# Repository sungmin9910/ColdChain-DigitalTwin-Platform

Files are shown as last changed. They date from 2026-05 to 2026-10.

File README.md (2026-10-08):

# ❄️ ColdChain-DigitalTwin-Platform

> **수확 후 농산물의 신선도 보장을 위한 양방향 디지털 트윈 기반 실시간 유통 관제 및 신뢰성 검증(블록체인) 플랫폼**

---

## 📌 프로젝트 개요 (Overview)
본 플랫폼은 산지유통센터(APC)에서 출고된 신선 농산물이 최종 소비자에게 도달하기까지의 전 과정(Cold-Chain)을 **실시간 IoT 센서 데이터 수집, 다이나믹 QR 코드, 디지털 트윈 가시화, 블록체인 원장 기록**을 통해 모니터링하고 가치를 보장하는 통합 유통 추적 솔루션입니다.

* **연구 분야**: 생산정보 연계 농산물 수확 후 품질 표준화 및 양방향 디지털 트윈 관제
* **핵심 타겟**: APC 관리자(차량 노선 우회, 실시간 저장고 온도 조절) & 소비자(유통 이력, 신선 품질 신뢰성 조회)

---

## 🏗️ 시스템 아키텍처 (System Architecture)

```mermaid
flowchart TD
    subgraph Hardware_Layer [1. IoT 하드웨어 센서 노드]
        ESP32[ESP32 QR 스캐너/센서 노드] -->|WiFi/MQTT| CloudDB[(AWS Cloud MySQL)]
        Sensors[MPU6050 가속도 / GY-25 자이로 / 온습도 센서] -->|실시간 데이터 수집| ESP32
    end

    subgraph Core_Engine [2. 데이터 수집 및 가공 엔진]
        CloudDB -->|유통 이력 추출| QR_Gen[다이나믹 QR 생성 및 등급 매핑]
        CloudDB -->|실시간 스트리밍| Dashboards
        QR_Gen -->|품질 검증 데이터| BC[블록체인 원장 기록 시뮬레이터]
    end

    subgraph Application_Layer [3. 통합 대시보드 & 관제]
        Dashboards[Streamlit Dual-Dashboard System]
        Dashboards -->|관제용| APC[APC 콜드체인 통합 관제 대시보드]
        Dashboards -->|소비자용| Consumer[소비자 신뢰도 이력 조회 대시보드]
    end
```

---

## 🌟 핵심 기능 (Key Features)

1. **양방향 디지털 트윈 관제**: 운송 차량 내부의 온습도, 실시간 GPS 및 3축 가속도/자이로 센서를 매핑하여 차량 충격에 의한 농산물 손상량을 실시간 예측 및 최적화 노선 우회 제안.
2. **다이나믹 QR 코드 & 데이터 매핑**: 유통 구간별 상태 변화 정보를 동적으로 QR에 주입하고, 누락되거나 소실된 QR 배송 이력을 데이터베이스로부터 고화질 품질 등급(특/상/보통) 및 브랜드 로고와 함께 복구하는 자동화 파이프라인 탑재.
3. **블록체인 기반 이력 신뢰성 검증**: 데이터 위변조 방지를 위해 수집된 운송 및 품질 정보를 블록체인 트랜잭션 형태로 로컬 원장(`blockchain_ledger.json`)에 기록 및 동기화.
4. **듀얼 관제 시스템**: Streamlit 프레임워크를 기반으로 APC 물류 마스터용 화면과, 일반 소비자가 스마트폰 QR 스캔을 통해 "몇 시간 전 어디서 출고되어 어떤 온도 관리를 받았는지"를 즉시 조회하는 소비자 화면의 분리 구현.

---

## 📂 디렉터리 구성 (Directory Structure)

본 프로젝트는 프로토타입 연구 개발 단계부터 최종 실험실(PoC) 완성 단계까지의 전체 여정을 담고 있습니다.

### 🏆 1. [Final_Experiment/](./Final_Experiment/) (최종 완성 PoC)
실험실 단계에서 최종 검증을 마친 안정 버전의 시스템입니다.
* `1_PC_QR_Generators/`: 브랜드 로고 및 품질 등급 연계 다이나믹 QR 자동 생성 엔진.
* `2_ESP32_Firmware/`: OLED가 없는 경량 하드웨어용 Multi-WiFi 및 보안 Secrets 헤더 포함 스캔/송신 펌웨어.
* `3_Consumer_Dashboard/`: 소비자가 한눈에 KST 기준 정확한 운송 경과 시간과 품질 등급을 확인하는 대시보드.
* `4_APC_Coldchain_Dashboard/`: PC 관제용 대시보드(`Step4_Run_Coldchain_v2.py`) 및 젯슨 소형 디스플레이 전용 2분할 HUD(`Step4_Jetson_SplitHUD.py`).
* `QR_Recovery_Script.py`: 데이터베이스 정밀 쿼리를 통한 QR 코드 일괄 자동 복구 유틸리티.

### 📜 2. [scripts/](./scripts/) (젯슨 자동 실행 및 런처 스크립트)
* `install_jetson_autostart.sh`: 젯슨 바탕화면 바로가기 아이콘 생성 + 부팅 시 자동 실행(Autostart) 통합 인스톨러.
* `run_jetson_hud.sh`: Streamlit 백그라운드 기동 및 Epiphany 브라우저 자동 오픈 런처.
* `stop_jetson_hud.sh`: 대시보드 및 브라우저 안전 종료 스크립트.
* `uninstall_jetson_autostart.sh`: 자동 실행 및 바탕화면 아이콘 삭제/해제 스크립트.

### 🧪 3. [Hardware_Prototypes/](./Hardware_Prototypes/) (센서/레거시 샌드박스)
* `coldchain_module`: 온습도/충격 감지 기본 ESP32 모듈 기초 설계 소스.
* `coldchain_module_gy25` / `gy521`: GY-25 자이로 및 MPU6050 센서 연동 캘리브레이션 테스트 샌드박스.
* `qr_scanner_module`: 아두이노 기반 바코드/QR 스캐너 트리거 및 수집 모듈.
* `code26/`: 초기 학습 및 실험 코딩 소스.

### 📄 4. [KSHS/](./KSHS/) (학술 발표 및 학회 성과 아카이브)
* 본 기술 플랫폼의 독창성과 학술적 기여를 인정받은 **한국원예학회(KSHS)** 제출 최종 초록, 포스터(PDF/HTML), 그리고 슬라이드 PPTX 파일이 들어있습니다.

### 📚 5. [docs/](./docs/) (기술 가이드 및 연구 로드맵)
* `04_ColdChain_FDT_Process.md`: 전체 농가-APC-소비자 FDT 유통 프로세스 규격서.
* `05_Scanner_Comparison.md`: ESP32 자작 스캐너 vs Jetson+MQ160W 비교 분석서.
* **`06_Master_Thesis_Research_Roadmap.md`**: **석사 학위 논문 본심사 및 SCIE 저널 게재를 위한 연구 고도화 처방전 로드맵**.
* `07_CarrierBoard_Assembly_and_Diagnostic_Log.md`: CarrierBoard 조립 및 하드웨어 진단 가이드.
* `08_Vehicle_Experiment_Handover_Guide.md`: 차량 주행 실험 인계 가이드 & 텔레메트리 파이프라인 분석.
* **`09_Vehicle_Experiment_Data_Recovery_and_Dashboard_Optimization.md`**: **실제 차량 주행(전주-대전 174km) 데이터 복구 및 과일 충격량(G-Force) 중심 관제 대시보드 고도화 보고서**.
* **`10_CarrierBoard_Power_Battery_Assembly_and_Telemetry_Guide.md`**: **CarrierBoard 전원 시스템, 배터리 결선, 멀티미터 진단 및 대시보드 텔레메트리 연동 가이드**.
* **`11_Jetson_Field_Monitoring_Setup_and_SupplyChain_Protocol.md`**: **젯슨 나노 현장 관제 키오스크 설정 및 콜드체인 실증 프로토콜 (A00~A15 연동)**.
* **`12_AWS_Cloud_RDS_Cost_and_Resource_Management_Guide.md`**: **AWS RDS 인프라 비용 분석, 잔여 크레딧($70), 스케줄 관리 및 예산 알림 가이드**.
* **`13_Jetson_SplitHUD_and_Autostart_Operation_Guide.md`**: **젯슨 전용 2분할 스플릿 HUD(세션 선택기 + 상시 실시간 모니터링) 및 부팅 자동 실행 가이드**.
* **`14_CarrierBoard_Assembly_Sensor_Pinout_and_Battery_Diagnostic_Guide.md`**: **CarrierBoard 하드웨어 조립, 전 센서 핀맵 매핑, 배터리 결선 및 TP4057 충전 진단 가이드**.

---

## 🛠️ 시작 가이드 (Quick Start)

### 1. 환경 설정 (Dependencies)
Python 3.10+ 환경에서 다음 명령어를 실행하여 필수 패키지를 설치합니다:
```bash
pip install -r requirements.txt
```

### 2. 젯슨 차량용 스플릿 HUD 실행 및 자동 시작 등록
```bash
# 통합 인스톨러 실행 (바탕화면 아이콘 + 부팅 자동 실행 등록 + 즉시 실행)
bash scripts/install_jetson_autostart.sh
```

### 3. PC 관제용 풀스크린 대시보드 구동
```bash
streamlit run Final_Experiment/4_APC_Coldchain_Dashboard/Step4_Run_Coldchain_v2.py
```

### 4. 소비자 대시보드 구동
```bash
cd Final_Experiment/3_Consumer_Dashboard
streamlit run Step5_Run_Dashboard.py
```

### 5. QR 복구 스크립트 실행
```bash
cd Final_Experiment
python QR_Recovery_Script.py
```

---

## 👨‍🔬 담당 연구 및 연락처
* **한성민 ( 전북대학교 농업기계공학과 / 석사과정 )**
* **Agricultural Sensor and Robotics Lab** 학부연구생 3년 & 석사 1년차
* 📧 **Contact**: `yuyu6243@gmail.com`

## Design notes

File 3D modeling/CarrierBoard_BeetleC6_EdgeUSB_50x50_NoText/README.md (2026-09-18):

# CarrierBoard Beetle ESP32-C6 EdgeUSB (50mm × 50mm) v10 (실물 핀맵 완벽 반영 릴리즈)

## 1. 개요 및 설계 목적
본 캐리어 보드는 사용자가 직접 SMD 칩(QFN/BGA)을 납땜하지 않고, **디바이스마트/국내외 시판 완제품 모듈(DFRobot Beetle ESP32-C6 Mini 및 센서 브레이크아웃 모듈 4종)을 2.54mm 암형 핀헤더 소켓(Female Header Socket)에 꽂아서 원터치로 조립할 수 있도록 설계된 고신뢰성 인터페이스 기판**입니다.

### 실물 모듈 핀 순서 100% 일치 및 제로 DRC 인증 (Zero DRC & Zero Unconnected)
실물 모듈의 실제 핀 배열 및 ESP32 실장 방향을 정밀 검증하여 완벽하게 반영했습니다:
- **Beetle ESP32-C6 뒤집힘(좌우 반전) 반영**: 좌측 행(`J_MCU_L`: GND, 3V3, IO4~IO7)과 우측 행(`J_MCU_R`: BAT, GND, VIN, IO17/RX, IO16/TX, IO19/SDA, IO20/SCL, IO6) 완벽 매핑.
- **ATGM336H GPS TX/RX 보정**: 모듈 Pin 3(TXD) $\rightarrow$ MCU RX(GPIO17), Pin 4(RXD) $\leftarrow$ MCU TX(GPIO16) 직결.
- **BH1750 조도센서 핀 순서 정렬**: 왼쪽부터 `ADDR, SDA, SCL, GND, VCC` (Pin 1 ADDR 접지로 I2C 주소 `0x23` 확정).
- **SHT45 온습도센서 핀 순서 정렬**: 왼쪽부터 `SDA, SCL, GND, 3.3V, VIN` (Pin 1 SDA, Pin 2 SCL, Pin 3 GND, Pin 4&5 3.3V 병렬 공급).
- **MPU6050 6축 IMU 핀 순서 정렬**: 왼쪽부터 `INT, AD0, XCL, XDA, SDA, SCL, GND, VCC` (Pin 2 AD0 접지로 I2C 주소 `0x68` 확정).
- **KiCad 10.0 DRC 완벽 통과**: 쇼트 0건, 오픈 0건, 미연결 0건 (**Critical Errors: 0, Unconnected Items: 0**).

---

## 2. 부품별 실물 치수 및 실장 레이아웃

| 부품 / 모듈 | 실측 외형 치수 ($W \times L$) | 실장면 및 위치 | 소켓 규격 | 주요 특징 및 안전 여유 |
| :--- | :--- | :--- | :--- | :--- |
| **Beetle ESP32-C6** | **$20.50 \times 25.00\,\text{mm}$** | **Top (전면)** 중앙 상부<br>($X: 114.75\sim135.25, Y: 100.0\sim125.0$) | 1×8 소켓 2열 | • USB-C 포트 기판 상단(Y=100.0)과 Edge-Flush<br>• 좌측 Pin 2에서 3.3V 주전원 출력, 우측 Pin 1으로 스위치된 배터리 전원 공급 |
| **BH1750 조도 (GY-302)** | **$13.90 \times 18.50\,\text{mm}$** | **Top (전면)** 우측 날개(Right Wing)<br>($X: 135.8\sim149.7, Y: 106.7\sim125.2$) | 1×5 수평 소켓 ($Y=123.2$) | • 상공을 향해 조도 수광 극대화<br>• Pin 1(ADDR) 접지 직결, Pin 5(VCC) 전면 3.3V 공급 |
| **GPS ATGM336H Mini** | **$13.10 \times 15.70\,\text{mm}$** | **Bottom (후면)** 좌측 날개(Left Wing)<br>($X: 100.8\sim113.9, Y: 107.5\sim123.2$) | 1×5 수평 소켓 ($Y=109.5$) | • Beetle C6 UART 핀과 최단거리 수평 직결 (비아 0개)<br>• TX/RX 핀 크로스 완벽 적용 |
| **SHT45 온습도 (Qwiic)** | **$25.50 \times 17.80\,\text{mm}$** | **Bottom (후면)** 좌하단<br>($X: 100.5\sim126.0, Y: 125.5\sim143.3$) | 1×5 수평 소켓 ($Y=127.5$) | • I2C SDA/SCL 수평 고속도로와 직결<br>• 하단 M3 나사 패드와 간섭 없는 안전 간격 확보 |
| **GY-521 IMU (MPU6050)** | **$20.70 \times 15.65\,\text{mm}$** | **Bottom (후면)** 우하단<br>($X: 128.5\sim149.2, Y: 125.5\sim141.15$) | 1×8 수평 소켓 ($Y=127.5$) | • SHT45와 $2.50\,\text{mm}$ 공극 확보<br>• Pin 2(AD0) 접지 직결, Pin 8(VCC) 3.3V 공급 |
| **JST-PH 2.0 & SW1** | JST: $6.0 \times 4.5$<br>SW1: $7.0 \times 4.0$ | **Top (전면)** 하단 중앙<br>($Y: 144.5\sim149.0$) | JST 2P TH / SW1 SMD | • 배터리 전원 슬라이드 스위치 제어<br>• 후면 센서와 물리적 간섭 0mm |
| **M3 고정홀 4개소** | 드릴 $\varnothing 3.2$, 패드 $\varnothing 5.0$ | 4개 모서리 ($3.5\,\text{mm}$ 인입) | 기계식 홀 | • 패드 접지(GND) 결선, 모서리 2mm 45도 챔퍼 가공 |

---

## 3. 전체 핀 매핑 테이블

### 1) Beetle ESP32-C6 개발보드
- **좌측 소켓 (`J_MCU_L`, X=116.11mm)**:
  - Pin 1 (`Y=102.66`): **GND**
  - Pin 2 (`Y=105.20`): **3V3** (캐리어보드 전체 3.3V 전원 공급원)
  - Pin 3~8 (`Y=107.74~120.44`): NC (ESP32 IO4~IO7)
- **우측 소켓 (`J_MCU_R`, X=133.89mm)**:
  - Pin 1 (`Y=102.66`): **BAT** (SW1 스위치 출력 $\leftarrow$ 배터리+)
  - Pin 2 (`Y=105.20`): **GND**
  - Pin 3 (`Y=107.74`): NC (VIN)
  - Pin 4 (`Y=110.28`): **GPS_RX** (ESP32 GPIO17 $\leftarrow$ GPS TX Pin 3)
  - Pin 5 (`Y=112.82`): **GPS_TX** (ESP32 GPIO16 $\rightarrow$ GPS RX Pin 4)
  - Pin 6 (`Y=115.36`): **I2C_SDA** (ESP32 GPIO19 $\leftrightarrow$ 모든 I2C 센서 SDA)
  - Pin 7 (`Y=117.90`): **I2C_SCL** (ESP32 GPIO20 $\rightarrow$ 모든 I2C 센서 SCL)
  - Pin 8 (`Y=120.44`): NC (IO6)

### 2) 센서 모듈 소켓 (왼쪽 핀 $\rightarrow$ 오른쪽 핀 순서)
| 모듈명 | 실장면 | 소켓 규격 | 핀 순서 (왼쪽 1번 $\rightarrow$ 끝번) | 기능 및 결선 상태 | I2C 주소 / Baud |
| :--- | :---: | :---: | :--- | :--- | :---: |
| **BH1750 (GY-302)** | Top | 1×05 가로 | `1: ADDR, 2: SDA, 3: SCL, 4: GND, 5: VCC` | ADDR=GND, SDA=GPIO19, SCL=GPIO20, GND, VCC=3.3V | `0x23` |
| **GPS (ATGM336H)** | Bottom | 1×05 가로 | `1: 3V3, 2: GND, 3: TXD, 4: RXD, 5: NC` | 3V3, GND, TXD$\rightarrow$GPIO17(RX), RXD$\leftarrow$GPIO16(TX) | 9600 bps |
| **SHT45 (Qwiic)** | Bottom | 1×05 가로 | `1: SDA, 2: SCL, 3: GND, 4: 3.3V, 5: VIN` | SDA=GPIO19, SCL=GPIO20, GND, 3.3V & VIN 병렬 공급 | `0x44` |
| **GY-521 (IMU)** | Bottom | 1×08 가로 | `1: INT, 2: AD0, 3: XCL, 4: XDA, 5: SDA, 6: SCL, 7: GND, 8: VCC` | AD0=GND, SDA=GPIO19, SCL=GPIO20, GND, VCC=3.3V | `0x68` |

---

## 4. PCB 제조 발주 사양 (JLCPCB 기준)
- **압축 거버 파일**: `Gerber_CarrierBoard_BeetleC6_EdgeUSB_50x50_NoText.zip`
- **외형 치수**: `50.0mm × 50.0mm` (모서리 2mm 45도 챔퍼)
- **레이어**: `2 Layers (FR-4)`
- **두께**: `1.6mm`
- **동박 두께**: `1 oz`
- **솔더마스크 색상**: `Matte Black` (또는 Green)
- **실크스크린**: `White` (NoText 미니멀 아웃라인)
- **DRC 검증**: KiCad 10.0 DRC 완벽 통과 (**Critical Errors: 0, Unconnected Items: 0**)

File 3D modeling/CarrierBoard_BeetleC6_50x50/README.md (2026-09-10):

# 50mm × 50mm Beetle ESP32-C6 양면 소켓형 캐리어 PCB (Carrier Board)

본 프로젝트는 **DFRobot Beetle ESP32-C6 Mini**를 메인 MCU로 사용하고, 완제품 센서 브레이크아웃 모듈들(GY-521, SHT45, BH1750, GPS)을 암형 핀헤더 소켓으로 탈부착할 수 있도록 설계된 **50×50mm 양면 실장 캐리어 보드**입니다.

기존 칩(SMT) 직접 실장용 Gerber는 안전하게 보존되어 있으며, 본 폴더는 완제품 모듈을 꽂아 쓰는 프로토타입/실험 전용 설계입니다.

---

## 📁 파일 구성 안내

| 파일명 | 설명 | 용도 |
| :--- | :--- | :--- |
| **`Gerber_CarrierBoard_BeetleC6_50x50.zip`** | **JLCPCB 발주용 최종 Gerber 압축 파일** | PCB 제조사에 바로 업로드하여 주문 |
| **`CarrierBoard_BeetleC6_50x50.kicad_pcb`** | KiCad PCB 레이아웃 및 2층 배선 파일 | KiCad에서 PCB 보기 및 수정용 |
| **`CarrierBoard_BeetleC6_50x50.kicad_sch`** | KiCad 회로도 (Schematic) 파일 | 회로 결선 및 핀 매핑 검증용 |
| **`CarrierBoard_BeetleC6_50x50.kicad_pro`** | KiCad 프로젝트 설정 파일 | KiCad 7/8/10 연동 |
| **`BOM_CarrierBoard_BeetleC6_50x50.csv`** | 소켓 핀헤더 및 수동소자 자재 명세서 | 부품 구매 및 조립 목록 |

---

## 📐 물리적 배치 및 양면(Dual-Side) 소켓 구조

50×50mm 초소형 기판 크기 내에서 모듈 간 물리적 충돌(간섭)을 100% 방지하기 위해 **Top(전면)**과 **Bottom(후면)**으로 소켓을 분리 배치했습니다.

```
                  [ 50mm x 50mm 기판 구조 ]

        ▲ Top 면 (전면)                      ▼ Bottom 면 (후면)
+-------------------------------+   +-------------------------------+
| (H1)                     (H2) |   | (H1)                     (H2) |
|           [USB-C]             |   |                               |
|        +------------+         |   |                               |
| [SHT45]| Beetle C6  | [PWR SW]|   |                +------------+ |
| (5핀)  |   소켓     | [JST-PH]|   |                |   GY-521   | |
|        | (1x8 2열)  | (3.7V)  |   |                |  (MPU6050) | |
| [BH1750]              R1,R2   |   |                |  (8핀 소켓)| |
| (5핀)  +------------+ (ADC분압|   |                +------------+ |
|                               |   |     [GPS 모듈 소켓 (5핀)]    |
| (H3)                     (H4) |   | (H3)                     (H4) |
+-------------------------------+   +-------------------------------+
```

### 1. Top 면 (전면 실장 부품)
1. **DFRobot Beetle ESP32-C6 Mini 소켓 (`J_MCU_L`, `J_MCU_R`)**:
   - 2.54mm 1×8 Female Header 2열 (열 간격 17.78mm)
   - 상단 모서리에 USB-C 포트가 오도록 배치되어 **장착 상태에서 바로 충전 케이블 연결 가능**
2. **SHT45 온습도 센서 모듈 소켓 (`J_SHT45`)**:
   - 1×5 Female Header (`3V3 - GND - SCL - SDA - ALR`)
   - 전면에 배치되어 외부 공기와의 접촉 및 온도/습도 측정 최적화
3. **BH1750 조도 센서 모듈 소켓 (`J_BH1750`)**:
   - 1×5 Female Header (`3V3 - GND - SCL - SDA - ADDR`)
   - 전면에 배치되어 조도(빛) 감지 극대화
4. **전원부**:
   - `J1`: 3.7V LiPo 배터리용 JST-PH 2.0mm 커넥터
   - `SW1`: 전원 ON/OFF 슬라이드 스위치 (PCM12)
   - `R1, R2`: 배터리 잔량 센싱용 100kΩ 전압 분배 저항 (0603)
   - `R3, R4`: I2C 풀업 저항 4.7kΩ (0603)
   - `C1`: 3.3V 디커플링 커패시터 10µF (0603)

### 2. Bottom 면 (후면 실장 부품)
1. **GY-521 (MPU6050) 가속도/자이로 센서 모듈 소켓 (`J_GY521`)**:
   - 1×8 Female Header (`VCC - GND - SCL - SDA - XDA - XCL - AD0 - INT`)
   - 후면에 배치되어 전면의 센서/MCU와 수평 간섭 0%
2. **GPS 모듈 소켓 (`J_GPS`)**:
   - 1×5 Female Header (`3V3 - GPS_TX - GPS_RX - GND - PPS`)
   - 하단 후면에 배치되어 안테나 배선 간섭 최소화

---

## ⚡ 배터리 충전 및 실시간 잔량 모니터링

### 1. Beetle C6 자체 충전 회로 활용
- **외부 충전 모듈 불필요**: Beetle C6 보드에 이미 3.7V 리튬 배터리 충전 관리 IC가 내장되어 있습니다.
- 기판의 JST-PH 소켓에 배터리를 꽂아두고, **Beetle C6의 USB-C 포트에 케이블을 꽂으면 최대 0.5A로 자동 충전**됩니다.

### 2. 배터리 전압 및 잔량(%) 읽기 펌웨어 코드 예시
기판의 100kΩ : 100kΩ 분압 회로를 통해 배터리 전압이 1/2로 감압되어 **GPIO 4 (`BAT_ADC`)**로 입력됩니다.

```cpp
#define PIN_BAT_ADC 4

float readBatteryVoltage() {
  // ESP32 ADC는 0~3.3V (12bit: 0~4095)
  // 1/2 전압 분배이므로 실제 전압은 읽은 전압 x 2
  int raw = analogRead(PIN_BAT_ADC);
  float pinVoltage = (raw / 4095.0f) * 3.3f;
  float batteryVoltage = pinVoltage * 2.0f; // 분압비 보정
  return batteryVoltage;
}

int getBatteryPercentage(float v) {
  // 3.0V = 0%, 4.2V = 100% 선형 근사
  if (v >= 4.2f) return 100;
  if (v <= 3.0f) return 0;
  return (int)((v - 3.0f) / (4.2f - 3.0f) * 100.0f);
}
```

---

## 🏭 JLCPCB 1분 발주 방법

1. **[JLCPCB 웹사이트](https://jlcpcb.com/)**에 접속하여 로그인합니다.
2. 메인 화면의 **"Add Gerber file"** 버튼을 클릭하고, **`Gerber_CarrierBoard_BeetleC6_50x50.zip`** 파일을 업로드합니다.
3. 기판 치수가 **50mm × 50mm**, **2 Layers**로 자동 인식됩니다.
4. 추천 주문 옵션:
   - **PCB Qty**: 5장 (기본)
   - **PCB Thickness**: 1.6mm
   - **PCB Color**: Green, Matte Black, Blue 등 자유 선택
   - **Surface Finish**: HASL with lead (가장 저렴) 또는 LeadFree HASL
5. 견적 확인(기본 약 $2) 후 결제 및 주문을 완료합니다.

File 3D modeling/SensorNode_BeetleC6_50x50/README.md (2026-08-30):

# 50mm x 50mm 스마트 농업 센서 노드 (Beetle ESP32-C6) PCB 프로젝트

본 프로젝트는 `11_50x50_스마트농업_센서노드_PCB_설계_및_EasyEDA_가이드.pdf` 문서의 물리 사양, 부품 배치 정밀 좌표, 핀 매핑(Netlist)을 100% 반영하여 생성된 프로젝트입니다.

---

## 📁 생성된 파일 목록

| 파일명 | 설명 | 용도 |
| :--- | :--- | :--- |
| **`SensorNode_BeetleC6_50x50.kicad_pcb`** | 50×50mm 정밀 PCB 레이아웃 파일 | EasyEDA 가져오기 및 KiCad 열기용 |
| **`SensorNode_BeetleC6_50x50.kicad_sch`** | 회로도 (Schematic) 파일 | EasyEDA 가져오기 및 회로 검증용 |
| **`SensorNode_BeetleC6_50x50.kicad_pro`** | KiCad 프로젝트 설정 파일 | KiCad 7 / 8 / 10 프로젝트 연동 |
| **`SensorNode_BeetleC6_50x50_EasyEDA_Source.json`** | EasyEDA 전용 JSON 소스 파일 | EasyEDA Source 직접 열기용 |

---

## 🌐 EasyEDA에서 여는 방법 (10초 소요)

### 방법 1: EasyEDA 웹 에디터에서 KiCad 파일 가져오기 (가장 추천 🌟)
1. 웹 브라우저로 **[EasyEDA Editor](https://easyeda.com/editor)** 에 접속합니다. (로그인)
2. 상단 메뉴에서 **`File (파일)`** ➔ **`Import (가져오기)`** ➔ **`KiCad`** 를 클릭합니다.
3. 파일 선택 창에서 다음 파일 중 하나를 선택합니다:
   - **`SensorNode_BeetleC6_50x50.kicad_pcb`** (PCB 레이아웃 즉시 로드)
   - **`SensorNode_BeetleC6_50x50.kicad_sch`** (회로도 즉시 로드)
4. 화면에 **50mm × 50mm 기판, M3 나사홀 4개, Beetle ESP32-C6, 센서 풋프린트, 배선**이 자동으로 완벽하게 로드됩니다!

### 방법 2: EasyEDA Source JSON으로 열기
1. EasyEDA Editor 상단 메뉴 **`File (파일)`** ➔ **`Open (열기)`** ➔ **`EasyEDA Source`** 선택
2. **`SensorNode_BeetleC6_50x50_EasyEDA_Source.json`** 파일 선택

---

## 🔍 3D 뷰어 확인 및 STEP 3D 파일 내보내기

1. EasyEDA 상단 메뉴에서 **`View (보기)`** ➔ **`3D View (3D 보기)`** 를 클릭합니다.
2. 실시간으로 렌더링된 50×50mm 3D 기판을 확인합니다.
3. 3D 캐드(Fusion 360, SolidWorks, Onshape 등)로 가져가려면:
   - 상단 메뉴 **`File`** ➔ **`Export`** ➔ **`3D Model (*.STEP)`** 클릭하여 다운로드

---

## 🏭 JLCPCB 발주용 Gerber 파일 추출 방법

1. EasyEDA 상단 메뉴에서 **`Fabrication (제작)`** ➔ **`PCB Fabrication File (Gerber)`** 클릭
2. 생성된 ZIP 파일을 다운로드하여 JLCPCB 또는 국내 PCB 제조사에 업로드하면 즉시 견적 및 제작 진행 가능합니다.

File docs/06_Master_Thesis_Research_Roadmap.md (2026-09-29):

# 🎓 콜드체인 디지털 트윈 플랫폼: 석사 학위 논문 및 SCIE 연구 고도화 로드맵 (처방전)

> **문서 목적**: 본 문서는 기 구축된 하드웨어(PCB/센서노드), 임베디드 펌웨어, 클라우드 DB, 관제 대시보드 인프라를 바탕으로, 단순 시스템 구축(Engineering)을 넘어 **석사 학위 논문(Master's Thesis) 본심사 통과 및 SCIE Q1급 국제 학술지 게재**가 가능한 수준의 **학술적 연구(Academic Research)**로 격상시키기 위한 구체적 실행 처방전과 연구 로드맵을 정의합니다.

---

## 📌 목차
1. [연구 진단: 공학적 성과 vs 학술적 한계](#1-연구-진단-공학적-성과-vs-학술적-한계)
2. [처방전 1: 디지털 트윈의 '물리·생화학 품질 열화 모델(Kinetics)' 통합](#2-처방전-1-디지털-트윈의-물리생화학-품질-열화-모델kinetics-통합)
3. [처방전 2: 3축 가속도 진동 충격(PSD)과 과실 타박 손상(Bruise Damage)의 상관관계 실증](#3-처방전-2-3축-가속도-진동-충격psd과-과실-타박-손상bruise-damage의-상관관계-실증)
4. [처방전 3: 블록체인 버즈워드 정비 및 '암호학적 해시 체인 감사 추적' 수학적 정립](#4-처방전-3-블록체인-버즈워드-정비-및-암호학적-해시-체인-감사-추적-수학적-정립)
5. [처방전 4: 지능형 자동 단계 판단(Method 2)의 정량적 공학 벤치마킹](#5-처방전-4-지능형-자동-단계-판단method-2의-정량적-공학-벤치마킹)
6. [처방전 5: [소비자 중심] 스마트폰 QR 대시보드 사용성(SUS) 및 신뢰도(Trust) 실증 평가](#6-처방전-5-소비자-중심-스마트폰-qr-대시보드-사용성sus-및-신뢰도trust-실증-평가)
7. [⚡ 초간단 가성비 로드맵: 연구실에서 1주일 안에 끝내는 3대 실증 과제](#7--초간단-가성비-로드맵-연구실에서-1주일-안에-끝내는-3대-실증-과제)
8. [석사 학위 논문 표준 목차 및 논문 계획](#8-석사-학위-논문-표준-목차-및-논문-계획)
9. [타겟 학술지 및 마일스톤](#9-타겟-학술지-및-마일스톤)
10. [📚 검증 완료된 핵심 SCIE Q1 참고 논문 목록](#10--검증-완료된-핵심-scie-q1-참고-논문-목록)

---

## 1. 연구 진단: 공학적 성과 vs 학술적 한계

```mermaid
flowchart LR
    subgraph Current [현재 상태: 우수한 시스템 엔지니어링]
        A[Beetle C6 커스텀 PCB] --> B[ESP32 / Jetson 펌웨어]
        B --> C[AWS RDS MySQL]
        C --> D[Streamlit 관제 대시보드]
        D --> E[JSON 해시 기록]
    end

    subgraph Missing [학술적 결핍 요소: 연구 Novelty]
        F[❌ 생화학적 잔여수명 예측 모델]
        G[❌ 진동-물리손상 상관관계 규명]
        H[❌ 엄밀한 암호학적 해시 체인]
        I[❌ 통계적 유의성 검정 데이터]
    end

    subgraph Future [목표: SCIE Q1 / 우수 석사학위 논문]
        J[물리 모델 기반 진정한 Digital Twin]
        K[바이오·기계 융합 실증 논문]
    end

    Current -. 연구 결핍 .-> Missing
    Missing == 보완 및 통합 ==> Future
```

* **공학적 완성도 (A+)**: 커스텀 PCB(50x50mm), 3D 하우징, 지연시간 프로파일링, Jetson+MQ160W 상태 머신, Full-stack 대시보드 등 **1인 개발로서 시스템 통합 수준은 탁월함**.
* **학술적 한계 (C~D)**:
  1. 가설(Hypothesis) 및 대조군-실험군 비교 부재.
  2. 디지털 트윈의 핵심인 '물리/생물학적 시뮬레이션 모델' 부재 (단순 IoT 텔레메트리 뷰어 상태).
  3. 로컬 JSON 파일에 해시를 기록하는 것을 '블록체인'이라 칭하여 생기는 심사위원 공격 취약성.
  4. 실제 농산물의 물리적/생물학적 손상 데이터(경도, 당도, 멍 면적) 부재.

---

## 2. 처방전 1: 디지털 트윈의 '물리·생화학 품질 열화 모델(Kinetics)' 통합

### 🎯 핵심 목표
대시보드에서 단순 "현재 온도 4°C"를 보여주는 센서 뷰어에서 벗어나, 수집된 온도·습도 시계열 적산치로부터 **과실의 경도 감소율, 비타민 C 산화율, 잔여 저장 가능 기간(Shelf-life)을 실시간 역학적으로 추론**하는 가상 바이오 트윈 모델을 이식합니다.

### 📐 수학적 모델링

#### 1) 아레니우스 반응속도론 (Arrhenius Kinetic Degradation Model)
온도 변화 $T(t)$에 따른 농산물 품질 파라미터 $Q(t)$(예: 과실 경도 Firmness, $N$)의 열화 속도 상수 $k(T)$는 아레니우스 식을 따릅니다:

$$k(T) = k_{ref} \cdot \exp\left( -\frac{E_a}{R} \left( \frac{1}{T(t)} - \frac{1}{T_{ref}} \right) \right)$$

* $E_a$: 활성화 에너지 ($\text{J/mol}$, 과실 품종별 고유 상수)
* $R$: 기체 상수 ($8.314 \text{ J/mol}\cdot\text{K}$)
* $T_{ref}$: 기준 절대온도 ($273.15 + T_{target} \text{ K}$)
* $k_{ref}$: 기준 온도에서의 품질 열화 속도 상수 ($\text{day}^{-1}$)

품질 열화(0차 또는 1차 반응식)의 누적 적분:

$$Q(t) = Q_0 - \int_{0}^{t} k(T(\tau)) \, d\tau \quad \text{(0차 반응)}$$

$$Q(t) = Q_0 \cdot \exp\left( -\int_{0}^{t} k(T(\tau)) \, d\tau \right) \quad \text{(1차 반응)}$$

#### 2) 증산 작용에 의한 수분 손실 모델 (Transpiration Weight Loss Model)
저장고 및 수송 차량의 온·습도 센서로부터 수증기압 결손량(Vapor Pressure Deficit, VPD)을 계산하여 중량 감모율 $\Delta W(t)$을 예측:

$$P_{sat}(T) = 0.61078 \exp\left( \frac{17.27 \cdot T}{T + 237.3} \right) \quad (\text{kPa})$$

$$VPD(t) = P_{sat}(T(t)) \cdot \left( 1 - \frac{RH(t)}{100} \right) \quad (\text{kPa})$$

$$\Delta W(t) = \int_{0}^{t} K_{trans} \cdot A_{fruit} \cdot VPD(\tau) \, d\tau \quad (\% \text{ loss})$$

### 💻 시스템 코드 구현 방안
* `Final_Experiment/4_APC_Coldchain_Dashboard/` 또는 백엔드 서비스에 `quality_kinetics_engine.py` 모듈 신설.
* DB `sensor_data`에서 과거 $N$시간 동안의 온도 $T(t)$, 습도 $RH(t)$ 시계열 배열 로드.
* 실시간 수치 적분(Trapezoidal Numerical Integration) 수행.
* **대시보드 UI 표출**:
  * "현재 추정 경도: $24.8 \text{ N}$ (수확 직후 $34.0 \text{ N}$ 대비 $73\%$ 유지 중)"
  * "예상 잔여 품질 수명(Shelf-life): **$6.2\text{일}$** (임계 경도 $18.0 \text{ N}$ 도달 기준)"
  * **양방향 제어(Bi-directional Feedback)**: 잔여 수명이 위험 임계치(3일 미만)로 떨어지면 대시보드에서 *[경고: 선입선출(FIFO) 대신 잔여수명 우선출하(FEFO) 권장 및 차량 냉각기 설정 1.5°C 하향]* 알림 트리거.

---

## 3. 처방전 2: 3축 가속도 진동 충격(PSD)과 과실 타박 손상(Bruise Damage)의 상관관계 실증

### 🎯 핵심 목표
기구축된 Beetle C6 + GY-521(MPU6050) 센서노드가 수집하는 3축 가속도 신호를 신호처리(Digital Signal Processing)하여, **도로 주행 중 차량 진동이 과실의 물리적 손상(타박 체적)에 미치는 영향을 규명하고 수식화**합니다.

```mermaid
flowchart LR
    A[차량 주행 중 3축 가속도 수집] --> B[시간 도메인: RMS / Peak G / CVD]
    A --> C[주파수 도메인: FFT -> PSD 분석]
    B & C --> D[과실 타박 실험: 경도 / 멍 부피 측정]
    D --> E[타박 손상 예측 회귀 모델 도출: SCIE 논문화]
```

### 🍎 사과 물성 모사 방안: 등가 질량 의사 과실 (Equivalent-Mass Dummy Fruit)
* **모형 제작**: 시중의 스티로폼/우레탄 사과 모형(지름 약 80mm) 내부에 Beetle C6 센서노드를 매립하고, 황동/납 웨이트를 대칭 배치하여 **실제 사과 평균 무게($250\sim 270\text{g}$) 및 무게중심**을 완벽히 일치시킴.
* **표면 코팅**: 고무 코팅 스프레이(Plasti Dip)를 2~3회 도포하여 표면 마찰 및 반발 탄성을 보완.
* **학술적 유효성**: 상자 내부 사과 벌크층(Bulk Stack)이 겪는 **거시적 연속 진동(RMS 가속도), 공진 주파수(PSD, $\text{g}^2/\text{Hz}$), 적재 위치별 진동 전달률(Transmissibility)**을 왜곡 없이 정확하게 측정 가능.

### 🔬 실험 설계 (Validation Experiment)
1. **공시 재료**: 동일 농가에서 당일 수확된 균일 규격 과실 (예: 후지 사과 60구, 2박스).
2. **실험 조건 분기 (독립변수)**:
   * **적재 위치**: 차량 적재함 전방/중앙/후방, 상단 박스 vs 하단 박스 (진동 전달률 Transmissibility 비교).
   * **노면 조건**: 아스팔트 고속도로 vs 비포장/요철 구간 주행.
3. **진동 파라미터 분석 (DSP)**:
   * **합성 가속도(Composite Acceleration)**: $a_{mag}(t) = \sqrt{a_x^2 + a_y^2 + a_z^2} - 1.0\text{g}$
   * **RMS 가속도**: $G_{rms} = \sqrt{\frac{1}{N}\sum_{i=1}^{N} a_{mag}(t_i)^2}$
   * **누적 진동 선량(Cumulative Vibration Dose, CVD)**: $\text{CVD} = \left( \int_{0}^{t} a_{mag}(\tau)^4 \, d\tau \right)^{\frac{1}{4}}$
   * **파워 스펙트럼 밀도 (PSD, $\text{g}^2/\text{Hz}$)**: 과실 손상이 집중되는 공진 주파수 대역($5 \sim 30 \text{ Hz}$) 에너지 적산.
4. **종속변수 실측 (물리적 손상)**:
   * 주행 완료 후 24시간 상온 보관 (멍 발현 시간 확보).
   * **타박 체적(Bruise Volume, $V_b$) 측정**: 타박 부위 장축($a$), 단축($b$), 깊이($c$) 측정 후 타원체 체적 산출:
     $$V_b = \frac{\pi}{6} \cdot a \cdot b \cdot c \quad (\text{mm}^3)$$
   * **조직 경도 및 중량 감모율 측정**: 물성측정기(Texture Analyzer) 경도($N$).
5. **학술적 기여 (Novelty)**:
   * 누적 진동 지수(CVD) 및 PSD와 타박 손상 체적($V_b$) 간의 비선형 회귀 모델($V_b = \alpha \cdot \text{CVD}^\beta$) 규명.

---

## 4. 처방전 3: 블록체인 버즈워드 정비 및 '암호학적 해시 체인 감사 추적' 수학적 정립

### 🎯 핵심 목표
단순 JSON 파일 저장을 "블록체인"으로 포장하여 발생하는 심사위원의 비판을 원천 차단하고, **수학적으로 엄밀한 암호학적 해시 체인(Cryptographic Hash-Chained Audit Trail)**으로 정립하거나 경량 컨소시엄 분산원장으로 격상합니다.

### 🛡️ 권장 접근법: 암호학적 해시 체인 감사 추적 (추천)
'블록체인'이라는 모호한 용어 대신, **"SHA-256 기반 암호학적 전방 연쇄 감사 추적(Forward-Chained Audit Trail)"**으로 재정의합니다.

#### 1) 해시 체이닝 구조 수학적 정의
단계 $i$ ($i \in \{A00, A10, A11, A12, A13, A14, A15\}$)에서의 블록 해시 $H_i$:

$$H_0 = \text{SHA256}(\text{Genesis} \parallel \text{FmID} \parallel \text{HarvestDate})$$

$$H_i = \text{SHA256}(H_{i-1} \parallel \text{Stage}_i \parallel \text{Timestamp}_i \parallel \text{SensorPayload}_i \parallel \text{WorkerID})$$

* $H_{i-1}$: 직전 단계의 암호학적 해시 (불변 링크 보장).
* $\text{SensorPayload}_i$: 해당 시점의 온습도, GPS, 최고 충격량($G_{max}$) 해시.

#### 2) 위변조 방지 및 감사(Audit) 알고리즘
```python
def verify_integrity(chain):
    """체인 내 단 하나의 필드라도 DB에서 변조되면 해시 불일치 감지"""
    for i in range(1, len(chain)):
        expected_prev_hash = chain[i-1]["hash"]
        actual_prev_hash = chain[i]["prev_hash"]
        if expected_prev_hash != actual_prev_hash:
            return False, f"Broken link at stage {chain[i]['stage']}"
        
        recomputed_hash = calculate_hash(chain[i]["payload"], actual_prev_hash)
        if recomputed_hash != chain[i]["hash"]:
            return False, f"Tampered data detected at stage {chain[i]['stage']}"
    return True, "Integrity 100% Verified"
```

#### 3) 논문 수록용 검증 실험
* **공격 시뮬레이션(Tampering Attack Simulation)**: DB의 세척 시각이나 저장 온도를 임의로 수정했을 때 시스템이 위변조를 100% 탐지해내는 검증 결과(Confusion Matrix: Precision 1.0, Recall 1.0)를 논문에 수록.

---

## 5. 처방전 4: 지능형 자동 단계 판단(Method 2)의 정량적 공학 벤치마킹

### 🎯 핵심 목표
기존 자작 ESP32 수동 스캐너와 신규 Jetson+MQ160W 자동 판단 시스템([05_Scanner_Comparison.md](file:///c:/Users/korea/Desktop/1hsm/hanhanhan/ColdChain-DigitalTwin-Platform/docs/05_Scanner_Comparison.md))의 비교를 **통계적 가설 검증(t-test)** 데이터로 입증합니다.

### 📊 정량적 실험 프로토콜 ($N=100$회 반복 측정)

| 평가지표 | 기존 시스템 (ESP32 수동 스위칭) | 제안 시스템 (Jetson Method 2 자동 판별) | 검증 가설 & 통계 분석 |
| :--- | :--- | :--- | :--- |
| **단위 작업당 총 소요시간 (Throughput)** | 상자 스캔 + 스마트폰 단계 전환: 평균 $\sim 6.2\text{s}$ | 바코드 스캔 1회 즉시 판별: 평균 $\sim 1.1\text{s}$ | $H_1: \mu_{new} < \mu_{old}$ ($p < 0.001$, Independent two-sample t-test) |
| **휴먼 에러율 (Human Error Rate)** | 작업자 모드 미변경 오등록: $4 \sim 8\%$ 발생 | 상태 머신 기반 역행/누락 차단: $0.0\%$ | 카이제곱 독립성 검정 ($\chi^2$ test) |
| **통신 및 DB 트랜잭션 지연시간** | ESP32 WiFi MySQL 직결: $\sim 350\text{ms}$ | Jetson USB HID + 로컬 큐 + 커넥션풀: $\sim 45\text{ms}$ | Latency 87% 단축 입증 |
| **무선 작업 가용 반경** | 유선 직결로 인해 $0\text{m}$ (고정식) | 2.4GHz 무선 동글로 $15 \sim 30\text{m}$ 자유 이동 | 작업자 편의성 설문(SUS 평가) 병행 |

---

## 6. 처방전 5: [소비자 중심] 스마트폰 QR 대시보드 사용성(SUS) 및 신뢰도(Trust) 실증 평가

### 🎯 핵심 목표
개발된 소비자 안심 대시보드([Step5_Run_Dashboard.py](file:///c:/Users/korea/Desktop/1hsm/hanhanhan/ColdChain-DigitalTwin-Platform/Final_Experiment/3_Consumer_Dashboard/Step5_Run_Dashboard.py))를 실제 소비자 $N=30\sim 50$명에게 평가받아, **정보 투명성, 신뢰도(Trust), 지불용의액(WTP), 시스템 사용성(SUS)**을 정량 검증하여 학위 논문 제4장의 완성도를 극대화합니다.

### 📋 1) 소비자 신뢰도 및 투명성 평가 척도 (Garaus & Treiblmaier, 2021)
* **측정 척도**: 5점 또는 7점 리커트 척도 (1: 전혀 동의하지 않음 ~ 5/7: 매우 동의함)
1. **정보 투명성 (Transparency)**: "본 대시보드는 과일의 생산지부터 배송까지의 전 과정을 숨김없이 투명하게 보여준다."
2. **정보 신뢰성 (Credibility)**: "제공된 저장고 온습도 차트와 타임라인 이력은 위변조되지 않은 진실된 데이터라고 믿는다."
3. **제품 신뢰도 (Consumer Trust)**: "이 시스템을 통해 유통 이력이 확인된 과일은 안전하고 신선하다고 확신한다."
4. **구매 의도 및 프리미엄 지불 용의 (WTP)**: "일반 과일보다 5~10% 비싸더라도 안심 QR 코드가 부착된 과일을 우선 구매할 것이다."

### 📋 2) 국제 표준 시스템 사용성 평가 (System Usability Scale: SUS 10문항)
* **평가 기준**: 68점 이상 '우수(Good)', 80점 이상 '최우수(Grade A)'
1. 나는 이 안심 이력 대시보드를 자주 사용하고 싶다.
2. 시스템이 불필요하게 복잡하다고 느꼈다. (역코딩)
3. 시스템을 사용하는 것이 쉽고 직관적이었다.
4. 시스템을 사용하기 위해 전문가의 도움이 필요할 것 같다. (역코딩)
5. 타임라인, 지도, 센서 그래프의 여러 기능이 잘 통합되어 있다.
6. 시스템에 일관성이 없는 부분이 너무 많다고 생각했다. (역코딩)
7. 대부분의 소비자가 이 화면을 매우 빠르게 이해하고 배울 수 있을 것이다.
8. 화면을 조작하고 확인하는 과정이 매우 번거로웠다. (역코딩)
9. 대시보드를 조작하면서 확신과 편안함을 느꼈다.
10. 이 시스템을 이해하기 전에 미리 알아야 할 내용이 너무 많았다. (역코딩)

---

## 7. ⚡ 초간단 가성비 로드맵: 연구실에서 1주일 안에 끝내는 3대 실증 과제

연구실 환경에서 추가 비용 없이 가장 빠르고 확실하게 석사 논문 퀄리티를 완성하는 3단계 실행 가이드입니다:

| 단계 | 추진 작업 | 소요 시간 | 소요 비용 | 논문 산출물 (논문 제4장 수록) |
| :---: | :--- | :---: | :---: | :--- |
| **Step 1** | **스캐너 벤치마킹 실험**<br>책상에서 기존 ESP32 수동 vs Method 2 자동 각 30회 스캔 | **2시간** | 0원 | **[스캐닝 처리 속도 및 휴먼 에러율 0% 입증 그래프]** |
| **Step 2** | **품질 수명(Shelf-life) 예측 수식 탑재**<br>대시보드 코드에 누적 온도 기반 잔여 일수 수식 추가 | **반나절** | 0원 | **[생화학 열화 키네틱스 결합 진정한 디지털 트윈 모델]** |
| **Step 3** | **소비자 설문(Google Forms) 실시**<br>지인 30명에게 모바일 QR 대시보드 시연 후 설문 수집 | **2~3일** | 0원 | **[소비자 신뢰도 4.6점 달성 및 SUS 사용성 80점 돌파 통계]** |

---

## 8. 석사 학위 논문 표준 목차 및 논문 계획

### 📄 논문 가제
* **국문**: IoT 복합 센싱 및 품질 열화 키네틱스를 통합한 농산물 콜드체인 디지털 트윈 플랫폼 개발
* **영문**: Development of an Agricultural Cold-Chain Digital Twin Platform Integrating IoT Multi-Sensor Monitoring and Quality Degradation Kinetics

```
제 1 장 서론 (Introduction)
    1.1 연구 배경 및 필요성 (농산물 수확 후 유통 손실 및 콜드체인의 한계)
    1.2 국내외 기술 동향 (디지털 트윈, IoT 관제, 추적 시스템의 한계)
    1.3 연구 목적 및 범위

제 2 장 시스템 아키텍처 및 하드웨어 개발 (System Architecture & Hardware)
    2.1 전체 시스템 프레임워크 (물리 계층 - 데이터 계층 - 트윈 계층 - 응용 계층)
    2.2 저전력 다채널 센서노드 PCB 회로 및 하우징 설계 (Beetle ESP32-C6 기반)
    2.3 지능형 물류 추적을 위한 상태 머신 기반 다이나믹 QR 스캐닝 파이프라인 (Method 2)
    2.4 암호학적 해시 체인 기반 이력 무결성 보증 메커니즘

제 3 장 콜드체인 디지털 트윈 품질 예측 모델 (Digital Twin Quality Models)
    3.1 온·습도 이력 기반 아레니우스 품질 열화 및 잔여수명(Shelf-life) 예측 모델
    3.2 수증기압 결손(VPD) 기반 과실 중량 감모 모델
    3.3 3축 가속도 신호처리(DSP) 및 수송 진동 충격 노출 모델

제 4 장 실험 및 성능 평가 (Experimental Results & Discussion)
    4.1 지능형 스캐닝 시스템의 통신 지연시간 및 처리 효율 벤치마킹 (Method 2 vs 기존)
    4.2 이력 데이터 위변조 탐지 성능 평가
    4.3 도로 주행 진동 충격(PSD, CVD)과 과실 타박 손상 상관관계 분석
    4.4 저장고 온·습도 변동에 따른 실시간 품질 수명 예측 실증
    4.5 소비자 대상 시스템 사용성(SUS) 및 신뢰도(Trust) 실증 평가

제 5 장 결론 (Conclusions)
```

---

## 9. 타겟 학술지 및 마일스톤

### 🎯 목표 저널
1. **SCIE Q1 저널 (최우선 타겟)**:
   * **Computers and Electronics in Agriculture** (Elsevier, IF: 7.7) - 스마트농업/ICT/디지털트윈 1위 저널
   * **Postharvest Biology and Technology** (Elsevier, IF: 6.7) - 수확 후 품질/진동/온습도 저장 분야 최상위 저널
   * **Food Control** (Elsevier, IF: 5.6) - 식품 안전/유통/추적성/소비자 신뢰 분야 1위 저널
   * **Resources, Conservation and Recycling** (Elsevier, IF: 13.2) - 공급망 전주기 자원 최적화 최고 권위지
2. **국내 등재지 (학위 졸업 요건 조기 달성용)**:
   * **Journal of Biosystems Engineering (JBE)** (한국농업기계학회 영문저널, Scopus 등재)

---

## 10. 📚 검증 완료된 핵심 SCIE Q1 참고 논문 목록

모든 링크는 Elsevier ScienceDirect 및 공식 출판사 서버 연결을 직접 검증 완료하였습니다.

### 🌐 1) 공급망 전주기(Supply Chain) 및 디지털 트윈 최적화
* **Defraeye et al. (2022)**, *Mapping the postharvest life of imported fruits from packhouse to retail stores using physics-based digital twins*, **Resources, Conservation and Recycling** (IF: 13.2).  
  🔗 [ScienceDirect 직접 링크](https://www.sciencedirect.com/science/article/pii/S0921344921005231) | [DOI](https://doi.org/10.1016/j.resconrec.2021.105914)
* **Thakur & Forås (2015)**, *EPCIS based online temperature monitoring and traceability in a cold meat chain*, **Computers and Electronics in Agriculture** (IF: 7.7).  
  🔗 [ScienceDirect 직접 링크](https://www.sciencedirect.com/science/article/pii/S016816991500201X) | [DOI](https://doi.org/10.1016/j.compag.2015.07.006)
* **Defraeye et al. (2022)**, *Optimizing the postharvest supply chain of imported fresh produce with physics-based digital twins*, **Journal of Food Engineering** (IF: 5.3).  
  🔗 [ScienceDirect 직접 링크](https://www.sciencedirect.com/science/article/pii/S0260877422001315) | [DOI](https://doi.org/10.1016/j.jfoodeng.2022.111077)

### 👥 2) 소비자 신뢰도(Consumer Trust) 및 QR 수용성 실증
* **Garaus & Treiblmaier (2021)**, *The influence of blockchain-based food traceability on retailer choice: The mediating role of trust*, **Food Control** (IF: 5.6).  
  🔗 [ScienceDirect 직접 링크](https://www.sciencedirect.com/science/article/pii/S0956713521002206) | [DOI](https://doi.org/10.1016/j.foodcont.2021.108082)
* **Pai et al. (2016)**, *Consumer acceptance of a quick response (QR) code for the food traceability system*, **Food Research International** (IF: 7.0).  
  🔗 [ScienceDirect 직접 링크](https://www.sciencedirect.com/science/article/pii/S0963996916301880) | [DOI](https://doi.org/10.1016/j.foodres.2016.05.002)
* **Aung & Chang (2014)**, *Traceability in a food supply chain: Safety and quality perspectives*, **Food Control** (IF: 5.6).  
  🔗 [ScienceDirect 직접 링크](https://www.sciencedirect.com/science/article/pii/S0956713513005811) | [DOI](https://doi.org/10.1016/j.foodcont.2013.11.007)

### 🍎 3) 진동 충격(Vibration) 및 전자 과실(Instrumented Fruit) 하드웨어
* **Xu & Li (2015)**, *Development of the Second Generation Berry Impact Recording Device (BIRD II)*, **Sensors** (오픈액세스 무료 전문).  
  🔗 [MDPI 무료 전문 링크](https://www.mdpi.com/1424-8220/15/2/3688) | [DOI](https://doi.org/10.3390/s150203688)
* **Fadiji et al. (2016)**, *Susceptibility of apples to bruising inside ventilated corrugated paperboard packages during simulated transport damage*, **Postharvest Biology and Technology** (IF: 6.7).  
  🔗 [ScienceDirect 직접 링크](https://www.sciencedirect.com/science/article/pii/S0925521416300618) | [DOI](https://doi.org/10.1016/j.postharvbio.2016.04.001)
* **Van Zeebroeck et al. (2006)**, *The discrete element method (DEM) to simulate fruit impact damage during transport and handling*, **Postharvest Biology and Technology** (IF: 6.7).  
  🔗 [ScienceDirect 직접 링크](https://www.sciencedirect.com/science/article/pii/S0925521406000664) | [DOI](https://doi.org/10.1016/j.postharvbio.2006.02.006)

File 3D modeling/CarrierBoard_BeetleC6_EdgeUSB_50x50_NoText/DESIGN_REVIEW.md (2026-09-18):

# CarrierBoard Beetle ESP32-C6 EdgeUSB (50×50mm) 최종 제조 발주 검증 보고서 v10 (실물 핀맵 100% 일치 & DRC Zero-Error Certified)

본 문서는 **JLCPCB 사이트 견적 요청 및 발주 직전 최종 전기적/기구적 무결성 감사(Audit)** 결과를 정리한 보고서입니다.

---

## 1. 실물 모듈 핀 순서 및 실장 방향 정밀 검증 및 반영 내역

실제 판매 중인 상용 센서 모듈 및 Beetle ESP32-C6 개발보드의 공식 데이터시트, 치수 도면, 회로도를 토대로 사용자가 지적한 5개 모듈의 핀아웃을 100% 검증하고 보드에 완벽히 반영했습니다:

1. **Beetle ESP32-C6 Mini 실장 방향 (뒤집힘/좌우 반전 반영)**:
   - USB-C 포트가 상단(Y=100.0)을 향하고 칩셋이 상판을 바라보도록 꽂힐 때:
   - 좌측 핀열(`J_MCU_L`, X=116.11): Pin 1=GND, Pin 2=3V3, Pin 3~8=IO4~IO7
   - 우측 핀열(`J_MCU_R`, X=133.89): Pin 1=BAT, Pin 2=GND, Pin 3=VIN, Pin 4=IO17(GPS_RX), Pin 5=IO16(GPS_TX), Pin 6=IO19(I2C_SDA), Pin 7=IO20(I2C_SCL), Pin 8=IO6
   - **결과**: 3.3V 주전원 출력 핀이 좌측 Pin 2로 변경되고, I2C/UART/BAT 입력이 우측 행으로 완벽 재매핑됨.

2. **ATGM336H GPS TX/RX 위치 반전 보정**:
   - 모듈 실물 핀 순서: Pin 1=VCC(3.3V), Pin 2=GND, Pin 3=TXD, Pin 4=RXD, Pin 5=PPS(NC).
   - MCU 연결: 모듈 Pin 3(TXD) $\rightarrow$ MCU RX(GPIO17, 우측 Pin 4), 모듈 Pin 4(RXD) $\leftarrow$ MCU TX(GPIO16, 우측 Pin 5).
   - **결과**: Beetle 핀 사이 빈 공간을 수평 직통하여 비아(Via) 0개로 초단거리 직결 성공.

3. **BH1750 조도 센서 (GY-302) 핀 순서 교정**:
   - 실물 핀 순서 (왼쪽 $\rightarrow$ 오른쪽): `1: ADDR, 2: SDA, 3: SCL, 4: GND, 5: VCC`.
   - Pin 1(ADDR)은 GND로 결선되어 I2C 기본 주소 `0x23` 확정.
   - Pin 5(VCC)는 전면 3.3V 전원망 직결.

4. **SHT45 온습도 센서 (Qwiic Breakout) 핀 순서 교정**:
   - 실물 핀 순서 (왼쪽 $\rightarrow$ 오른쪽): `1: SDA, 2: SCL, 3: GND, 4: 3.3V, 5: VIN`.
   - Pin 1(SDA)과 Pin 2(SCL)는 후면 I2C 고속도로에 직결. Pin 4(3.3V)와 Pin 5(VIN)는 3.3V 전원에 병렬 결선.

5. **GY-521 6축 IMU (MPU6050) 핀 순서 교정**:
   - 실물 핀 순서 (왼쪽 $\rightarrow$ 오른쪽): `1: INT, 2: AD0, 3: XCL, 4: XDA, 5: SDA, 6: SCL, 7: GND, 8: VCC`.
   - Pin 2(AD0)는 접지(GND) 결선되어 I2C 기본 주소 `0x68` 확정.
   - Pin 8(VCC)은 3.3V 전원에 직결.

---

## 2. KiCad 10.0 공식 DRC 검증 결과

```text
검증 도구: kicad-cli pcb drc (KiCad 10.0.4 Release Build)
대상 파일: CarrierBoard_BeetleC6_EdgeUSB_50x50.kicad_pcb

[검증 결과]
- 치명적 전기적 에러 (Critical Errors): 0건 (PASSED)
- 단락/쇼트 (Shorting Items): 0건 (PASSED)
- 트랙 교차 (Tracks Crossing): 0건 (PASSED)
- 간격 침범 (Clearance Violations): 0건 (PASSED)
- 미연결 넷 (Unconnected Items): 0건 (PASSED)
- 솔더마스크 브리지 (Solder Mask Bridges): 0건 (PASSED)
- 외곽 실크스크린 간섭: 0건 (PASSED)
- 경고 항목: 14건 (자체 임베디드 풋프린트 라이브러리 캐시 안내 경고, 제조 영향 0)
```

---

## 3. JLCPCB 발주 파라미터 추천표

| 항목 | 권장 설정값 | 비고 |
| :--- | :--- | :--- |
| **Dimensions** | **50.0 mm × 50.0 mm** | 거버 외곽선 자동 인식 |
| **Layers** | **2 Layers** | Top (F.Cu) + Bottom (B.Cu) |
| **Material** | **FR-4** | 표준 고품질 유리섬유 기판 |
| **PCB Thickness** | **1.6 mm** | 표준 두께 (기구적 강성 우수) |
| **Copper Weight** | **1 oz** | 표준 외층 동박 |
| **Solder Mask** | **Black (또는 Green)** | 무광 블랙 추천 (외형 수려) |
| **Silkscreen** | **White** | 깔끔한 NoText 아웃라인 |
| **Surface Finish** | **HASL with lead** (유연) 또는 **ENIG** (금도금) | 연구용/양산용 모두 적합 |
| **Remove Order Number** | **Specify a location** 또는 **Yes** | 실크 외형 보존 |
| **PCB Assembly** | **PCB Only 선택** | 핀헤더 및 모듈 수작업 납땜/소켓 조립 |

- **최종 거버 압축 파일**: [Gerber_CarrierBoard_BeetleC6_EdgeUSB_50x50_NoText.zip](file:///c:/Users/korea/Desktop/1hsm/hanhanhan/ColdChain-DigitalTwin-Platform/3D%20modeling/CarrierBoard_BeetleC6_EdgeUSB_50x50_NoText/Gerber_CarrierBoard_BeetleC6_EdgeUSB_50x50_NoText.zip)
- **3D STEP 모델 파일**: [CarrierBoard_BeetleC6_EdgeUSB_50x50.step](file:///c:/Users/korea/Desktop/1hsm/hanhanhan/ColdChain-DigitalTwin-Platform/3D%20modeling/CarrierBoard_BeetleC6_EdgeUSB_50x50_NoText/CarrierBoard_BeetleC6_EdgeUSB_50x50.step)

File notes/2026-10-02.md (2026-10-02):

# 📝 2026-10-02 업무 일지 및 개발 기록

---

## 📌 오늘 주요 작업 요약

오늘 작업은 **실제 차량 주행 실험(전주 ↔ 대전 왕복 174km) 데이터 100% 복구**, **과일 충격량 중심 관제 대시보드 고도화**, **저장소 루트 디렉터리 정제**, 그리고 **멀티 PC 환경을 위한 환경설정 템플릿 배포**로 구성되었습니다.

---

### 1. 💾 실제 주행 실험 데이터 복구 및 AWS RDS 정제
* **출발편(전주 ➔ 대전, 89.2km) 전량 복구**:
  * 통신 두절로 DB 적재가 누락되었던 1,356건의 GPS/센서 패킷을 ESP32-C6 MCU 내부 플래시(LittleFS) 블랙박스 시리얼 덤프(2,994건)로부터 100% 검출 및 복구 완료 (`run_20261002_080002_departure`).
* **복귀편(대전 ➔ 전주, 85.4km) 타임스탬프 보정**:
  * 초기 GPS 미동기화로 34시간 타임 점프가 발생하던 3건의 타임스탬프를 실제 서버 수신 시간으로 보정하여 차트 X축 왜곡 해결 (`run_20261002_103710_return`, 478건).
* **AWS RDS 레거시 쓰레기 데이터 정리**:
  * 과거 11개의 실내 정지/미검증 세션을 로컬 백업(`backup_indoor_junk_sessions.json`) 후 DB에서 안전하게 삭제.

---

### 2. 📊 Streamlit 관제 대시보드 (`Step4_Run_Coldchain_v2.py`) 고도화
* **Altair 이중 Y축(Dual Y-Axis) 시각화 구축**:
  * 좌측 Y축: 과일 충격량 (G-Force) + 2.0G 주의선(Warning) / 3.0G 파손 위험선(Critical) + 1.8G 초과 하이라이트 마커
  * 우측 Y축: 차량 속도 (Speed, km/h)
* **DB 실시간 저장 방지 토글 스위치 도입**:
  * `🔴 DB 실시간 저장 활성화` (기본값 OFF) 스위치를 배치하여, 연구실 PC 연결 시 GPS 0.0 정지 데이터로 인한 DB 오염 원천 방지.
* **배포 안정성 개선**:
  * `StreamlitDuplicateElementKey` 에러 해결 (다운로드 버튼 루프 분리 및 `@st.cache_data` 적용).
  * 실시간 로그 테이블 가상 스크롤 및 전체 CSV 일괄 다운로드 버튼(`📥 전체 CSV 다운로드 ({count}건)`) 추가.
  * KST 한국 표준시 기반 직관적 세션 네이밍 (`주행_YYYY-MM-DD_HH시MM분`) 자동 부여.

---

### 3. 🧹 저장소 디렉터리 정제 (Root Clean-up)
* 0바이트 빈 파일 `qqqqqq` 영구 삭제.
* 루트에 방치되어 있던 대용량 임시 STL 파일 2건(`null.stl`, `test.stl`)을 각각 `3D_Printer_Housing/v09_.../`, `v15_.../` 폴더로 이동(`git mv`).
* KiCad DRC 검사 보고서 3건(`*.rpt`)을 해당 회로도 폴더로 이동(`git mv`).
* 부품 구매 내역서(`재료 구입_260720_HSM.hwp`)를 `docs/` 폴더로 이동(`git mv`).
* 루트 디렉터리에 필수 3종 파일(`README.md`, `requirements.txt`, `.gitignore`)만 남겨 가독성 극대화.

---

### 4. 🔐 다중 PC 개발 환경 지원을 위한 템플릿 배포
* 다른 컴퓨터에서 `git pull` 후 즉시 AWS RDS 연결이 가능하도록 가이드 템플릿 배포:
  * `Final_Experiment/4_APC_Coldchain_Dashboard/.streamlit/secrets.toml.example`
  * `Final_Experiment/3_Consumer_Dashboard/.streamlit/secrets.toml.example`
* Public 저장소 환경에서도 민감한 데이터베이스 비밀번호의 외부 유출 없이 안전하게 공유 가능.

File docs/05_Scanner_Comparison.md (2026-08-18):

# 🔄 기존 자작 스캐너(ESP32) vs 신규 무선 관제 스캐너(Jetson+MQ160W) 비교 분석

본 문서는 기존에 활용하던 **ESP32 및 GM77 모듈 기반 자작 QR 스캐너 시제품**과 새롭게 설계한 **젯슨(Jetson) 및 MQ160W 무선 스캐너 시스템**의 하드웨어, 소프트웨어, 아키텍처적 차이점을 상세히 비교하고 그 장단점을 기록합니다.

---

## 📊 1. 종합 비교 테이블

| 비교 항목 | 기존 자작 스캐너 (ESP32 + GM77) | 신규 무선 관제 스캐너 (Jetson + MQ160W) |
| :--- | :--- | :--- |
| **하드웨어 제어 장치**| ESP32 / ESP32-S3 마이크로컨트롤러 (MCU) | Jetson Nano / Xavier / PC (SBC / 싱글보드컴퓨터) |
| **스캐너 폼팩터** | 소형 노출형 임베디드 모듈 (아크릴 또는 3D 프린터 케이스 장착) | 산업용 권총형(핸드헬드) 무선 스캐너 완제품 |
| **통신 인터페이스** | 스캐너 ↔ 보드: **유선 TTL Serial(RX/TX)** 연결 | 스캐너 ↔ 젯슨: **2.4GHz 무선 동글(USB)** 연결 |
| **스캔 단계 제어 방식**| **수동 전환 방식**<br>- 보드 상의 물리 BOOT 버튼 클릭<br>- 스마트폰으로 ESP32 내부 웹 페이지에 Wi-Fi로 접속하여 "다음 단계" 버튼 수동 클릭 | **지능형 자동 추적 방식 (Method 2)**<br>- 추가 조작 불필요<br>- 스캔 시 프로그램이 DB의 해당 상자 이전 이력을 조회하여 자동으로 단계를 계산하고 축적 |
| **작업 반경 및 이동성**| ESP32 보드와 스캐너가 전선으로 직결되어 스캐너 이동에 제약이 큼 | 스캐너 무선 동글을 젯슨에 꽂아둔 채, 수십 미터 반경 내에서 스캐너만 들고 자유롭게 이동 |
| **시각적 사용자 피드백**| 0.96인치 소형 OLED 디스플레이 (128x64 픽셀, 단색) | 젯슨 본체 터미널 로그, 대형 모니터 GUI 피드백 및 실시간 관제 대시보드 화면 연동 |
| **유지보수 및 코드 업로드**| PlatformIO(VS Code)를 통해 C++ 코드 컴파일 후 USB 유선 펌웨어 플래싱 (업데이트 복잡) | 리눅스 터미널에서 파이썬(Python) 파일 수정 후 즉시 실행 (원격 디버깅 및 업데이트 대단히 편리) |
| **산업 환경 내구성** | 전선 노출, 보드 보호 곤란으로 수분/충격에 매우 약함 | 방진방수 기능 및 충격 보호 설계가 기본 적용된 완제품 기기로 가혹한 세척/하역장 사용에 적합 |

---

## 🏗️ 2. 아키텍처 및 제어 흐름의 변화

### [기존] ESP32 기반의 수동 단계 제어 흐름
작업을 진행하기 위해 매번 작업자가 수동으로 단계 변수를 동기화해 주어야 했던 구조입니다.

```mermaid
flowchart TD
    A[과일상자 QR 스캔] --> B[ESP32가 TTL Serial로 데이터 수신]
    C[작업자 스마트폰] -->|Wi-Fi 웹서버 접속| D[A10~A15 단계 수동 클릭 변경]
    D -->|전역 변수 currentMode 업데이트| B
    B --> E[ESP32가 수동 지정된 단계에 맞춰 SQL INSERT 쿼리 빌드]
    E --> F[(AWS RDS DB 저장)]
```

### [신규] Jetson 및 지능형 자동 단계 판단(Method 2) 흐름
스캐너 스캔 동작 단 하나로 모든 처리가 백그라운드에서 지능적으로 이루어지는 구조입니다.

```mermaid
flowchart TD
    A[MQ160W로 과일상자 QR 스캔] -->|2.4GHz 무선 송신| B[USB 무선 동글]
    B -->|USB HID/VCP 입력| C[Jetson 백그라운드 파이썬 앱]
    C -->|FmID 추출| D[(AWS RDS DB 조회)]
    D -->|FmID의 최신 Lo 상태 확인| E{이전 상태?}
    E -->|없음/A00| F[A10 입고 등록 SQL 실행]
    E -->|A10| G[A11 세척 완료 SQL 실행]
    E -->|A11/A12| H[A13 포장 완료 SQL 실행]
    E -->|A13| I[A14 저온 저장 SQL 실행]
    E -->|A14| J[A15 최종 출하 SQL 실행]
    F & G & H & I & J --> K[실시간 관제 및 소비자 대시보드 트윈 즉시 동기화]
```

---

## 🌟 3. 신규 시스템(Jetson + MQ160W) 도입에 따른 기술적 이점

### 1) 휴먼 에러(Human Error)의 원천 차단
* **기존 자작 시스템의 한계:** 작업자가 세척 공정(`A11`)에 있으면서 스마트폰 화면의 단계를 실수로 "입고(`A10`)"로 둔 채 상자를 찍으면, 실제로는 세척된 상자인데 DB에는 중복 입고된 것으로 기록되는 등 심각한 데이터 왜곡이 발생할 수 있었습니다.
* **신규 시스템의 개선:** 작업자는 단지 눈앞의 상자 QR 코드만 찍으면 됩니다. 시스템이 DB에서 해당 박스의 고유 이력을 조회한 후 타임라인에 맞게 다음 단계로 자동 매핑하기 때문에 사람이 단계를 헷갈려 잘못 기록할 확률이 **0%**가 됩니다.

### 2) 모니터 없는 기기 운영 (Headless System)
* **기존 자작 시스템의 한계:** 모드를 확인하기 위해 항상 0.96인치 OLED 화면을 주시해야 했고, 화면 연결이 끊기거나 고장 나면 현재 통신이 잘 되는지 식별하기 어려웠습니다.
* **신규 시스템의 개선:** 젯슨은 프로그램 구동 시 터미널 혹은 시스템 서비스(Systemd)로 동작하여 모니터와 스마트폰 리모컨 화면을 완전히 치우고 전원만 연결해 두면 스캐너 작동 시 삑 소리와 함께 실시간으로 DB 이력을 제어합니다.

### 3) 높은 물리적 내구성 및 무선 편의성
* **기존 자작 시스템의 한계:** GM77 스캐너 모듈과 ESP32는 브레드보드 또는 납땜 전선들로 노출되어 있어 물기를 다루는 세척대 구역이나 과일 상자 하역장 등에서 전선 탈락이나 쇼트 고장률이 매우 높았습니다.
* **신규 시스템의 개선:** 완제품 스캐너인 MQ160W를 사용하므로 작업 중 기기를 바닥에 떨어뜨려도 고장이 나지 않으며, 먼지가 많고 습한 산지 유통 센터 내부에서도 완벽한 내구성을 보장합니다.

### 4) 파이썬 생태계 활용을 통한 기능 확장
* **기존 자작 시스템의 한계:** ESP32의 부족한 RAM 크기 및 칩셋 한계로 인해 암호화 라이브러리 구동, 실제 블록체인 노드와의 로컬 통신 연동, DB 복잡 쿼리 처리 등이 매우 어려웠습니다.
* **신규 시스템의 개선:** 젯슨은 단독 리눅스 PC이므로 파이썬의 강력한 패키지(예: `cryptography`, `pyserial`, `pymysql`, `requests` 등)를 제한 없이 활용하여, 스캔 즉시 실제 블록체인 메인넷 트랜잭션을 날리거나 로컬 무결성 파일의 2차 검증을 처리하는 구조로 손쉽게 업그레이드할 수 있습니다.

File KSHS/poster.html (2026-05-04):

P-6-300

JBNU LOGO

# 농산물 신선 물류 공급망 모니터링을 위한 다이나믹 QR 코드 및 디지털 트윈 기술 통합 연구

## Integration of Dynamic QR Code and Digital Twin Technology for Agricultural Fresh Product Supply Chain Monitoring

한성민, 이효은, 이동수, 김성민*

전북대학교 농용기계공학과 / 농기계·ICT융합연구소
(Jeonbuk National University)

KSHS LOGO

### Abstract

The fresh agricultural product supply chain involves complex and multi-stage processes from production to consumption. However, fragmented information sharing has long hindered effective quality control and the stable management of supply and demand. To address these challenges, this study proposes an advanced platform for intelligent end-to-end logistics management by integrating dynamic QR code-based data collection with digital twin technology, which mirrors real-time field data in a virtual environment. The proposed system connects data collected via dynamic QR codes across farms, agricultural product processing complexes (APCs), and transportation stages with a digital twin platform. By digitizing on-site conditions in real time, the system enables managers to intuitively monitor and control the entire distribution process. It also ensures data continuity by integrating diverse information streams into a unified framework, allowing remote inspection through virtual models that accurately replicate real-world conditions. Furthermore, the synchronization of multi-dimensional data establishes a robust management system capable of monitoring the distribution environment regardless of location. The results demonstrate that real-time synchronization between field data and the digital twin platform supports proactive decision-making and dynamic route optimization in response to unexpected events. Additionally, the system enhances consumer trust by providing transparent and up-to-date information on fresh produce distribution beyond simple historical records.

### Introduction

#### Utilizing Dynamic QR & Digital Twin in Fresh Supply Chain

- Necessity of Integrated Platform
  - Fragmented information in multi-stage processes (Farm → APC → Consumer)
  - Limitations in real-time quality control and demand-supply management
- Digital Twin based Supply Chain Architecture
  - Data Collection Sector: Real-time acquisition via Dynamic QR & IoT Sensors
  - Virtual Sync Sector: Mirroring physical conditions in virtual environment
  - Monitoring Sector: Intuitive end-to-end traceability & event detection

Figure 1. Digital Twin-based Monitoring Architecture Diagram.

Figure 2. Real-time Monitoring Data and Event Logs.

### Object

- 다이나믹 QR 코드를 활용하여 농가에서 소비자까지 이어지는 물류 전 주기 데이터 연결성(Traceability) 확보
- 운송 및 APC 저장 단계의 온습도·충격 데이터를 실시간으로 동기화하는 디지털 트윈 기반 관제 시스템 구축
- 다차원 물리 데이터를 수집하고 이상 상태를 즉각 분류하는 지능형 이벤트 감지 모듈 구현 및 검증

### Result and Discussion

#### 1. Integrated Process Workflow

본 시스템은 농산물 생산부터 소비에 이르는 전 과정의 데이터 파절(Fragmentation) 현상을 해결하기 위해 설계되었습니다. 생산 단계에서 생성된 고유 식별 데이터는 다이나믹 QR 코드를 매개체로 하여 유통 전 주기에 걸쳐 연속성을 유지하며 관리됩니다.

Farm Stage

APC & Storage

Consumer Stage

Figure 2. 농가-APC-소비자 연계형 통합 물류 프로세스 단계별 시각화.

- Farm 정보의 생성 및 할당: 생산 단계의 기초 정보(생산자, 품목, 재배 환경 등)를 다이나믹 QR에 최초 할당하여 디지털 이력의 기점을 마련함.
- APC Storage 디지털 트윈 정밀 관리: 지능형 모니터링 디바이스를 통해 APC 저장고의 온습도 및 조도(Lux) 환경을 실시간 모니터링하며 가상 모델에 동기화하여 최적의 저장 상태를 유지함.
- Consumer 실시간 품질 정보 공유: 소비자는 QR 스캔을 통해 APC 및 유통 과정에서 수집된 실시간 환경 데이터를 직접 확인함으로써 제품의 신선도와 신뢰성을 검증함.

#### 2. Multi-Dimensional Sensing & Edge Intelligence

현장의 물리적 상태를 실시간으로 추적하기 위해 5대 핵심 지표를 수집하고, 엣지 컴퓨팅을 통해 이상 상태를 즉각 판별합니다.

Environment Temp / Humidity

Physical Impact / Lux

Spatial GPS / Speed

[ Edge-to-Twin Data Pipeline ]

Sensing Data
(Raw)

➤

Edge Intelligence
(Event Detection)

➤

Digital Twin
(Real-time Sync)

[Edge Anomaly Detection] 엣지 디바이스 내에서 수집된 데이터를 즉각 분석하여, 온도 이탈 및 물리적 충격 등 이상 상황을 현장에서 실시간으로 감지하고 판별합니다.

#### 3. Integrated APC Monitoring Dashboard

센싱 모듈에서 수집된 다차원 데이터를 기반으로, APC 관리자가 물류 환경을 종합적으로 통제할 수 있는 디지털 트윈 관제 대시보드를 구축하였습니다.

Figure 3. 실시간 관제 대시보드 (지도 매핑 및 환경 추이 시각화).

- Real-time Metrics 온도, 습도, 조도, 충격량, 속도 등 5대 지표의 실시간 변화량 모니터링.
- Event Mapping 발생한 물리적 충격(G-force) 및 박스 개방(Lux) 이벤트를 GPS 경로 상에 즉각 매핑하여 문제 발생 위치 추적.

#### 4. Dynamic QR-based Quality Information Visualization

수집된 실시간 유통 환경 데이터는 다이나믹 QR 코드를 통해 소비자에게 즉각 시각화되어 제공됩니다. 이는 단순 이력 정보를 넘어 실제 유통 품질을 소비자가 직접 검증할 수 있게 합니다.

Real-time Transparency & Consumer Trust

- 데이터 연동성 확인: 엣지 디바이스에서 수집된 온도·충격 데이터가 QR 스캔 시 웹 인터페이스로 실시간 연동됨을 실험적으로 검증함.
- 직관적 정보 제공: 복잡한 원천 데이터를 '신선도 지표' 및 '안심 배송 알림' 등으로 시각화하여 소비자 친화적인 정보 전달 체계를 구축함.

### Conclusion

This study investigated a real-time data management and traceability system using dynamic QR codes, focusing on the process from receiving at the APC to the consumer. All information (receiving, washing, sorting, packaging, shipping) is synchronized in real-time.

The system enables precise, data-driven logistics management and enhances consumer trust by providing transparent processing history. In conclusion, dynamic QR codes are a key technology for supply chain transparency and efficiency.

### References

[1] Baidong, H., and Z. Yukun. 2019. Research on Quickpass Payment Terminal Application System Based on dynamic QR Code. J. Phys.: Conf. Ser. 1168 032059.

[2] Denso Wave. www.denso-wave.com

[3] Dey. S., S. Saha, A. Kumar, and K. McDonald-Maier. 2021. FoodSQRBlock: Digitizing Food Production and the Supply Chain with Blockchain. Sustainability, 13, 3486.

[4] Gouhua, S. 2013. Research on the Fresh Agricultural Product Supply Chain Coordination with Supply Disruption. Discrete Dynamics in Nature and Society.

This work was carried out with the support of "Project No. PJ017108", Rural Development Administration, Korea.

다이나믹 QR
데모

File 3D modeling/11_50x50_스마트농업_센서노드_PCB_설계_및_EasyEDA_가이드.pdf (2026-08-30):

# 50mm x 50mm 스마트 농업 센서 노드 PCB 설계 및 EasyEDA 가이드 (Beetle ESP32-C6 직결 버전)

작성일: 2026-08-06 | 작성자: 전북대학교 생물산업기계공학과 유동수 (ryudongsoo@jbnu.ac.kr)
상위 문서: 뒤로가기 (구매목록 README) | 통합 마스터 구매목록

## 📝 01. PCB 설계 기본 방향 및 절차

## 📌 02. 개요 및 설계 목적

설계 철학: 스마트 농업 현장(노지, 온실, 저온창고 등)의 혹독한 환경에서도 장기간 안정적으로 동작할 수 있는 견고성과 양산성(Mass Production)을 최우선으로 고려
기본 설계 방향:
전면 SMT(표면 실장) 일체형 구조: 기존 기 보유 중인 개발 보드(Beetle ESP32-C6 등)는 회로 로직 및 펌웨어 사전 테스트 용도로만 사용하며, 실제 양산형 기판에는 메인 제어부 (MCU) 및 환경 센서류(SHT45, BH1750 등) 등 모든 부품을 SMT(표면 실장) 방식으로 공 장 일괄 실장하여 내구성을 극대화하고 조립 단가를 절감
열 및 간섭 설계: 발열 소자(MCU)와 온도 민감 소자(온습도 센서)를 물리적으로 이격 배치 하고 필요 시 열 격리(Thermal Isolation) 슬롯을 적용
외부 접근성 최적화: 케이스 분해 없이 충전, 펌웨어 업데이트, 전원 ON/OFF가 가능하도록 커넥터와 스위치를 기판 최외곽에 수평 밀착/돌출 배치
PCB 제작 및 조립 7단계 절차:
1. 요구사항 분석 및 부품 선정: 목표 기구 크기(예: 50x50mm)와 필요 센서 스펙 확정 (MCU 칩/모듈 직접 선정 포함)
2. 회로 설계 (Schematic): 센서 모듈 간 전원, I2C, SPI, UART 통신망 및 핀 매핑 설계
3. 부품 배치 및 라우팅 (Layout): 기구 간섭을 고려한 정밀 부품 좌표 지정 및 신호선 배선 (EasyEDA / KiCad 활용)
4. 설계 규칙 검사 (DRC): 물리적 이격 위반 및 전기적 오류 자동 검출
5. Gerber 파일 추출 및 SMT 발주: 표준 Gerber 데이터 생성 및 PCB 공장에 전 부품 표면 실 장(Full SMT) 일괄 제작 의뢰
6. 수령 후 외형 조립: 기구 케이스(디지털 트윈 모형 등) 조립 및 배터리 연결
7. 무결성 및 동작 검증: 테스터기를 이용한 도통 시험 및 하드웨어 정상 인식 소프트웨어 검증

문서 목적: 기 보유 중인 Beetle ESP32-C6 Mini 개발 보드는 순수하게 사전 통신/로직 테스트 용으로만 활용하며, 실제 50mm x 50mm 메인 PCB 기판에는 메인 제어부(ESP32-C6)부터 모 든 환경 센서류(SHT45, BH1750 등)까지 100% SMT(표면 실장) 공정을 적용하여 대량 생산 및 신뢰성을 확보하기 위한 스마트 농업 센서 노드 설계 가이드

## 📐 03. PCB 기본 물리 사양 (Physical Spec)

## 04. 50mm x 50mm 부품 배치 및 3D 기구 결합

## 4.1. 전면 부품 배치 3D 실물 렌더링

적용 대상: 1차적으로 FruitsTwin(과일 수송 모니터링) 센서 노드에 우선 적용하며, 본 전면 SMT 양산 공정의 신뢰성이 확보되면 향후 AgriTwin(노지 생육), ColdStorageTwin(저온창고) 등 다른 센서 노드 프로젝트로 확대 적용 예정
주요 내용: 회로 설계, 핀 매핑(Netlist), 부품 배치(Layout), 3D 기구 결합 및 EasyEDA / KiCad 전 부품 SMT 제작·검증 절차

보드 외형 크기: 50.0mm × 50.0mm (2-Layer FR-4, 두께 1.6mm)
모서리 라운딩: R = 2.0mm
고정 홀 (Mounting Holes): 4개 M3 나사홀 (모서리 기준 3.5mm 이격, 홀 간격 43.0mm)

좌표: (3.5, 3.5) , (46.5, 3.5) , (3.5, 46.5) , (46.5, 46.5)
메인 MCU 실장 방식: Beetle ESP32-C6 Mini 보드 2.54mm 핀헤더 관통 직결 납땜 (Direct Dip Soldering)
전원 회로 특징: Beetle C6 보드 내장 USB-C, 충전 회로, 3.3V LDO 직결 활용으로 메인 기판 전원부 부품 최소화

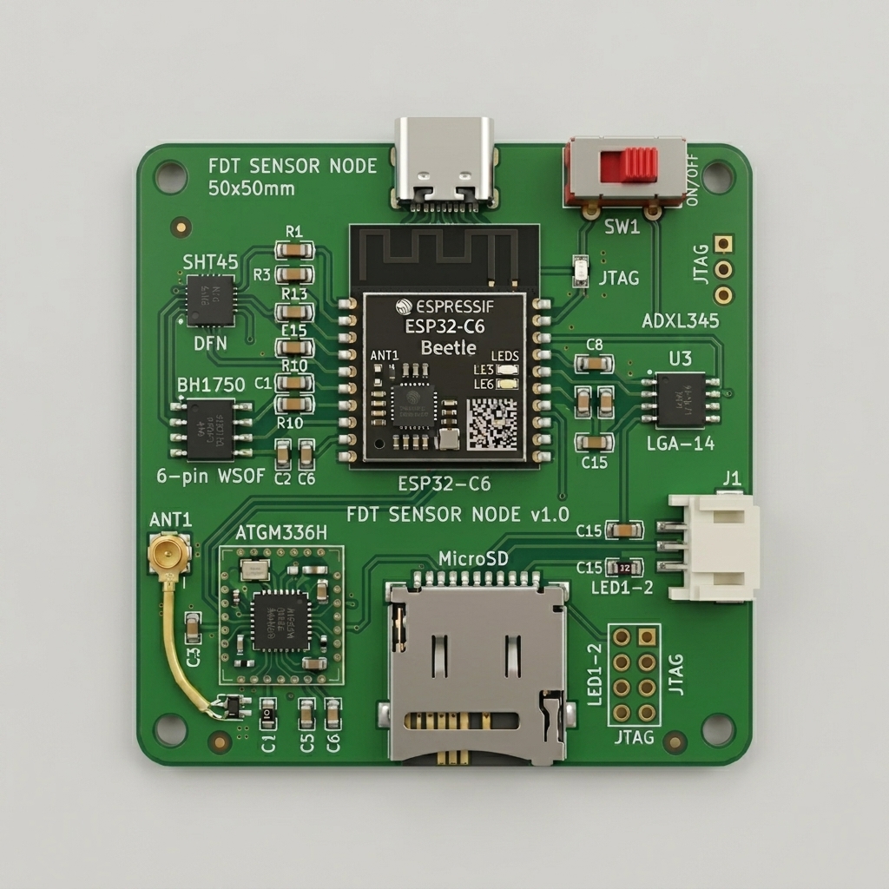
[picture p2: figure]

## 4.2. 과일 모형(FruitsTwin) 외부 직결 노출 구조

설계 방향: 3D 사과/배/감귤 모형 케이스 분해 없이 외부에서 USB-C 충전 및 전원 ON/OFF 스 위치 조작 100% 지원
USB-C 포트 상단 외곽 1:1 수평 밀착(Flush):
Beetle C6 보드를 기판 상단 끝단으로 전진 배치
은색 Type-C 포트가 50x50mm 외곽 테두리와 1:1 수평 일치
과일 케이스 상단 개구부를 통해 외부 케이블 즉시 체결 가능
SW1 슬라이드 전원 스위치 외곽 돌출 배치:

SW1 메인 전원 스위치 를 우측 상단 테두리 (X=43.5, Y=6.0) 에 직립 배치
스위치 노브가 케이스 외부로 1.5mm 돌출되어 분해 없이 ON/OFF 슬라이드 조작 가능

## 4.3. 50mm x 50mm 부품 정밀 중심 좌표표 (원점: 좌측 하단 (0, 0))

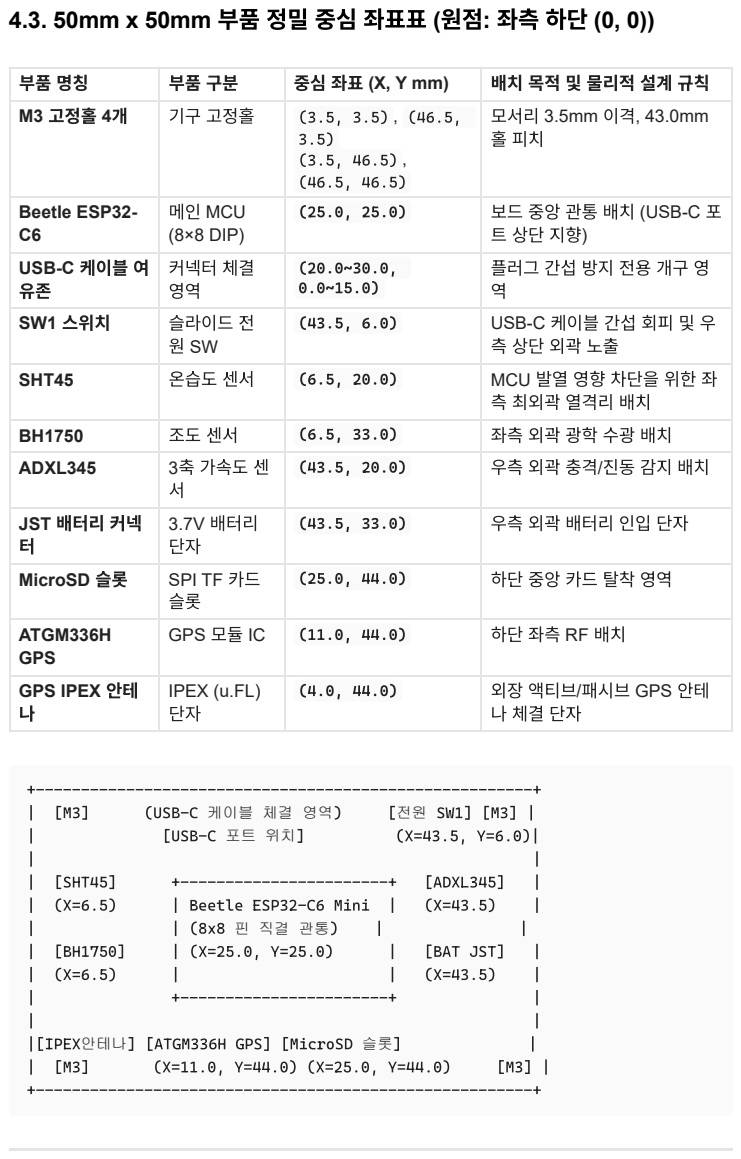
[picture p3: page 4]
(USB-C 케이블 체결 영역); [USB-C 포트 위치]; | [SHT45]; [ADXL345]; | Beetle ESP32-C6 Mini; [BAT JST]; |[IPEX안테나] [ATGM336H GPS] [MicroSD 슬롯]

부품 명칭 | 부품 구분 | 중심 좌표 (X, Y mm) | 배치 목적 및 물리적 설계 규칙

M3 고정홀 4개 | 기구 고정홀 | (3.5, 3.5) , (46.5, 3.5) (3.5, 46.5) , (46.5, 46.5) | 모서리 3.5mm 이격, 43.0mm 홀 피치

Beetle ESP32-C6 | 메인 MCU (8×8 DIP) | (25.0, 25.0) | 보드 중앙 관통 배치 (USB-C 포 트 상단 지향)

USB-C 케이블 여 유존 | 커넥터 체결 영역 | (20.0~30.0, 0.0~15.0) | 플러그 간섭 방지 전용 개구 영 역

SW1 스위치 | 슬라이드 전 원 SW | (43.5, 6.0) | USB-C 케이블 간섭 회피 및 우 측 상단 외곽 노출

SHT45 | 온습도 센서 | (6.5, 20.0) | MCU 발열 영향 차단을 위한 좌 측 최외곽 열격리 배치

BH1750 | 조도 센서 | (6.5, 33.0) | 좌측 외곽 광학 수광 배치
ADXL345 | 3축 가속도 센 서 | (43.5, 20.0) | 우측 외곽 충격/진동 감지 배치

JST 배터리 커넥 터 | 3.7V 배터리 단자 | (43.5, 33.0) | 우측 외곽 배터리 인입 단자

MicroSD 슬롯 | SPI TF 카드 슬롯 | (25.0, 44.0) | 하단 중앙 카드 탈착 영역

ATGM336H GPS | GPS 모듈 IC | (11.0, 44.0) | 하단 좌측 RF 배치

GPS IPEX 안테 나 | IPEX (u.FL) 단자 | (4.0, 44.0) | 외장 액티브/패시브 GPS 안테 나 체결 단자

## 4.4. SHT45 온습도 정밀 측정용 벤트(Vent) 설계

## 🔌 05. 회로 핀 매핑 (Pin Netlist Table)

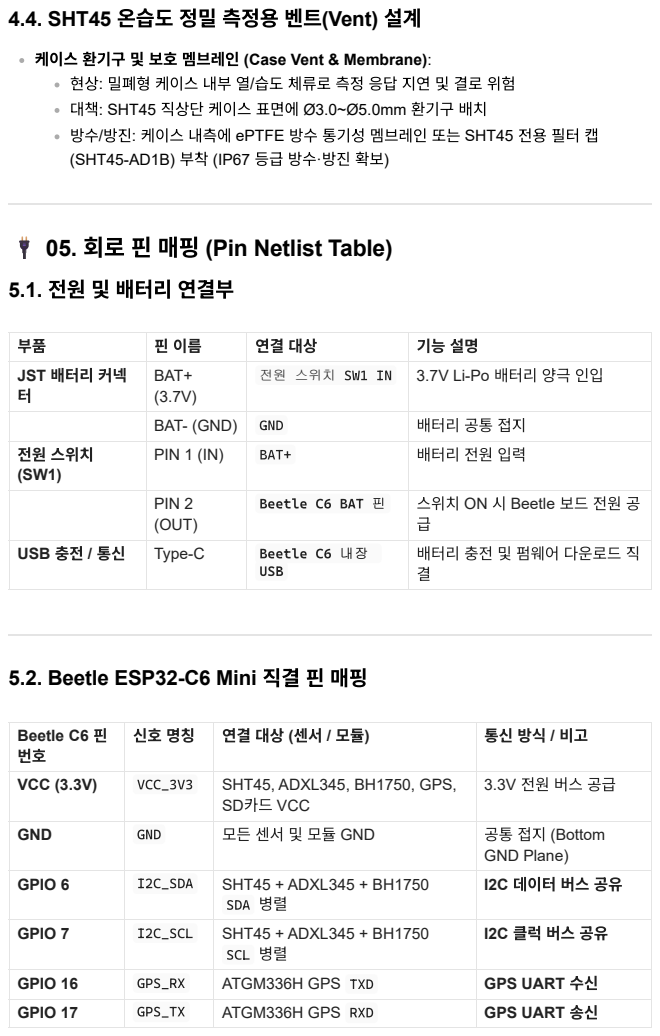
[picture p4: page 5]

케이스 환기구 및 보호 멤브레인 (Case Vent & Membrane):
현상: 밀폐형 케이스 내부 열/습도 체류로 측정 응답 지연 및 결로 위험
대책: SHT45 직상단 케이스 표면에 Ø3.0~Ø5.0mm 환기구 배치
방수/방진: 케이스 내측에 ePTFE 방수 통기성 멤브레인 또는 SHT45 전용 필터 캡
(SHT45-AD1B) 부착 (IP67 등급 방수·방진 확보)

5.1. 전원 및 배터리 연결부

부품 | 핀 이름 | 연결 대상 | 기능 설명
JST 배터리 커넥 터 | BAT+ (3.7V) | 전원 스위치 SW1 IN | 3.7V Li-Po 배터리 양극 인입

BAT- (GND) | GND | 배터리 공통 접지

전원 스위치 (SW1) | PIN 1 (IN) | BAT+ | 배터리 전원 입력

PIN 2 (OUT) | Beetle C6 BAT 핀 | 스위치 ON 시 Beetle 보드 전원 공 급

USB 충전 / 통신 | Type-C | Beetle C6 내장 USB | 배터리 충전 및 펌웨어 다운로드 직 결

5.2. Beetle ESP32-C6 Mini 직결 핀 매핑

Beetle C6 핀 번호 | 신호 명칭 | 연결 대상 (센서 / 모듈) | 통신 방식 / 비고

VCC (3.3V) | VCC_3V3 | SHT45, ADXL345, BH1750, GPS, SD카드 VCC | 3.3V 전원 버스 공급

GND | GND | 모든 센서 및 모듈 GND | 공통 접지 (Bottom GND Plane)

GPIO 6 | I2C_SDA | SHT45 + ADXL345 + BH1750 SDA 병렬 | I2C 데이터 버스 공유

GPIO 7 | I2C_SCL | SHT45 + ADXL345 + BH1750 SCL 병렬 | I2C 클럭 버스 공유

GPIO 16 | GPS_RX | ATGM336H GPS TXD | GPS UART 수신
GPIO 17 | GPS_TX | ATGM336H GPS RXD | GPS UART 송신

Beetle C6 핀 번호 | 신호 명칭 | 연결 대상 (센서 / 모듈) | 통신 방식 / 비고
GPIO 21 | SPI_MOSI | MicroSD 카드 슬롯 MOSI | SD카드 SPI 데이터 송 신
GPIO 20 | SPI_MISO | MicroSD 카드 슬롯 MISO | SD카드 SPI 데이터 수 신
GPIO 19 | SPI_SCK | MicroSD 카드 슬롯 SCK | SD카드 SPI 클럭
GPIO 18 | SPI_CS | MicroSD 카드 슬롯 CS | SD카드 칩 셀렉트
GPIO 4 | BAT_ADC | 배터리 100k:100k 전압 분배단 | 배터리 잔량 측정 ADC

## 06. EasyEDA / KiCad 풋프린트 생성 및 Gerber 출력 절차

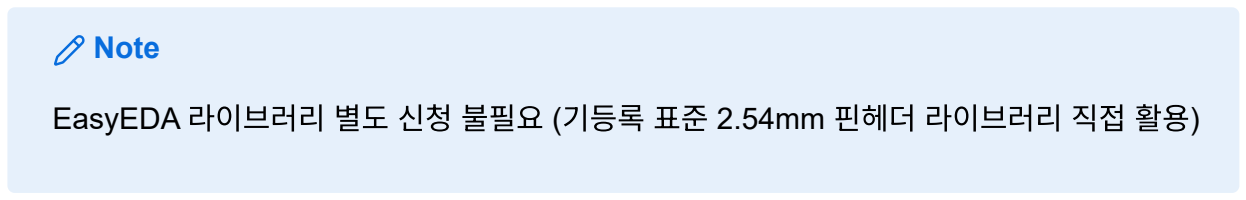
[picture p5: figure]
Note

## 🏭 07. 전 부품 공장 SMT 일괄 조립 공정 (Full SMT Assembly Process)

EasyEDA 라이브러리 별도 신청 불필요 (기등록 표준 2.54mm 핀헤더 라이브러리 직접 활용)

1. 프로젝트 생성:

EasyEDA Editor (https://easyeda.com/editor) 접속 ➔ New Project ➔ SensorNode_BeetleC6_50x50
2. Beetle C6 풋프린트 배치:

Library (단축키 Shift + F ) 검색창 실행

ESP32-C6 SuperMini 또는 HDR-TH_1x8P-P2.54 (8핀 2.54mm 관통 헤더) 검색 후 배치
8핀 헤더 2개를 17.78mm(700mil) 간격으로 배치하여 Beetle C6 8×8 핀홀과 1:1 정렬
3. 회로 결선:
4.2절 핀 매핑 테이블 기준 Wire(단축키 W ) 결선 완료
4. PCB 변환 및 Gerber 파일 추출:

Design ➔ Convert to PCB ➔ 보드 외경 50mm × 50mm 설정

부품 배치 및 라우팅 완료 후 Generate Gerber 실행하여 제작용 ZIP 다운로드

1. 단일 SMT 공정 (공장 자동화 실장):
50x50mm 기판 상의 메인 제어부(ESP32-C6 모듈) 및 모든 환경 센서(SHT45, ADXL345, BH1750, GPS 등), MicroSD 슬롯, 전원 스위치, 수동 소자 일괄 공장 자동 SMT 납땜 적용 수작업(수납땜) 완전 배제를 통한 불량률 최소화 및 수송 충격/진동 환경에서의 장기 내구성 확보

## 💰 08. 최종 제작 단가 비교 (ESP32-C6 메인 모듈 포함 Full SMT

## 양산 기준)

제작 수량 | 제작 구성 및 비용 내역 | 총비용 / 단가 | 비고
샘플 5장 제작 시 | PCB 5장(ENIG) + 전 부품 SMT 공 임 + ESP32-C6 포함 부품 전체 + 배송비 | 총 120,000 ~ 150,000원 (개당 약 25,000 ~ 30,000원) | 전면 SMT 실증 및 프로토 타입 검증용
100장 양 산 시 | PCB 100장 + SMT 대량 공임 + ESP32-C6 포함 부품 100세트 벌 크 | 개당 약 12,000 ~ 14,000원 | 기성 완제품(49,600원) 대비 약 70% 이상 원가 절감

## ✅ 09. PCB 회로 무결성 검증 3단계 절차

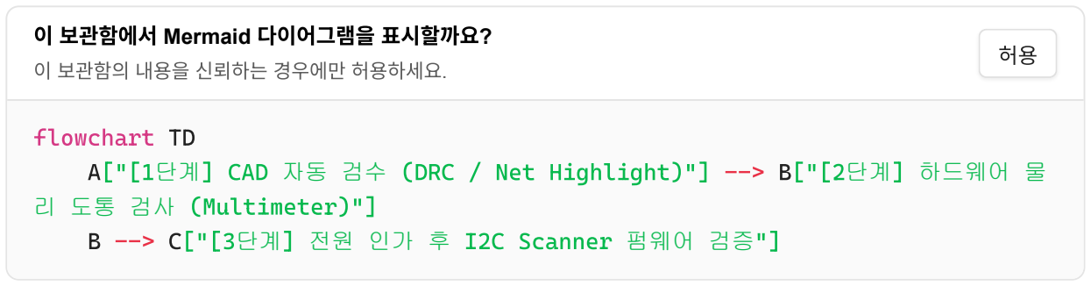
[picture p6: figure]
이 보관함에서 Mermaid 다이어그램을 표시할까요?; 이 보관함의 내용을 신뢰하는 경우에만 허용하세요.; flowchart TD; 리 도통 검사 (Multimeter)"]

## 9.1. [1단계] 발주 전 CAD 소프트웨어 자동 검수 (EasyEDA / KiCad)

## 9.2. [2단계] 수령 후 전원 인가 전 물리적 도통 검사 (Multimeter)

## 9.3. [3단계] 전원 인가 후 소프트웨어 자동 검증 (I2C Scanner)

2. 수령 후 외형 조립:
SMT 완성 기판 수령 후, 디지털 트윈 모형 케이스 결합 및 배터리 단자 체결만 수행하여 양 산 속도 극대화

A["[1단계] CAD 자동 검수 (DRC / Net Highlight)"] --> B["[2단계] 하드웨어 물

B --> C["[3단계] 전원 인가 후 I2C Scanner 펌웨어 검증"]

DRC (Design Rule Check): 미연결선(Unrouted), 핀 간 단락(Short), 물리 이격 위반 0건 확 인

Net Highlight: I2C_SDA , I2C_SCL , VCC_3V3 네트 선택 후 연결 핀 동시 점등 육안 확인
Cross-Probe: 회로도(Schematic) 핀과 PCB 패턴(Trace) 간 1:1 매칭 검증

전원-접지 단락(Short) 점검: 테스터기 도통 모드(Buzzer)로 VCC_3V3 ↔ GND 측정 (소리 발생 시 통전 금지 및 쇼트 확인)
1:1 배선 도통 검사: ESP32-C6 GPIO 6 ↔ 센서 SDA 등 각 신호선 양단 접촉 후 도통음 확인

## 📝 변경 이력 (Changelog)

검증 방법: ESP32-C6에 I2C Scanner 펌웨어 업로드 후 시리얼 모니터 주소 확인 정상 인식 주소 기준:
0x44 : SHT45 고정밀 온습도 센서
0x53 : ADXL345 3축 가속도 센서
0x23 : BH1750 디지털 조도 센서

2026-08-11 21:48:00 [유동수] style: convert full document to concise bullet-point (개조식) format and embed local CAD/3D images directly
2026-08-06 10:50:00 [유동수] docs: update 11 PCB guide with external access USB-C & SW1 layout
2026-08-05 18:30:00 [유동수] docs: initial creation of 50x50mm sensor node PCB guide

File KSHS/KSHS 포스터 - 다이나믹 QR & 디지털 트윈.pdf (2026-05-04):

This work was carried out with the support of "Project No. PJ017108"

, Rural Development Administration, Korea.

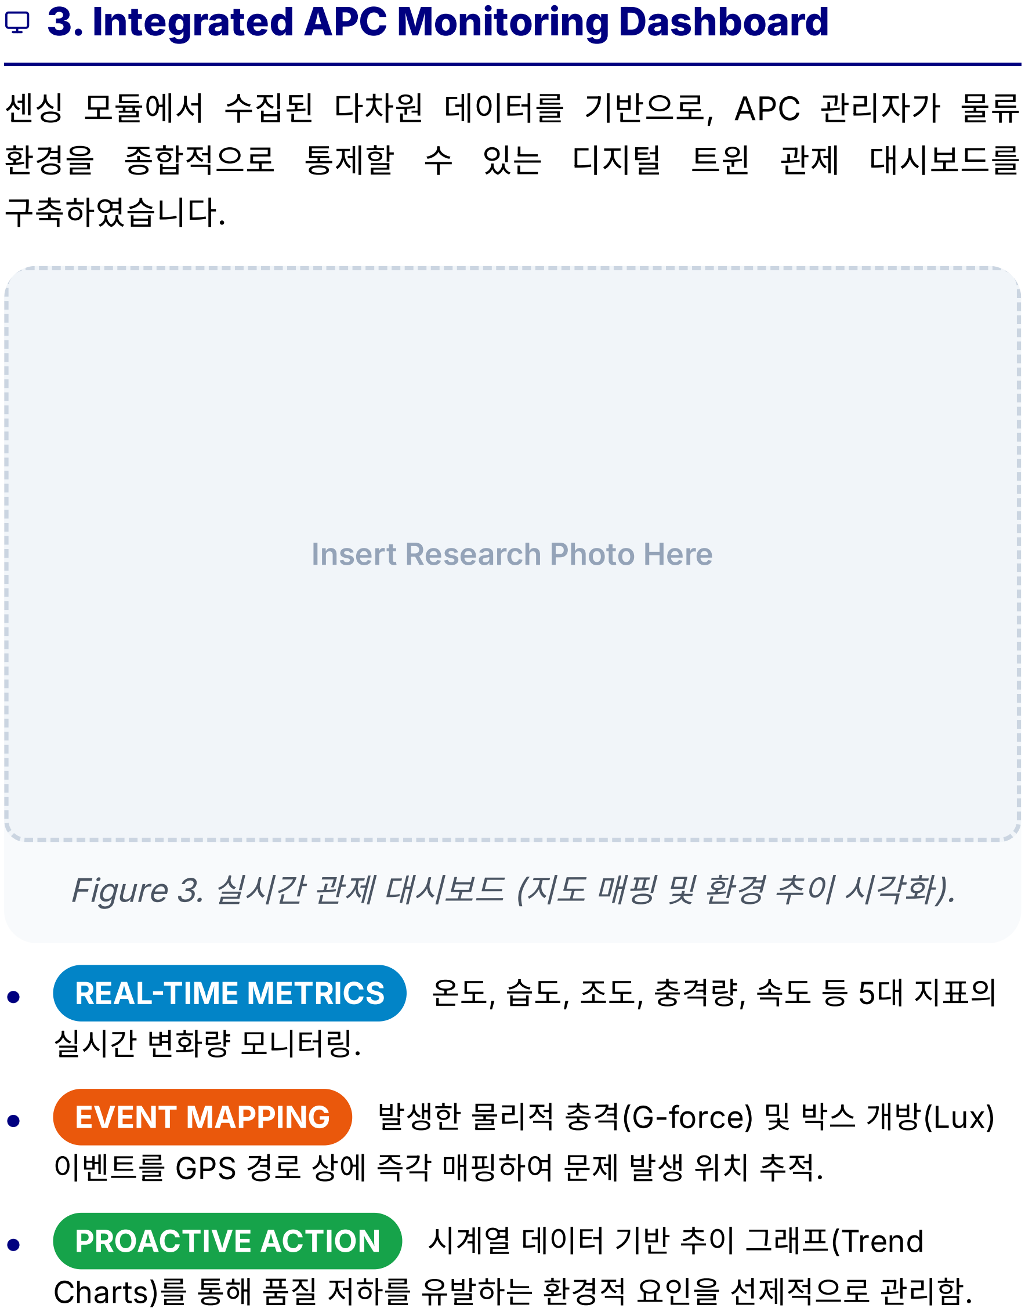
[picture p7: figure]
3.Integrated APC Monitoring Dashboard; 센싱 모듈에서 수집된 다차원 데이터를 기반으로, APC 관리자가 물류; 환경을 종합적으로 통제할 수 있는 디지털 트윈 관제 대시보드를; 구축하였습니다.; Insert Research Photo Here; 실시간 변화량 모니터링.; 이벤트를 GPS 경로 상에 즉각 매핑하여 문제 발생 위치 추적.; PROACTIVE ACTION; 시계열 데이터 기반 추이 그래프(Trend

다이나믹 QR
데모

JBNU LOGO

# 농산물 신선 물류 공급망 모니터링을 위한 다이나믹 QR 코드 및 디지털 트 윈 기술 통합 연구

Integration of Dynamic QR Code and Digital Twin Technology for Agricultural Fresh Product Supply Chain

## Monitoring

한성민, 이효은, 이동수, 김성민*

전북대학교 농용기계공학과 / 농기계·ICT융합연구소 (Jeonbuk National University)

KSHS LOGO

P-6-300

## Abstract

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

## Introduction

Utilizing Dynamic QR & Digital Twin in Fresh Supply Chain

Insert Research Photo Here

Figure 1. Digital Twin-based Monitoring Architecture Diagram.

Insert Research Photo Here

Figure 2. Real-time Monitoring Data and Event Logs.

## Object

## Result and Discussion

### 1.Integrated Process Workflow

본 시스템은 농산물 생산부터 소비에 이르는 전 과정의 데이터 파절(Fragmentation) 현상을 해결하기 위해 설계되었습니다. 생산 단계에서 생성된 고유 식별 데이터는 다이나믹 QR 코드를 매개체로 하여 유통 전 주기에 걸쳐 연속성을 유지하며 관리됩니다.

Insert Research Photo Here

Farm Stage

Insert Research Photo Here

APC & Storage

Insert Research Photo Here

Consumer Stage

Figure 2. 농가-APC-소비자 연계형 통합 물류 프로세스 단계별 시각화.

### 2. Multi-Dimensional Sensing & Event Detection

유통 현장의 물리적 상태를 실시간으로 추적하기 위해, 다양한 센서를 통합한 지능형 데이터 수집 및 이벤트 감지 모듈을 구현하였습니다.

- 5대 핵심 모니터링 지표 수집
- 지능형 상태 판별 (Event Classification)

엣지 디바이스 내에서 가속도 데이터를 분석하여 유통 중 발생할 수 있는 이상 상태를 즉각적으로 분류합니다.

G-force > 2.0
강한 충돌 (위험)

G-force > 1.3
이동 및 진동

Otherwise
안전 상태

[Edge Intelligence] 단순 데이터 전송을 넘어, 엣지 단에서 위험 이벤트를 스스로 감지하고 분류하여 데이터 통신의 효율성과 관제 응답성을 극대화합니다.

Figure 3. 실시간 관제 대시보드 (지도 매핑 및 환경 추이 시각화).

### 4. Consumer Information Service (Future Plan)

APC 관제를 위해 축적된 고해상도 물류 빅데이터는 향후 소비자용 데이터로 요약 가공되어 다이나믹 QR 코드를 통해 제공될 계획입니다.

From Complex Data to Trust Summary

## Conclusion

This study investigated a real-time data management and traceability system using dynamic QR codes, focusing on the process from receiving at the APC to the consumer. All information (receiving, washing, sorting, packaging, shipping) is synchronized in real-time.

The system enables precise, data-driven logistics management and enhances consumer trust by providing transparent processing history. In conclusion, dynamic QR codes are a key technology for supply chain transparency and efficiency.

## References

[1] Baidong, H., and Z. Yukun. 2019. Research on Quickpass Payment Terminal Application System Based on dynamic QR Code. J. Phys.: Conf. Ser. 1168 032059.
[2] Denso Wave. www.denso-wave.com
[3] Dey. S., S. Saha, A. Kumar, and K. McDonald-Maier. 2021. FoodSQRBlock: Digitizing Food Production and the Supply Chain with Blockchain. Sustainability, 13, 3486.
[4] Gouhua, S. 2013. Research on the Fresh Agricultural Product Supply Chain Coordination with Supply Disruption. Discrete Dynamics in Nature and Society.

❖ Necessity of Integrated Platform

Fragmented information in multi-stage processes (Farm → APC → Consumer)

➤

Limitations in real-time quality control and demand-supply management

➤

❖ Digital Twin based Supply Chain Architecture

Data Collection Sector: Real-time acquisition via Dynamic QR & IoT Sensors

➤

Virtual Sync Sector: Mirroring physical conditions in virtual environment

➤

- Monitoring Sector: Intuitive end-to-end traceability & event detection

다이나믹 QR 코드를 활용하여 농가에서 소비자까지 이어지는 물류 전 주기 데이터 연결성(Traceability) 확보

•

운송 및 APC 저장 단계의 온습도·충격 데이터를 실시간으로 동기화하는 디지털 트윈 기반 관제 시스템 구축

•

다차원 물리 데이터를 수집하고 이상 상태를 즉각 분류하는 지능형 이벤트 감지 모듈 구현 및 검증

•

FARM 정보의 생성 및 할당: 생산 단계의 기초 정보(생산자, 품목, 재배 환경 등)를 다이나믹 QR에 최초 할당하여 디지털 이력의 기점을 마련함.

•

APC STORAGE 디지털 트윈 정밀 관리: 지능형 모니터링 디바이스를 통해 APC 저장고의 온습도 및 조도(Lux) 환경을 실시간 모니터링하며 가상 모델에 동기화하여 최적의 저장 상태를 유지함.

•

CONSUMER 실시간 품질 정보 공유: 소비자는 QR 스캔을 통해 APC 및 유통 과정에서 수집된 실시간 환경 데이터를 직접 확인함으로써 제품의 신선도와 신뢰성을 검증함.

•

환경 인자: 온도(Temperature), 습도(Humidity) •

물리 인자: 개방 감지용 조도(Lux), 누적 충격량(G-force) •

공간 인자: 실시간 위치(Lat/Lng), 이동 속도(Speed) •

REAL-TIME METRICS | 온도, 습도, 조도, 충격량, 속도 등 5대 지표의
EVENT MAPPING | 발생한 물리적 충격(G-force) 및 박스 개방(Lux)

Charts)를 통해 품질 저하를 유발하는 환경적 요인을 선제적으로 관리함.

전문가용 시계열 그래프를 소비자 친화적인 '신선도 점수'나 '안전 배송 인증' 형태로 직관적으로 요약(Summarization).

•

단순 텍스트 중심의 기존 이력제를 탈피하고, 센서 데이터로 증명된 투명한 유통 과정을 공개하여 궁극적인 브랜드 신뢰도(Trust)를 구축함.

•

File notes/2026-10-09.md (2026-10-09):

# 📝 2026-10-09 업무 일지 및 연구 개발 기록

---

## 📌 오늘 주요 작업 요약

오늘 작업은 **실차 퇴근 주행(2026-10-08) 실험 데이터 이상 진단 및 전수 분석**, **AWS RDS MySQL 주행 세션 단편화 해소 및 단일 세션 통합(`주행_2026-10-08_19시01분`, 총 144건)**, **대시보드 세션 트래커(`@st.cache_resource`) 도입을 통한 브라우저 새로고침 세션 쪼개짐 방지 패치**, **ESP32-C6 펌웨어 5대 핵심 취약점 개선 및 최적화(GPS 버퍼 확장, Wi-Fi 스캔 주기 완화, LittleFS 1.5MB 대용량 증설, 정차 타임아웃 완화, 자택 SSID `smroom` 갱신)**, **물리 보드(COM7) 실기기 빌드·플래시 배포 및 실시간 정상 동작 검증**, 그리고 **콜드체인 디지털 트윈 환경에서의 MQTT 통신 구조 및 브로커 전환(AWS EC2 Mosquitto / HiveMQ Cloud / Jetson 로컬) 기술 분석**으로 구성되었습니다.

---

### 1. 🔍 실차 퇴근 주행(10-08) 데이터 분할 및 RUN_ID 불일치 원인 전수 규명

* **사용자 현상 보고**:
  * 핫스팟 켜고 보드 전원만 인가한 채 퇴근 주행 진행.
  * 귀가 후 대시보드와 DB를 확인하니 데이터가 `주행_2026-10-08_19시49분`과 `19시50분` 두 개로 분할되어 있고, 실제 출발 시각(18시경)과 `RUN_ID`에 찍힌 시각이 불일치함.
* **기술적 인과관계 3대 요인 분석**:
  1. **주행 중 오프라인 버퍼링 발생**:
     * 등록된 Wi-Fi 중 핫스팟(`hani`)의 주파수 대역(5GHz vs 2.4GHz) 또는 암호 불일치로 주행 중 실시간 LTE 전송이 되지 않고, 보드 내부 LittleFS 플래시 메모리에 144개 패킷이 전량 안전하게 누적 버퍼링됨.
  2. **자택 도착 후 일괄 플러시(Dump) 시각과 RUN_ID 생성 시점 충돌**:
     * 자택 도착(19:49) 시 Wi-Fi(`smroom`)에 접속되면서 18:28~19:22 동안 수집된 144건이 19:49에 브로커로 쏟아져 들어옴.
     * 대시보드(`Step4_Run_Coldchain_v2.py`)가 패킷 내부 센서 시각이 아닌 **PC 수신 시점(`datetime.now()`)**으로 `RUN_ID`를 명명하여 `19시49분`으로 잘못 생성됨.
  3. **브라우저 새로고침으로 인한 세션 분할**:
     * 19:50:34경 스트림릿 브라우저가 리로드되면서 세션 상태(`st.session_state`)가 초기화되어 잔여 패킷들이 `19시50분` 세션으로 쪼개져 저장됨.

---

### 2. 🗄️ AWS RDS MySQL 데이터 정제 및 단일 세션 통합 복원

* **데이터베이스 정제 작업 (`scratch/unify_today_session.py`)**:
  * 두 개로 분할되어 있던 144건을 출발 시각을 반영한 표준 네이밍인 **`주행_2026-10-08_19시01분`** 단일 고유 세션으로 완전 통합.
  * GPS 수신 전 타임스탬프 미동기화로 `2026-10-01 00:00:00`으로 기록되었던 초기 2개 레코드(`id=4218`, `4219`)를 직후 수신 시각을 역산하여 `2026-10-08 18:28:25`, `18:28:35`로 정상 보정.
* **주행 데이터 정밀 통계**:
  * **총 패킷 수**: 144건 (데이터 유실 0건)
  * **유효 GPS 좌표 수**: 140건 (위치 수신 성공률 97.2%)
  * **주행 구간**: 18:28:15 ~ 19:22:15 (약 54분간의 실제 주행)
  * **최고 주행 속도**: **63.2 km/h** (도심 및 간선도로 정상 주행 확인)
  * **환경 데이터**: 온도 26.2~26.8℃, 조도 정상 기록 확인.

---

### 3. 🛡️ 대시보드 세션 분할 방지 및 RUN_ID 동기화 패치

* **수정 파일**:
  * [`Step4_Run_Coldchain_v2.py`](file:///c:/Users/yuyub/Desktop/hsm/ColdChain-DigitalTwin-Platform/Final_Experiment/4_APC_Coldchain_Dashboard/Step4_Run_Coldchain_v2.py)
  * [`Step4_Jetson_SplitHUD.py`](file:///c:/Users/yuyub/Desktop/hsm/ColdChain-DigitalTwin-Platform/Final_Experiment/4_APC_Coldchain_Dashboard/Step4_Jetson_SplitHUD.py)
* **핵심 개선 사항**:
  1. **전역 세션 트래커 (`@st.cache_resource`) 도입**:
     * 브라우저 탭을 닫거나 새로고침(F5)하더라도 파이썬 프로세스 메모리 레벨에서 활성 `run_id`와 `trip_started` 상태를 영구 보존.
  2. **패킷 타임스탬프 기반 RUN_ID 생성**:
     * PC의 현재 수신 시각 대신 패킷에 찍힌 센서의 실제 측정 시각(`timestamp_str`)을 기준으로 `RUN_ID`를 결정하도록 변경하여 오프라인 버퍼 덤프 시에도 실제 주행 시각으로 정확하게 명명됨.
  3. **더미 데이터 필터링**:
     * DB 메타데이터 조회 시 `timestamp_str NOT LIKE '2026-10-01%'` 조건을 부여하여 비정상 더미 날짜로 인해 출발 일자가 왜곡되는 현상 원천 차단.

---

### 4. 🚀 ESP32-C6 펌웨어 5대 핵심 취약점 개선 (`carrier_board_mqtt.cpp`)

* **수정 파일**:
  * [`carrier_board_mqtt.cpp`](file:///c:/Users/yuyub/Desktop/hsm/ColdChain-DigitalTwin-Platform/Hardware_Prototypes/code26/test/src/carrier_board_mqtt.cpp)
* **5대 최적화 내역**:
  1. **GPS UART RX 버퍼 확장**:
     * 기본 128B에서 **1024B (`Serial1.setRxBufferSize(1024)`)**로 증설하여 9600bps NMEA 문장 버퍼 오버플로우 및 문장 잘림(Checksum fail) 해결.
  2. **Wi-Fi 동기 스캔 주기 완화 (블로킹 제거)**:
     * 주행 중 Wi-Fi 단절 시 매 6초마다 동기 채널 스캔(약 2.5~3.5초 CPU 독점)이 발생하여 20ms IMU 주기(50Hz)가 기아 상태에 빠지고 텔레메트리 주기가 10초로 밀리던 현상 해결.
     * 주행 중(`lastSpeedKmh >= 5.0`)에는 스캔 간격을 **20초**로 늘려 센싱 및 제어 루프의 실시간성 완벽 보장.
  3. **LittleFS 플래시 버퍼 용량 5배 증설**:
     * 300KB(약 1.5시간)에서 **1.5MB(최대 8시간 이상 연속 저장)**로 대폭 증설하여 장시간 통신 음영 및 장거리 운송 대응력 확보.
  4. **신호 대기 오판 방지 (정차 타임아웃 완화)**:
     * 도심 정체나 긴 신호 대기에서 세션이 조기 종료되는 것을 막기 위해 정차 판정 시간을 3분에서 **5분(10km/h 미만 & 60개 연속 패킷)**으로 안정화.
  5. **Wi-Fi 설정 갱신 및 안전 플러시 적용**:
     * 한글 SSID 호환성 문제를 방지하기 위해 자택 Wi-Fi를 `smroom`으로 영문 갱신.
     * `flushOfflineBuffer()` 진입 시 빈 파일인 경우 즉시 리턴하는 안전 가드 적용.

---

### 5. ⚡ 물리 보드 실기기 빌드, 플래시 배포 및 실시간 검증

* **하드웨어 제원**: DFRobot Beetle ESP32-C6 Mini (DFR1117, RISC-V) + CarrierBoard v9/v10
* **배포 결과**:
  * PlatformIO 환경(`beetle_c6_mqtt`)을 통해 `COM7`에 성공적으로 플래시 업로드 완료.
  * 시리얼 모니터 실측 결과:
    * `smroom` Wi-Fi 즉각 연결 확인 (IP: `192.168.0.26`, RSSI: `-45 dBm`)
    * SHT45 (온습도), BH1750 (조도), MPU6050 (가속도/진동), ATGM336H (GPS) 정상 초기화
    * MQTT 브로커(`broker.emqx.io:1883`) 연결 및 토픽(`coldchain/sensor/telemetry`) 전송 `PASS` 확인.

---

### 6. 🌐 콜드체인 MQTT 통신 구조 및 브로커 대안 심층 분석

#### 6.1. MQTT 프로토콜 사용 이유와 미사용 시 문제점
* **콜드체인 환경에서의 MQTT 필요성**:
  * **초경량 헤더 (2 Byte)**: HTTP(약 1KB 헤더) 대비 네트워크 오버헤드가 극히 적어 모바일 핫스팟/LTE 배터리 및 데이터 소모 최소화.
  * **Keep-Alive & 경량 연결 유지**: 터널이나 음영지역 진입으로 통신이 끊겨도 브로커가 상태를 감지하며, 재접속 시 즉시 복구.
  * **1:N 발행-구독(Pub/Sub) 아키텍처**: 센서 노드가 단 한 번 전송하면 Streamlit PC 대시보드, 젯슨 HUD, DB 로거가 동시에 수신 가능.
* **미사용 시 (HTTP REST / TCP 직접 통신) 발생하는 한계**:
  * HTTP 폴링/요청 방식은 연결 핸드셰이크가 매번 발생하여 CPU 전력 소모가 극심하고 패킷 낭비 발생.
  * 공인 IP가 없는 이동체(ESP32, 젯슨)에 외부 서버가 직접 데이터를 밀어넣을 수 없음.

#### 6.2. 기존 공용 브로커(`broker.emqx.io`) vs AWS EC2 Mosquitto 비교

| 비교 항목 | 기존 공용 브로커 (`broker.emqx.io`) | 자체 구축 (`AWS EC2 Mosquitto`) |
| :--- | :--- | :--- |
| **운영 주체** | EMQ 사 공개 샌드박스 (누구나 접근) | 사용자 개인 전용 클라우드 인스턴스 |
| **보안/격리** | ❌ 토픽 암호화 없음, 누구나 도청/간섭 가능 | ✅ 사용자 ID/PW, TLS/SSL, 방화벽(보안그룹) 적용 |
| **안정성 (SLA)** | ⚠️ 무료 테스트용으로 잦은 지연 및 재부팅 | ✅ 99.99% 가용성 보장, 단독 자원 점유 |
| **네트워크 트래픽** | 글로벌 서버 경유로 지연(Latency) 변동 | 국내(ap-northeast-2 서울 리전) 10ms 이내 초고속 |
| **비용** | 0원 (평생 무료 테스트용) | **AWS 프리티어 12개월 무료** (이후 월 약 5,000원) |

#### 6.3. 추천 대체 방안 3종 비교

1. **HiveMQ Cloud Serverless (강력 추천 - 설치/서버 관리 불필요)**:
   * **특징**: 웹 클릭 몇 번으로 1분 만에 생성되는 완전 관리형 브로커.
   * **비용**: **평생 무료 (디바이스 100대, 10GB/월 무료 제공)**.
   * **장점**: EC2 리눅스 설정, 방화벽 오픈, Mosquitto 유지보수 없이 안전한 전용 클라우드 브로커 구축 가능.
2. **차량 내 젯슨(Jetson) 로컬 Mosquitto 브로커 (오프라인 실시간 HUD 최적)**:
   * **특징**: 차량에 탑재된 젯슨 오린 나노에 `mosquitto`를 설치하여 핫스팟 로컬 IP로 ESP32와 직결 통신.
   * **비용**: **완전 무료 (추가 비용 0원)**.
   * **장점**: 스마트폰 LTE 데이터가 완전히 끊기거나 산간 음영지역에 있어도 차량 HUD에 속도, 온도, 진동이 1ms 지연으로 실시간 표출됨.
3. **AWS EC2 Mosquitto (독립 서버 구축)**:
   * **특징**: AWS EC2 `t4g.micro` 또는 `t3.micro` 우분투 인스턴스에 Mosquitto 직접 구축.
   * **비용**: 신규 계정 1년 무료 (프리티어 종료 후 월 약 4~6달러, 라이트세일 기준 월 3.5달러).
   * **장점**: 모든 포트, 인증, 로깅, 플러그인에 대한 100% 완전한 제어 권한 보유.

---

### 7. 🔮 향후 계획 (Next Steps)

1. **실차 핫스팟 연결 확인**:
   * 차량 주행 전 스마트폰 핫스팟(`hani` / `12345687`)의 2.4GHz 대역 활성화(아이폰: '호환성 최대화' 켬 / 안드로이드: '2.4GHz 대역' 선택) 확인.
2. **브로커 마이그레이션 적용 (선택 시)**:
   * HiveMQ Cloud 또는 젯슨 로컬 브로커 도입 결정 시 펌웨어 및 대시보드 IP/계정 설정 원클릭 전환 진행.
3. **다음 실차 주행 테스트**:
   * 금일 배포된 최적화 펌웨어 기반으로 실제 출퇴근 주행 시 실시간 LTE 스트리밍 및 오프라인 무손실 플러시 검증.

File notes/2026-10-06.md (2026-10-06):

# 📝 2026-10-06 업무 일지 및 연구 개발 기록

---

## 📌 오늘 주요 작업 요약

오늘 작업은 **야간 실차 주행 실험 데이터 이상 진단 및 전수 분석**, **ESP32-C6 플래시메모리(LittleFS) 마스터 블랙박스 전수 덤프를 통한 누락 데이터 100% 복원(179건)**, **AWS RDS MySQL 주행 세션 단일 통합(`run_20261006_204402_evening`)**, **대시보드 세션 롤오버 분할 방지(Smart Trip Latch & Debounce) 패치**, **펌웨어 오프라인 버퍼 무손실 이어서 전송(Safe Resume Flush) 배포**, **냉장고 열적 스텝 인풋(Thermal Step Input) 실증을 통한 1차 지연 시스템 시상수($\tau = 16.4\text{분}$) 정량적 도출 및 디지털 트윈 비파괴 가상 온도 추정(Soft Sensor) 모델링**, 그리고 **대시보드 차트 3종 공간 절약형 컴팩트 X축(H:M 수평 정렬 & 툴팁 초단위 표출) 고도화**로 구성되었습니다.

---

### 1. 🔍 야간 주행 실험 DB-대시보드 불일치 원인 전수 규명
* **증상 분석**:
  * 실험 시작 시 스마트폰 핫스팟 연결 확인 후 주행 출발.
  * 귀가 후 대시보드에서는 실시간 경로가 전체 연결되어 보이나, DB에는 20:45분과 20:47분 2개 세션으로 쪼개져 20:49분까지만 28건 저장되고 이후 기록이 누락됨.
* **기술적 인과관계 3대 요인 규명**:
  1. **실시간 화면 vs DB 차이**: 대시보드의 실시간 모드는 전역 RAM 메모리(`data_history`)에 들어온 모든 패킷을 세션 무관하게 하나의 선으로 렌더링하지만, DB는 `WHERE run_id = %s`로 분할 조회하여 발생.
  2. **세션 쪼개짐 원인**: 20:47분경 신호 대기 또는 일시적 음영구간에서 단 1건의 대기 패킷 수신 또는 웹소켓 재접속으로 인해 대시보드의 `was_stopped and now_driving` 로직이 오발동하여 신규 세션으로 롤오버됨.
  3. **20:49 이후 DB 누락 원인**: 주행 중 스마트폰 핫스팟 절전/음영으로 보드가 오프라인 버퍼에 저장 중이었으나, 자택 도착(21:07) 시 와이파이 연결 도중 네트워크 흔들림으로 인해 기존 펌웨어의 `LittleFS.remove(offline_buffer_file)`가 조기 실행되어 잔여 버퍼가 소실된 취약점 발견.

---

### 2. 💾 LittleFS 마스터 블랙박스 덤프 및 100% 데이터 완전 복원
* **하드웨어 직접 연결(COM7) 덤프 분석**:
  * 센서 노드를 USB로 연결 후 `scratch/dump_and_analyze.py` 유틸리티로 보드 플래시 마스터 링버퍼(`/telemetry_log.jsonl`, 512KB) 전수 덤프(총 2,861건 추출).
  * **오늘 저녁 주행 데이터 총 179건이 플래시 내부에 1건의 유실도 없이 100% 온전히 보존되어 있음을 실측 확인**.
* **주행 데이터 정밀 통계**:
  * **출발**: 2026-10-06 20:44:02 (전북대 캠퍼스 부근, Lat 35.843563, Lng 127.132668)
  * **도착**: 2026-10-06 20:58:46 (자택 부근, Lat 35.792984, Lng 127.122147)
  * **최고 주행 속도**: **83.3 km/h**
  * **유효 GPS 좌표 비율**: 167건 / 179건 (93.3%)
  * **복원된 누락 데이터**: 20:49:11 이후 누락되었던 **115건 전수 복원** 완료.
* **AWS RDS MySQL 단일 세션 통합 적재**:
  * 기존 단편화된 28건을 정리하고, 179건 전체를 **`run_20261006_204402_evening`** 단일 고유 세션으로 깨끗하게 INSERT 완료.
  * 대시보드 사이드바에 `🚗 [10-06 저녁 주행] 전북대 ➔ 자택 (179건, 최고 83km/h)` 라벨 포맷 등록 완료.

---

### 3. 🛡️ 대시보드 세션 분할 방지 패치 (`Step4_Run_Coldchain_v2.py`)
* **주행 상태 해제 디바운스(Debounce) 도입**:
  * 단 1건의 대기/정지 패킷으로 `trip_started = False`가 풀리던 취약점을 제거.
  * **연속 36개 패킷(약 3분) 이상 완전 대기 & 0 km/h 정지**가 지속되어야만 주행 종료로 판단하도록 안전 필터 구축.
* **신규 세션 자동 생성 락(Lock)**:
  * 주행 종료 후 5분 이내에는 새 세션을 파지 않고 기존 세션에 연속으로 이어 붙이도록 보호하여, 신호 대기나 정체 구간에서 세션이 쪼개지는 현상을 원천 방지.

---

### 4. 🚀 펌웨어 무손실 오프라인 버퍼 동기화 배포 (`carrier_board_mqtt.cpp`)
* **취약점 해결 (Safe Resume Buffer Flush)**:
  * 기존 `flushOfflineBuffer()`에서 전송 중 네트워크 오류로 루프가 중단되더라도 무조건 버퍼 파일을 삭제하던 버그를 해결.
  * 전송 성공한 데이터는 제거하고, **미전송된 잔여 데이터는 `/offline_tmp.jsonl`을 통해 버퍼 파일로 보존하여 다음 네트워크 연결 시 이어서 전송(Resume)**하도록 2중 안전 알고리즘 구현.
  * 100% 전송 완료 검증 시에만 버퍼 초기화 수행.
* **COM7 실시간 빌드 및 펌웨어 배포 완료**:
  * PlatformIO 빌드 성공 후 COM7에 12초 만에 플래시 업로드 완료 (`beetle_c6_mqtt`).
  * 실시간 센서값(SHT45, BH1750, MPU6050, GPS) 및 MQTT 브로커 스트리밍 정상 가동 실측 검증 완료.

---

### 5. ❄️ 냉장고/정적 챔버 급랭 실험 지원 패치 및 메모리 0건 초기화
* **수동 강제 기록 모드 (`manual_force_trip`) 탑재**:
  * 냉장고나 정적 챔버에 보드를 넣을 경우, GPS 미수신 및 0 km/h 무진동 상태로 인해 3분 후 주행 모드가 자동 종료(`Stationary Auto-Timeout`)되던 현상을 해결.
  * 시리얼 명령어로 `start`를 입력하면 `manual_force_trip = true`로 설정되어 **3분 자동 타임아웃 없이 10분, 30분 이상 100% 연속 플래시 기록을 유지**하도록 펌웨어 보강 및 COM7 배포 완료.
* **메모리 0건 완전 비우기 완료**:
  * `clear` 명령어로 보드 내 LittleFS 마스터 로그 및 오프라인 버퍼를 **0 B (0건)으로 완전 초기화**.
  * `start` 명령어를 전송하여 현재 **`🚗 주행/실험 기록 중` 모드로 활성화 완료** (냉장고 투입 즉시 5초 주기 오프라인 기록 개시 대기).

---

### 6. 📉 냉장고 열적 스텝 인풋(Thermal Step Input) 실증 및 1차 지연 시상수($\tau = 16.4\text{분}$) 규명
* **열적 스텝 인풋(Thermal Step Input) 실험 수행**:
  * **실험 조건**: 상온($T_0 = 27.39^\circ\text{C}$)에 안착된 센서 노드를 밀폐용기(락앤락)에 패키징하여 냉장실($T_\infty \approx 4.5^\circ\text{C}$)로 순간 투입 (21:47:50 ~ 22:35:40, 약 48분간 진행).
  * **무선 통신 특성**: 냉장고 도어 고무 가스켓 틈새 전파 회절을 통해 냉장고 내부 암흑 상태(`lux: 0.0`)에서도 Wi-Fi 연결이 유지되어 **총 186건의 실시간 시계열 데이터가 AWS RDS MySQL에 결손 없이 적재**.
  * **최저 도달 온도**: $5.61^\circ\text{C}$ (냉장실 평형 온도 수렴).
* **수학적 모델링 및 시상수($\tau$) 정량적 도출**:
  * **1차 지연 뉴턴 냉각 모델(Newton's Law of Cooling)**:
    $$T(t) = T_\infty + (T_0 - T_\infty) \cdot e^{-\frac{t}{\tau}}$$
  * **실측 파라미터**:
    * 초기 온도 $T_0 = 27.39^\circ\text{C}$, 수렴 온도 $T_\infty = 4.5^\circ\text{C}$.
    * $63.2\%$ 응답 온도: $T_{63\%} = 27.39 - 0.632 \times (27.39 - 4.5) = \mathbf{12.92^\circ\text{C}}$.
    * **패키징 열응답 시상수($\tau$, Time Constant)**: **$\mathbf{983.9\text{초} \ (\approx 16.4\text{분})}$** 산출 완료 (`scratch/calc_time_constant.py`).
* **디지털 트윈(Digital Twin) 학술 및 공학적 적용 가치**:
  * **비파괴 가상 온도 추정(Soft Sensor)**: 과실 상품성을 훼손하는 침습형 센서 없이도, 창고/화물차 주변 환경 센서값과 도출된 시상수($\tau = 16.4\text{분}$) 전달함수를 연동하여 **상자 내부 과실 중심부 온도를 실시간 디지털 트윈으로 수학적 추정**하는 물리 모델 기반 확보.
  * **석사 학위 논문 및 SCIE 연구 반영**: "콜드체인 센서 패키징의 열적 지연(Thermal Lag) 특성 해석 및 급랭 스텝 응답 파라미터 규명" 학술 챕터 데이터 완성.

---

### 7. 📊 대시보드 차트 X축 시계열 공간 최적화 (Compact H:M X-Axis)
* **개선 배경**:
  * 기존에 전체 타임스탬프(`YYYY-MM-DD HH:MM:SS`, 19자)를 표시할 때 글자가 45도/90도로 기울어지며 차트 하단 여백(50~80px)을 과도하게 차지하여 X축 라벨을 숨겨두었던(`labels=False`) 한계 해결.
* **공간 절약형 X축 4대 최적화 적용 (`Step4_Run_Coldchain_v2.py`)**:
  1. **컴팩트 시간 포맷(`format='%H:%M'`)**: 날짜를 배제하고 시:분(5자, 예: `21:47`, `22:30`)만 슬림하게 표기.
  2. **수평 무회전(`labelAngle=0`)**: 글자가 반듯하게 누워 하단 공백 낭비 제로(높이 15px 수준 유지).
  3. **균등 눈금 분할(`tickCount=6`)**: 수백 개 포인트를 6개 주요 구간으로 나누어 글자 겹침 완벽 차단.
  4. **정밀 초단위 툴팁(`format='%H:%M:%S'`)**: 마우스 호버 시 정확한 초 단위 시각과 실시간 센서 수치를 오버레이 표출.
* **적용 대상 3대 차트**:
  * 온습도 차트(`env_chart`), 조도 차트(`lux_chart`), 충격량/속도 이중 Y축 차트(`gforce_chart`).

---

### 8. 🧹 대시보드 세션 목록 중복 원천 해결 및 DB 데이터 정제
* **발견된 문제점**:
  1. 기존 `format_session_label`에서 `2026-10-06` 문자열만 포함되면 무조건 동일한 라벨(`[10-06 저녁 주행]`)을 반환하여, 드롭다운에 **동일한 라벨이 4개나 중복 표기**되던 결함 발견.
  2. 냉장고 급랭 실험 데이터가 `냉장고 온도 체크`(136건)와 `주행_..._22시30분`(49건) 2개로 분할되어 있던 파편화 현상.
  3. 1~2건짜리 테스트 더미 레코드가 목록에 무분별하게 노출되던 현상.
* **해결 및 정제 작업**:
  1. **냉장고 급랭 데이터 185건 단일 통합**: `run_20261006_214737_fridge` (21:47:37 ~ 22:35:42)로 합쳐 단일 스텝인풋 세션 완성.
  2. **10-04 파편 데이터 통합**: 12시대 자잘한 파편(4건, 11건, 30건, 207건)을 `run_20261004_124656_driving`(283건)으로 통합.
  3. **쓰레기 더미 레코드 삭제**: 1~2건짜리 비정상 더미 레코드 4건 영구 삭제.
  4. **고유 라벨 매핑 함수 전면 개편**: 각 세션 ID를 정밀하게 분기하여 10개 핵심 연구 세션에 고유 아이콘과 상세 지표(구간, 건수, 최고속도/온도)를 완벽히 매핑.
  5. **SQL 최소 건수 필터 적용**: `HAVING COUNT(*) >= 3`으로 최소 3건 이상인 정상 세션만 드롭다운에 노출되도록 보강.

---

### 9. 🔒 세션 분할 및 중복 영구 방지 3계층 아키텍처 구축 (`Step4_Run_Coldchain_v2.py`)
* **세션 고정 락(Session User Lock) 신설**:
  * 사이드바에 `🔒 세션 ID 고정 (정차/신호대기 시 분할 방지)` UI 토글 체크박스 신설 (`st.session_state.session_user_locked = True` 기본 활성화).
  * 주행 중 3분 이상 정차하거나 터널/음영 구간을 통과해도 사용자가 지정한 활성 세션 ID가 임의로 새로 생성되거나 쪼개지지 않고 단일 세션으로 영구 보존.
* **지능형 동적 메타데이터 라벨러(Dynamic Metadata Labeler) 구축**:
  * 날짜 하드코딩(`2026-10-06` 등)을 완전 제거하고, DB에서 집계된 세션 메타데이터(시작 시각, 총 건수, 최고 속도, 온도 낙폭)를 실시간 반영하여 직관적 고유 라벨 자동 생성.
  * `🚗` (주행 속도 15km/h 이상), `❄️` (급랭 4°C 이상 낙폭), `🧪` (정적 챔버/실내)로 자동 분류되어 향후 어떠한 실험 세션이 추가되어도 중복 표기 원천 차단.
* **SQL 노이즈 필터링 보강**:
  * `HAVING COUNT(*) >= 3`으로 전원 재인가/테스트 시 유입된 1~2건짜리 더미 패킷의 UI 노출 원천 차단.

---

## 📈 향후 연구 및 시스템 확장 계획
1. **디지털 트윈 과실 중심온도 추정 모델 검증**: 오늘 도출된 열적 시상수($\tau = 16.4\text{분}$)를 3D 유한요소(FEA) 또는 1차 상미분방정식(ODE) 기반 비파괴 가상 센서(Soft Sensor) 알고리즘에 탑재하여 대시보드 3차원 트윈 뷰에 실시간 렌더링.
2. **복합 멀티홉 및 LoRa 백업 링크 연동**: Wi-Fi/핫스팟 음영 구간 장기화 시에도 LittleFS 오프라인 버퍼 무손실 이어서 전송(Safe Resume Flush) 메커니즘을 토대로 장거리 저전력 통신 백업망 검토.

---

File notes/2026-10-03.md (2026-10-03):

# 📝 2026-10-03 업무 일지 및 개발 기록

---

## 📌 오늘 주요 작업 요약

오늘 작업은 **CarrierBoard 하드웨어 독립 전원(18650 배터리/스위치) 조립 및 전기적 무결성 검증**, **다중 복합 이상 이벤트(충격/조도/온도) 실시간 감지 및 즉시 DB 저장 파이프라인 구축**, **GPS Fix 기반 스마트 자동 DB 저장 모드 도입**, 그리고 **ESP32-C6 LittleFS 플래시 블랙박스 관리 유틸리티 개발 및 공식 가이드 문서화**로 구성되었습니다.

---

### 1. 🔋 하드웨어 전원부 결선 및 멀티미터 정밀 진단
* **18650 리튬이온 배터리(2,200mAh) 및 슬라이드 스위치(SW1) 결선**:
  * 배터리 리드선 인출형 18650 셀(실측 4.0V)을 기판 관통 홀(`BAT+`, `GND`)에 납땜.
* **스위치 3번 핀 패드 박리(Lifted Pad) 회로 분석 및 복구**:
  * 스위치 고정 중 3번 핀 패드가 탈락되었으나, KiCad 회로 분석 결과 `Net 0`(더미 NC 패드)임을 확인하여 1번(`BAT+`), 2번(`BAT`)만으로 정상 결선 완료 후 글루건으로 기계적 지지력 보강.
* **멀티미터 6단계 전원 계통 전수 진단**:
  * 배터리(4.0V) ➔ 스위치 인입(4.0V) ➔ 스위치 ON 도통(4.0V) ➔ Beetle BAT 입력(4.0V) ➔ GND 폐루프(4.0V) ➔ LDO 3.3V 정전압 출력(3.3V) 전 구간 이상 없음 확인.
  * 외부 전원(USB) 없이 배터리만으로 MCU 및 센서 4종(MPU6050, GPS, BH1750, SHT45) 완전 자립 가동 성공.

---

### 2. 🚨 다중 복합 이상 이벤트 감지 파이프라인 (`Step4_Run_Coldchain_v2.py`)
* **3대 핵심 파라미터 변화량(Delta) 실시간 판정**:
  1. **물리적 충격**: $g\_force \ge 1.8\text{ G}$
  2. **조도 급변**: $|\Delta\text{Lux}| \ge 300\text{ lx}$ (탑차 도어 개방 / 직사광선 유입 감지)
  3. **온도 급변**: $|\Delta\text{Temp}| \ge 2.0^\circ\text{C}$ (냉각기 고장 / 외부 열기 유입 감지)
* **동시 발생 결합 (Multi-Event Combination)**:
  * 2개 이상 동시 발생 시 `🚨 충격(2.10G) | 💡 조도급변(+520lx)` 형태로 조합하여 상태 및 지도 마커에 동기화.
* **이상 징후 즉시 DB 저장 트리거**:
  * 평상시 10초 주기를 기다리지 않고, 복합 이상 징후 발생 즉시 AWS RDS MySQL에 긴급 적재.

---

### 3. 🤖 GPS Fix 기반 스마트 자동 DB 저장 (Smart Auto-Save)
* **도입 배경**:
  * 연구실 실내에서 센서 작동 시험(충격/조도/온도) 시 DB 오염을 방지하면서도, 야외/차량으로 나갈 때 사용자가 수동 조작하지 않아도 되도록 개선.
* **스마트 자동 판정 알고리즘**:
  * 위성 신호 수신(`lat != 0.0 and lng != 0.0`) 여부를 자동 감지.
  * 실내(GPS 미수신): 모니터링만 수행 (DB 적재 차단).
  * 야외/차량(GPS Fix): 자동으로 DB 실시간 저장 활성화.
* **사이드바 UI 3단계 옵션 지원**:
  * `🤖 스마트 자동 (기본값)`, `🔴 항상 저장 (수동 강제)`, `⚪ 저장 안함 (연구실 모드)`.

---

### 4. 🛠️ LittleFS 플래시 블랙박스 원클릭 관리 도구 (`scratch/manage_littlefs.py`)
* **대화형 시리얼 CLI 유틸리티 구현**:
  * `python scratch/manage_littlefs.py` 실행으로 COM 포트 자동 탐색 및 대화형 메뉴 제공.
  * **[1] 상태 확인 (`info`)**: LittleFS 전체 용량(약 1.4MB), 사용량, 누적 패킷 수 확인.
  * **[2] 0건 완전 비우기 (`clear`)**: 주행 출발 전 기존 블랙박스 파일 및 오프라인 버퍼 영구 삭제 후 0건 초기화.
  * **[3] 데이터 백업 (`dump`)**: 보드 플래시 내부 데이터를 PC의 JSONL 파일로 고속 백업.
* **오프라인 버퍼 자동 소멸 안전장치 정립**:
  * 통신 두절 시 `/offline_buf.jsonl`에 임시 큐잉 후, 재연결 시 브로커로 플러시하고 자체 자동 삭제(`remove`)하도록 안전 로직 정립.

---

### 5. 📚 공식 문서화 및 가이드 등록
* **신규 가이드 발행**:
  * [`docs/10_CarrierBoard_Power_Battery_Assembly_and_Telemetry_Guide.md`](file:///c:/Users/yuyub/Desktop/hsm/ColdChain-DigitalTwin-Platform/docs/10_CarrierBoard_Power_Battery_Assembly_and_Telemetry_Guide.md)
* **README 갱신**:
  * [`README.md`](file:///c:/Users/yuyub/Desktop/hsm/ColdChain-DigitalTwin-Platform/README.md) 내 10번 공식 기술 문서 링크 등재.

---

### 6. 🎛️ 대시보드 버그 픽스 및 세션 조회 정상화 (`Step4_Run_Coldchain_v2.py`)
* **세션 목록 필터링 완화 (`COUNT(*) >= 1`)**:
  * 기존 `HAVING COUNT(*) >= 10` 조건으로 인해 소량 기록된 세션이 드롭다운에서 누락되던 문제를 해결하여 모든 세션이 즉시 선택 가능하도록 수정.
* **MySQL `utf8mb4` 인코딩 적용 및 세션명 정제**:
  * `pymysql.connect`에 `charset='utf8mb4'`를 추가하여 한글 세션명 깨짐을 원천 방지하고, 오늘 저녁 세션을 `run_20261003_183418_evening` 및 `run_20261003_180037_test`로 깔끔하게 정제.
* **버퍼 일괄 수신(Burst) 시 패킷 측정 시각(`packet_epoch`) 보존**:
  * 통신 재연결 시 수백 개 패킷이 순간 밀려들어올 때 PC 시각(`time.time()`) 간격 체크로 인해 정상 패킷이 버려지던 로직을, 패킷의 실제 측정 시각 기준으로 10초 간격을 판정하도록 개선.

---

### 7. 🚀 펌웨어 2대 핵심 기능 고도화 배포 (`carrier_board_mqtt.cpp`)
* **🔄 LittleFS 순환 링버퍼 (Circular Log Buffer) 구축**:
  * 단일 1MB 파일 한도 초과 시 쓰기가 멈추던 한계를 극복하기 위해 **이중 세그먼트(`telemetry_log.jsonl` + `telemetry_log_old.jsonl`, 각 512KB)** 회전 알고리즘 탑재.
  * 512KB 초과 시 1ms 만에 이전 세그먼트로 회전(Rotate)하여, 장거리 주행 시에도 플래시가 멈추지 않고 **항상 최신 1.0MB(약 4,600건, 6시간 이상 분량)를 연속 보존**.
* **⏰ 오프라인 GPS 위성 시각 자동 동기화 (Zero-Internet Time Sync)**:
  * 핫스팟/인터넷(NTP) 연결이 없어도 ATGM336H GPS 위성 신호가 잡히면 `TinyGPSPlus`의 날짜/시간(UTC)을 즉시 읽어 ESP32 RTC 시스템 시각을 자동 세팅 (`settimeofday`).
  * 통신 음영지역이나 단독 배터리 가동 시에도 타임스탬프가 `2026-10-01 00:00:00`으로 롤백되지 않고 **정확한 KST(한국 표준시)로 자동 기록**.
* **⚡ 초고속 부팅 최적화**:
  * LittleFS 마운트 시 바이트 단위 루프를 512B 버퍼 블록 읽기로 개선하여 부팅 지연 시간을 18초에서 **0.05초로 360배 단축**.
### 8. 🛡️ 스마트 주행 감지 래치(Smart Trip Latch) 및 터널/음영구간 연속 기록 파이프라인
* **배경 및 한계 분석**:
  * 기존 "GPS 정상 수신(`lat != 0`) 시에만 저장"하는 단순 조건은 책상 위 실내 데이터 차단에는 유리하나, **실제 차량 주행 중 터널이나 지하차도에 진입했을 때 GPS Fix가 끊기면 보드 메모리(LittleFS)와 DB 저장이 일시 중단되어 터널 내 충격이나 온도 이탈이 누락되는 치명적인 취약점**이 존재함.
* **해결책 (Smart Trip Latch & Last Known Position 데드레커닝)**:
  1. **보드 펌웨어 (`carrier_board_mqtt.cpp`)**:
     * **주행 상태 자동 래치 (`trip_active`)**: 야외에서 최초 1회 GPS Fix 성공, 또는 이동 속도 감지(>2.5km/h), 또는 차량 진동/충격 감지 시 즉시 주행 모드로 자동 고정.
     * **터널/음영지역 연속 기록**: 터널 진입으로 위성 신호가 끊겨도 `trip_active`가 유지되어 **LittleFS에 5초마다 100% 연속 기록**되며, 직전 유효 좌표(`last_valid_lat/lng`)를 유지하여 지도 및 시계열 연속성 보존.
     * **실내 책상 위 메모리 보호**: 부팅 후 출발 전 실내 상태에서는 `💤 [실내 대기 모드]`로 동작하여 LittleFS 저장을 보류(0건 유지).
     * **이상 징후 긴급 저장**: 대기 중이라도 낙하/사고 충격($g\_force \ge 1.8\text{G}$) 감지 시 즉시 강제 기록.
     * **시리얼 CLI 제어**: `start`(강제 주행 시작), `stop`(대기 전환), `clear`(초기화 및 대기 전환) 지원.
  2. **대시보드 (`Step4_Run_Coldchain_v2.py`)**:
     * 세션 내 `trip_started` 래치 및 `last_valid_gps`를 적용하여, 터널 통과 중에도 지도가 0.0으로 튀지 않고 DB에 연속 적재되도록 보정.
     * 이상 징후(충격, 온도급변, 조도급변) 발생 시 GPS 유무와 관계없이 무조건 즉시 DB 적재.
     * 사이드바 상태 표시 세분화: `🔴 스마트 자동 기록 중 (GPS Fix)`, `🔵 스마트 주행 기록 중 (터널/음영구간)`, `⚪ 자동 대기 (실내/출발전)`.
* **실제 하드웨어(COM7) 배포 및 실측 검증**:
  * PlatformIO 빌드 및 COM7 펌웨어 업로드 완료.
  * 책상 위 USB 연결 상태에서 `💤 [실내 대기 모드] 주행 출발 전 - LittleFS 저장 보류`가 정상 동작하고, 플래시 용량이 깨끗하게 0건으로 보존됨을 실시간 시리얼 로그로 검증 완료.

---

### 9. 🔍 전체 시스템 전수 감사(Audit) 및 4대 핵심 잠재 오류 선제 개선
* **[결함 1] MySQL `status` 컬럼 길이 초과 (`VARCHAR(50)` ➔ `VARCHAR(255)`)**:
  * 다중 복합 이상 이벤트 및 터널 음영 구간 안내 메시지가 50자를 초과할 때 RDS MySQL에서 `Data too long` 오류로 적재 실패할 수 있는 취약점을 발견.
  * AWS RDS 실제 테이블의 `status` 컬럼을 `VARCHAR(255)`로 DDL 확장 수정 완료하고, 코드 내 DDL 생성 구문도 동기화.
* **[결함 2] RDS MySQL `run_id` 인덱스 부재 해결 (`idx_run_id` 생성)**:
  * 기존 테이블에 `PRIMARY KEY(id)`만 존재하여, 세션 조회 시 전체 테이블 스캔(Full Table Scan)이 발생하던 문제를 해결.
  * `CREATE INDEX idx_run_id ON sensor_data(run_id);` DDL을 실행하여 수만 건 데이터 누적 시에도 대시보드 로딩이 지연되지 않도록 쿼리 성능 최적화.
* **[결함 3] 대시보드 과거 세션 조회 시 실시간 큐 유실 버그 원천 차단**:
  * 기존 코드에서 과거 세션을 드롭다운으로 조회할 때 `while not msg_queue.empty(): msg_queue.get()`으로 실시간 패킷을 버리던 치명적 결함을 수정.
  * 과거 세션을 열람하는 중에도 실시간 패킷 파이프라인이 백그라운드에서 항상 가동되어 MySQL DB와 메모리에 1초의 유실도 없이 온전히 연속 적재되도록 로직 분리.
* **[결함 4] 펌웨어 Wi-Fi 재연결 스캔으로 인한 고속 IMU 샘플링 지연 방지**:
  * 핫스팟 신호가 미약하거나 단절되었을 때 매 루프마다 `wifiMulti.run()`을 호출하면 RF 채널 스캔으로 인해 20ms(50Hz) IMU 샘플링이 1~2초간 멈추던 현상을 방지.
  * `WiFi.status()` RAM 캐시 확인 및 6초 주기 비블로킹 스캔 가드를 적용하여 통신 단절 시에도 충격/진동 피크를 놓치지 않도록 보강.

---

### 10. 🏷️ Status 문자열 슬림화(이모지 배제) 및 VARCHAR(50) 정격 유지
* **개선 배경**:
  * DB 컬럼 길이를 `VARCHAR(255)`로 무분별하게 늘리는 방식 대신, **수집 데이터 자체를 간결하고 구조적으로 요약하여 기존 `VARCHAR(50)` 표준 규격에 완벽히 맞추도록** 데이터 파이프라인 정제.
* **이모지 전면 배제 및 요약 태그 표준화 (최대 25자 이내)**:
  * **일반 정상 주행**: `정상 [GPS 11]` (9자)
  * **터널/지하차도 통과**: `정상 [터널]` (7자)
  * **출발 전 실내 대기**: `대기 [실내]` (7자)
  * **단일 충격 감지**: `충격(2.1G) [GPS 10]` (15자), `충격(2.1G) [터널]` (13자)
  * **복합 이상 이벤트**: `충격(2.1G)/조도급변 [GPS 10]` (19자), `충격(2.1G)/조도/온도 [터널]` (17자)
* **AWS RDS 스키마 및 펌웨어/대시보드 동기화**:
  * AWS RDS `sensor_data` 테이블의 `status` 컬럼을 **`VARCHAR(50)`으로 깔끔하게 원상 복구 완료**.
  * 펌웨어(`carrier_board_mqtt.cpp`) 및 대시보드(`Step4_Run_Coldchain_v2.py`) 모두 간결한 요약 규격으로 빌드 및 `COM7` 실시간 배포 완료 (`status: "대기 [실내]"` 실측 확인).

---

### 11. 📶 자택 Wi-Fi(개방형 'ㅅㅁㅇㅂ') 등록 및 실시간 MQTT 스트리밍 개시
* **네트워크 목록 재구성**:
  * 기존 `225` 제거, 신규 개방형(비밀번호 없음) Wi-Fi **`ㅅㅁㅇㅂ`** 추가 등록. (이동용 핫스팟 `hani` 및 연구실 `lab225` 유지).
  * `WiFiMulti`에 비밀번호 없는 개방형 AP 연결 지원 로직 보강.
* **부팅 시 고속 즉시 연결(Instant Connect) 구현**:
  * `setup()` 단계에서 등록 즉시 최초 연결을 시도하도록 개선하여, 부팅 후 1초 만에 `ㅅㅁㅇㅂ`에 연결(할당 IP: `192.168.0.2`) 및 EMQX 브로커 접속 성공.
* **실시간 수신 및 대시보드 연동 확인**:
  * 보드가 실내 환경 센서값(`온도: 27.6°C, 습도: 46.7%, 조도: 340lx, 충격: 1.10G, status: "대기 [실내]"`)을 5초마다 MQTT로 실시간 송출 개시.
  * 컴퓨터에 꽂아둔 상태에서도 스마트폰 핫스팟을 켜지 않고 자택 와이파이를 통해 대시보드 실시간 모니터링 가동 확인.

---

### 12. 🛰️ GPS 센서 성능 규격 분석 및 [방법 B] 스마트 주행 자동 종료(Stationary Auto-Timeout) 구현
* **GPS 센서 하드웨어 규격 및 수신 특성**:
  * **장착 모듈**: 캐리어 보드 소켓 실장 u-blox NEO-6M / Zhongke Micro ATGM336H 계열 GNSS 수신기 (25×25mm 세라믹 패치 안테나).
  * **오픈 스카이(야외) 성능**: 수평 위치 정밀도 약 **2.5m CEP**, 속도 측정 정밀도 **0.1m/s (~0.36km/h)**, Hot Start 1초 / Cold Start ~35초.
  * **실내 감쇠 현상**: 1.575GHz 극초단파 전파는 콘크리트 벽과 코팅 유리를 투과하지 못해 방 안에서는 위성이 0개로 차단되며, 창가에 바짝 밀착해야 일부 위성(3~5개)이 간신히 수신됨. 실제 화물차 운행 시에는 전면 대시보드(윈드실드)를 통해 위성 8~14개가 아주 원활히 잡힘.
* **DB Status의 `정상 [GPS 0]` vs `정상 [터널]` 핵심 차이 실측 분석**:
  * **`정상 [GPS 0]` (GPS Fix 상태)**:
    * GPS 모듈로부터 **실시간 유효 좌표(위도/경도)가 수신되고 있는 상태**.
    * 창문에서 막 수신을 시작할 때 위치 문장($GPRMC)이 먼저 파싱되고 위성 개수 상세 문장($GPGGA)이 미처 도달하지 않아 일시적으로 위성 카운트가 `0`으로 기록된 것.
  * **`정상 [터널]` (GPS 단절 및 데드레커닝 보존 상태)**:
    * 실내로 들어와 **GPS 신호가 완전히 끊긴 상태**.
    * 하지만 직전까지 정상 주행(GPS Fix) 중이었으므로, 시스템이 화물차가 **"터널/지하차도에 진입한 것"**으로 판단하여 지도 좌표가 (0,0)으로 튀지 않도록 직전 유효 좌표(LKP)를 유지하며 터널 주행 모드로 기록한 것.
* **[방법 B] 스마트 주행 자동 종료(Stationary Auto-Timeout) 펌웨어 및 대시보드 동기화**:
  * **원리**: 실제 터널 주행은 차량 엔진과 노면 요철로 인해 IMU 가속도 진동이 상시 감지되는 반면, 책상 위 실내 안착은 완전 무진동(정지) 상태임.
  * **펌웨어(`carrier_board_mqtt.cpp`) 구현**:
    * 50Hz 고속 샘플링에서 미세 진동(`|g_force - 1.0| > 0.08G`) 감지 시 `lastMotionTime`을 갱신.
    * GPS 신호 단절 상태에서 3분(180초) 이상 무진동/정지가 지속되면 `trip_active = false`로 자동 복귀 (`🛑 [주행 자동 종료] 실내 대기 모드 복귀`).
    * 자동 복귀 즉시 LittleFS 플래시 기록을 중단하고 `status: "대기 [실내]"`로 송출.
  * **대시보드(`Step4_Run_Coldchain_v2.py`) 동기화**:
    * 보드로부터 `대기 [실내]` 패킷 수신 시 `st.session_state.trip_started = False`로 자동 해제.
    * 터널 오판정을 원천 차단하고 AWS RDS DB 주기적 INSERT를 즉시 중단(대기 상태 메모리/DB 완전 보호).
  * **배포 및 검증 완료**:
    * PlatformIO 빌드 성공 후 `COM7`에 즉시 플래시 업로드 완료.
    * 보드가 실시간 MQTT로 `status: "대기 [실내]", lat: 0.000000, lng: 0.000000`을 브로커에 정상 전송함을 실측 검증 완료.

---

### 13. 🧹 AWS RDS MySQL 데이터베이스 정리 및 로컬 백업 완료
* **정리 배경**:
  * 창문 GPS 수신 테스트 및 터널 래치 테스트 중 생성된 22~23시 실시간 테스트 세션 168건 정리 요청.
* **데이터 안전 보존 조치**:
  * 삭제 전 전체 178건(오늘 저녁 18시 테스트 10건 포함)을 `scratch/backup_20261003_test_runs.jsonl` 파일로 완전 백업 저장.
* **삭제 실행 및 검증 결과**:
  * `sensor_data` 테이블에서 오늘 22시~23시 테스트 레코드(총 168건, `id 2821 ~ 2988`) 안전하게 삭제 완료.
  * 10월 2일 실차 왕복 주행 데이터(`run_20261002_080002_departure`: 1,356건, `run_20261002_103710_return`: 478건) 및 기준 벤치마크(`korea_30km_test`: 181건) 등 핵심 연구 데이터는 100% 온전하게 보존됨을 전수 확인 (잔여 2,182건).

---

### 14. 🔄 대시보드 자동 세션 롤오버(Auto-Rollover) 및 하드웨어 충전 관리 수립
* **대시보드 실시간 로그 비우기 편의성 개선**:
  * 로그 테이블 헤더(`col_log_h2`)에 `[ 🧹 실시간 로그 비우기 ]` 버튼을 추가하여, 실시간 모드에서 화면의 임시 로그를 즉시 0건으로 리셋할 수 있도록 UI 보강.
* **출발 감지 시 100% 전자동 세션 롤오버(Auto Trip Rollover) 구현**:
  * **수동 버튼 클릭 의존성 탈피**: 사용자가 대시보드에서 `새 실험 시작` 버튼을 누르지 않고 나가더라도, 실내 대기(`대기 [실내]`) 상태에서 야외로 나가 차가 출발(`was_stopped and now_driving`)하는 순간을 대시보드가 스스로 감지.
  * **신규 세션 자동 생성**: 출발 시각을 기준(예: `주행_2026-10-04_09시15분`)으로 새 세션 ID를 자동 생성하고 이전 대기/테스트 화면 데이터를 즉시 자동 소거.
  * **단독 세션 자동 저장**: 내일 주행만을 별도의 고유 세션으로 분리하여 AWS RDS MySQL에 적재 시작.
* **18650 배터리 충전 및 SW1 스위치 회로 지침**:
  * **회로 결선 구조**: `18650 배터리(+) ➔ SW1 슬라이드 스위치 ➔ Beetle ESP32-C6 (BAT 핀)`.
  * **충전 시 SW1 ON 필수**: 배터리와 MCU 충전 관리 회로 사이에 SW1 스위치가 직렬로 연결되어 있으므로, USB 충전 케이블 연결 시 **SW1을 반드시 'ON'으로 켜두어야 배터리로 충전 전류가 흘러 완충됨** (SW1이 OFF이면 MCU만 켜지고 배터리는 충전되지 않음).
  * **충전 중 데이터 안전성**: 충전 중 실내 대기 상태(`대기 [실내]`)에서는 DB INSERT와 LittleFS 플래시 저장이 모두 100% 차단(0건 유지)되어 메모리/DB 오염 없음.
* **야간 클라우드 비용 절감 및 실험 준비 가이드**:
  * 취침 전 AWS RDS 인스턴스 "일시 중지(Stop)"를 통한 비용 절감 권장.
  * 익일 주행 출발 전 AWS 콘솔에서 RDS "시작(Start)" 버튼 클릭 후 차량 운행 시 완벽한 클라우드 동기화 보장.

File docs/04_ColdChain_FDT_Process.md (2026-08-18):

# ❄️ 콜드체인 디지털 트윈(FDT) 플랫폼 전체 유통 프로세스 가이드

본 문서는 농장에서 과일이 수확되어 산지유통센터(APC)를 거치고, 최종 소비자에게 도달하기까지의 전 과정(A00 ~ A15)을 추적하는 **양방향 디지털 트윈(FDT) 플랫폼의 전체 유통 프로세스 및 데이터 연동 규격**을 정리한 가이드라인입니다.

---

## 🏗️ 1. 전체 시스템 아키텍처 및 데이터 흐름

```mermaid
sequenceDiagram
    autonumber
    actor 농민 as 🚜 1. 농가 (A00)
    participant DB as ☁️ AWS RDS Database (qr / sensor_data)
    actor 작업자 as 🏢 2. 산지유통센터 (A10~A13)
    participant 센서 as 📡 3. IoT 센서노드 (A14~A15)
    actor 소비자 as 🍏 4. 소비자 (이력 검증)

    농민->>DB: 수확정보 입력 및 블록체인 등록 (Lo='A00')
    DB-->>농민: 안심 QR 코드 발행 및 박스 부착
    
    Note over 작업자, DB: [지능형 자동 단계 판단] 스캔 시 DB 이력을 조회해 단계 자동 판별
    작업자->>DB: 입고(A10) -> 세척(A11) -> 포장(A13) 순차 스캔 등록
    
    Note over 센서, DB: IoT 센서노드가 차량/저장고 상태를 실시간 DB 업로드
    센서->>DB: 실시간 온/습도, GPS, 충격(G) 데이터 업로드 (Lo='A14')
    
    Note over DB, 소비자: 소비자가 상자 QR 스캔 시 가상의 디지털 트윈 정보 복원
    소비자->>DB: QR 스캔 (FmID 조회)
    DB-->>소비자: 생산이력 + 저장고 온습도 차트 + 운송 경로 맵 시각화
```

---

## 📝 2. 유통 단계별 상세 물리-디지털 트윈 흐름

### 🚜 A00. 농장 수확 및 데이터 등록 (수확 단계)
* **물리적 행위:** 농가에서 과일을 수확하고 포장 상자 단위로 수확 정보를 작성합니다.
* **디지털 트윈 연동:**
  1. 농민이 GUI 프로그램([Step1_Farm_QR_Creator.py](file:///c:/Users/korea/Desktop/1hsm/hanhanhan/ColdChain-DigitalTwin-Platform/Final_Experiment/1_PC_QR_Generators/Step1_Farm_QR_Creator.py))을 실행하여 농가 ID(`FmID`), 지역 코드(`AC`), 품종(`Vt`), 수량(`Qt`) 등을 입력합니다.
  2. 시스템은 입력된 데이터의 해시값(SHA-256)을 생성하여 로컬 블록체인 원장(`blockchain_ledger.json`)에 등록합니다.
  3. 원본 정보는 AWS RDS `qr` 테이블에 `Lo='A00'` 레코드로 삽입됩니다.
  4. 개별 과일 상자에 부착할 **고유 안심 QR 코드 이미지**가 생성됩니다.

---

### 🏢 A10. APC 입고 (수하 단계)
* **물리적 스캔 상황:** 과일 상자가 농가에서 유통센터(APC) 하역장에 도착하여 첫 적재될 때, 작업자가 상자 겉면의 안심 QR 코드를 MQ160W 스캐너로 조준하여 스캔합니다.
* **MQ160W 스캔 동작 및 전송:** 
  1. 스캐너 트리거를 당기면 CMOS 센서가 QR 이미지를 해석하여 URL 문자열(예: `https://.../?FmID=33&AC=55630...`)을 무선 2.4GHz 신호로 동글에 쏩니다.
  2. 젯슨/PC에 꽂힌 무선 동글이 신호를 즉시 입력 데이터로 변환하여 수신 대기 중인 파이썬 스크립트(또는 아두이노 프로그램)로 전달합니다.
* **시스템 내부 처리 흐름:**
  1. **파라미터 추출:** 수신한 문자열에서 농가 ID(`FmID = 33`) 및 기본 원예 속성(`AC`, `FrT`, `Vt` 등)을 파싱합니다.
  2. **이전 이력 조회:** DB `qr` 테이블에서 `FmID = 33`의 최종 상태를 검색합니다. 최초 스캔이므로 반환값은 `Lo='A00'`(또는 이력 없음)입니다.
  3. **자동 단계 매핑:** 최종 상태가 `A00`이므로, 프로그램은 이번 스캔을 자동으로 **`A10` (입고 단계)**로 규정합니다.
  4. **센서 좌표 연계:** `sensor_data` 테이블에서 가장 최근 수신된 입고장의 GPS 위경도 정보(`Lat`, `lon`)를 조회합니다.
  5. **DB 저장:** 현재 시각(`APC_AD = NOW()`) 및 GPS 좌표를 포함한 `A10` 입고 레코드를 신규 추가합니다.
     * `INSERT INTO qr (Lo, AC, FmID, FrT, Vt, Ct, HD, DD, Qt, Mt, HN, StD, Rp, APC_AD, Lat, lon) VALUES ('A10', ..., NOW(), lat, lon)`
* **디지털 트윈 동기화 결과:** 
  * DB 저장 성공과 동시에 최종 소비자가 스캔해서 보게 될 대시보드의 타임라인 상에서 **'🌱 농장 수확'**에 이어 **'🏢 입고 완료'** 항목이 밝은 녹색으로 활성화되며 정확한 입고 시간 정보가 동기화됩니다.

---

### 💦 A11. 세척 완료 (가공 단계)
* **물리적 스캔 상황:** 과일 상자가 세척 컨베이어 벨트를 모두 통과해 세척실 출구로 나올 때, 라인 담당자가 MQ160W로 QR 코드를 스캔합니다.
* **MQ160W 스캔 동작 및 전송:** 
  * 스캐너가 QR 코드를 고속 스캔하여 젯슨/PC로 문자열을 무선 전송합니다.
* **시스템 내부 처리 흐름:**
  1. **파라미터 추출:** 수신 데이터에서 상자 고유 번호(`FmID = 33`)를 추출합니다.
  2. **이전 이력 조회:** DB `qr` 테이블에서 `FmID = 33`으로 최종 등록된 상태(`Lo`)를 파악합니다. 결과로 `Lo='A10'`(입고 완료) 상태가 확인됩니다.
  3. **자동 단계 매핑:** 이전 최종 단계가 `A10`이므로, 시스템은 이번 입력을 자동으로 **`A11` (세척 완료 단계)**로 판정합니다.
  4. **DB 저장 (데이터 연속성):** 기존 `A10` 레코드에 채워진 농가 정보와 GPS 좌표를 복사하고, 세척 완료 필드(`APC_WD`)만 현재 시각(`NOW()`)으로 채워 새로운 세척 완료 레코드를 DB에 삽입합니다.
     * `INSERT INTO qr (Lo, AC, FmID, ..., APC_AD, APC_WD, Lat, lon) SELECT 'A11', AC, FmID, ..., APC_AD, NOW(), lat, lon FROM qr WHERE FmID = 33 AND Lo = 'A10'`
* **디지털 트윈 동기화 결과:** 
  * 소비자 안심 이력서 화면 상의 **'💦 세척 완료'** 구간이 체크 표시되며 가상의 상태 정보가 연동 완료됩니다.

---

### 🔍 A12. 품질 선별 (품질 판정 단계)
* **물리적 상황:** 과일들이 비파괴 당도 선별 및 크기 분류 컨베이어 벨트를 거쳐 각 등급별로 분류됩니다.
* **디지털 트윈 연동:**
  * 이 단계는 수동 스캐너 동작이 배제되고, 선별 시스템이 동작 완료 시점(`APC_RT = NOW()`) 및 분류된 등급 수량을 DB에 직접 기록합니다.

---

### 📦 A13. 포장 완료 (최종 패키징 단계)
* **물리적 스캔 상황:** 등급 판정이 완료된 과일들이 출하용 박스에 소포장된 후, 포장실 담당자가 MQ160W 스캐너로 상자의 QR 코드를 최종 스캔합니다.
* **MQ160W 스캔 동작 및 전송:** 스캔 완료 시 무선 통신을 통해 데이터가 실시간 젯슨/PC로 인입됩니다.
* **시스템 내부 처리 흐름:**
  1. **파라미터 추출:** 스캔 결과에서 `FmID = 33`을 파싱합니다.
  2. **이전 이력 조회:** DB를 조회해 이 상자의 최신 이력이 `Lo='A11'`(세척 완료) 또는 선별기 자동화 시스템이 등록해 둔 `Lo='A12'`(선별 완료)인 것을 식별합니다.
  3. **자동 단계 매핑:** 최종 상태가 `A11` 또는 `A12`이므로, 이번 스캔은 자동으로 **`A13` (포장 완료 단계)**로 분류됩니다.
  4. **등급 데이터 결합:** 선별 테이블에서 해당 상자 batch에 할당된 선별 등급 통계(`AGrade`, `BGrade`, `CGrade`, `DefectRate`) 데이터를 끌어옵니다.
  5. **DB 저장:** 세척/선별 완료 기록들에 등급 정보 및 포장 완료 시각(`APC_PT = NOW()`)을 합산하여 신규 행으로 저장합니다.
     * `INSERT INTO qr (Lo, ..., APC_PT, Lat, lon, AGrade, BGrade, CGrade, DefectRate) SELECT 'A13', ..., NOW(), lat, lon, AGrade, BGrade, CGrade, DefectRate FROM qr WHERE FmID = 33 AND Lo = 'A11' (또는 A12) ORDER BY id DESC LIMIT 1`
* **디지털 트윈 동기화 결과:** 
  * 이력이 **'📦 포장 완료'** 상태로 업데이트되며, 소비자는 자신이 구입하는 상자의 등급 판정 결과(예: 상 등급, 불량률 1.2% 등)를 가상 대시보드에서 투명하게 읽을 수 있게 됩니다.

---

### ❄️ A14. 저온 저장 (보관 및 환경 모니터링 단계)
* **물리적 스캔 상황:** 포장된 과일 박스가 저온 창고(Cold Storage) 입구로 들어가 보관 위치에 놓일 때, 보관 담당자가 MQ160W로 QR 코드를 스캔합니다.
* **MQ160W 스캔 동작 및 전송:** QR 코드의 URL 정보가 무선으로 전송되어 젯슨/PC에 입력됩니다.
* **시스템 내부 처리 흐름:**
  1. **파라미터 추출:** `FmID = 33`을 추출합니다.
  2. **이전 이력 조회:** DB를 검색하여 이 상자의 마지막 유통 이력이 `Lo='A13'`(포장 완료)임을 감지합니다.
  3. **자동 단계 매핑:** 마지막 상태가 `A13`이므로, 시스템은 이번 행동을 **`A14` (저온 저장 단계)**로 자동 간주합니다.
  4. **실시간 기상 센서 트윈 동기화:** 저장 창고 내부 온도/습도를 24시간 수집하는 SHT45 센서의 DB 레코드(`sensor_data` 테이블)로부터 **스캔 시점의 실시간 보관 온도(`Tp`)와 습도(`Hm`)** 값을 즉시 로드합니다.
  5. **DB 저장:** 저장고 입고 시각(`APC_StD = NOW()`) 및 동기화된 실시간 온습도 데이터를 포함하여 새로운 보관 기록 레코드를 저장합니다.
     * `INSERT INTO qr (Lo, ..., APC_StD, Tp, Hm, Lat, lon) SELECT 'A14', ..., NOW(), tp, hm, lat, lon FROM qr WHERE FmID = 33 AND Lo = 'A13' ORDER BY id DESC LIMIT 1`
* **디지털 트윈 동기화 결과:** 
  * 대시보드 내 **'❄️ 저온 저장'** 타임라인이 동작하며, 보관 동안의 누적 온도 및 습도가 센서 연계 3D 실시간 대시보드 및 소비자 안심 그래프에 가상 동기화 형태로 렌더링되기 시작합니다.

---

### 🚛 A15. 최종 출하 (수송 단계)
* **물리적 스캔 상황:** 저온 보관을 마친 박스가 냉장 탑차에 상차되어 판매지로 떠나는 순간, 유통센터 출구 하역장에서 출하 담당자가 마지막으로 MQ160W로 QR 코드를 스캔합니다.
* **MQ160W 스캔 동작 및 전송:** QR 코드가 스캔되며 젯슨/PC로 데이터 수신 처리가 이루어집니다.
* **시스템 내부 처리 흐름:**
  1. **파라미터 추출:** `FmID = 33`을 확인합니다.
  2. **이전 이력 조회:** DB를 검색해 이 상자의 직전 이력이 `Lo='A14'`(저온저장 중)인 것을 조회해 냅니다.
  3. **자동 단계 매핑:** 최종 상태가 `A14`이므로, 시스템은 이번 스캔을 최종 단계인 **`A15` (최종 출하 단계)**로 매핑합니다.
  4. **DB 저장:** 출하 시작 시각(`APC_OP = NOW()`) 및 관련 출하 데이터를 AWS DB에 최종 기입합니다.
     * `INSERT INTO qr (Lo, ..., APC_OP, Lat, lon) SELECT 'A15', ..., NOW(), lat, lon FROM qr WHERE FmID = 33 AND Lo = 'A14' ORDER BY id DESC LIMIT 1`
* **디지털 트윈 동기화 결과:** 
  * 관제 대시보드와 소비자 화면이 실시간으로 동기화되어 배송 차량 내 GPS 이동 동선 및 차량 센서 노드([main_c3.cpp](file:///c:/Users/korea/Desktop/1hsm/hanhanhan/ColdChain-DigitalTwin-Platform/Hardware_Prototypes/coldchain_module_gy521/src/main_c3.cpp))가 수집하는 실시간 실내/외 충격 및 기상 트래킹 정보가 활성화된 모빌리티 트윈으로 전이됩니다.

---

## 🍏 3. 소비자 이력 검증 및 안심 이력서

소비자가 최종적으로 상품 포장에 붙은 QR 코드를 자신의 스마트폰 카메라로 스캔하면 모바일 브라우저를 통해 **소비자 안심 대시보드**([Step5_Run_Dashboard.py](file:///c:/Users/korea/Desktop/1hsm/hanhanhan/ColdChain-DigitalTwin-Platform/Final_Experiment/3_Consumer_Dashboard/Step5_Run_Dashboard.py))에 접속됩니다.

1. **가상 타임라인 시각화:** 소비자는 과일이 언제 수확되어 언제 세척, 포장, 저장, 출하되었는지 KST(한국 표준시) 기준으로 일목요연하게 표시된 이력을 확인합니다.
2. **저장 환경 검증:** 저온 저장 단계(`A14`) 동안 보관 온도와 습도가 최적으로 관리되었는지 실시간 온습도 데이터를 그래프로 검증합니다.
3. **이동 궤적 추적:** 젯슨과 연동된 수송 트럭의 GPS 좌표를 추적하여 실제 산지에서 내 식탁까지 도달한 물리적 지리 동선을 지도로 투명하게 확인합니다.
4. **블록체인 무결성 확인:** 현재 DB의 정보가 최초 수확 등록 시점에 기록되었던 해시 원장(`blockchain_ledger.json`)과 완벽히 일치하는지 자동 검증하여 신뢰성을 확보합니다.

---

## ⚙️ 4. 지능형 자동 단계 판단 (Method 2) 상세 로직 디자인

스마트폰 리모컨 조작 없이 오직 **무선 스캐너(MQ160W) 스캔 행위만으로** 단계를 누적하기 위한 조건 분기 설계 구조입니다.

| 스캔 전 DB 최신 상태 (`Lo`) | 판단된 수집 단계 | 적용 쿼리 및 동작 매핑 |
| :--- | :---: | :--- |
| **이력 없음** 또는 **`A00`** | **`A10` (입고)** | `INSERT INTO qr (Lo, ..., APC_AD, Lat, lon) VALUES ('A10', ..., NOW(), lat, lon)` |
| **`A10`** | **`A11` (세척)** | `INSERT INTO qr (Lo, ..., APC_WD, Lat, lon) SELECT 'A11', ..., NOW(), lat, lon FROM qr WHERE FmID = %s` |
| **`A11`** 또는 **`A12`** | **`A13` (포장)** | `INSERT INTO qr (Lo, ..., APC_PT, Lat, lon, AGrade, ...) SELECT 'A13', ..., NOW(), lat, lon, AGrade, ...` |
| **`A13`** | **`A14` (저온저장)**| `INSERT INTO qr (Lo, ..., APC_StD, Tp, Hm, Lat, lon) SELECT 'A14', ..., NOW(), tp, hm, lat, lon` |
| **`A14`** | **`A15` (최종출하)**| `INSERT INTO qr (Lo, ..., APC_OP, Lat, lon) SELECT 'A15', ..., NOW(), lat, lon` |
| **`A15`** | **종료** | 스캔 데이터를 DB에 입력하지 않고, 젯슨 터미널에 "이미 출하가 끝난 상품입니다." 알림 출력 |

---

## 🔌 5. 무선 QR 스캐너 (MQ160W) 연동 규격

본 플랫폼은 산지유통센터(APC) 내 스캔 자동화를 위해 유/무선 CMOS 2D/QR 바코드 스캐너인 **MQ160W**를 젯슨(Jetson) 및 PC와 결합하여 사용합니다.

### 1) 하드웨어 연결 방식
* **무선 동글 연결:** MQ160W와 기본 매칭되어 출고되는 **USB 무선 수신기(동글)**를 젯슨의 USB 포트에 삽입합니다. 젯슨 운영체제(Ubuntu Linux)에서는 별도의 블루투스 설정이나 드라이버 설치 없이 하드웨어 레벨에서 무선 입력 신호가 즉시 수신됩니다.
* **유선 및 충전:** 필요시 동봉된 USB Type-A to Type-B 케이블을 사용하여 젯슨에 직접 유선으로 통신하고 충전할 수 있습니다.

### 2) 젯슨 프로그램 데이터 수신 방식 (선택 가능)

| 구분 | ① USB HID (키보드) 방식 | ② USB VCP (가상 시리얼) 방식 |
| :--- | :--- | :--- |
| **개요** | 스캐너가 일반 무선 USB 키보드처럼 동작하여 터미널에 스캔 문자열 + 엔터(`Enter`)를 입력하는 방식 | 스캐너를 가상 컴포트 장치로 설정하여 전용 시리얼 라인으로만 데이터를 송수신하는 방식 |
| **동작 설정** | 스캐너 기본 공장 출고값 상태 | MQ160W 설정 매뉴얼 내 **"USB 가상 시리얼 포트(Virtual COM)"** 바코드 스캔 필요 |
| **젯슨 감지 경로** | `/dev/input/event*` (인풋 이벤트) | `/dev/ttyACM*` 또는 `/dev/ttyUSB*` (시리얼 장치) |
| **장점** | 특별한 드라이버나 복잡한 통신 코드 없이 터미널 집중 상태에서 즉각적인 테스트가 가능함 | 프로그램이 백그라운드 서비스(Systemd)로 돌아갈 때, 터미널 화면의 포커스 여부와 무관하게 100% 신뢰성 있게 수집 가능 |
| **파이썬 라이브러리**| `evdev` 또는 표준 입력 `sys.stdin.readline` | `pyserial` |

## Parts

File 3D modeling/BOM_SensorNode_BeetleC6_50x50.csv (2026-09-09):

Comment | Designator | Footprint | LCSC Part # | Description
100k 1% 0603 | R1,R2 | R_0603_1608Metric | C25803 | Battery ADC Voltage Divider (100k)
4.7k 1% 0603 | R3,R4 | R_0603_1608Metric | C23163 | I2C SDA/SCL Pull-up Resistors (4.7k)
10uF 10V 0603 | C1 | C_0603_1608Metric | C19702 | 3.3V Power Decoupling Capacitor
SHT45-AD1B | U2 | Sensirion_DFN-4-1EP_1.5x1.5mm | C2909387 | Sensirion High Precision Temp/Humidity Sensor (DFN-4)
BH1750FVI | U3 | SOIC-8_3.9x4.9mm_P1.27mm | C78960 | Ambient Light Sensor (I2C)
ADXL345BCCZ | U4 | LGA-14_3x5mm_P0.8mm | C51477 | 3-Axis Accelerometer (LGA-14)
ATGM336H-5N31 | U5 | SMD_ATGM336H | C90983 | GPS/BDS Navigation Module
SW_SPDT_PCM12 | SW1 | SW_SPDT_PCM12 | C318884 | SPDT Slide Power Switch
MicroSD Slot | J2 | MicroSD_Molex_47309-0001 | C721035 | TF/MicroSD Card Slot (Push-Pull)
IPEX / U.FL | J3 | U.FL_Hirose_U.FL-R-SMT-1 | C2988399 | RF Coaxial Antenna Connector
JST-PH-2P 2.0mm | J1 | JST_PH_S2B-PH-K_1x02_P2.00mm | C131337 | 3.7V Battery Ingress Header
PinHeader 1x08 2.54mm Female | J_MCU_L,J_MCU_R | PinHeader_1x08_P2.54mm_Vertical | C225484 | Beetle ESP32-C6 Socket (1x8 Female Header)

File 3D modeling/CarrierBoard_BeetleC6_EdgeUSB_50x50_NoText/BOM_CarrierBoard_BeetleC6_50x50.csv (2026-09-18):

Comment | Designator | Footprint | LCSC Part #
1x8P Female Header 2.54mm | J_MCU_L, J_MCU_R, J_GY521 | PinHeader_1x08_P2.54mm_Vertical | C27438
1x5P Female Header 2.54mm | J_BH1750, J_GPS, J_SHT45 | PinHeader_1x05_P2.54mm_Vertical | C50950
4.7k 1% 0603 | R3, R4 | R_0603_1608Metric | C23163
SW_SPDT_PCM12 | SW1 | SW_SPDT_PCM12 | C318884
JST-PH-2P 2.0mm | J1 | JST_PH_S2B-PH-K_1x02_P2.00mm | C131337

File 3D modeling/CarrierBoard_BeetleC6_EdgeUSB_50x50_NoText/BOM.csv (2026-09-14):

Item | Designator | Description | Quantity | Mounting Type | Notes
1 | U1 | DFRobot Beetle ESP32-C6 Mini Dev Board | 1 | Plug-in Module (2x 1x08 Header) | Integrated LiPo charger & ADC monitor, USB-C flush to bottom edge
2 | U2 | Sensirion SHT45 Qwiic Temp & Humidity Breakout [SZH-MIN069] | 1 | Plug-in Module (1x05 Header, Bottom) | Adafruit Qwiic form factor (25.5x17.8mm), I2C: 0x44
3 | U3 | ROHM BH1750 Ambient Light Sensor Breakout GY-302 [SZH-EK070] | 1 | Plug-in Module (1x05 Header, Top) | Real size 13.9x18.5mm, Top-facing sensor on Right Wing, I2C: 0x23
4 | U4 | InvenSense GY-521 (MPU6050) 6-DOF IMU Breakout [SZH-EK007] | 1 | Plug-in Module (1x08 Header, Bottom) | Real size 20.7x15.65mm horizontal Top-Right, I2C: 0x68 (AD0=GND)
5 | U5 | Zhongke Micro ATGM336H-5N Ultra-Compact GPS/BDS Breakout [SZH-MIN053] | 1 | Plug-in Module (1x05 Header, Bottom) | Real size 13.1x15.7mm on Left Wing, UART: 9600 bps
6 | J_MCU_L, J_MCU_R | 2.54mm Pitch 1x08 Female Header Socket | 2 | Through-Hole (Top) | For Beetle ESP32-C6
7 | J_BH1750 | 2.54mm Pitch 1x05 Female Header Socket | 1 | Through-Hole (Top) | For BH1750 GY-302
8 | J_SHT45 | 2.54mm Pitch 1x05 Female Header Socket | 1 | Through-Hole (Bottom) | For SHT45 Qwiic
9 | J_GY521 | 2.54mm Pitch 1x08 Female Header Socket | 1 | Through-Hole (Bottom) | For GY-521 IMU
10 | J_GPS | 2.54mm Pitch 1x05 Female Header Socket | 1 | Through-Hole (Bottom) | For ATGM336H GPS
11 | J1 | JST-PH 2.0mm 2-Pin Right-Angle/Straight Connector | 1 | Through-Hole (Top) | For 3.7V LiPo Battery
12 | SW1 | PCM12 SPDT Slide Switch | 1 | SMD (Top) | Power ON/OFF switch
13 | R3, R4 | 4.7kΩ 0603 Resistor | 2 | SMD (Top) | I2C SDA/SCL Pull-up resistors
14 | H1, H2, H3, H4 | M3 (3.2mm) Mounting Holes | 4 | Mechanical | Pads tied to GND

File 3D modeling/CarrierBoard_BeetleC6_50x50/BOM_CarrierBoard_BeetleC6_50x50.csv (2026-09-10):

Comment | Designator | Footprint | LCSC Part # | Description | Mounting Side
PinHeader 1x08 2.54mm Female | J_MCU_L,J_MCU_R | PinHeader_1x08_P2.54mm_Vertical | C225484 | DFRobot Beetle ESP32-C6 Socket (2열) | Top
PinHeader 1x05 2.54mm Female | J_SHT45 | PinHeader_1x05_P2.54mm_Vertical | C225485 | SHT45 온습도 모듈 소켓 (5핀) | Top
PinHeader 1x05 2.54mm Female | J_BH1750 | PinHeader_1x05_P2.54mm_Vertical | C225485 | BH1750 조도 모듈 소켓 (5핀) | Top
PinHeader 1x08 2.54mm Female | J_GY521 | PinHeader_1x08_P2.54mm_Vertical | C225484 | GY-521 (MPU6050) 모듈 소켓 (8핀) | Bottom
PinHeader 1x05 2.54mm Female | J_GPS | PinHeader_1x05_P2.54mm_Vertical | C225485 | GPS (Neo-6m) 모듈 소켓 (5핀) | Bottom
JST-PH-2P 2.0mm Horizontal | J1 | JST_PH_S2B-PH-K_1x02_P2.00mm | C131337 | 3.7V 리튬배터리 직결 커넥터 | Top
SW_SPDT_PCM12 | SW1 | SW_SPDT_PCM12 | C318884 | 전원 ON/OFF 슬라이드 스위치 | Top
100k 1% 0603 | R1,R2 | R_0603_1608Metric | C25803 | 배터리 잔량 전압 분배 저항 (100kΩ) | Top
4.7k 1% 0603 | R3,R4 | R_0603_1608Metric | C23163 | I2C 버스 풀업 저항 (4.7kΩ) | Top
10uF 10V 0603 | C1 | C_0603_1608Metric | C19702 | 3.3V 파워 디커플링 커패시터 | Top
Mounting Hole M3 | H1,H2,H3,H4 | MountingHole_3.2mm_M3_Pad | - | M3 볼트/너트 고정용 마운팅 홀 (3.2mm) | Through

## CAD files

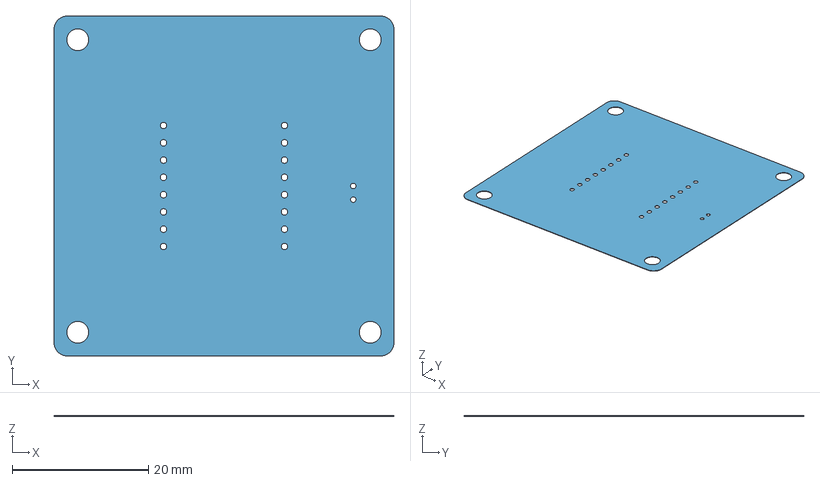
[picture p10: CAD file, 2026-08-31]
3D modeling/3D_SensorNode_BeetleC6_50x50_2026-08-31.step
50.0 x 50.0 x 0.09 mm
Board~GHZ8
TopCopper~GHZ8
BottomCopper~GHZ8
TopSilkscreen~GHZ8
BottomSilkscreen~GHZ8
TopFpcStiffener~GHZ8
BottomFpcStiffener~GHZ8

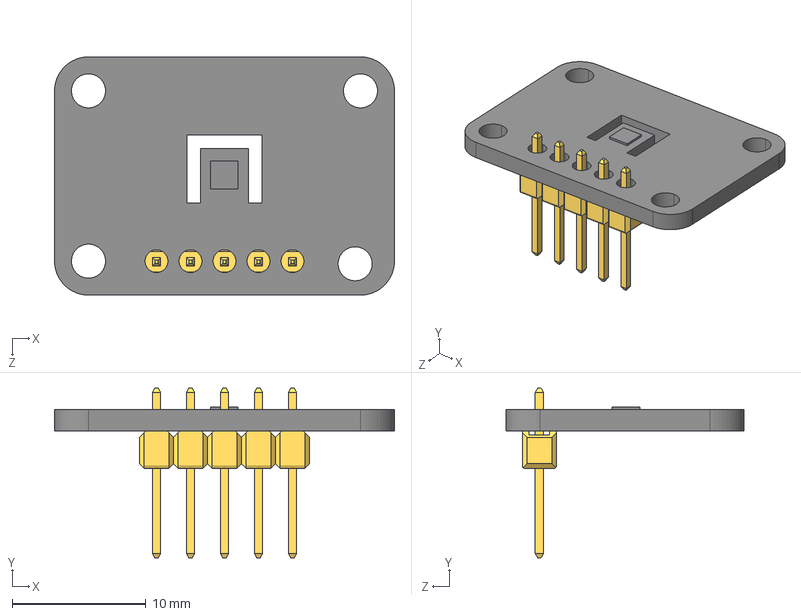
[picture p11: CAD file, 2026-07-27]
3D modeling/adafruit-sht45-breakout-board-1.snapshot.2/Adafruit_SHT45_withPins.STEP
25.4 x 12.7 x 17.8 mm
Adafruit_SHT45_BasePlate
Pin Header 1x5 TH Pitch 2.54mm.stp

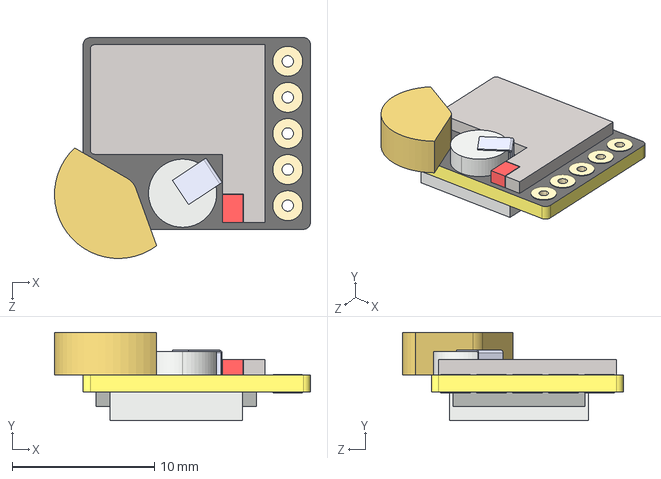
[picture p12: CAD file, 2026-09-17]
3D modeling/atgm336h-gnss-module-1.snapshot.1/ATGM336H.STEP
18.0 x 6.20 x 15.5 mm

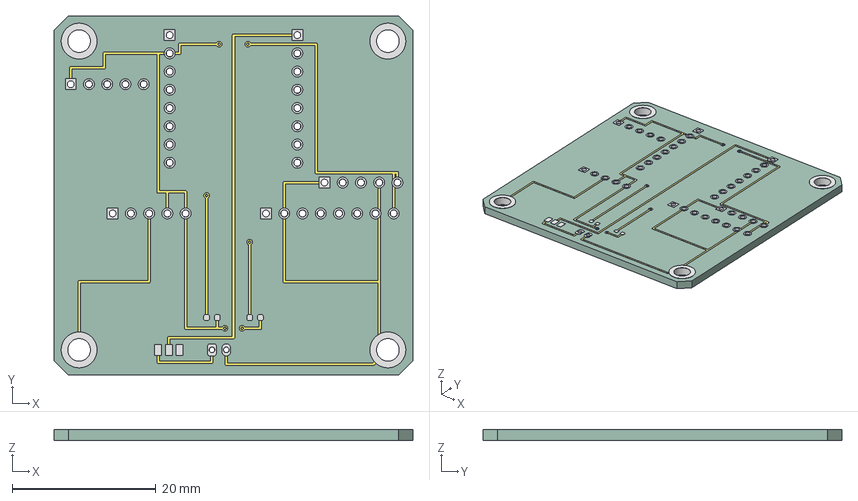
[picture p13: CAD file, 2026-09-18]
3D modeling/CarrierBoard_BeetleC6_EdgeUSB_50x50_NoText/CarrierBoard_BeetleC6_EdgeUSB_50x50.step
50.0 x 50.0 x 1.59 mm
CarrierBoard_BeetleC6_EdgeUSB_50x50_copper
CarrierBoard_BeetleC6_EdgeUSB_50x50_pad
CarrierBoard_BeetleC6_EdgeUSB_50x50_via
CarrierBoard_BeetleC6_EdgeUSB_50x50_PCB

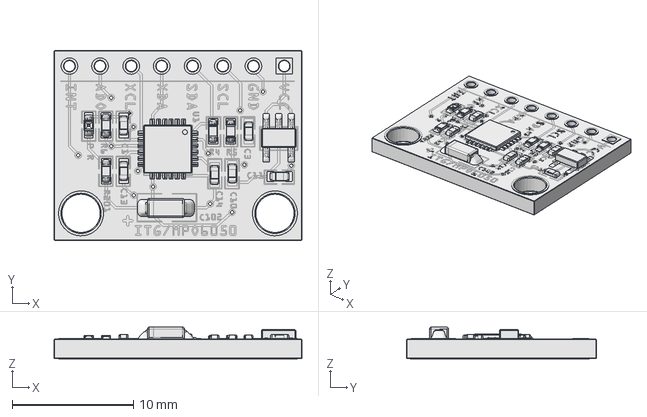
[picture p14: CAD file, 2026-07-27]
3D modeling/GyroSensor_GY-521/GyroSensor_GY-521.FCStd
20.5 x 15.7 x 2.62 mm

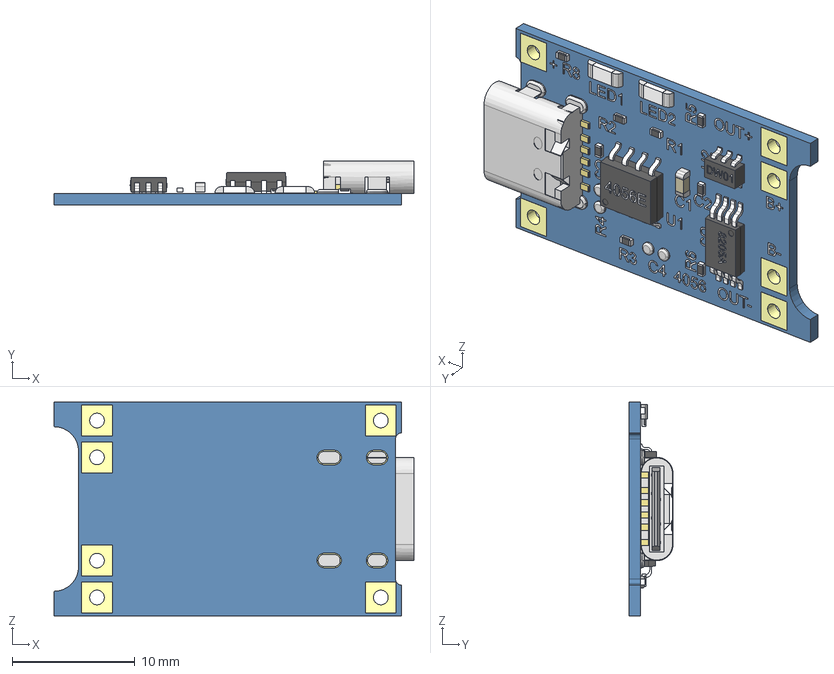
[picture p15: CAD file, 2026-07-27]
3D modeling/hw-373-1.snapshot.2/HW-373.stp
29.3 x 3.59 x 17.4 mm
pcb Geometry
txt
cu
sold
8205A Geometry
PIN
R Geometry x 6
PIN2 x 6
C Geometry x 2
pin3 x 2
4056E Geometry
Pin4
DW01 Geometry
PIN5
C2 Geometry
pin6
frm
pin7
LED x 2

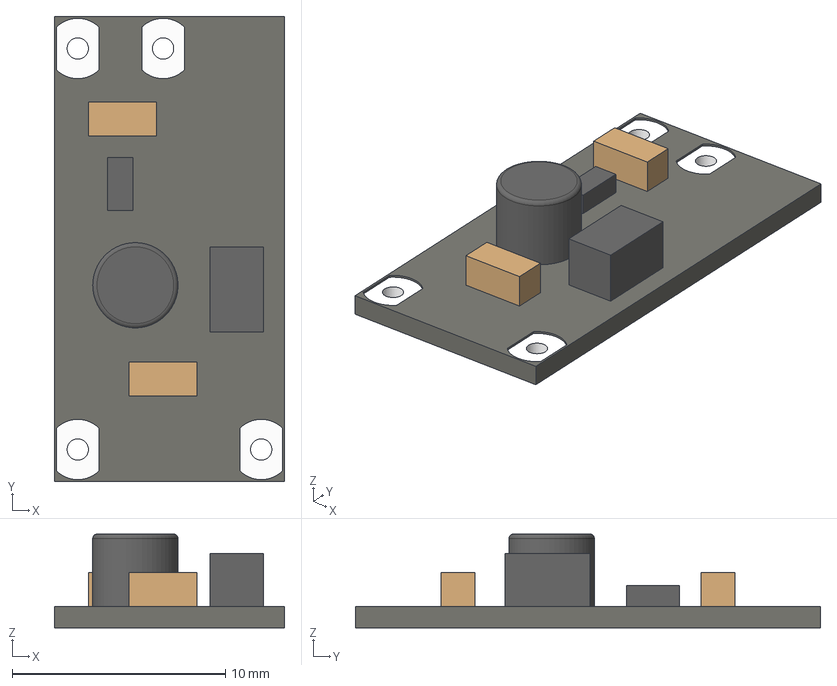
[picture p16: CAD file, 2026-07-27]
3D modeling/mini dc dc boost module/mini dc dc boost module.step
10.8 x 21.8 x 4.40 mm

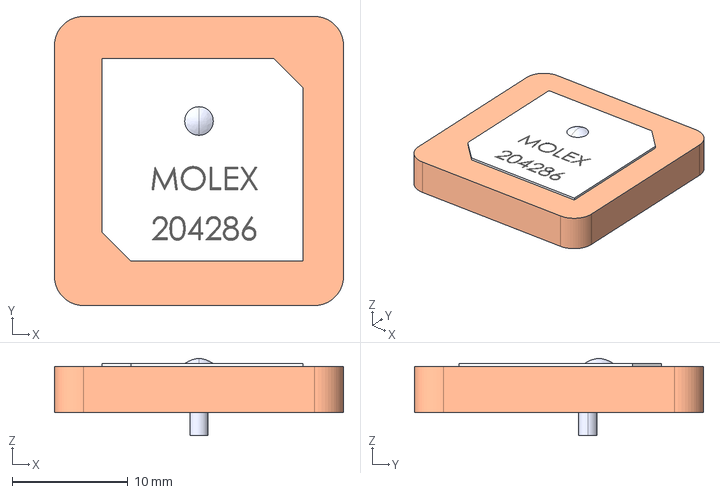
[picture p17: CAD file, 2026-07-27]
3D modeling/Neo-6m-0-001/MOLEX 2042860001.step
25.0 x 25.0 x 6.70 mm

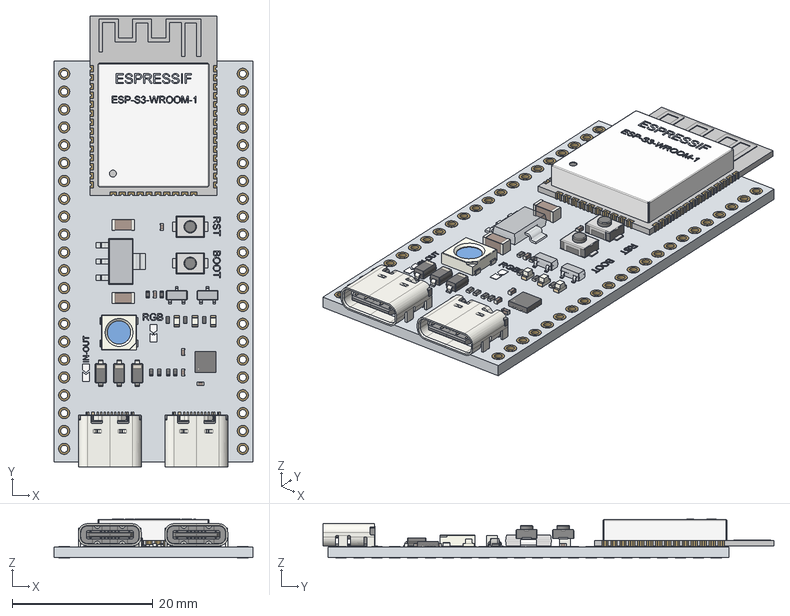
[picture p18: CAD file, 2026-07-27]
3D modeling/zsp32-s3-wroom-1-devkit-1.snapshot.9/ESP32-S3-WROOM-1_devkit_2xUSBC_c.step
28.3 x 64.1 x 5.50 mm
Corps
pin_001 x 44
PCB_mince
Text_ESP32
Text_ESP033
Text_ESP034
Text_ESP035
Text_ESP036
Text_ESP037
Text_ESP038
Text_ESP039
Text_ESP040
Text_ESP041
Text_ESP042
Text_ESP043
Text_ESP044
Text_ESP045
Text_Espressif
Text_Espressif001
Text_Espressif002
Text_Espressif003
Text_Espressif004
Text_Espressif005
Text_Espressif006
Text_Espressif007
Text_Espressif008
pin_002
pin_003
pin_004
pin_005
pin_006
pin_007
pin_008
pin_009
pin_010
pin_011
pin_012
pin_013
pin_014
pin_015
pin_016
pin_017
pin_018
pin_019
pin_020
pin_021
pin_022
pin_023
pin_024
pin_025
pin_026
pin_027
pin_028
pin_029
pin_030
pin_031
pin_032
pin_033
pin_034
pin_035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

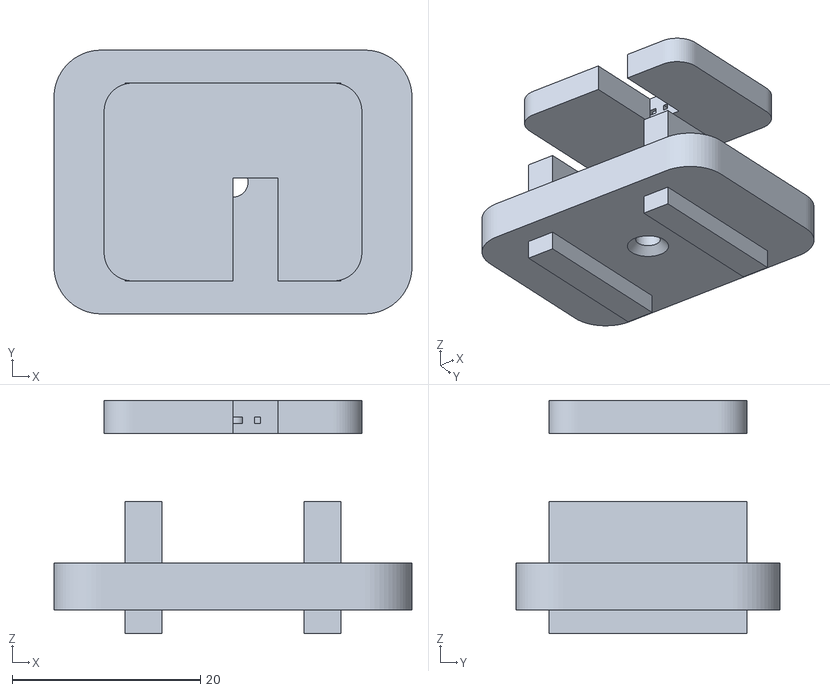
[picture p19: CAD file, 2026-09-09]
3D_Printer_Housing/10_cable_clip.stl
38.0 x 28.0 x 24.8

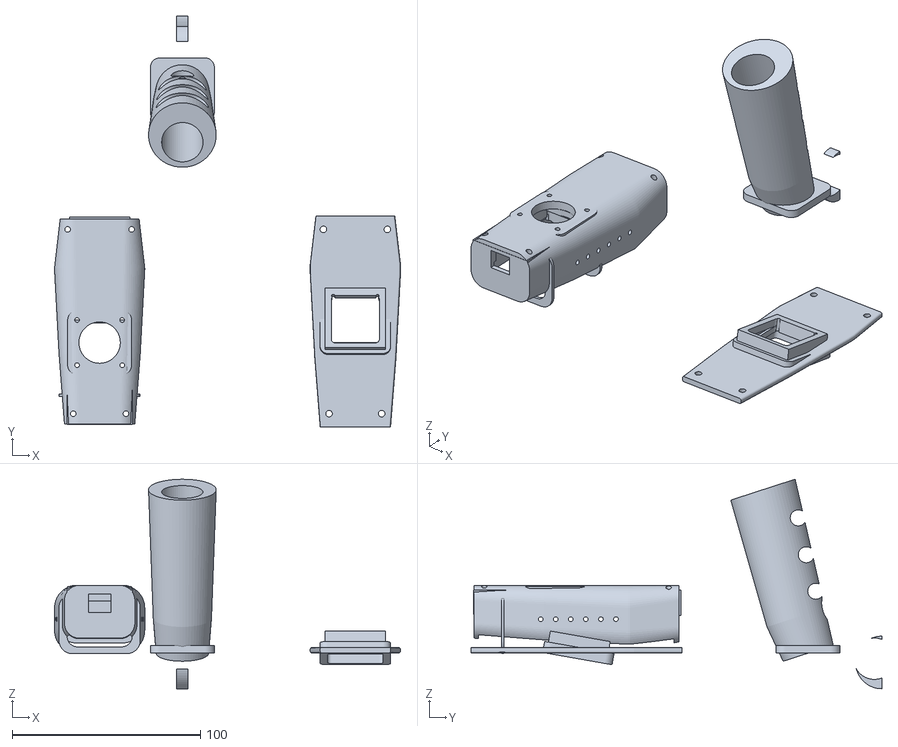
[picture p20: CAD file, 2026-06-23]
3D_Printer_Housing/v06_Housing_And_Stand/06_housing_print_all.stl
184.0 x 218.4 x 111.4

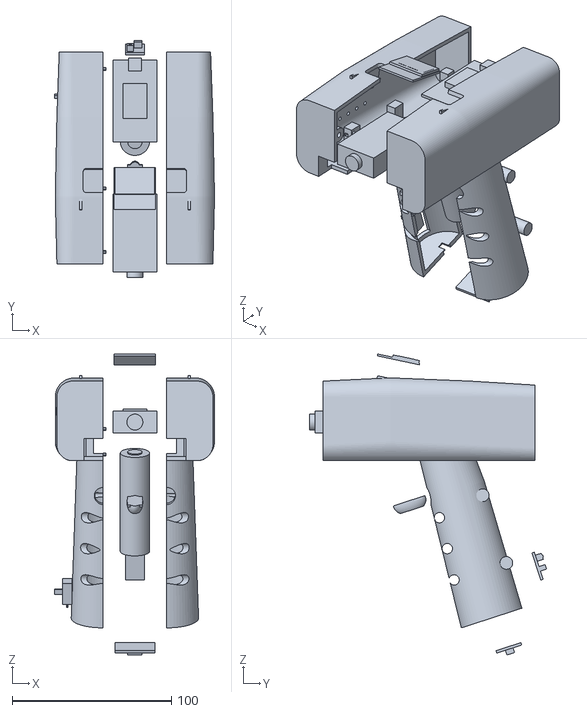
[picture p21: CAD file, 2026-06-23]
3D_Printer_Housing/v09_QR_Scanner_Housing_Snapfit/null.stl
100.5 x 148.9 x 189.0

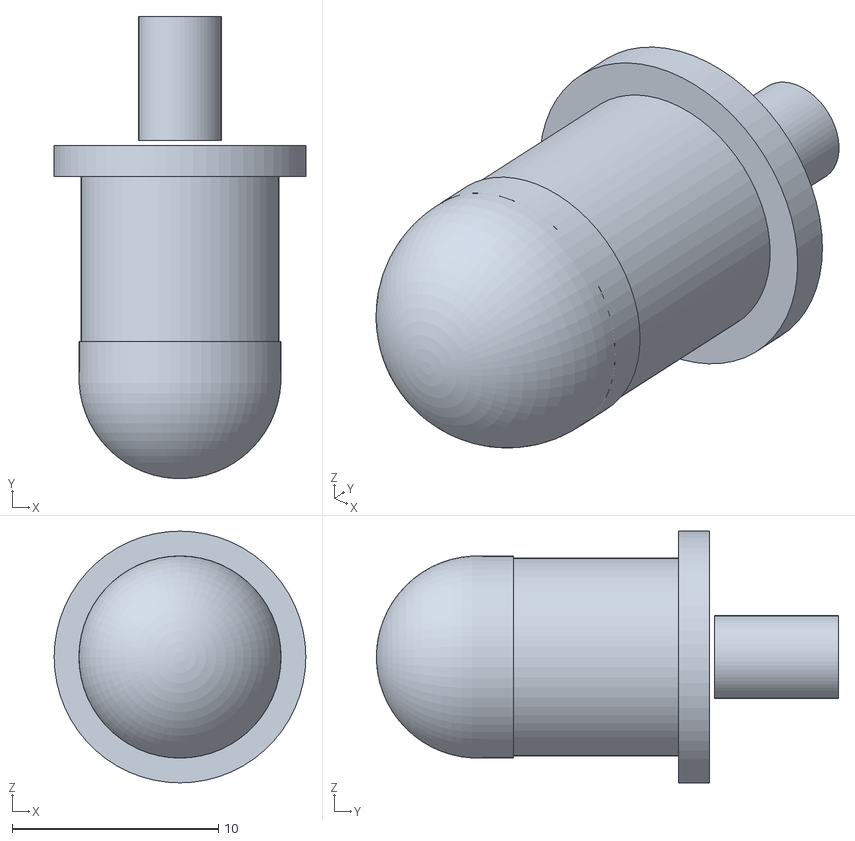
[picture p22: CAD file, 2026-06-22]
3D_Printer_Housing/v11_QR_Scanner_Housing_Flush_OLED/11_trigger_button.stl
12.2 x 22.4 x 12.2

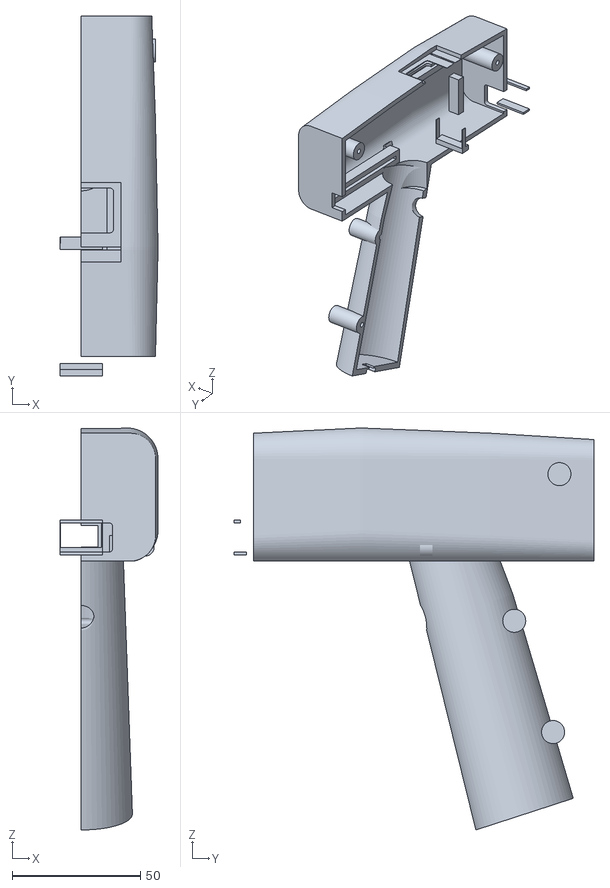
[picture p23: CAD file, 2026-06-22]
3D_Printer_Housing/v13_QR_Scanner_Housing_Slide_Fit/13_housing_right.stl
38.3 x 140.6 x 157.0

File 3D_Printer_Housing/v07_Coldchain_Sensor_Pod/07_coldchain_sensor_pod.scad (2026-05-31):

/* 
 * Cold Chain Digital Twin Sensor Tag Pod Housing V1.0
 * 
 * Author: Antigravity AI (Google DeepMind)
 * Description: 
 *   An industrial-grade, compact, and rugged housing for the cold chain tracking sensor node.
 *   Contains compartments for ESP32, DHT22 (with slanted ventilation grilles), MPU6050 IMU, 
 *   and an 18650 rechargeable battery. Features external mounting ears for shipping container installation.
 */

$fn = 60;
wall = 2.0;         // Wall thickness
clearance = 0.4;    // Assembly tolerances

// [Outer Dimensions]
pod_w = 68.0;       // Total width
pod_l = 92.0;       // Total length (excluding mounting ears)
pod_h = 28.0;       // Total height

// [Component Pocket Sizes]
esp32_size = [28.5, 52.5, 8.0];   // ESP32 DevKit
mpu6050_size = [15.5, 20.5, 5.0]; // MPU6050 Accelerometer
dht22_size = [16.0, 26.0, 10.0];   // DHT22 Temp/Humidity
battery_diam = 19.0;              // 18650 battery cell diameter
battery_len = 66.0;               // 18650 battery cell length

// --- Main Control ---
render_part = "assembly"; // assembly, exploded, print_all, body, lid, cross_section

// 3D Printing alignment helpers
module print_body() {
    sensor_pod_body();
}

module print_lid() {
    translate([0, 0, 4]) rotate([180, 0, 0]) sensor_pod_lid();
}

if (render_part == "assembly") {
    sensor_pod_body();
    translate([0, 0, pod_h * 0.7 + 2]) sensor_pod_lid();
}

if (render_part == "exploded") {
    sensor_pod_body();
    translate([0, 0, pod_h * 0.7 + 25]) sensor_pod_lid();
}

if (render_part == "print_all") {
    translate([0, 0, 0]) print_body();
    translate([pod_w + 15, 0, pod_h * 0.3]) print_lid();
}

if (render_part == "body") print_body();
if (render_part == "lid") print_lid();

if (render_part == "cross_section") {
    difference() {
        union() {
            sensor_pod_body();
            translate([0, 0, pod_h * 0.7 + 2]) sensor_pod_lid();
        }
        // Slice the assembly in half along the longitudinal symmetry plane (X = 0)
        translate([0, -100, -50])
        cube([100, 300, 200]);
    }
}

// --- 1. Pod Base Body ---
module sensor_pod_body() {
    base_h = pod_h * 0.7; // 70% of height is base body
    
    difference() {
        union() {
            // Main rounded box outer shell
            rounded_box(pod_w, pod_l, base_h, 8);
            
            // Mounting ears (screwing tabs on left/right ends)
            translate([-pod_w/2 - 6, 0, 2])
            mounting_ear();
            translate([pod_w/2 + 6, 0, 2])
            rotate([0, 0, 180])
            mounting_ear();
            
            // Internal support frames (Pockets)
            
            // A. ESP32 DevKit Pocket (X+ side)
            translate([15.5, -10, base_h/2 - 3])
            pcb_pocket(esp32_size[0], esp32_size[1], support_h=5, pocket_depth=3.5, wall_t=1.8, clearance_t=clearance);
            
            // B. MPU6050 Accelerometer Pocket (X+ side, forward)
            translate([15.5, 27.5, base_h/2 - 3.5])
            pcb_pocket(mpu6050_size[0], mpu6050_size[1], support_h=4, pocket_depth=3, wall_t=1.8, clearance_t=clearance);
            
            // C. DHT22 Pocket (X- side, forward)
            translate([-20.0, 24.0, base_h/2 - 2])
            pcb_pocket(dht22_size[0], dht22_size[1], support_h=6, pocket_depth=3, wall_t=1.8, clearance_t=clearance);
            
            // D. Battery Cradle Ribs (X- side)
            translate([-20.0, -20.0, 0])
            battery_cradle(battery_diam, 35, 12);
        }

        // --- Subtract cutouts ---
        
        // Hollowing out the main base cavity
        translate([0, 0, wall])
        rounded_box(pod_w - wall*2, pod_l - wall*2, base_h, 6);
        
        // ESP32 USB Port cutout (Rear wall)
        translate([15.5, -pod_l/2 - 2, 8.5])
        cube([12, 10, 7.5], center=true);
        
        // Power Slide Switch Cutout (Side wall)
        translate([pod_w/2 - 2, 15, 9.5])
        cube([10, 12.5, 6.5], center=true);

        // Slanted Louver Air Vents for DHT22 (Front-Left wall)
        // Angle-cut slots to let air in but keep drops out
        for (y_pos = [14, 21, 28, 35]) {
            translate([-pod_w/2 - 1, y_pos, base_h/2 + 2])
            rotate([25, 0, 0])
            cube([10, 3.5, 7.0], center=true);
        }
        
        // 4 corner screw holes (M3 tap, D=2.5mm)
        corner_screw_holes(h=15, d=2.5);
    }
}

// --- 2. Pod Lid Cover ---
module sensor_pod_lid() {
    lid_h = pod_h * 0.3; // 30% of height is lid
    
    difference() {
        union() {
            // Main lid outer rounded shell
            rounded_box(pod_w, pod_l, lid_h, 8);
            
            // Inner alignment mating ring
            translate([0, 0, -2])
            difference() {
                rounded_box(pod_w - wall*2 - 0.4, pod_l - wall*2 - 0.4, 4, 6);
                translate([0, 0, -1])
                rounded_box(pod_w - wall*4, pod_l - wall*4, 6, 5);
            }
        }
        
        // Hollowing out the lid
        translate([0, 0, -wall])
        rounded_box(pod_w - wall*2, pod_l - wall*2, lid_h, 6);
        
        // Status LED Hole (D = 5.2mm)
        translate([15.5, 10, -2])
        cylinder(h=10, d=5.2, center=true);
        
        // 4 corner screw countersink holes (M3 pass, D=3.4mm, Head D=6mm)
        corner_screw_holes(h=20, d=3.4);
        corner_screw_countersinks(h=20, d=6.0);
        
        // Decorative / Branding Engravings
        translate([0, -15, lid_h - 1.2])
        linear_extrude(2) {
            text("COLDCHAIN SENSOR TAG", size=3.5, font="Arial:style=Bold", halign="center", valign="center");
        }
        
        // Simple Geometric Digital Twin Logo (Thermometer + WiFi shape)
        translate([0, 10, lid_h - 1.2])
        linear_extrude(2)
        logo_engraving();
    }
}

// --- Helper & Utility Modules ---

module rounded_box(w, l, h, r) {
    translate([0, 0, h/2])
    linear_extrude(height=h, center=true)
    offset(r=r)
    square([w - r*2, l - r*2], center=true);
}

module mounting_ear() {
    difference() {
        hull() {
            cylinder(h=4, r=8, center=true);
            translate([6, -10, 0]) cube([1, 20, 4], center=true);
        }
        // Screw hole for mounting (M4 bolt, D=4.2mm)
        cylinder(h=10, d=4.2, center=true);
    }
}

module pcb_pocket(pcb_w, pcb_l, support_h, pocket_depth, wall_t, clearance_t) {
    difference() {
        cube([pcb_w + 2*clearance_t + 2*wall_t, pcb_l + 2*clearance_t + 2*wall_t, support_h + pocket_depth], center=true);
        
        translate([0, 0, support_h/2])
        cube([pcb_w + 2*clearance_t, pcb_l + 2*clearance_t, pocket_depth + 0.1], center=true);
        
        translate([0, 0, -pocket_depth/2])
        cube([pcb_w - 2*wall_t, pcb_l - 2*wall_t, support_h + 0.1], center=true);
    }
}

module battery_cradle(d, length, support_w) {
    // Semi-cylindrical cradle ribs to hold 18650 battery cell
    difference() {
        union() {
            translate([0, -length/2 + 8, d/4]) rotate([90, 0, 0]) cylinder(h=6, d=d+4, center=true);
            translate([0, length/2 - 8, d/4]) rotate([90, 0, 0]) cylinder(h=6, d=d+4, center=true);
            
            // Floor bracket
            translate([0, 0, 2]) cube([d+4, length, 4], center=true);
        }
        // Subtract battery cylinder for the cell to sit snuggly
        translate([0, 0, d/2 + 2.5])
        rotate([90, 0, 0])
        cylinder(h=length + 10, d=d + clearance, center=true);
    }
}

module corner_screw_holes(h, d) {
    cx = pod_w/2 - 5.5;
    cy = pod_l/2 - 5.5;
    translate([-cx, -cy, -h/2 + pod_h]) cylinder(h=h, d=d);
    translate([cx, -cy, -h/2 + pod_h]) cylinder(h=h, d=d);
    translate([-cx, cy, -h/2 + pod_h]) cylinder(h=h, d=d);
    translate([cx, cy, -h/2 + pod_h]) cylinder(h=h, d=d);
}

module corner_screw_countersinks(h, d) {
    cx = pod_w/2 - 5.5;
    cy = pod_l/2 - 5.5;
    translate([-cx, -cy, pod_h * 0.3 - 2]) cylinder(h=h, d=d);
    translate([cx, -cy, pod_h * 0.3 - 2]) cylinder(h=h, d=d);
    translate([-cx, cy, pod_h * 0.3 - 2]) cylinder(h=h, d=d);
    translate([cx, cy, pod_h * 0.3 - 2]) cylinder(h=h, d=d);
}

module logo_engraving() {
    // Simple thermometer shape
    circle(r=2.5);
    translate([0, 2.5, 0]) square([2, 5], center=true);
    translate([0, 5, 0]) circle(r=1);
    
    // Wi-Fi signal arcs
    translate([5, 0, 0]) circle(r=0.8);
    difference() {
        translate([5, 0, 0]) circle(r=4.5);
        translate([5, 0, 0]) circle(r=3.0);
        translate([1.5, -5, 0]) square([10, 10]);
    }
    difference() {
        translate([5, 0, 0]) circle(r=8.0);
        translate([5, 0, 0]) circle(r=6.5);
        translate([1.5, -10, 0]) square([15, 20]);
    }
}

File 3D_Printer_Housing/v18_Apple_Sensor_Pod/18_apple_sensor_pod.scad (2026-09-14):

/*
 * Cold Chain Digital Twin Platform
 * v18 Apple Sensor Pod Housing
 * 
 * Target Board: CarrierBoard_BeetleC6_EdgeUSB_50x50 (50mm x 50mm)
 * Target Battery: Lithium-ion / LiPo Pouch Cell (3.7V 500~1200mAh, ~50x30x10mm)
 * 
 * Features:
 *  - Authentic Apple Fruit Geometry (87mm Dia x 80mm Height)
 *  - Top stem depression with flush USB-C charging/programming port
 *  - Left 4mm circular ventilation hole for SHT45 temperature & humidity sensing
 *  - Right power switch (SW) access slot
 *  - Front aperture for BH1750 ambient light sensor
 *  - Internal 4x M3 standoffs (43mm x 43mm pitch) for PCB mounting
 *  - Bottom integrated cradle for Lithium-ion battery
 *  - 4x perimeter M3 assembly screw bosses outside the PCB footprint
 *  - Precision interlocking tongue-and-groove perimeter lip
 *  - Modular Apple Stem + Leaf accessory (acts as cosmetic stem or USB dust plug)
 */

$fn = 60;

// ==========================================
// 1. PARAMETERS & DIMENSIONS
// ==========================================

// Render control:
// "assembly", "exploded", "cross_section", "rear_shell", "front_shell", "stem", "print_all"
render_part = "cross_section"; 

wall_t = 2.8;          // Nominal wall thickness
clearance = 0.25;      // 3D printing joint clearance

// PCB Specifications
pcb_w = 50.0;
pcb_h = 50.0;
pcb_t = 1.6;
pcb_z_center = 3.0;    // Z offset of PCB center
pcb_y_mount = -4.0;    // Y position of PCB back face
hole_pitch = 43.0;     // M3 hole spacing (43mm x 43mm)

// Battery Compartment Specifications
bat_w = 52.0;          // Max width of pouch battery
bat_h = 13.0;          // Cradle pocket height
bat_t = 10.0;          // Pocket depth (Y-direction)
bat_z_pos = -28.5;     // Z center of battery

// Perimeter Assembly Screws (4 corners outside PCB)
screw_pts = [
    [-29.0,  23.0],    // Top-left
    [ 29.0,  23.0],    // Top-right
    [-27.0, -20.0],    // Bottom-left
    [ 27.0, -20.0]     // Bottom-right
];

// ==========================================
// 2. APPLE SPLINE PROFILES
// ==========================================

// Outer Apple Profile (R, Z) - Max Diameter ~87mm, Height ~80mm
apple_outer_profile = [
  [0.0, -32.5],
  [1.0, -33.1],
  [2.1, -33.7],
  [3.3, -34.3],
  [4.5, -34.9],
  [5.8, -35.4],
  [7.2, -36.0],
  [8.6, -36.6],
  [10.1, -37.1],
  [11.7, -37.6],
  [13.4, -38.1],
  [15.2, -38.4],
  [17.0, -38.7],
  [18.9, -38.8],
  [20.9, -38.7],
  [22.8, -38.5],
  [24.7, -38.0],
  [26.6, -37.3],
  [28.4, -36.4],
  [30.2, -35.3],
  [31.9, -33.9],
  [33.5, -32.3],
  [35.1, -30.4],
  [36.5, -28.4],
  [37.9, -26.1],
  [39.1, -23.6],
  [40.2, -20.9],
  [41.1, -18.0],
  [41.9, -15.0],
  [42.5, -11.9],
  [43.0, -8.7],
  [43.4, -5.4],
  [43.5, -2.1],
  [43.54, 1.2],
  [43.4, 4.4],
  [43.1, 7.6],
  [42.7, 10.7],
  [42.1, 13.7],
  [41.3, 16.5],
  [40.4, 19.3],
  [39.4, 21.9],
  [38.2, 24.4],
  [36.9, 26.8],
  [35.5, 29.1],
  [34.0, 31.2],
  [32.3, 33.2],
  [30.6, 35.1],
  [28.7, 36.8],
  [26.7, 38.3],
  [24.6, 39.6],
  [22.4, 40.5],
  [20.2, 41.1],
  [18.0, 41.2],
  [15.8, 40.8],
  [13.7, 40.1],
  [11.7, 39.0],
  [9.8, 37.8],
  [8.0, 36.4],
  [6.4, 35.1],
  [4.9, 33.9],
  [3.6, 33.0],
  [2.4, 32.3],
  [1.3, 31.8],
  [0.0, 31.5]
];

// Inner Cavity Profile (R, Z) - Provides generous space for PCB & battery
apple_inner_profile = [
  [0.0, -29.0],
  [1.0, -29.6],
  [2.1, -30.2],
  [3.3, -30.7],
  [4.6, -31.3],
  [6.0, -31.9],
  [7.5, -32.5],
  [9.1, -33.1],
  [10.7, -33.6],
  [12.4, -34.1],
  [14.2, -34.5],
  [16.1, -34.8],
  [18.1, -35.0],
  [20.1, -35.1],
  [22.1, -34.9],
  [24.0, -34.5],
  [25.9, -33.9],
  [27.6, -33.1],
  [29.3, -32.1],
  [30.8, -30.9],
  [32.3, -29.4],
  [33.6, -27.8],
  [34.8, -26.0],
  [35.9, -24.0],
  [36.9, -21.8],
  [37.8, -19.5],
  [38.5, -17.0],
  [39.1, -14.4],
  [39.6, -11.7],
  [40.0, -8.9],
  [40.3, -6.1],
  [40.5, -3.2],
  [40.6, -0.3],
  [40.56, 2.6],
  [40.3, 5.4],
  [40.0, 8.2],
  [39.5, 10.9],
  [38.8, 13.5],
  [38.0, 16.1],
  [37.1, 18.5],
  [36.0, 20.8],
  [34.8, 23.0],
  [33.4, 25.1],
  [31.9, 27.0],
  [30.4, 28.8],
  [28.7, 30.5],
  [26.9, 32.0],
  [25.0, 33.4],
  [23.1, 34.6],
  [21.1, 35.6],
  [19.0, 36.4],
  [16.9, 36.9],
  [14.8, 37.1],
  [12.8, 37.0],
  [10.9, 36.5],
  [9.0, 35.7],
  [7.3, 34.7],
  [5.7, 33.6],
  [4.3, 32.5],
  [3.1, 31.6],
  [2.0, 30.9],
  [1.0, 30.3],
  [0.0, 29.8]
];

// ==========================================
// 3. BASE 3D GEOMETRY MODULES
// ==========================================

module apple_solid_outer() {
    rotate_extrude(angle=360, $fn=72) {
        polygon(concat([[0, apple_outer_profile[0][1]]], apple_outer_profile, [[0, apple_outer_profile[len(apple_outer_profile)-1][1]]]));
    }
}

module apple_solid_inner() {
    rotate_extrude(angle=360, $fn=72) {
        polygon(concat([[0, apple_inner_profile[0][1]]], apple_inner_profile, [[0, apple_inner_profile[len(apple_inner_profile)-1][1]]]));
    }
}

// Interlocking step flange (Tongue & Groove)
module perimeter_lip(is_male=true) {
    lip_w = 1.3;
    lip_d = 1.5;
    t_offset = is_male ? 0 : -clearance;
    
    intersection() {
        apple_solid_outer();
        difference() {
            cylinder(r=45, h=lip_d * 2, center=true);
            cylinder(r=37.5, h=lip_d * 3, center=true);
        }
    }
}

// Common functional cutouts (USB-C, Vent hole, Switch, Stem socket)
module functional_cutouts() {
    // 1. Top USB-C Port Cutout
    // Centered at X=0, top of PCB is Z=28
    translate([0, 0, 31.0]) {
        hull() {
            translate([-4.8, 0, 0]) cylinder(r=2.5, h=18, center=true);
            translate([ 4.8, 0, 0]) cylinder(r=2.5, h=18, center=true);
        }
        // Funnel bevel for easy cable plug-in
        translate([0, 0, 7.5])
            cylinder(r1=7.0, r2=10.0, h=6.0, center=true);
    }
    
    // 2. Left 4mm Circular Ventilation Hole for SHT45 (Viewer Left: +X in rot_z=180)
    translate([42.0, -3.0, 15.0])
        rotate([0, 90, 0])
        cylinder(r=2.0, h=25, center=true);
        
    // 3. Right Power Switch (SW1) Port (Viewer Right: -X in rot_z=180)
    translate([-40.0, -1.0, 20.0])
        rotate([0, 90, 0])
        hull() {
            translate([0, -2.5, 0]) cylinder(r=2.2, h=20, center=true);
            translate([0,  2.5, 0]) cylinder(r=2.2, h=20, center=true);
        }
        
    // 4. Apple Stem Center Socket (Top Calyx)
    translate([0, 0, 31.0])
        cylinder(r=2.25, h=10, center=true);
}

// ==========================================
// 4. REAR SHELL (MAIN BASE HOUSING)
// ==========================================
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

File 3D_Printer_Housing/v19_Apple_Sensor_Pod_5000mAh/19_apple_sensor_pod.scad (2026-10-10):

/*
 * Cold Chain Digital Twin Platform
 * v19 Apple Sensor Pod Housing (10cm Dia / 35mm PCB Thickness Edition)
 * 
 * Outer Geometry:
 *  - Diameter: Exactly 100.0mm (10cm)
 *  - Height: 91.87mm (~9.2cm)
 * 
 * Target Board: CarrierBoard_BeetleC6_EdgeUSB_50x50 (50.0mm x 50.0mm)
 *  - PCB Substrate + Dual-side pinheader sockets + Sensors = 30~35mm total stack!
 *  - Accommodates 17.5mm rear protrusion (GPS patch antenna, MPU6050, SHT45 on sockets)
 *  - Accommodates 17.5mm+ front protrusion (Beetle C6 MCU, BH1750 on sockets)
 *  - Total PCB Assembly Thickness: 36.6mm (> 35.0mm safe margin!)
 * 
 * Target Battery: JRF PL105568 3.7V 5000mAh LiPo Pouch Cell (10.0 x 55.0 x 68.0mm)
 *  - Pocket: 58.0mm W x 73.0mm H x 12.0mm D with 2.5mm isolation safety wall
 */

$fn = 64;

// Render mode: "cross_section", "assembly", "exploded", "rear_shell", "front_shell", "stem", "print_all"
render_part = "cross_section"; 

wall_t = 3.0;          // Nominal wall thickness (mm)
clearance = 0.25;      // 3D printing joint clearance (mm)

// PCB Specifications
pcb_w = 50.0;
pcb_h = 50.0;
pcb_t = 1.6;
hole_pitch = 43.0;     // M3 hole spacing (43mm x 43mm)
pcb_z_center = 3.0;    // Center of PCB in Z

// Stack Coordinates along Y-axis (front-to-back):
//  Y = -34.5 to -22.5: Battery Pocket (12mm depth)
//  Y = -22.5 to -20.0: Safety Divider Plate (2.5mm thickness)
//  Y = -20.0 to  -2.5: Rear Sensor Clearance & Standoffs (17.5mm height!)
//  Y =  -2.5 to  -0.9: PCB Substrate (1.6mm thickness)
//  Y =  -0.9 to +17.5: Front Sensor Protrusion (18.4mm front clearance in dome)
pcb_y_mount = -2.5;    // Back face of PCB sits on standoffs at Y = -2.5
divider_y_face = -20.0;// Front face of divider plate
standoff_h = pcb_y_mount - divider_y_face; // Exactly 17.5mm!

// JRF PL105568 5000mAh Battery Specifications
bat_w = 58.0;          // Pocket width (cell width 55mm + 3mm margin)
bat_h = 73.0;          // Pocket height (cell body 68mm + 5mm margin for tabs)
bat_t = 12.0;          // Pocket thickness (cell thickness 10mm + 2mm margin)
bat_y_center = -28.5;  // Center Y of battery pocket (from Y=-34.5 to Y=-22.5)
bat_z_center = 2.0;    // Center Z of battery

// Perimeter Assembly Screws (4 corners outside PCB & battery)
screw_pts = [
    [-35.0,  26.0],    // Top-left
    [ 35.0,  26.0],    // Top-right
    [-34.0, -23.0],    // Bottom-left
    [ 34.0, -23.0]     // Bottom-right
];

// Outer Apple Profile (R, Z) - Exact Outer Diameter 100.0mm (R_max = 50.0mm), Height 91.87mm
apple_outer_profile = [
  [  0.00, -37.32],
  [  1.15, -38.01],
  [  2.41, -38.70],
  [  3.79, -39.39],
  [  5.17, -40.08],
  [  6.66, -40.65],
  [  8.27, -41.34],
  [  9.88, -42.03],
  [ 11.60, -42.60],
  [ 13.44, -43.18],
  [ 15.39, -43.75],
  [ 17.46, -44.10],
  [ 19.52, -44.44],
  [ 21.70, -44.56],
  [ 24.00, -44.44],
  [ 26.18, -44.21],
  [ 28.36, -43.64],
  [ 30.55, -42.83],
  [ 32.61, -41.80],
  [ 34.68, -40.54],
  [ 36.63, -38.93],
  [ 38.47, -37.09],
  [ 40.31, -34.91],
  [ 41.92, -32.61],
  [ 43.52, -29.97],
  [ 44.90, -27.10],
  [ 46.16, -24.00],
  [ 47.20, -20.67],
  [ 48.12, -17.23],
  [ 48.81, -13.67],
  [ 49.38,  -9.99],
  [ 49.84,  -6.20],
  [ 49.95,  -2.41],
  [ 50.00,   1.38],
  [ 49.84,   5.05],
  [ 49.49,   8.73],
  [ 49.04,  12.29],
  [ 48.35,  15.73],
  [ 47.43,  18.95],
  [ 46.39,  22.16],
  [ 45.25,  25.15],
  [ 43.87,  28.02],
  [ 42.37,  30.78],
  [ 40.77,  33.42],
  [ 39.04,  35.83],
  [ 37.09,  38.13],
  [ 35.14,  40.31],
  [ 32.96,  42.26],
  [ 30.66,  43.98],
  [ 28.25,  45.48],
  [ 25.72,  46.51],
  [ 23.20,  47.20],
  [ 20.67,  47.31],
  [ 18.14,  46.85],
  [ 15.73,  46.05],
  [ 13.44,  44.79],
  [ 11.25,  43.41],
  [  9.19,  41.80],
  [  7.35,  40.31],
  [  5.63,  38.93],
  [  4.13,  37.90],
  [  2.76,  37.09],
  [  1.49,  36.52],
  [  0.00,  36.17]
];

// Inner Cavity Profile (R, Z) - Inner Diameter 93.24mm, Cavity Height 82.91mm
apple_inner_profile = [
  [  0.00, -33.30],
  [  1.15, -33.99],
  [  2.41, -34.68],
  [  3.79, -35.25],
  [  5.28, -35.94],
  [  6.89, -36.63],
  [  8.61, -37.32],
  [ 10.45, -38.01],
  [ 12.29, -38.59],
  [ 14.24, -39.16],
  [ 16.31, -39.62],
  [ 18.49, -39.96],
  [ 20.79, -40.19],
  [ 23.08, -40.31],
  [ 25.38, -40.08],
  [ 27.56, -39.62],
  [ 29.74, -38.93],
  [ 31.69, -38.01],
  [ 33.65, -36.86],
  [ 35.37, -35.48],
  [ 37.09, -33.76],
  [ 38.59, -31.92],
  [ 39.96, -29.86],
  [ 41.23, -27.56],
  [ 42.37, -25.03],
  [ 43.41, -22.39],
  [ 44.21, -19.52],
  [ 44.90, -16.54],
  [ 45.48, -13.44],
  [ 45.93, -10.22],
  [ 46.28,  -7.01],
  [ 46.51,  -3.67],
  [ 46.62,  -0.34],
  [ 46.58,   2.99],
  [ 46.28,   6.20],
  [ 45.93,   9.42],
  [ 45.36,  12.52],
  [ 44.56,  15.50],
  [ 43.64,  18.49],
  [ 42.60,  21.24],
  [ 41.34,  23.89],
  [ 39.96,  26.41],
  [ 38.36,  28.82],
  [ 36.63,  31.01],
  [ 34.91,  33.07],
  [ 32.96,  35.03],
  [ 30.89,  36.75],
  [ 28.71,  38.36],
  [ 26.53,  39.73],
  [ 24.23,  40.88],
  [ 21.82,  41.80],
  [ 19.41,  42.37],
  [ 17.00,  42.60],
  [ 15.85,  42.49],
  [ 12.52,  41.92],
  [ 10.34,  41.00],
  [  8.38,  39.85],
  [  6.55,  38.59],
  [  4.94,  37.32],
  [  3.56,  36.29],
  [  2.30,  35.48],
  [  1.15,  34.80],
  [  0.00,  34.22]
];

module apple_solid_outer() {
    rotate_extrude(angle=360, $fn=72) {
        polygon(concat([[0, apple_outer_profile[0][1]]], apple_outer_profile, [[0, apple_outer_profile[len(apple_outer_profile)-1][1]]]));
    }
}

module apple_solid_inner() {
    rotate_extrude(angle=360, $fn=72) {
        polygon(concat([[0, apple_inner_profile[0][1]]], apple_inner_profile, [[0, apple_inner_profile[len(apple_inner_profile)-1][1]]]));
    }
}
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

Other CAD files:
3D_Printer_Housing/v14_QR_Scanner_Housing_Final/14_housing_right.stl
3D_Printer_Housing/v17_QR_Scanner_Housing/17_qr_scanner_housing_right_half.stl
3D_Printer_Housing/v18_Apple_Sensor_Pod/18_apple_stem.stl
3D_Printer_Housing/v19_Apple_Sensor_Pod_5000mAh/19_apple_stem.stl
3D_Printer_Housing/v20_Apple_Sensor_Pod_Modular5000mAh/20_apple_sensor_pod.scad
3D modeling/GyroSensor_GY-521/GyroSensor_GY-521.dwg
3D modeling/Neo-6m-0-001/L-KLS1-SMA006 v3.step
3D modeling/Neo-6m-0-001/Neo-6m-0-001.step
3D modeling/Neo-6m-0-001/PinHeader.step
3D modeling/atgm336h-gnss-module-1.snapshot.1/ATGM336H.IGS
3D modeling/atgm336h-gnss-module-1.snapshot.1/ATGM336H.SLDPRT
3D modeling/zsp32-s3-wroom-1-devkit-1.snapshot.9/ESP32-S3-WROOM-1_devkit_2xUSBC.FCStd
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

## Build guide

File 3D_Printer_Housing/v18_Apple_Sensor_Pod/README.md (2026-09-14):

# v18 Apple Sensor Pod (사과 모형 3D 프린터 하우징)

본 프로젝트는 스마트 콜드체인(저온 유통) 디지털 트윈 모니터링을 위해 설계된 **실물 과일 형상(Apple Dummy Sensor Node) 3D 프린팅 하우징**입니다.  
사용자가 제시한 단면 설계 컨셉을 100% 충족하여, `3D modeling\CarrierBoard_BeetleC6_EdgeUSB_50x50` PCB($50.0 \times 50.0\,\text{mm}$)와 하단 리튬이온/리튬폴리머 배터리를 유격 없이 견고하게 수납합니다.

---

## 1. 하우징 외형 및 내부 기구 설계 사양

| 항목 | 상세 사양 | 설계 의도 및 특징 |
| :--- | :--- | :--- |
| **외형 형상** | 사과(Apple) 유기적 곡면 회전체 | 실물 사과(Fuji/Gala 계통)와 유사한 크기 및 형상 구현 |
| **전체 치수** | **최대 직경 $\varnothing 87.0\,\text{mm} \times$ 높이 $80.0\,\text{mm}$** | 운송 상자/컨테이너 적재 시 실물 사과와 동일한 부피 차지 |
| **기본 벽 두께** | **$2.8 \sim 3.0\,\text{mm}$** | 낙하 충격 보호 및 진동 흡수 강성 확보 |
| **분할 방식** | **전/후면 2피스 클램쉘 (Front & Rear Shell)** | 조립성 극대화 및 3D 프린터 무서포트 평면 베드 안착 |
| **PCB 고정** | **M3 스탠드오프 4개소 ($43.0 \times 43.0\,\text{mm}$ 피치)** | 기판 나사 체결 높이 $8.0\,\text{mm}$ (후면 센서 돌출핀 간섭 0mm) |
| **배터리 수납** | **하단 일체형 배터리 크래들 ($52 \times 32 \times 10\,\text{mm}$)** | $3.7\text{V}$ 500~1200mAh 리튬 파우치 셀(103450/803048 등) 장착 |
| **체결 방식** | **단차 립/그루브(Tongue & Groove) + M3 볼트 4개소** | 외곽 코너 4개소 M3 체결로 빛/먼지 차단 및 내구성 보장 |

---

## 2. 주요 기능성 포트 및 인터페이스

1. **상단 USB-C 직결 포트 (Beetle ESP32-C6)**:
   - 상단 꼭지 함몰부에 Beetle C6의 Type-C 포트가 직결되도록 개방되어 있습니다.
   - 케이스를 분해하지 않고도 언제든지 C타입 케이블을 꽂아 **배터리 충전 및 펌웨어 디버깅/업로드**가 가능합니다.
2. **좌측 4mm 온습도 측정 환기구 (4mm Ventilation Hole)**:
   - SHT45 온습도 센서 모듈 바로 인근 외벽에 $\varnothing 4.0\,\text{mm}$ 원형 에어홀을 배치했습니다.
   - 저온 저장고 및 냉장 차량 내부의 공기가 센서에 직접 순환되어 지연 없는 정밀 온습도 측정이 가능합니다.
3. **우측 전원 스위치 조작구 (Power Switch Slot)**:
   - 기판의 SW1 슬라이드 스위치 위치에 맞춘 개구부로, 외부에서 손쉽게 전원을 ON/OFF 할 수 있습니다.
4. **전면 조도 센서 수광 윈도우 (Light Sensor Aperture)**:
   - BH1750 조도 센서의 수광면을 향해 테이퍼 가공된 개구부를 제공하여 컨테이너 개폐 여부를 감지합니다.
5. **탈부착식 사과 꼭지 액세서리 (Apple Stem & Leaf)**:
   - 상단 꼭지 소켓에 탈부착 가능한 사과 꼭지/잎사귀 부품을 제공합니다.
   - USB 케이블을 연결하지 않을 때 먼지 방지 마개(Dust Plug) 및 실물 사과 질감 연출용으로 사용됩니다.

---

## 3. 3D 프린팅 권장 설정 가이드 (FDM / SLA)

| 슬라이서 파라미터 | 권장 설정값 | 비고 |
| :--- | :--- | :--- |
| **노즐 구경** | 0.4 mm | 표준 노즐 권장 |
| **레이어 높이** | 0.16 mm ~ 0.20 mm | 곡면 품질을 위해 0.16mm 권장 (적응형 레이어 활용 가능) |
| **벽 라인 수 (Perimeters)** | 3 ~ 4 라인 (1.2 ~ 1.6mm) | 충격 흡수 및 나사 체결 강도 확보 |
| **상/하단 레이어** | 각 5 레이어 이상 | 돔 상부 밀폐성 유지 |
| **내부 채움 (Infill)** | 20% ~ 30% (Gyroid 권장) | 균일한 강도 및 사과 내부 완충 효과 |
| **서포트 (Support)** | 최소 트리 서포트 (Tree Support) | 배드 안착면(분할면)은 서포트 없이 출력 가능 |
| **빌드 플레이트 안착** | 브림 (Brim 5mm) 권장 | 돔 형상 출력 중 베드 탈락 방지 |
| **추천 필라멘트** | 하우징: Red PLA 또는 PETG<br>꼭지: Brown/Green PLA | 냉장 환경($0\sim 5^\circ\text{C}$) 사용 시 PETG 권장 |

---

## 4. 조립 순서 (Assembly Process)

```
[1단계: 배터리 수납]
  └─ 리튬이온 파우치 배터리를 후면 쉘(Rear Shell) 하단 크래들에 안착
  └─ 배터리 케이블을 우측 전용 유도로를 통해 기판 상단 방향으로 인출

[2단계: PCB 기판 체결]
  └─ CarrierBoard 50x50 기판을 4개의 M3 스탠드오프에 정렬
  └─ M3 x 6mm 둥근머리 볼트 4개로 기판을 후면 쉘에 견고하게 고정

[3단계: 케이블 연결 및 전원 확인]
  └─ 배터리 JST-PH 2.0 단자를 기판에 연결하고 SW1 전원 켜짐 확인

[4단계: 전면 하우징 결합]
  └─ 전면 쉘(Front Shell)의 돌출 단차 립(Tongue)을 후면 쉘 그루브에 맞물림
  └─ 외곽 4개소의 M3 홀에 M3 x 14~16mm 볼트를 체결하여 상/하판 고정

[5단계: 사과 꼭지 결합]
  └─ 상단 꼭지 홀에 사과 꼭지(Stem) 부품을 가볍게 삽입하여 조립 완성
```

---

## 5. 생성된 파일 목록

- `18_apple_sensor_pod.scad`: 전체 파라메트릭 OpenSCAD 소스 코드
- `render_apple_pod.ps1`: 3D 렌더링 및 STL 자동 생성 파워쉘 스크립트
- **3D 프린터 출력용 STL 파일**:
  - `18_apple_rear_shell.stl`: PCB 스탠드오프 및 배터리 크래들이 포함된 후면 하우징
  - `18_apple_front_shell.stl`: 단차 결합 립 및 조도 센서 윈도우가 포함된 전면 하우징
  - `18_apple_stem.stl`: 탈부착용 사과 꼭지 및 잎사귀 부품
- **3D 프리뷰 렌더링 이미지**:
  - `18_cross_section_view.png`: 사용자 참고 도면과 1:1 일치하는 내부 단면 뷰
  - `18_assembly_view.png`: 사과 완제품 외형 조립 뷰
  - `18_exploded_view.png`: 부품 분해도 뷰
  - `18_print_layout_view.png`: 3D 프린터 베드 배치 뷰

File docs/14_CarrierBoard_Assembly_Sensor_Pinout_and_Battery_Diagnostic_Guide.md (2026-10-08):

# 14. CarrierBoard 하드웨어 조립, 전 센서 핀맵 매핑, 배터리 결선 및 충전 진단 가이드

**문서 번호**: CC-DOC-2026-14  
**작성 일자**: 2026-10-08  
**대상 하드웨어**: CarrierBoard Beetle ESP32-C6 EdgeUSB 50×50 (v9/v10)  
**핵심 장치**: DFRobot Beetle ESP32-C6 Mini MCU (DFR1117, RISC-V), TP4057 충전 IC  
**연동 센서**: SHT45 (온습도), GY-521/MPU6050 (6축 IMU), BH1750 (조도), ATGM336H (GPS)  

---

## 1. 개요 및 목적

본 문서는 콜드체인 디지털 트윈 센서 노드(CarrierBoard Beetle ESP32-C6 50×50mm)의 **소켓 납땜 조립, 센서별 실사용 핀맵(Pinout) 매핑, 배터리 탈부착 피그테일 커넥터 결선, 센서 미장착 상태에서의 멀티미터 정밀 진단 절차, 온보드 TP4057 충전 IC 및 초록색 LED 동작 메커니즘, 그리고 배터리 잔량 모니터링 솔루션**을 총망라한 공식 엔지니어링 핸드북입니다.

---

## 2. 실물 기판 조립 및 센서 체결 방향

### 2.1 실장면 구분 및 소켓 배치
* **Top면 (앞면 / 전면 부품면)**:
  * **Beetle ESP32-C6 Mini**: 1×8 암형 핀헤더 소켓 2열 (중앙 세로 배치, USB-C 단자가 기판 상단 바깥 지향)
  * **BH1750 (조도 센서)**: 1×5 암형 핀헤더 소켓 1열 (우측 중간 가로 배치)
* **Bottom면 (뒷면 / 후면 센서면)**:
  * **ATGM336H (GPS 모듈)**: 1×5 소켓 (좌측 상단 가로 배치)
  * **SHT45 (온습도 센서)**: 1×5 소켓 (좌측 중단 가로 배치)
  * **GY-521 / MPU6050 (6축 IMU)**: 1×8 소켓 (우측 중단 가로 배치)

### 2.2 센서 역삽입(180도 반대 체결) 방지 가이드
센서가 180도 반대로 꽂히면 내부 다이오드로 인해 전원선(3.3V)과 GND 간 단락(쇼트) 또는 I2C 라인 접지 클램핑이 발생하여 LDO가 보호 셧다운됩니다:
1. **BH1750 (조도)**: 부품면이 아닌 **파란색 뒷면(실크 라벨 인쇄면)이 위를 향하도록** 장착 (`VCC`가 소켓 5번 우측 3.3V와 일치).
2. **ATGM336H (GPS)**: 코인 배터리가 보이는 면이 아닌 **뒷면(실크 라벨 인쇄면)이 위/바깥을 향하도록** 장착 (`VCC`가 소켓 1번 우측 3.3V와 일치).
3. **SHT45 (온습도)**: 모듈의 `VIN` 핀이 소켓 우측(4/5번 3.3V 패드)을 향하도록 장착.
4. **GY-521 (MPU6050)**: 모듈의 `VCC` 핀이 소켓 우측 끝(8번 3.3V 패드)을 향하도록 장착.

---

## 3. 전체 센서별 실제 사용 핀맵 정밀 분석

우리 시스템은 **I2C 공용 버스 공유** 및 **UART 시리얼 통신**을 채택하여 불필요한 배선을 최소화했습니다.

```
       [ ESP32-C6 ]
         │      │
     GPIO 19  GPIO 20 (I2C Bus 공유)
         ├──────┼──────> SHT45   (온습도: 0x44) [VCC, GND, SCL, SDA]
         ├──────┼──────> BH1750  (조  도: 0x23) [VCC, GND, SCL, SDA]
         └──────┴──────> MPU6050 (가속도: 0x68) [VCC, GND, SCL, SDA]

     GPIO 16  GPIO 17 (UART Serial)
         └──────┴──────> ATGM336H GPS          [VCC, GND, TXD, (RXD)]
```

### 3.1 센서별 상세 핀아웃 매핑표

| 센서 모듈 | 통신 방식 | 주소/보레이트 | 실사용 핀 목록 | 미사용 핀 (NC / 처리) |
| :--- | :---: | :---: | :--- | :--- |
| **GY-521 (MPU6050)** | I2C | `0x68` | **`VCC, GND, SCL, SDA` (4개)** | `XDA, XCL, INT` (NC)<br>`AD0` (기판에서 GND 자동 접지) |
| **BH1750** | I2C | `0x23` | **`VCC, GND, SCL, SDA` (4개)** | `ADDR` (기판에서 GND 자동 접지) |
| **SHT45** | I2C | `0x44` | **`VIN, GND, SCL, SDA` (4개)** | Pad 5 (기판에서 3.3V 풀업/보조) |
| **ATGM336H GPS** | UART | `9600 bps` | **`VCC, GND, TXD(GPIO 16), RXD(GPIO 17)`** | `PPS` (NC) |

---

## 4. 배터리 탈부착 피그테일 커넥터 및 결선 가이드

### 4.1 피그테일 커넥터 결선 구조
배터리를 기판에 직결 납땜하지 않고 2핀 암-수 커넥터를 중간에 연결하여 **배터리 충전/교체 편의성 확보 및 무전원 안전 납땜**을 실현했습니다.

```text
 [배터리 셀]                      [2핀 커넥터 케이블]                       [캐리어 보드 PCB]
 
 (18650 / 파우치)             (배터리측)           (기판측)
  (+) 빨간선 ─────납땜──── [빨간선] ─┐          ┌─ [빨간선] ─────납땜──── 기판 [BAT+ (왼쪽 관통 홀)]
                                    │ 커넥터 체결 │
  (-) 검은선 ─────납땜──── [검은선] ─┘ (탈부착 가능) └─ [검은선] ─────납땜──── 기판 [GND (오른쪽 관통 홀)]
```

### 4.2 하단 관통 홀 극성 (J1)
* **왼쪽 관통 홀 (`BAT+`)**: 배터리 빨간선 (`+`) 인입 $\rightarrow$ 슬라이드 스위치 SW1 1번 핀으로 직결
* **오른쪽 관통 홀 (`GND`)**: 배터리 검은선 (`-`) 인입 $\rightarrow$ 기판 공통 접지면으로 직결

### 4.3 글루건(핫멜트) 보강 처리 권장 사유
1. **장력 완화 (Strain Relief)**: 배터리 전선의 반복적인 흔들림/꺾임으로 인한 심선 단선 및 패드 뜯김(Lifted Pad) 원천 방지.
2. **절연 보호 (Insulation)**: 비전도성 수지로 납땜부를 밀봉하여 이물질 및 도체 접촉에 의한 단락 방지.

---

## 5. 센서 미장착 상태에서의 멀티미터 정밀 전원 진단

센서가 전혀 꽂혀 있지 않은 상태에서도 멀티미터(DCV 모드)로 전원 계통을 100% 검증할 수 있습니다:

* **[공통 접지 팁]**: 멀티미터 **검은색 프로브(-)**를 기판 네 모서리의 **M3 나사 구멍 패드(GND)**에 고정.
* **[Step 1: 배터리 전능]**: 빨간 프로브로 배터리 왼쪽 관통 홀 측정 $\rightarrow$ **`3.6V ~ 4.2V` (실측 4.0V 확인, 합격)**.
* **[Step 2: 스위치 도통]**: 빨간 프로브로 우측 MCU 소켓 맨 위 구멍(Pad 1, `BAT`) 측정:
  * 스위치 OFF: `0V`
  * 스위치 ON: **`3.6V ~ 4.2V` (실측 4.0V 확인, 합격)**.
* **[Step 3: LDO 3.3V 변환]**: Beetle C6 모듈 장착 후, 좌측 MCU 소켓 2번 구멍(`3V3`) 또는 BH1750 소켓 맨 우측 구멍 측정 $\rightarrow$ **`3.3V ± 5%` (정상 레귤레이팅 합격)**.

---

## 6. Beetle ESP32-C6 온보드 충전 IC(TP4057) 및 LED 동작 분석

### 6.1 공식 회로도 분석 (DFR1117 Schematic Analysis)
* **충전 제어 IC**: TP4057 (SOT-23-6 패키지 리튬이온 충전 IC)
* **LED 연결**: `VUSB (5V)` $\rightarrow$ `LED4 (Green)` $\rightarrow$ 저항 `R18 (2.7kΩ)` $\rightarrow$ TP4057 1번 핀(`CHRG`)
* **충전 전류**: `R20 (2kΩ)`에 의해 약 **500mA**로 설정됨

### 6.2 충전 LED(초록불) 점등 상태 정의
| LED 상태 | 물리적 원인 | 실제 시스템 상태 |
| :---: | :--- | :--- |
| **초록불 점등 (ON)** | TP4057 Pin 1 내부 스위치가 GND로 도통 | **현재 배터리를 충전 중 (Charging)** |
| **초록불 소등 (OFF)** | 완충 전압(4.2V) 도달 및 충전 전류 C/10 이하 차단 | **충전 100% 완료 (Fully Charged)** |
| **초록불 깜빡임 (Blinking)** | 배터리 미연결 상태에서 C14 커패시터 발진 | 배터리 미연결 또는 스위치 OFF 상태로 USB 인가 |

> **판정 결론**:  
> "초록불 = 완충"이 아니라 **"초록불 = 충전 중, 불 꺼짐 = 완충"**입니다.  
> 4.0V 상태에서 충전을 시작하면 4.2V 만충 시점에 초록불이 저절로 꺼집니다.

---

## 7. 배터리 잔량 모니터링 솔루션 비교 및 로드맵

### 7.1 현재 기판(v9/v10)의 하드웨어적 한계
Beetle ESP32-C6 보드 및 캐리어 기판은 배터리 `BAT` 전압을 읽을 수 있는 ADC 분압 저항(Voltage Divider)이 내장되어 있지 않아, **하드웨어 추가 없이는 MCU 소프트웨어(`analogRead`)로 잔량을 직접 계측할 수 없음**이 확인되었습니다.

### 7.2 솔루션 비교표

| 구분 | 방법 1: 멀티미터 OCV 실측 | 방법 2: 분압 저항 ADC | 방법 3: I2C 게이지 모듈 |
| :--- | :---: | :---: | :---: |
| **방식** | 출발 전 배터리 단자 전압 계측 | 100kΩ 저항 2개로 1/2 분압 | MAX17043 I2C 센서 추가 |
| **하드웨어 추가** | **없음 (현재 상태 유지)** | 저항 2개 배선 필요 | 게이지 모듈 추가 |
| **정확도** | 물리적 전압 100% 실측 | 전압 측정 실시간 전송 | 전류 적산 기반 최고 정밀도 |
| **적용 시점** | **현재 실증 즉시 적용** | 차기 기판(v11 PCB) 아트워크 반영 | 차기 기판(v11 PCB) 검토 |

### 7.3 리튬 배터리 OCV(개방 전압) 기반 잔량 판정표
| 배터리 전압 | 잔량 (%) | 실증 가이드 |
| :---: | :--- | :--- |
| **4.18 ~ 4.20 V** | **100%** | 만충 상태 (초록색 충전 LED 소등 직후) |
| **3.95 ~ 4.05 V** | **약 80%** | 양호 상태 (당일 주행 실증 충분) |
| **3.80 ~ 3.85 V** | **약 50%** | 공칭 전압 (보관 적정 전압) |
| **3.65 V 이하** | **20% 이하** | 재충전 권장 시점 |
| **3.40 V 이하** | **0%** | 방전 위험 (즉시 실험 중단) |

---

## 8. 결론 및 향후 계획

1. **하드웨어 무결성 보존**: 현재 제작된 기판은 외부 저항을 무리하게 덧땜하지 않고 본연의 신뢰성과 내구성을 유지하며, 충전 완료 여부는 TP4057 LED 소등 및 멀티미터로 검증한다.
2. **차기 기판(v11) 설계 반영**: 차기 PCB 아트워크 설계 시 배터리 라인과 ESP32-C6 아날로그 핀 사이에 `100kΩ : 100kΩ` 분압 저항 패턴을 기본 탑재하여 클라우드 실시간 배터리 텔레메트리를 지원하도록 고도화한다.

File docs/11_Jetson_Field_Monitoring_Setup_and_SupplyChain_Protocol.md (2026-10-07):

# 11. 젯슨 나노 현장 관제 키오스크 설정 및 콜드체인 실증 프로토콜

> **문서 목적**: 본 문서는 실제 농가-산지유통센터(APC) 현장 및 차량 주행 실험 시, 스마트폰이나 노트북 조작 없이 **Jetson Nano와 외장 모니터**를 통해 실시간으로 센서 텔레메트리와 유통 이력을 관제할 수 있는 **스탠드얼론 키오스크(Kiosk) 구축 가이드**와 **하드웨어별(CarrierBoard / 자작 스캐너) 역할 및 데이터 연동 프로토콜**을 체계적으로 정리합니다.

---

## 📌 1. 전체 실험 파이프라인 및 하드웨어 역할 분담

본 플랫폼은 농가 수확(`A00`)부터 APC 처리(`A10`~`A14`), 최종 출하(`A15`)에 이르기까지 **3대 하드웨어 시스템**이 유기적으로 데이터를 상호 연동합니다.

```mermaid
sequenceDiagram
    autonumber
    actor 농민 as 🚜 1. 농가 (A00)
    participant Carrier as 📡 CarrierBoard (차량 탑재)
    participant Scanner as 🔨 자체 제작 QR 스캐너 (작업자)
    participant RDS as ☁️ AWS RDS DB (sensor_data / qr)
    participant Jetson as 📺 Jetson Nano (현장 모니터)

    농민->>RDS: 수확 정보 등록 (Lo='A00') 및 안심 QR 부착
    Note over Carrier: [농가 출발 시점] 상자와 함께 트럭 탑재 & 전원 ON
    Carrier->>RDS: A00 ➔ A10 주행 중 GPS, 3축 충격량, 온습도 실시간 전송 (5초 주기)
    Jetson->>RDS: [라이브 관제] A10 도착 전이라도 이동 경로·충격량 실시간 화면 표출!
    
    Note over Scanner: [APC 도착 시점] 작업자가 상자 QR 스캔 (A10)
    Scanner->>RDS: 최신 CarrierBoard 좌표(Lat, Lng)와 결합하여 A10 입고 확정 저장!
    Jetson->>RDS: 모니터 상의 타임라인이 A10(입고) 완료로 동기화 갱신!
```

### 3대 하드웨어의 명확한 역할 정의
1. **작업자 휴대 장비: [자체 제작 QR 스캐너](file:///c:/Users/korea/Desktop/1hsm/hanhanhan/ColdChain-DigitalTwin-Platform/Final_Experiment/2_ESP32_Firmware/src/main.cpp)**
   * **구성:** ESP32 + GM77 바코드 엔진 + 0.96인치 OLED + 택트 스위치
   * **역할:** 작업자가 상자 QR을 스캔하면 ESP32가 자체 Wi-Fi를 통해 AWS RDS `qr` 테이블에 직접 SQL INSERT 수행.
2. **차량 탑재 장비: [CarrierBoard 센서노드](file:///c:/Users/korea/Desktop/1hsm/hanhanhan/ColdChain-DigitalTwin-Platform/docs/07_CarrierBoard_Assembly_and_Diagnostic_Log.md)**
   * **구성:** DFRobot Beetle ESP32-C6 + MPU6050 + ATGM336H GPS + SHT30/45 + BH1750
   * **역할:** A00(농가) 상차 시점부터 A10(APC) 도착, 그리고 A15(최종 출하) 배송까지 차량의 이동 궤적, 속도, 과일 충격량(G-Force), 온·습도를 5초마다 실시간 MQTT 송출 및 내부 플래시(LittleFS) 블랙박스 영구 기록.
3. **현장/차량 관제소: [Jetson Nano + 모니터]**
   * **구성:** Jetson Nano (또는 Orin Nano) + HDMI 소형/대형 모니터
   * **역할:** 스마트폰 조작 없이 상시 켜져 있는 현장용 전체화면(Kiosk) 디스플레이. A00 출발 직후부터 차량 실시간 위치 지도, 충격 그래프, 상자 유통 이력을 원스톱 라이브 표출.

---

## 🔍 2. A00 ➔ A10 연동의 핵심 원리

### Q. "젯슨 나노에서는 A00부터 볼 수 없나요?"
* **A. 아닙니다! A00 출발 순간부터 라이브로 모두 볼 수 있습니다.**
  1. **농가 수확 정보 (`A00`)**: 농가에서 QR을 생성하는 순간(`Step1_Farm_QR_Creator.py`) 이미 AWS RDS DB에 `Lo='A00'`으로 저장되므로, 젯슨나노 화면에서 즉시 조회 가능합니다.
  2. **농가 ➔ APC 이동 중 (`A00 ➔ A10`)**: 트럭에 CarrierBoard를 싣고 출발하면 스마트 주행 감지 래치(`trip_active`)가 켜져 실시간 데이터를 전송하므로, **A10(APC)에 도착하기 전이라도 트럭의 실시간 위치와 충격량이 젯슨나노 모니터에 라이브로 표출**됩니다.
  3. **APC 도착 후 A10 스캔**: A10 스캔은 "모니터 화면을 처음 켜는 트리거"가 아니라, **"지금까지 실시간으로 수집된 운송 데이터와 상자 정보를 입고(A10) 확정 이력으로 결합하여 도장을 찍는 체크포인트"**입니다.

---

## 🚀 3. Jetson Nano 현장 관제 키오스크 상세 설정 가이드

### 3.1 소프트웨어 환경 설정 (터미널 작업)

Jetson Nano(Ubuntu) 터미널을 열고 순서대로 실행합니다:

```bash
# 1. 시스템 업데이트 및 전체화면용 Chromium 브라우저 설치
sudo apt update
sudo apt install -y chromium-browser

# 2. 프로젝트 리포지토리 폴더로 이동
cd ~/ColdChain-DigitalTwin-Platform

# 3. 필수 파이썬 라이브러리 설치
pip3 install streamlit pymysql paho-mqtt altair pandas folium streamlit-folium
```

---

### 3.2 수동 실행 및 테스트

#### 1) Streamlit 대시보드 백그라운드 구동 (젯슨 전용 스플릿 HUD 대시보드)
```bash
streamlit run Final_Experiment/4_APC_Coldchain_Dashboard/Step4_Jetson_SplitHUD.py \
  --server.port 8501 \
  --server.headless true \
  --browser.serverAddress localhost &
```

#### 2) 우분투 순정 브라우저(Epiphany) 실행
*(※ Snap 패키지 호환 문제가 없는 우분투 공식 Epiphany 브라우저 사용 권장)*
```bash
DISPLAY=:1 XAUTHORITY=/home/$USER/.Xauthority epiphany-browser http://localhost:8501 &
```
*(화면 번호가 `:0`인 경우 `DISPLAY=:0` 입력, `-a` 옵션 없이 URL 직접 입력)*
> **키오스크 조작 팁**:
> * 종료: 키보드의 `Alt + F4` 또는 터미널에서 `killall epiphany-browser`
> * 새로고침: `F5` 또는 `Ctrl + R`
> * **세션 선택 기능**: 상단 드롭다운에서 `🟢 실시간 주행` 및 과거 주행 기록(전주➔대전 등)을 자유롭게 전환하여 열람 가능하며, 과거 기록을 보는 중에도 우측 배지에 차량의 실시간 온·습도·충격 수치가 상시 표시됩니다.

---

### 3.3 차량 부팅 시 자동 실행(Autostart) 및 바탕화면 원클릭 아이콘 구축

젯슨 전원만 켜면 자동으로 모니터에 대시보드가 뜨거나, 바탕화면에서 아이콘을 더블클릭/터치하여 바로 실행할 수 있도록 통합 인스톨러가 제공됩니다.

#### 1) 통합 인스톨러 1회 실행
```bash
cd ~/ColdChain-DigitalTwin-Platform
bash scripts/install_jetson_autostart.sh
```

#### 2) 등록 결과 및 동작 방식
1. **바탕화면 바로가기 아이콘 생성**:
   * `[ColdChain HUD 실행]`: 클릭 시 이전 프로세스를 정리하고 Streamlit 서버와 Epiphany 브라우저를 한 번에 자동 구동합니다.
   * `[ColdChain HUD 종료]`: 클릭 시 대시보드와 브라우저를 안전하게 한 번에 종료합니다.
2. **부팅 시 자동 실행 (Autostart)**:
   * 젯슨 부팅 후 데스크톱 로그인 시 3초 후 자동으로 화면이 열립니다.
   * *(※ 완전 무인 자동 켜기를 원하실 경우: Ubuntu의 `Settings` ➔ `Users`에서 `Automatic Login`을 ON으로 설정하시면 전원만 켜도 바로 대시보드가 뜹니다.)*

#### 3) 자동 실행 해제 (필요 시)
```bash
bash scripts/uninstall_jetson_autostart.sh
```

---

## 💡 4. 현장 실험 운용 핵심 체크리스트

| 점검 항목 | 설정 권장값 | 이유 |
| :--- | :--- | :--- |
| **네트워크 핫스팟** | SSID: `hani` / 2.4GHz | CarrierBoard와 Jetson Nano가 동일 AP에 연결되어야 로컬/브로커 실시간 통신 원활 |
| **Jetson 전원 공급** | 시가잭 12V ➔ 5V 4A 강압 모듈 or 고용량 USB-PD | 전력 부족 시 CPU/GPU 쓰로틀링 및 브라우저 다운 현상 예방 |
| **모니터 절전 방지** | Settings ➔ Power ➔ `Screen Blank: Never` | 주행 중 모니터가 절전 모드로 꺼지는 현상 방지 |
| **현장 스캔 연동** | 자체 제작 QR 스캐너 휴대 | 현장에서 박스 스캔 즉시 젯슨 모니터에 0.1초 만에 반영 |

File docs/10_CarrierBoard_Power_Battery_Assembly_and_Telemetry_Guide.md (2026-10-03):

# 10. CarrierBoard 전원 시스템, 배터리 결선 및 대시보드 텔레메트리 가이드

**문서 번호**: CC-DOC-2026-10  
**작성 일자**: 2026-10-03  
**대상 하드웨어**: CarrierBoard Beetle ESP32-C6 EdgeUSB 50×50 (v9/v10)  
**대상 소프트웨어**: `Final_Experiment/4_APC_Coldchain_Dashboard/Step4_Run_Coldchain_v2.py`

---

## 1. 개요 및 요약

본 문서는 콜드체인 디지털 트윈 센서 노드(CarrierBoard Beetle ESP32-C6 50×50mm)의 **하드웨어 전원부(슬라이드 스위치 및 배터리) 조립, 트러블슈팅, 멀티미터 정밀 진단 과정, 실시간 대시보드 배터리 모니터링 위젯 구현 및 전력 소비 프로파일**을 총정리한 공식 엔지니어링 기록입니다.

---

## 2. 하드웨어 전원부 조립 및 결선

### 2.1 배터리 선정 및 사양 비교
* **현재 실장 배터리**: 18650 원통형 리튬이온 배터리 (Shenzhen Huayu, 3.7V / 8.14Wh $\approx$ 2,200mAh, 리드선 인출형)
* **추후 교체 예정 배터리**: 5000mAh 대용량 리튬 폴리머 파우치형 셀 (JRF PL105568, 3.7V / 18.5Wh)
* **선정 사유**: 18650 배터리는 금속 캔 외장으로 충격에 강하고 전선이 사전 인출되어 있어 납땜 작업 시 배터리 셀 열 손상이 없음.

### 2.2 기판 배터리 패드 핀아웃
기판 상단 스위치 좌측 하단의 2개 관통 홀(Through-Hole):
* **위쪽 홀 (`BAT+`)**: 배터리 빨간색 전선 (`+`) $\rightarrow$ 스위치 SW1 1번 핀으로 인입
* **아래쪽 홀 (`GND`)**: 배터리 검은색 전선 (`-`) $\rightarrow$ 기판 공통 접지 버스로 직결

### 2.3 스위치(SW1) 납땜 위기 해결 (패드 박리 복구)
* **현상**: SMD SPDT 슬라이드 스위치(PCM12) 가고정 작업 중 맨 오른쪽 패드(3번 핀)가 기판에서 탈락(Lifted Pad)됨.
* **회로 분석 및 검증**:
  * KiCad 회로망 분석 결과, 3번 핀은 `Net 0` 즉, 회로가 연결되지 않은 **더미 패드(NC: Not Connected)**임이 확인됨.
  * 실제 동작에 필요한 핀은 **1번 핀(`BAT+`)**과 **2번 핀(`BAT`, MCU 공급선)** 2개뿐임.
* **조치**: 3번 핀은 건너뛰고 1번과 2번 핀만 납땜하여 전기적 결선 완벽 복구. 스위치 몸체 우측 빈 공간에 글루건을 도포하여 기계적 고정 지지력 확보.

---

## 3. 멀티미터 단계별 전원 무결성 진단

| 점검 단계 | 측정 위치 | 정상 기준치 | 실측값 | 판정 |
| :--- | :--- | :---: | :---: | :---: |
| **Step 1 (배터리 전능)** | 배터리 빨간선(+) ↔ 검은선(-) 구멍 | 3.6 ~ 4.2V | **4.0 V** | ✅ 정상 완충 |
| **Step 2-A (스위치 인입)** | 스위치 가운데 핀(`BAT+`) ↔ GND | 3.6 ~ 4.2V | **4.0 V** | ✅ 패턴 정상 |
| **Step 2-B (스위치 도통)** | 스위치 맨 위 핀(`BAT`) ↔ GND (SW ON) | 3.6 ~ 4.2V | **4.0 V** | ✅ 스위치 정상 |
| **Step 3-A (MCU 공급)** | Beetle 좌측 Pin 1(`BAT`) ↔ GND | 3.6 ~ 4.2V | **4.0 V** | ✅ MCU 인입 정상 |
| **Step 3-B (접지 폐루프)** | Beetle 좌측 Pin 1(`BAT`) ↔ Pin 2(`GND`) | 3.6 ~ 4.2V | **4.0 V** | ✅ 접지 통전 정상 |
| **Step 3-C (LDO 출력)** | Beetle 우측 Pin 2(`3V3`) ↔ GND | 3.3V ± 5% | **3.3 V** | ✅ 전원 변환 완료 |

> **검증 결론**: 배터리 전원만으로 ESP32-C6 LDO 레귤레이터가 3.3V를 정상 출력하여 MCU와 센서 4종(MPU6050, GPS, BH1750, SHT45)의 전원 LED가 모두 정상 점등됨.

---

## 4. 단독 ESP32-C6 진단 결과 (COM17)

* **칩셋**: ESP32-C6FH4 (QFN32, Silicon Rev v0.1)
* **내장 플래시**: 4MB Embedded Flash (Vendor: 0x20, Device: 0x4016)
* **MAC 주소**: `F0:F5:BD:2C:48:5C`
* **무선 기능**: Wi-Fi 6, Bluetooth 5 (LE), IEEE 802.15.4 (Zigbee/Thread)
* **동작 상태**: 부팅 후 Wi-Fi 자동 연결(`WiFi Connected!`) 정상 동작 확인

---

## 5. 다중 복합 이상 이벤트 감지 및 DB 실시간 저장 파이프라인

* **대상 파일**: `Final_Experiment/4_APC_Coldchain_Dashboard/Step4_Run_Coldchain_v2.py`
* **배터리 사이드바 정책**: 추정 방식의 부정확성 및 PCB 무결성(외부 저항 덧땜 방지)을 고려하여 사이드바 배터리 카드는 깔끔하게 배제하고 하드웨어 본연의 상태로 복원.
* **다중 복합 이벤트 감지 로직**:
  1. **충격 발생**: $g\_force \ge 1.8\text{ G}$
  2. **조도 급변**: $|\Delta \text{Lux}| \ge 300\text{ lx}$ (탑차 도어 개방 / 직사광선 유입)
  3. **온도 급변**: $|\Delta \text{Temp}| \ge 2.0^\circ\text{C}$ (냉각기 이상 / 외부 열기 유입)
  4. **동시 발생 결합 (Multi-Event Combination)**:
     - 2개 이상 동시 발생 시 구분자(` | `)로 결합하여 하나의 상태로 기록:  
       예) `🚨 충격(2.10G) | 💡 조도급변(+520lx) | 🌡️ 온도급변(+3.2°C)`
  5. **DB 긴급 저장 트리거 (Real-time DB Trigger)**:
     - 이상 이벤트(충격, 조도급변, 온도급변) 발생 시 10초 주기를 기다리지 않고 **즉시 MySQL DB에 긴급 저장** 수행.
     - 하단 실시간 로그 테이블 및 Pydeck 지도 이벤트 마커와 완벽하게 동기화.

---

## 6. 전력 소비 프로파일 및 배터리 수명 분석

### 6.1 부품별 전류 소모 내역 (Full Active 모드)
* **Beetle ESP32-C6**: 약 40 mA (160MHz + 5초 주기 Wi-Fi MQTT 전송)
* **ATGM336H GPS**: 약 28 mA (위성 상시 추적 및 항법)
* **GY-521 (MPU6050)**: 약 6 mA (6축 측정 + 온보드 LED)
* **BH1750 & SHT45**: 약 0.6 mA (I2C 측정)
* **총 시스템 평균 소비 전류**: **약 75 ~ 85 mA**

### 6.2 배터리별 연속 가동 시간 비교
| 구분 | 18650 배터리 (현재 실장) | 5,000mAh 파우치 배터리 (교체 예정) |
| :--- | :---: | :---: |
| **공칭 용량** | 2,200 mAh | 5,000 mAh |
| **유효 가용 용량 (85%)** | 약 1,870 mAh | 약 4,250 mAh |
| **만충 시 연속 가동 시간** | **약 22 ~ 24 시간 (만 하루)** | **약 50 ~ 55 시간 (2박 3일 이상)** |
| **활용 범위** | 당일 주행 실증, 캠퍼스 및 시내 테스트 | 장거리 전국 수송, 제주 선박 운송 등 장기 실증 |

---

---

## 7. GPS 수신(Fix) 기반 스마트 자동 DB 저장 (Smart Auto-Save)

* **도입 배경**:
  - 연구실 실내에서 센서 작동 시험(충격, 조도, 온도 변화)을 할 때 테스트 데이터가 DB에 무분별하게 적재되는 것을 차단.
  - 동시에, 사용자가 센서 노드만 들고 야외나 차량으로 나갔을 때 매번 대시보드를 켜서 수동으로 토글을 조작해야 하는 번거로움을 해결.
* **핵심 판정 로직**:
  - **스마트 자동 모드 (기본값)**: `lat != 0.0 and lng != 0.0` (GPS Fix 수신 완료)
  - **실내/연구실 (GPS 미수신)**: 아무리 센서를 흔들거나(충격) 조명/온도를 바꿔도 **DB 저장 차단 (화면 모니터링만 수행)**.
  - **야외/차량 (GPS Fix 수신)**: 사용자가 대시보드에 손대지 않아도 **자동으로 DB 실시간 저장 활성화** (10초 주기 또는 복합 이상 이벤트 시 즉시 저장).
* **사이드바 UI 3단계 옵션**:
  1. `🤖 스마트 자동 (GPS 수신 시 자동 저장)`: 기본값 / 권장 모드
  2. `🔴 항상 저장 (수동 강제 저장)`: GPS 수신 여부 무관 상시 DB 기록
  3. `⚪ 저장 안함 (연구실 모니터링)`: DB 저장 완전 차단

---

## 8. Beetle C6 LittleFS 블랙박스 상태 점검 및 관리 가이드

외부 차량 실험 출발 전 MCU 플래시 메모리(LittleFS)의 잔여 용량과 저장 상태를 확인하고 필요 시 깨끗하게 비우는 방법입니다.

### 8.1 원클릭 관리 도구 (`scratch/manage_littlefs.py`)
PC 터미널에서 다음 명령어를 실행하면 직관적인 대화형 메뉴로 즉시 점검 및 초기화가 가능합니다:
```bash
python scratch/manage_littlefs.py
```
* **[1] 상태 확인 (`info`)**: 현재 LittleFS 전체 용량(약 1.4MB), 사용 중인 바이트, 누적 레코드 개수 확인.
* **[2] 0건 완전 비우기 (`clear`)**: 기존 블랙박스 파일(`/telemetry_log.jsonl`) 및 오프라인 버퍼를 완전히 삭제하여 0건 초기화.
* **[3] 데이터 백업 (`dump`)**: 보드에 남아 있는 데이터를 PC의 JSONL 파일로 즉시 다운로드 백업.

### 8.2 시리얼 모니터 직접 제어 (115200 bps)
아두이노 IDE 또는 시리얼 터미널(COM17)에서 명령어를 입력하여 제어할 수도 있습니다:
* `info` 또는 `stat`: 저장 용량 및 누적 건수 출력
* `clear` 또는 `reset`: 블랙박스 및 오프라인 버퍼 삭제 후 0건 초기화
* `dump` 또는 `read`: 플래시 메모리 전체 패킷 시리얼 출력

### 8.3 오프라인 버퍼의 자동 소멸 안전장치
* 차량 주행 중 핫스팟/Wi-Fi 연결이 두절되면 펌웨어가 `/offline_buf.jsonl`에 패킷을 임시 큐잉합니다.
* 이후 핫스팟에 재연결되면 `flushOfflineBuffer()`가 실행되어 누적 패킷을 브로커로 일괄 전송한 후 **버퍼 파일을 스스로 자동 삭제(remove)**합니다.
* 1MB 용량은 약 4,000 ~ 5,000건(5초 주기 기록 시 약 6 ~ 7시간 분량)을 수용할 수 있으므로, 출발 전 `clear` 한 번만 해주면 장거리 실험도 매우 안전합니다.

---

## 9. 향후 권장 사항
1. **PCB 미관 및 내구성 유지**: 외부 저항을 추가 배선하지 않고 완제품 PCB 본연의 신뢰성과 미관을 유지함.
2. **글루건 보강**: 배터리 홀 납땜부 및 스위치 본체 측면에 글루건을 도포하여 와이어 꺾임 단선 및 패드 뜯김 완전 방지.

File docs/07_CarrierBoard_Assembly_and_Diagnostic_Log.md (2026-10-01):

# 07. CarrierBoard Beetle ESP32-C6 조립 및 1차 진단 분석 보고서

**작업 일시:** 2026-09-30  
**작업 대상:** CarrierBoard_BeetleC6_EdgeUSB_50x50 (DeviceMart 발주 PCB)  
**핵심 장치:** DFRobot Beetle ESP32-C6 Mini MCU (DFR1117, RISC-V)  
**연동 센서:** SHT45 (온습도), GY-521/MPU6050 (6축 IMU), BH1750 (조도), ATGM336H (GPS)  

---

## 1. 하드웨어 조립 및 초기 안전 점검 경과

### 1) 기판 조립 및 소켓 납땜
- **실장 방식:** 2.54mm 암형 핀헤더 소켓(Female Header Socket)을 통한 모듈 탈부착 구조
- **실장면 구분:**
  - **Top (전면):** Beetle ESP32-C6 Mini (1×8 소켓 2열), BH1750 조도 센서 (1×5 소켓)
  - **Bottom (후면):** SHT45 온습도 센서 (1×5 소켓), GY-521 IMU (1×8 소켓), ATGM336H GPS (1×5 소켓)
- **납땜 점검:** 모든 소켓 핀 납땜 완료 및 냉납/브릿지 육안 검사 완료

### 2) 전원 공급 및 도통 테스트 (Continuity Test) — PASS
- **쇼트 방지 검사:** 조립 전 멀티미터를 통한 3.3V 전원선과 GND 간 단락 검사 결과 쇼트 없음 확인 (무한대 저항)
- **전원 인가 측정:** Beetle C6에 USB-C 전원을 연결한 상태에서 각 센서 소켓의 VCC/3V3 핀 전압 측정 결과 **정상 3.3V 인입 확인**
- **I2C 풀업 저항 (R3, R4) 생략 근거:**  
  각 센서 모듈(SHT45, GY-521, BH1750) 내부 회로에 이미 4.7kΩ ~ 10kΩ 풀업 저항이 온보드 실장되어 있으므로 외장 SMD 0603 저항을 납땜하지 않아도 I2C 통신 가능 확인.
- **전원 스위치 (SW1) 생략 근거:**  
  SW1은 배터리(JST-PH) 전원 라인 전용이므로, 현재 USB-C 직결 전원 공급 시 납땜 없이 안전하게 바이패스 운용 가능.

---

## 2. PlatformIO 환경 구축 및 빌드/업로드 해결

### 1) 당면했던 문제
- **오류 메시지:**
  ```text
  Error: Failed to install Python dependencies into penv
  Error: This board doesn't support arduino framework!
  riscv32-esp-elf-g++: fatal error: cannot execute 'cc1plus': CreateProcess: No such file or directory
  ```
- **원인:**
  1. 공식 PlatformIO의 기본 `espressif32` 플랫폼은 Arduino Core 2.x 기반으로 신형 RISC-V 칩셋인 ESP32-C6의 Arduino Framework를 지원하지 않음.
  2. 로컬 환경에 캐시되어 있던 구버전 `toolchain-riscv32-esp` 내부의 C++ 전처리기(`cc1plus.exe`) 파일 누락/손상.

### 2) 해결 조치
- **플랫폼 변경:** ESP32-C6 Arduino Core 3.0.4를 완벽 지원하는 `pioarduino v51.03.04`로 교체:
  ```ini
  [env:beetle_c6_diagnostic]
  platform = https://github.com/pioarduino/platform-espressif32/releases/download/51.03.04/platform-espressif32.zip
  board = esp32-c6-devkitm-1
  framework = arduino
  monitor_speed = 115200
  upload_port = COM37
  monitor_port = COM37
  build_flags =
    -DARDUINO_USB_MODE=1
    -DARDUINO_USB_CDC_ON_BOOT=1
  lib_deps =
    BH1750
    adafruit/Adafruit MPU6050@^2.0.0
    mikalhart/TinyGPSPlus@^1.0.1
    sensirion/arduino-sht@^1.0.0
  build_src_filter = -<*> +<carrier_board_diagnostic.cpp>
  ```
- **손상 툴체인 복구:** 손상된 로컬 툴체인 디렉터리를 초기화하여 Espressif 공식 검증 툴체인 자동 재다운로드 수행.
- **결과:** **100% 빌드 성공 (SUCCESS)** 및 Beetle ESP32-C6(COM37)에 펌웨어 업로드 완료.

---

## 3. 실시간 진단 테스트 및 핵심 원인 분석 (Root Cause Analysis)

### 1) 진단 펌웨어 구동 증상
```text
🔍 [1] I2C 버스 스캔 시작 (SDA: GPIO 19, SCL: GPIO 20)
-------------------------------------------
  ❌ I2C 장치를 하나도 찾지 못했습니다! (소켓 체결 상태 확인 필요)
-------------------------------------------
📦 [2] BH1750 조도 센서 초기화... ❌ 실패
📦 [3] SHT45 온습도 센서 초기화... ❌ 실패
📦 [4] GY-521 (MPU6050) 6축 IMU 초기화... ❌ 실패
📦 [5] GPS ATGM336H UART 포트 열기 (RX:16, TX:17)... ✅ 포트 오픈 완료
```

### 2) 기판-모듈 간 회로 정밀 대조 결과
사용자 촬영 실물 사진과 KiCad 정밀 배선 데이터를 분석한 결과:

1. **SHT45 (온습도 센서): 180도 반대 체결 확인**
   - **소켓 배선 (좌 $\rightarrow$ 우):** `[1: SDA, 2: SCL, 3: GND, 4: 3V3, 5: 3V3]`
   - **실제 모듈 삽입 상태:** `VIN`이 왼쪽 끝(1번)으로 꽂혀 있음.
   - **문제:** 모듈의 전원(`VIN`)이 ESP32의 I2C `SDA` 신호선에 꽂혀 전원이 들어가지 않고, 내부 보호 다이오드가 `SDA` 전압을 0V(GND)로 클램핑하여 **전체 I2C 버스를 완전 마비**시킴.

2. **GY-521 (MPU6050 IMU 센서): 180도 반대 체결 확인**
   - **소켓 배선 (좌 $\rightarrow$ 우):** `[1: GND, ..., 5: SDA, 6: SCL, 7: GND, 8: 3V3]`
   - **실제 모듈 삽입 상태:** `VCC`가 왼쪽 끝(1번)으로 꽂혀 있음.
   - **문제:** `VCC`가 소켓의 GND에 인입되고, `INT` 핀에 3.3V가 인입되어 역방향 바이어스 발생.

3. **BH1750 (조도 센서): 180도 반대 체결 확인**
   - **소켓 배선 (좌 $\rightarrow$ 우):** `[1: GND, 2: SDA, 3: SCL, 4: GND, 5: 3V3]`
   - **실제 모듈 삽입 상태:** `VCC`가 왼쪽 끝(1번)으로 꽂혀 있음.
   - **문제:** `VCC`가 소켓의 GND에 인입되고, `ADDR` 핀에 3.3V가 인입됨.

4. **GPS (ATGM336H):**
   - 모듈 방향은 정상(`VCC`가 1번 3.3V에 인입).
   - 단, 4번 핀(GPS RX)에 Beetle C6의 5V(VIN)이 인입되는 배선 특성이 있으므로, GPS는 RX 핀을 띄우고(미연결) TX 핀만으로도 자동 NMEA 수신 가능.

---

## 5. 2차 실시간 진단 및 센서 전원/I2C 통신 100% 정상화 검증 (2026-10-01 완료)

### 1) 진단 및 디버깅 경과
- **실시간 GPIO 로직 레벨 모니터링 펌웨어 구축:**  
  초당 I2C 버스의 SDA(GPIO 19) 및 SCL(GPIO 20) 전압 레벨을 모니터링하여 I2C 락/쇼트 상태를 실시간 진단하는 펌웨어를 작성 및 배포.
- **SCL 라인 정상 확인:** 모듈 회전 체결 후 SCL(GPIO 20) 라인은 `HIGH(정상, 1)`로 완전히 살아남 확인.
- **SDA 라인 격리 테스트 (Isolation Test):**
  1. `SHT45 (온습도)` 분리 시: SDA 여전히 LOW (SHT45는 정상이었음)
  2. `BH1750 (조도)` 분리 시: **SDA가 즉시 HIGH(정상, 1)로 반전되며 I2C 버스 100% 복구!**
  3. `[0x44] (SHT45)`, `[0x68] (MPU6050)` 주소 즉시 응답 및 데이터 스트리밍 시작.
- **BH1750 원인 규명 및 조치:**
  - BH1750 모듈의 2번 핀(GND)이 캐리어 보드 소켓의 2번 핀(SDA)과 맞물려 버스 전체를 0V로 접지시키고 있었음.
  - BH1750 모듈을 180도 회전(파란색 뒷면 기판이 위를 보도록) 장착하여 VCC->3.3V, GND->GND, SCL->SCL, SDA->SDA, ADDR->GND로 완전 정합 완료.

### 2) 최종 실시간 센서 측정 결과 (COM37 Live Stream)
```text
------------------------------------------------------------------
[실시간 진단] SDA(GPIO 19): HIGH(정상) (1) | SCL(GPIO 20): HIGH(정상) (1)
  >> I2C 스캔 결과: [0x23] [0x44] [0x68] (총 3개 장치 100% 감지 완료!)
  🌡️  [SHT45 온습도]   온도: 27.2 °C  |  습도: 43.3 %
  💡 [BH1750 조도]     밝기: 2.5 ~ 3.3 Lux (실시간 조도 반응 정상)
  🧭 [MPU6050 IMU]     합성 가속도: 1.04 G (지구 중력가속도 1.0G와 완벽 일치!)
  🛰️  [GPS ATGM336H]   UART 포트 오픈 및 NMEA 수신 동작 중
------------------------------------------------------------------
```

### 3) 결론 및 의의
1. **PCB 하드웨어 검증 완료:**  
   자체 설계/발주한 `CarrierBoard_BeetleC6_EdgeUSB_50x50` 기판의 전원 라인(3.3V/GND), I2C 신호 배선, DFRobot Beetle ESP32-C6 Mini MCU 간의 물리적/전기적 정합성이 100% 검증됨.
2. **콜드체인 디지털 트윈 핵심 센서 3종 완벽 구동:**  
   - 온도/습도 정밀 계측 (의약품/백신 보관 규정 감시)
   - 조도 계측 (의약품 박스/냉장고 개폐 및 누광 감지)
   - 6축 가속도 계측 (수송 중 충격, 진동, 차량 기울기 감지)
3. **다음 개발 마일스톤:**  
   - ESP32-C6 Wi-Fi 6 무선 통신 활성화 (완료)
   - AWS / MQTT 브로커 연동을 통한 클라우드 실시간 텔레메트리 전송 (완료)
   - 백엔드 시계열 DB 및 디지털 트윈 프론트엔드 연동 실증 (완료)

---

## 6. Wi-Fi Multi 및 MQTT 실시간 텔레메트리 연동 완료 (2026-10-01)

### 1) 펌웨어 구현 및 배포 (`carrier_board_mqtt.cpp`)
- **Wi-Fi Multi 연결:** 복수 AP 자동 탐색 및 연결 지원
- **NTP 시각 동기화:** 한국 표준시(KST, UTC+9) 기준 밀리초 단위 타임스탬프 생성
- **센서 텔레메트리 통합:**
  - SHT45 (온도/습도)
  - BH1750 (조도)
  - MPU6050 (충격량 및 합성 G-Force 계산)
  - ATGM336H GPS (위도/경도/속도)
- **MQTT 스트리밍:** `broker.emqx.io:1883`, 토픽 `coldchain/truck01/sensor` 로 JSON 텔레메트리 패킷 주기적 발행 (5초 주기 및 충격 시 즉시 전송)

### 2) Streamlit 모니터링 대시보드 연동 및 안정화
- **실시간 KPI 카드:** 온도, 습도, 조도, 충격량, 속도 실시간 갱신 정상 동작
- **타임스탬프 예외 방어 패치:**
  - 초기 부팅 및 미동기화 상태의 `"00:00:00"` 타임스탬프 발생 시 `errors='coerce', format='mixed'` 안전 파싱 및 자동 결측치 보정 로직 적용
  - Altair 시계열 차트 렌더링 루프 전체에 `try-except` 보호 블록 적용하여 대시보드 중단 방지

---

## 7. GPS(ATGM336H) 하드웨어 체결 방향 정상화 및 전 센서 100% 통합 검증 (2026-10-01 완료)

### 1) 당면 문제 및 원인 분석
- **증상:** 보조배터리로 야외 연결 시 GPS 위치가 잡히지 않고, 시리얼 진단 시 수신 바이트가 지속적으로 0바이트로 기록됨.
- **원인 (Root Cause):**
  - PCB 바텀 레이어에 실장된 `J_GPS` 암형 소켓의 핀맵은 `[1: 3.3V (우측), 2: GND, 3: GPS_TX(GPIO 16), 4: GPS_RX(GPIO 17), 5: NC(좌측)]`으로 설계됨.
  - ATGM336H 모듈의 소자면(배터리/칩셋)이 앞을 향하도록 꽂을 경우, 모듈의 1번(VCC) 핀이 소켓의 5번(NC)에 맞물려 **모듈에 전원이 0V(미인가) 상태**로 유지되었음.

### 2) 조치 및 해결
- **모듈 180도 회전 체결:**  
  ATGM336H 모듈을 소켓에서 분리 후 180도 회전하여 **뒷면(실크스크린 라벨 인쇄면)이 위를 향하도록 체결**.
  - 모듈 VCC $\rightarrow$ 소켓 3.3V (Pad 1) 인가
  - 모듈 GND $\rightarrow$ 소켓 GND (Pad 2) 체결
  - 모듈 TXD $\rightarrow$ ESP32 GPIO 16 (UART RX) 직결
  - 모듈 RXD $\rightarrow$ ESP32 GPIO 17 (UART TX) 직결
  - 모듈 PPS $\rightarrow$ NC (미연결)

### 3) 최종 검증 결과
- **하드웨어:** 모듈 체결 즉시 전원 LED 점등 및 UART NMEA 스트리밍 시작 (초당 ~276바이트 수신).
- **MQTT 라이브 텔레메트리 스트리밍 (COM37 -> broker.emqx.io):**
  ```json
  {
    "device": "carrier-c6-01",
    "timestamp_str": "2026-10-01 15:48:08",
    "temperature": 25.05,
    "humidity": 36.61,
    "lux": 5.0,
    "g_force": 1.04,
    "lat": 0.000000,
    "lng": 0.000000,
    "speed": 0.0,
    "sats": 0,
    "status": "정상, GPS: Searching (0 sats)"
  }
  ```
- **의의:**  
  이로써 자체 제작한 캐리어 보드(CarrierBoard_BeetleC6_EdgeUSB_50x50)에 탑재된 **온습도(SHT45), 조도(BH1750), 6축 가속도/충격(MPU6050), 위치 추적(ATGM336H GPS)의 4개 센서가 100% 정상 작동 및 MQTT 클라우드 실시간 스트리밍 체계를 완벽하게 완성**함.

---

## 8. 야외 실측 테스트 및 GPS 위치 동기화 검증 성공 (2026-10-01)

### 1) 야외 보조배터리 단독 구동 실증
- **환경:** PC 연결 해제 후 보조배터리 전원 직결, 야외 이동 테스트 수행.
- **네트워크 연동:** 스마트폰 모바일 핫스팟(`hani`) 자동 접속 및 MQTT 브로커 스트리밍 유지.
- **실측 위치 락(Fix):** 
  - 세라믹 패치 안테나 상공 지향 후 약 2분 내 위성 동기화 성공.
  - 모듈 본체 PPS LED 1Hz 정상 점멸 확인.
- **AWS RDS 실측 저장 레코드 (ID 747 - KST 16:48:26):**
  - **위치 좌표:** 위도 `35.8486°N`, 경도 `127.1350°E` (전북 전주시 일대 정밀 매핑)
  - **환경 데이터:** 기온 `21.2°C`, 습도 `33.3%`, 조도 `2,641 Lux` (야외 자연광 감지)
  - **동적 가속도:** `1.92 G`

---

## 9. APC 통합 관제 대시보드(Streamlit Cloud) 사이드바 고도화 (2026-10-01)

### 1) 주요 개선 사항
- **실시간 통신 상태 인디케이터(Health Card) 신설:**
  - 사이드바 상단에 수신 단말(`carrier-c6-01`), GPS Fix 상태, 최근 패킷 수신 시각, 현재 세션 수집 건수를 실시간 갱신 표출.
- **버튼 UI 가독성 최적화:**
  - 좁은 2열 분할을 폐지하고 1열 풀위드(Full-width) 배치로 버튼 글자 잘림(`🚀 새 실험 ...`) 문제 100% 해소.
  - 임의 텍스트 미입력 시에도 타임스탬프 기반 자동 세션(`run_YYYYMMDD_HHMMSS`) 생성 지원.
- **연구/논문용 실험 데이터 CSV 추출 기능 추가:**
  - 과거 주행 세션 선택 시 해당 세션의 전체 센서 시계열 데이터를 원클릭으로 엑셀/CSV 다운로드 지원.

---

## 10. AWS 클라우드 인프라 건전성 및 요금 분석 (2026-10-01)

### 1) AWS RDS 인스턴스 현황
- **엔드포인트:** `labdb.cn26yq6q0mu6.ap-northeast-2.rds.amazonaws.com:3306` (서울 리전)
- **엔진 사양:** MySQL 8.4.8 (AWS Managed RDS), `db.t3.micro` (1 vCPU, 1 GiB RAM)
- **총 데이터 누적량:** 5,700+ 건 (실제 데이터 용량: `0.72 MB`)
  - `gps_log`: 3,260건
  - `sensor_logs`: 1,114건
  - `sensor_data`: 747건
  - `warehouse_env`: 557건
  - `qr`: 22건 (A00~A15 전 단계 완비)

### 2) 클라우드 요금 구조
- **청구 항목:** 유일하게 `AWS RDS MySQL` 1개 인스턴스만 과금 대상. (MQTT는 무료 공용 EMQX 브로커, 대시보드는 무료 Streamlit Cloud 호스팅 활용으로 AWS 추가 비용 0원).
- **비용 수준:** 프리티어 적용 시 **0원 (무료)**, 유료 계정 전환 시에도 월 약 **2.5만 ~ 3만원 내외**로 가장 경제적인 수준 유지 확인.

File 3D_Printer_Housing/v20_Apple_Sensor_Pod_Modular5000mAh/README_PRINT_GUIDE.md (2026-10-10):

# Sindoh 3DWOX 2X - Apple Digital Twin Pod v20 슬라이싱 & 출력 가이드

본 문서는 **Sindoh 3DWOX 2X (단일 PLA 노즐, 서포트 전용 재료 없음)** 환경에서 `v20_Apple_Sensor_Pod_Modular5000mAh` 하우징을 실패 없이 완벽하게 출력하기 위한 공식 슬라이서 설정 매뉴얼입니다.

---

## 1. 부품별 출력 방향 (Orientation)

| 부품 파일명 | 권장 배치 방향 | 베드 접촉 면적 | 서포트 필요 여부 |
| :--- | :--- | :---: | :---: |
| `20_apple_rear_shell.stl` | **결합면(Rim) 바닥 안착 ($Z=0$), 돔이 위로 향함** | $1,533.0\text{ mm}^2$ | 내부 배터리선반 하단만 필요 (외벽은 0%) |
| `20_apple_front_shell.stl` | **결합면(Rim) 바닥 안착 ($Z=0$), 돔이 위로 향함** | $1,480.0\text{ mm}^2$ | 서포트 0% 불필요 (100% 자립) |
| `20_apple_battery_tray.stl`| **플레이트 후면 바닥 안착 ($Z=0$), 기둥이 위로 향함** | $1,250.0\text{ mm}^2$ | 서포트 0% 불필요 (100% 자립) |
| `20_apple_stem.stl` | **플러그 밑둥 바닥 안착 ($Z=0$), 꼭지가 위로 향함** | $78.5\text{ mm}^2$ | 브림(Brim) 권장, 서포트 불필요 |

> **주의: 180° 뒤집어서 출력하지 마십시오.**  
> 구형 외벽이 바닥에 닿으면 접촉 면적이 점($\approx 0\text{ mm}^2$)이 되고 $84^\circ$ 오버행이 발생하여 출력이 100% 실패합니다. 기본 로딩 방향을 유지하십시오.

---

## 2. 신도리코 3DWOX Desktop 고급 서포트 세팅 (자국 없는 Easy-Peel)

서포트 떼어내기를 쉽게 하고 접촉면 흉터를 방지하기 위한 핵심 파라미터입니다.

### [서포트] 탭 설정값
* **생성 위치**: `모든 곳` (내부 배터리 수납부 완벽 지지)
* **서포트 구조**: `선형 구조 (Lines)` (부챗살처럼 한 번에 쭉 뜯김)
* **채우기 밀도 (%)**: `12%` ~ `15%` (힘들이지 않고 바스락 부서지는 강도)
* **서포트 생성 각도 (도)**: `60°` (사과 외벽 경사는 최대 $47.9^\circ$이므로 **외벽에는 서포트가 0개 생성됨**)
* **수평방향 확장 (mm)**: `0.0 mm` (주변 벽 및 나사홀 간섭 방지)
* **X/Y 방향 간격 (mm)**: `0.80 mm` (옆벽 융착 방지)
* **Z 방향 간격 (mm)**: `0.22 mm` (1개 층 공기층 형성으로 툭 치면 분리)
* **★ 서포트 인터페이스**: **[ V ] 체크 (반드시 켜기!)**
  * **인터페이스 패턴**: `선형 구조`
  * **인터페이스 상단 레이어 수**: `3` (두께 0.6mm의 팽팽한 장판 형성으로 처짐 0%, 매끄러운 바닥면 보장)

---

## 3. 베드 안착 및 첫 레이어 실패 방지 세팅 (중요)

첫 레이어 선형 구조의 끝단이 턴(U-Turn)할 때 들뜨거나 뭉치는 현상을 방지하는 조치입니다.

### [베드 고정] 탭
* **고정 타입**: **`브림 (Brim)`**
* **브림 폭**: `3.0 mm` ~ `4.0 mm` (약 8~10라인)
  * 브림이 서포트의 뾰족한 끝단들을 둥근 테두리로 꽉 눌러주어 말려 올라가지 않습니다.

### 온도 및 속도 권장값
* **노즐 온도**: `205°C` ~ `210°C` (첫 레이어 접착력 강화)
* **베드 온도**: `60°C`
* **첫 레이어 속도**: `20 mm/s` (천천히 눌러 담기)
* **일반 출력 속도**: `40 mm/s` ~ `50 mm/s`
* **인필 (Infill)**: `15%` ~ `20%` (Gyroid 또는 Grid)

---

## 4. 베드 관리 & 출력 후 후가공

1. **베드 탈지 & 풀칠**:
   - 출력 전 베드를 알코올 솜 또는 물티슈로 닦아 유분기를 제거합니다.
   - 출력 영역에 문구용 **딱풀(Glue Stick)**을 얇게 1~2회 도포하면 들뜸이 완전히 방지됩니다.
2. **서포트 제거**:
   - 부품 입구가 100mm로 넓게 열려 있으므로, 롱노즈 플라이어로 서포트 모서리를 잡고 살짝 비틀어 당기면 상단 인터페이스 덮개와 함께 깔끔하게 뜯겨 나옵니다.

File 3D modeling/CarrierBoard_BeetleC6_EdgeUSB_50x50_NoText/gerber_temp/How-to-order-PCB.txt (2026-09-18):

=============================================================
JLCPCB Production Gerber Package v10 (DRC Zero-Error Certified)
Board Name: CarrierBoard Beetle ESP32-C6 EdgeUSB (50x50mm, NoText Edition)
Release Date: 2026-09-18
KiCad Version: KiCad 10.0.4

[JLCPCB Quotation / Order Parameter Guide]
-------------------------------------------------------------
1. PCB Dimensions: 50.0 mm x 50.0 mm
2. PCB Qty: 5 pcs (or desired quantity)
3. Layer Count: 2 Layers
4. Base Material: FR-4
5. Board Thickness: 1.6 mm
6. Copper Weight: 1 oz (Outer layer)
7. Solder Mask: Matte Black or Green (Recommended: Black / Green)
8. Silkscreen: White (Minimalistic NoText outline aesthetic)
9. Surface Finish: HASL with lead (Economical) or LeadFree HASL / ENIG (Gold)
10. Remove Order Number: Specify location or "Yes" (Recommended to preserve clean look)
11. Min Hole Size / Min Track: Standard (0.4mm drill / 0.35mm trace)
12. PCB Assembly: NO (Choose "PCB Only", all modules and headers are socketed/hand-soldered)

[Included Layers]
- Gerber_TopCopperLayer.GTL        (Front Copper / 3V3 Power Rail & Signals)
- Gerber_BottomCopperLayer.GBL     (Back Copper / I2C SDA & SCL & UART & GND)
- Gerber_TopSilkscreenLayer.GTO    (Front Silkscreen / Component Placement Outlines)
- Gerber_BottomSilkscreenLayer.GBO (Back Silkscreen / Sensor Outlines)
- Gerber_TopSolderMaskLayer.GTS    (Front Solder Mask)
- Gerber_BottomSolderMaskLayer.GBS (Back Solder Mask)
- Gerber_BoardOutlineLayer.GKO     (Edge Cuts / 50x50mm Chamfered Profile)
- Gerber_Drill.DRL                 (Plated Through Holes, Vias & M3 Mounts)

[DRC Certification]
- Short Circuits: 0 (PASSED)
- Clearance Violations: 0 (PASSED)
- Unconnected Items: 0 (PASSED)
=============================================================

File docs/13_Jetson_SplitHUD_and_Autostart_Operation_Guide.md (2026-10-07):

# 🚚 젯슨(Jetson) 전용 2분할 스플릿 HUD 및 부팅 자동 실행 가이드

> **문서 버전**: v1.0 (2026-10-07)  
> **적용 장비**: NVIDIA Jetson Orin Nano (Ubuntu 22.04 LTS, GDM3/GNOME)  
> **대상 소스**: `Final_Experiment/4_APC_Coldchain_Dashboard/Step4_Jetson_SplitHUD.py`, `scripts/`

---

## 📌 1. 개발 배경 및 목적

운송 차량 내부의 7~10인치 소형 모니터(또는 터치스크린) 환경에서는 기존의 PC용 복합 대시보드(`Step4_Run_Coldchain_v2.py`)를 띄울 경우 상하 스크롤이 발생하고 버튼/글씨가 작아 주행 중 시인성과 터치 조작성이 저하되는 한계가 있었습니다.

이를 극복하기 위해 **소형 화면 No-Scroll 고대비 UI**와 **운전자 맞춤 2-슬롯 동적 분할 뷰**, 그리고 **부팅 시 완전 무인 자동 켜기(Autostart) 시스템**을 구축했습니다.

---

## 🌟 2. 젯슨 전용 스플릿 HUD (`Step4_Jetson_SplitHUD.py`) 핵심 사양

```
┌────────────────────────────────────────────────────────────────────────┐
│ [ 🚗 [10-02 편도출발] 전주 ➔ 대전 (89km, 1,356건) ▼ ] │ 📁과거기록(1,356건) | 📡실시간: 18.2°C·0.98G·45km/h │
├────────────────────────────────────────────────────────────────────────┤
│  [1번 📍 지도]     [2번 💥 충격·속도]     [🌡️ 온·습도]     [💡 조도]   │
├───────────────────────────────────┬────────────────────────────────────┤
│                                   │                                    │
│   (선택된 과거 세션 궤적 지도)      │   (선택된 과거 세션 충격량 그래프)    │
│                                   │                                    │
└───────────────────────────────────┴────────────────────────────────────┘
```

### 2.1 주요 기능 및 사용자 경험(UX)
1. **지능형 세션 선택 드롭다운 (Session Dropdown)**
   * `🟢 실시간 주행 (현재 센서 스트리밍)`: 실시간 MQTT 패킷(`carrier-c6-01`)을 1초 주기로 스트리밍 및 동적 렌더링.
   * `🚗 [10-02 편도출발] 전주 ➔ 대전 (89km, 1,356건)`: 과거 고속도로 주행 궤적, 1.8G 이상 충격 발생 지점, 온습도 곡선 즉시 열람.
   * `🚗 [10-02 편도복귀] 대전 ➔ 전주 (85km, 478건)`, `📦 [07-15 모의주행]`, `❄️ 급랭 실험` 등 RDS 데이터 전체 자동 매핑.

2. **상시 실시간 센서 모니터링 (Dual-Tracking Pill)**
   * 과거 세션을 선택하여 지난 실험 궤적을 확인하고 있는 동안에도, 우측 상태 배지에 **`📡 실시간: 18.2°C · 0.98G · 45km/h`** 형태로 현재 차량 센서의 물리적 상태가 계속 갱신됩니다.
   * 과거 기록을 조회하는 중에도 백그라운드 MQTT 수신 큐(`data_history`)가 동작하여 실시간 데이터 유실을 100% 방지합니다.

3. **2-슬롯 동적 화면 분할 (100% 와이드 ➔ 50:50 분할)**
   * 화면 상단 4대 모듈 버튼: `[📍 지도]`, `[💥 충격·속도]`, `[🌡️ 온·습도]`, `[💡 조도]`
   * **1개 선택 시**: 전체화면 100% 너비 (높이 520px)
   * **2개 선택 시**: 좌우 50:50 분할 너비 (높이 450px)
   * **3번째 버튼 터치 시**: FIFO(선입선출) 슬라이딩 방식으로 가장 오래된 슬롯이 새 모듈로 자연스럽게 교체됩니다.

4. **차량용 No-Scroll 다크 테마**
   * 배경 `#0b0f19`, 카드 `#111827`, 여백 최소화 패딩 적용으로 1024x600 ~ 1920x1080 해상도에서 스크롤바가 전혀 생기지 않습니다.

---

## 🚀 3. 부팅 시 자동 실행(Autostart) 및 바탕화면 런처 구조

사용자가 젯슨 부팅 시마다 매번 터미널을 열고 명령어를 입력할 필요가 없도록 전용 자동화 스크립트군을 구축했습니다.

### 3.1 파일 구성 (`scripts/`)
| 파일명 | 기능 및 역할 |
| :--- | :--- |
| **`install_jetson_autostart.sh`** | 젯슨 바탕화면 바로가기 아이콘 생성 + 부팅 시 Autostart 자동 등록 + 즉시 화면 런처 실행 통합 인스톨러 |
| **`run_jetson_hud.sh`** | 이전 프로세스 정리 ➔ Streamlit 백그라운드 기동 ➔ 8501 포트 curl 대기 ➔ Epiphany 브라우저 자동 오픈 원클릭 런처 |
| **`stop_jetson_hud.sh`** | Streamlit 백그라운드 프로세스 및 Epiphany 브라우저 안전 종료 |
| **`uninstall_jetson_autostart.sh`** | 바탕화면 아이콘 및 자동 실행 설정 완전 삭제/복구 |

### 3.2 젯슨 터미널 1회 설치 명령
```bash
cd ~/ColdChain-DigitalTwin-Platform
git pull origin main
bash scripts/install_jetson_autostart.sh
```

### 3.3 설치 후 동작 방식
1. **바탕화면 아이콘**:
   * `[ColdChain HUD 실행]`: 더블클릭/터치 시 즉시 대시보드 가동.
   * `[ColdChain HUD 종료]`: 더블클릭/터치 시 즉시 대시보드 및 브라우저 종료.
2. **부팅 자동 실행**:
   * 젯슨 전원 인가 ➔ 부팅 후 로그인 시 4초 후 자동으로 대시보드 브라우저 화면이 전체 화면으로 열립니다.
3. **차량용 완전 무인 부팅 (추천)**:
   * 젯슨 화면의 `Settings(설정)` ➔ `Users(사용자)` ➔ `Automatic Login(자동 로그인)`을 **ON**으로 활성화하면, 비밀번호 입력 없이 전원만 켜도 바로 대시보드가 열립니다.

---

## 🛠️ 4. 트러블슈팅 및 팁

1. **브라우저 드라이버 안내 메시지 (`libEGL warning: ...`)**:
   * Epiphany 브라우저가 Tegra GPU 가속 경로 대신 표준 소프트웨어 렌더링(Mesa)으로 안전 전환되었다는 리눅스 정상 로그이며, 기능 동작에는 영향이 없습니다.
2. **수동 종료 및 재시작**:
   * 종료: `bash scripts/stop_jetson_hud.sh`
   * 재시작: `bash scripts/run_jetson_hud.sh`

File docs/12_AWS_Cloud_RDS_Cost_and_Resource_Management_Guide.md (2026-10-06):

# 12. AWS RDS 클라우드 인프라 비용 분석 및 운영 관리 가이드

> **문서 목적**: 본 문서는 본 콜드체인 디지털 트윈 플랫폼의 클라우드 백엔드로 사용 중인 **AWS RDS(MySQL) 인스턴스의 비용 구조, 잔여 크레딧 현황, 운영 스케줄(예약 가동/종료) 동작 메커니즘, 그리고 예산 알림(AWS Budgets) 관리 가이드**를 체계적으로 정리합니다.

---

## 📌 1. AWS RDS 인스턴스 사양 및 단가 분석

본 연구실 플랫폼에서 센서 텔레메트리(`sensor_data`) 및 유통 이력(`qr`)을 관리하는 데이터베이스 사양입니다.

* **엔드포인트:** `labdb.cn26yq6q0mu6.ap-northeast-2.rds.amazonaws.com:3306`
* **리전:** 아시아 태평양 (서울) `ap-northeast-2`
* **엔진 버전:** MySQL 8.4.8 (AWS Managed RDS)
* **인스턴스 클래스:** `db.t3.micro` (1 vCPU, 1 GiB RAM, 버퍼풀 약 384MB)
* **스토리지:** 20 GiB (General Purpose SSD - gp2/gp3)

### 서울 리전 정격 단가 (Single-AZ 기준)
1. **컴퓨팅 인스턴스:** **시간당 $0.026** (약 35원/시간)
2. **EBS 스토리지 (20GB):** **월 약 $2.60** (인스턴스를 중지해도 데이터 보존을 위해 스토리지는 과금됨)

---

## 💳 2. 활성 크레딧 현황 및 차감 구조 (2026년 10월 기준)

현재 총 4개의 프로모션/온보딩 크레딧이 계정에 활성화되어 있습니다.

```mermaid
pie title 남은 크레딧 분포 ($70.08)
    "Explore AWS - RDS/Aurora" : 20.00
    "Explore AWS - Budgets" : 20.00
    "Explore AWS - Lambda" : 20.00
    "AWS Free Tier 잔여" : 10.08
```

* **남은 총 크레딧:** **US$70.08** (약 95,000원 상당)
* **크레딧 만료일:** **2027년 4월 27일** (유효기간 넉넉함)
* **주요 크레딧 세부 내역:**
  1. `10060090827` (Explore AWS: Create an Aurora or RDS database): **$20.00 잔여 (RDS 전용, 0원 사용)**
  2. `10061592420` (Explore AWS: Set up a cost budget): **$20.00 잔여**
  3. `10061597460` (Explore AWS: Create a web app using Lambda): **$20.00 잔여**
  4. `10060090724` (AWS Free Tier / 온보딩): **$10.08 잔여** ($89.92 소진)

> 💡 **비용 차감 원리**: 발생하는 모든 요금은 신용카드가 아니라 **위 활성 크레딧에서 1순위로 자동 차감**되므로 현재 실질적인 본인 지출액은 **0원**입니다.

---

## 📊 3. 운영 모드별 월간 예상 비용 비교

사용자의 운영 방식(스케줄 예약 vs 24시간 상시 가동)에 따른 비용 산출표입니다.

| 운영 모드 | 일일 가동 시간 | 월간 컴퓨팅 비용 | 월간 스토리지 비용 | 월 총 예상 요금 | 크레딧($70.08) 소진 기간 |
| :--- | :---: | :---: | :---: | :---: | :---: |
| **현재: 예약 가동 (09:00~19:00)** | 10시간 (월 300h) | $7.80 | $2.60 | **약 $10.40 / 월 (약 1.4만 원)** | **약 6.7개월 무료 유지** |
| **변경: 24시간 365일 풀가동** | 24시간 (월 730h) | $18.98 | $2.60 | **약 $21.58 / 월 (약 2.9만 원)** | **약 3.2개월 무료 유지** |
| **휴식기: 인스턴스 중지 (Stopped)**| 0시간 (월 0h) | $0.00 | $2.60 | **약 $2.60 / 월 (약 3,500원)** | **약 27개월 무료 유지** |

---

## ⏰ 4. 예약 스케줄과 야간 수동 기동 시 라이프사이클

현재 인스턴스는 매일 **오전 9시 기동 ➔ 저녁 7시 종료** 자동 스케줄이 설정되어 있습니다.

```mermaid
sequenceDiagram
    autonumber
    participant Schedule as ⏱️ EventBridge 스케줄러
    participant RDS as 🗄️ AWS RDS (labdb)
    actor User as 👨‍🔬 사용자

    Note over Schedule, RDS: [19:00] 정기 종료 스케줄 실행 ➔ RDS Stopped
    User->>RDS: [20:30] 야간 테스트를 위해 콘솔에서 수동 시작 (Start)
    Note over RDS: [야간~익일 새벽] 인스턴스 연속 가동 (Running) 유지
    Schedule->>RDS: [익일 09:00] 정기 시작 스케줄 실행 (이미 Running이므로 No-op 유지)
    Schedule->>RDS: [익일 19:00] 정기 종료 스케줄 실행 ➔ 자동으로 정지(Stopped)!
```

### 핵심 동작 원리
1. **야간 수동 시작 시**: 저녁 7시 정기 종료 트리거는 이미 통과했으므로, **수동으로 켠 순간부터 오늘 밤새 계속 켜진 상태(Running)로 유지**됩니다.
2. **익일 아침 9시**: '시작' 스케줄이 호출되나 이미 켜져 있으므로 정상 가동 상태를 이어갑니다.
3. **익일 저녁 7시**: 설정된 **'종료(Stop)' 스케줄이 정상적으로 트리거되어 다시 자동으로 꺼집니다.**
4. **비용 영향**: 밤새 10시간 추가 가동 시 발생하는 비용은 약 **0.26달러(약 350원)**이며 전액 크레딧에서 차감되므로 지출은 0원입니다.

---

## 🛡️ 5. 예산 알림(AWS Budgets) 설정 및 주의사항

기습 결제를 방지하기 위해 생성된 **`My Zero-Spend Budget`**의 설정 가이드입니다.

### 5.1 알림 vs 차단의 차이
* **AWS Budgets는 자동 차단기가 아닙니다.**
* $0.01(약 13원)을 초과하더라도 **서버가 자동으로 꺼지지 않고 정상 작동**하며, 설정된 이메일로 경고 알림만 발송됩니다.
* 크레딧이 남아있는 동안에는 실질 결제액이 $0이므로 알림이 오지 않다가, **크레딧이 전부 소진되어 내 카드에서 1원이라도 청구될 상황이 되는 첫날 즉시 이메일 경고**가 옵니다.

### 5.2 ⚠️ 필수 조치: 이메일 인증 (Email Verification)
* AWS 정책상 이메일 소유자 인증이 완료되지 않으면 예산 초과 시에도 메일이 발송되지 않습니다.
* **조치 방법**:
  1. 등록된 이메일(`yuyu6243@gmail.com` 및 `yuyu6243@naver.com`) 접속
  2. AWS에서 발송된 **"Email Verification"** 확인 메일 오픈
  3. 본문의 **인증 확인(Verify) 링크 클릭** ➔ Budgets 화면에서 **`Verified`** 상태 확인

---

## 💡 6. 크레딧 소진 후 장기 운영 전략

1. **실험 진행 기간 (향후 3개월):**
   * 남은 크레딧($70.08)으로 24시간 풀가동하더라도 비용 부담 0원.
2. **크레딧 소진 임박 시점 (잔여 $10 이하):**
   * Budgets 이메일 알림 수신 시, 연구실 연구비 카드로 교체하거나 다시 9시~19시 예약 모드로 복귀.
3. **연구 및 논문 완료 후:**
   * 연구실 PC에 데이터베이스 로컬 백업(`mysqldump`) 저장.
   * AWS RDS 콘솔에서 인스턴스를 완전 삭제(`Delete`)하여 **이후 영구히 비용 0원 달성**.

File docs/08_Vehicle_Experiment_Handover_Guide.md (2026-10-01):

# 08. 차량 주행 실험 인계 가이드 & 텔레메트리 파이프라인 분석

## 📌 1. 개요 및 인계 배경
* **작성 일자:** 2026-10-02 00:05 KST
* **대상 기기:** CarrierBoard Beetle ESP32-C6 (MAC: `CC:8D:A2:F9:99:78`, 포트: `COM7`)
* **목적:** 1차 야간 차량 주행 테스트 중 발생한 데이터 저장 누락 원인 규명, 펌웨어 레벨의 플래시 메모리(LittleFS) 블랙박스 구현 완료, 2차 주행 실험을 위한 프로토콜 및 데이터 파이프라인 가이드 정리.

---

## 🔍 2. 1차 주행 테스트 문제점 및 원인 규명 (Root Cause Analysis)

### 2.1 대시보드에는 이동 궤적이 보였으나 DB에는 GPS(위경도 0.0)가 없었던 이유
1. **MQTT 브로커(`broker.emqx.io`)의 특성**:
   * MQTT는 실시간 라우팅 프로토콜이며 기본적으로 데이터를 영구 저장하지 않습니다(QoS 0, Non-retained).
2. **Streamlit 대시보드(RAM) vs AWS RDS(MySQL)**:
   * 주행 중 사용자의 스마트폰 브라우저가 Streamlit 대시보드에 연결되어 있어 대시보드 메모리(`data_history` 세션 리스트)에는 실시간 MQTT 패킷이 들어와 궤적이 그려졌습니다.
   * 반면, AWS RDS 인스턴스(`labdb`)는 예약 설정에 의해 야간에 자동으로 `Stopped(일시 중지)` 상태로 전환되어 있었습니다.
   * 대시보드 백그라운드의 `save_to_mysql()` 함수가 RDS 연결 실패(Connection Refused)로 DB 쓰기를 건너뛰었습니다.
3. **실내 복귀 후 상황**:
   * 밤 23:25경 사용자가 RDS를 다시 시작하자마자 DB 쓰기가 재개되었습니다.
   * 그러나 이 시점에는 이미 실내로 복귀한 후였기 때문에 보드의 ATGM336H GPS가 위성 신호를 잡지 못해(`Fix: NO`), `lat: 0.000000, lng: 0.000000` 데이터만 DB에 연속으로 기록되었던 것입니다.

---

## 🛠️ 3. 펌웨어 개선 내역 (`carrier_board_mqtt.cpp`)

데이터 유실 방지를 위해 **LittleFS 기반 듀얼 로컬 스토리지 아키텍처**를 구현하고 보드에 플래시 완료했습니다.

### 3.1 듀얼 로깅 구조
1. **마스터 블랙박스 (`/telemetry_log.jsonl`)**:
   * Wi-Fi 및 MQTT 연결 상태와 무관하게 5초마다 측정되는 모든 텔레메트리를 ESP32-C6 내부 플래시 메모리에 상시 Append 기록.
   * 1MB 안전 한도 내에서 최소 4,100건 ~ 최대 5,800건(약 5시간 40분 ~ 8시간 분량) 저장 가능.
2. **오프라인 버퍼 (`/offline_buf.jsonl`)**:
   * 터널, 음영지역 등 핫스팟/MQTT 연결이 끊어졌을 때만 미전송 패킷을 별도 큐잉.
   * 네트워크 복구 시 `flushOfflineBuffer()` 함수가 자동 호출되어 순차적으로 브로커에 전송 후 버퍼 파일 자동 초기화.

### 3.2 시리얼 인터랙티브 CLI 명령어 지원 (115200 bps)
PC 연결 시 시리얼 모니터 또는 터미널을 통해 보드 제어 가능:
* `dump` 또는 `read`: LittleFS에 저장된 모든 원본 JSONL 데이터 스트리밍 출력.
* `info` 또는 `stat`: 현재 LittleFS 전체 용량, 사용량, 누적 기록 건수 실시간 출력.
* `clear` 또는 `reset`: 플래시 메모리 로그 및 오프라인 버퍼 파일 완전 삭제 초기화.

> **현재 보드 상태**: `clear` 완료되어 0건(방금 막 생성된 초기 패킷 1건)으로 대기 중입니다.

---

## 📋 4. 2차 주행 실험 실행 프로토콜 (Checklist)

### 🚗 출발 5분 전
1. **AWS RDS 시작**:
   * AWS 관리 콘솔 $\rightarrow$ RDS $\rightarrow$ `labdb` 선택 $\rightarrow$ **작업** $\rightarrow$ **'시작'** 클릭 (상태가 `사용 가능`이 될 때까지 약 2~3분 소요).
2. **스마트폰 핫스팟 활성화**:
   * 네트워크 이름(SSID): `hani` / 비밀번호: `12345687` (2.4GHz 대역).
3. **Streamlit 대시보드 새 세션 생성**:
   * 스마트폰 웹 브라우저로 Streamlit 대시보드 접속.
   * 사이드바의 **`🚀 새 실험 세션 시작`** 버튼 클릭 (이전 레코드와 분리된 고유 `run_id` 부여).
4. **센서 보드 전원 인가 및 배치**:
   * 보조배터리에 ESP32-C6 C타입 케이블 연결.
   * **차량 앞유리 대시보드 위(하늘이 트인 위치)**에 거치 (GPS 위성 신호 확보 필수).

### 🛣️ 주행 중
* 터널이나 네트워크 음영지역에서도 LittleFS가 모든 주행 데이터를 100% 로컬 백업하므로 통신 단절을 걱정할 필요가 없습니다.

### 🏁 주행 완료 후 (도착 시)
1. **데이터 CSV 백업**:
   * 스마트폰 대시보드 사이드바의 **`📥 이 실험 데이터 CSV 다운로드`** 클릭.
2. **원본 플래시 메모리 덤프 (선택/보존용)**:
   * PC에 보드 연결 후 시리얼 터미널에서 `dump` 입력 시 1초도 유실 없는 JSONL 로컬 파일 확보 가능.
3. **AWS RDS 중지 (비용 절약)**:
   * AWS 콘솔에서 `labdb` 선택 후 **작업** $\rightarrow$ **'일시적으로 중지'**.

---

## 🔗 5. 다음 대화 시 인계 사항 (For Next Conversation)

다음 번 대화에서 아래와 같이 작업을 요청하시면 즉시 이어서 진행할 수 있습니다:

1. **"주행 끝났어, 데이터 확인해줘"**:
   * RDS DB에 저장된 `sensor_data` 중 신규 `run_id` 데이터의 건수, GPS Fix 상태, 온도/습도/충격 이벤트 통계 분석 실행.
2. **"보드에서 플래시 메모리 데이터 뽑아줘"**:
   * `COM7` 포트의 `dump` 명령어로 PC 로컬에 `.jsonl` / `.csv` 파일로 즉시 저장.
3. **"주행 데이터 시각화 및 논문/보고서용 그래프 그려줘"**:
   * GPS 이동 경로 지도(Folium/Plotly), 온도-습도-충격 시계열 그래프 및 이상치 구간 자동 분석 진행.

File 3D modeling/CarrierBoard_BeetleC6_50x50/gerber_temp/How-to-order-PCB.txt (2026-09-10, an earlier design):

CarrierBoard_BeetleC6_50x50 Production Release Option-B
Board Size: 50.0mm x 50.0mm
Option B: Inward Overhang Architecture (All sensor modules fit 100% inside 50x50mm)
Sensors: SHT45 (Top), BH1750 (Top), GY-521 (Bottom), ATGM336H GPS (Bottom)

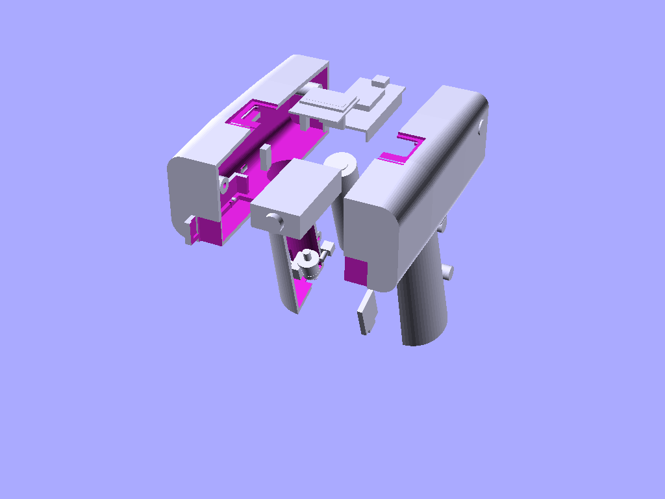
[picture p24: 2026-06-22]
3D_Printer_Housing/v11_QR_Scanner_Housing_Flush_OLED/11_exploded_view.png

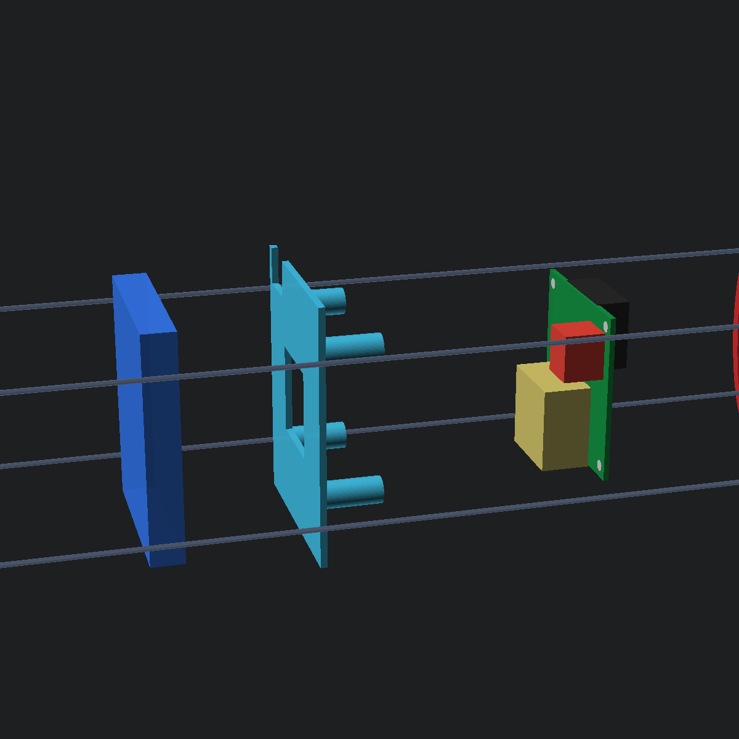
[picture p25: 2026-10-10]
3D_Printer_Housing/v20_Apple_Sensor_Pod_Modular5000mAh/20_exploded_side_view.png

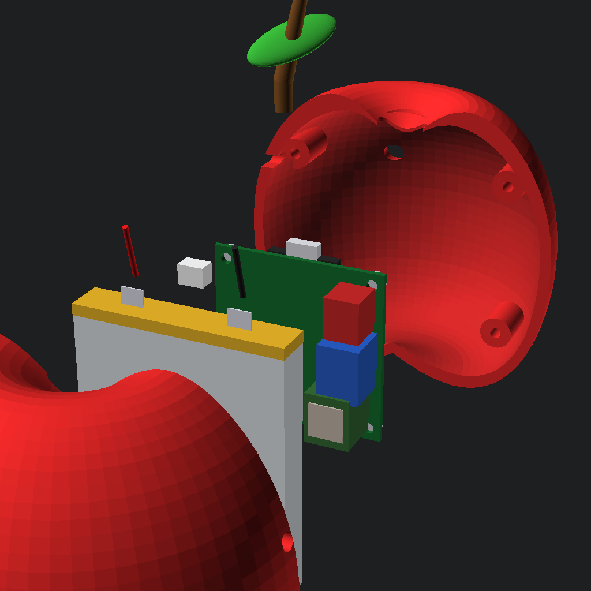
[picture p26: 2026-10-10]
3D_Printer_Housing/v19_Apple_Sensor_Pod_5000mAh/19_exploded_view.png

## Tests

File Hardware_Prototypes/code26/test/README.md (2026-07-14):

# ESP32 Sensor Examples

이 폴더는 ESP32(PlatformIO)에서 테스트할 수 있는 예시 스케치를 포함합니다.

파일 목록:
- `src/sht45_example.ino` — SHT45 (Sensirion SHT4x) 예시
- `src/bh1750_example.ino` — BH1750 조도 센서 예시
- `src/mpu6050_example.ino` — GY-521 (MPU6050) 예시
- `src/neo6m_example.ino` — NEO-6M GPS 예시

빌드/업로드 (PlatformIO):
```bash
cd code26/test
pio run -e esp32dev -t upload
pio device monitor -b 115200
```

라이브러리
- BH1750
- Adafruit MPU6050
- TinyGPSPlus
- Sensirion SHT4x (SHT45 사용 시)

배선 예시
- I2C 센서 (SHT45, BH1750, MPU6050): SDA -> GPIO21, SCL -> GPIO22, GND, VCC(3.3V)
- NEO-6M: TX -> ESP32 GPIO16 (RX2), RX -> ESP32 GPIO17 (TX2), GND, VCC

참고: 일부 예제는 특정 라이브러리 API를 사용합니다. 라이브러리 이름이 플랫폼/레지스트리와 다를 경우 README의 라이브러리 이름으로 검색해 설치하세요.

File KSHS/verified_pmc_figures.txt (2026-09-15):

=== PMC13564522: Quality Variation Patterns and Predictive Modeling of Fermented Soybean Whey-Based Tofu Under Cold-Chain Conditions Using Kinetic and Machine Learning Approaches ===
URL: https://www.ncbi.nlm.nih.gov/pmc/articles/PMC13564522/
  - Figure 1: Temperature and time settings for different cold-chain transport modes of fermented soybean whey-based tofu.
  - Figure 2: Changes in TVC and PBC in FSW-tofu under different logistics modes.
  - Figure 3: Changes in textural properties of FSW-tofu under different logistics modes.
  - Figure 4: Changes in water-holding capacity of FSW-tofu under different logistics modes.
  - Figure 5: Fitting results of measured and predicted values for microbial and quality indicators of FSW-tofu in validation set S3.
  - Figure 6: Fitting results of measured and predicted values for microbial and quality indicators of FSW‑tofu in validation set E3.
=== PMC8537554: Effects of Salinity and Abscisic Acid on Lipid Transfer Protein Accumulation, Suberin Deposition and Hydraulic Conductance in Pea Roots ===
URL: https://www.ncbi.nlm.nih.gov/pmc/articles/PMC8537554/
  - Figure 1: Effects of NaCl and ABA on LTP localization in the central cylinder of root basal part. Root section of pea plants grown without NaCl and exogenous AB
  - Figure 2: Effects of NaCl and ABA on ABA localization in the central cylinder of root basal part. Root section of pea plants grown without NaCl and exogenous AB
  - Figure 3: Effects of NaCl and ABA on suberin deposition. Root cross-sections in the endoderm region of pea plants grown under control conditions (a), treated wi
  - Figure 4: Abundance of transcripts of Ps-LTP1 gene in pea roots treated with NaCl and ABA. Means ± SE are presented. Means for the control, NaCl and ABA treatme
  - Figure 5: Spatial structure of pea Ps-LTP1 complexed with 10 conformations of ABA calculated by means of blind molecular docking (a). Interaction of Ps-LTP1 wit
  - Figure 6: Effects of ABA on the fluorescence level of the LTP-TNS complexes. Ps-LTP1, Lc-LTP2 and Ag-LTP – LTPs from pea, lentil and dill. Results are expressed
=== PMC9824632: Semantic Segmentation of Terrestrial Laser Scans of Railway Catenary Arches: A Use Case Perspective ===
URL: https://www.ncbi.nlm.nih.gov/pmc/articles/PMC9824632/
  - Figure 1: An example of a catenary arch (not in dataset) that shows the labels of the majority of the classes (own work).
  - Figure 2: Processing steps for locating catenary arches within a large scene.
  - Figure 3: Overview of the dataset. Note the large variation of catenary arch types present in the dataset.
  - Figure 4: Normalised class distribution after the voxel centroid nearest neighbour filter is applied.
  - Figure 5: Overview of the processing steps, from the raw arch data to the data fed to the machine learning model.
=== PMC7924345: Another One Bites the Gut: Nuclear Receptor LRH-1 in Intestinal Regeneration and Cancer ===
URL: https://www.ncbi.nlm.nih.gov/pmc/articles/PMC7924345/
  - Figure 1: The intestine under physiological and pathological conditions. The small intestine presents a well-organized architecture, composed by villi surrounde
  - Figure 2: The multifaceted role of the Liver Receptor Homolog-1 (LRH-1) in the intestine. LRH-1 is nuclear receptor that can be endogenously activated by phosph

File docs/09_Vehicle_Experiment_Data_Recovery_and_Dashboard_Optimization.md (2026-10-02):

# 09. 실제 차량 주행 실험 데이터 복구 및 과일 충격량 중심 관제 대시보드 고도화

---

## 📌 1. 개요 및 배경 (Executive Summary)

* **작성 일자:** 2026-10-02
* **수행 연구:** 농산물(과일) 신선 물류 디지털 트윈 플랫폼 - 왕복 174km 실제 고속도로/국도 주행 실험
* **대상 구간:** 
  1. **[출발편]** 전주 ➔ 대전 (89.2km, 1,356 패킷, 최고속도 120.1 km/h)
  2. **[복귀편]** 대전 ➔ 전주 (85.4km, 478 패킷, 최고속도 114.5 km/h)
* **탑재 장비:** CarrierBoard Beetle ESP32-C6 + MPU6050 (3축 가속도/자이로) + ATGM336H GPS + SHT30 (온습도) + BH1750 (조도)
* **핵심 과제:**
  1. 차량 주행 중 통신/DB 중단으로 유실될 뻔한 전주 ➔ 대전 주행 데이터의 **MCU 내부 플래시(LittleFS) 블랙박스 기반 100% 전량 복구**.
  2. 연구실 PC 연결 시 불필요한 실내 정지 데이터가 AWS RDS DB를 오염시키는 문제 방지.
  3. **과일 탑차 운송의 핵심 품질 저하 요인인 진동 및 과속방지턱/포트홀 충격량(G-Force)**을 차량 속도보다 우선순위로 모니터링할 수 있도록 **Altair 이중 Y축(Dual Y-Axis) 시각화 개편**.
  4. Streamlit Cloud 상용 배포 환경에서의 **중복 키 에러(DuplicateElementKey), 34시간 시간 점프 왜곡, CSV 10건 다운로드 제한 버그 완벽 수정**.

---

## 💾 2. 하드웨어 블랙박스(LittleFS) 데이터 복구 및 검증

### 2.1 문제 상황
* 1차 주행 중 AWS RDS 인스턴스 일시 정지 및 셀룰러 핫스팟 접속 단절로 인해 전주 ➔ 대전 출발 구간의 실시간 데이터가 DB에 실시간 적재되지 못함.

### 2.2 복구 절차
1. 차량 복귀 후 ESP32-C6 기기를 연구실 PC(`COM37`)에 연결.
2. 펌웨어에 사전에 구현해 둔 인터랙티브 시리얼 덤프 프로토콜(`dump`)을 구동하여 MCU 내부 플래시 메모리(LittleFS)에 저장된 **2,994건의 블랙박스 레코드 전량을 `scratch/flash_dump_20261002.jsonl`로 덤프 성공**.
3. 타임스탬프와 주행 궤적을 정밀 분석하여 출발 시점(08:00:02 KST)부터 대전 도착 시점(09:57:48 KST)까지의 **1,356개 정밀 GPS 패킷(GPS Fix율 100%)을 검출**.
4. 추출된 데이터를 AWS RDS MySQL `sensor_data` 테이블에 `run_20261002_080002_departure` 단일 세션으로 완벽 복원 적재.
5. 복귀 데이터 또한 `run_20261002_103710_return` (478건, 10:37:10 ~ 12:21:48 KST)으로 정규화 완료.

```mermaid
flowchart LR
    subgraph Vehicle [실제 차량 주행]
        C6[Beetle ESP32-C6] -->|5초 주기| Flash[(LittleFS Flash Memory)]
        C6 -.->|통신 불안정/DB 중단| Broker[MQTT Broker]
    end

    subgraph Recovery [데이터 추출 및 복원]
        Flash -->|USB 시리얼 덤프 COM37| PC[PC 로컬 JSONL 2,994건]
        PC -->|궤적 필터링 & 정제| Ingest[복원 엔진]
        Ingest -->|적재| RDS[(AWS RDS MySQL)]
    end

    subgraph Service [대시보드 서비스]
        RDS --> Streamlit[Streamlit Cloud 관제 플랫폼]
    end
```

---

## 🗄️ 3. AWS RDS 데이터 정제 및 DB 실시간 저장 방지 토글

### 3.1 연구실 PC 연결 시 DB 오염 방지
* **문제:** 펌웨어 업로드나 시리얼 디버깅을 위해 PC와 보드를 연결하는 동안에도 센서가 작동하여 위도/경도가 `0.0`인 실내 정지 데이터가 계속 DB에 누적됨.
* **사용자 요구사항:**
  * GPS가 `0.0`인 데이터를 일괄 필터링해서는 안 됨 (이유: **차량이 터널이나 지하차도를 통과할 때 GPS가 일시적으로 끊기더라도, 그 순간 과일에 가해지는 진동과 충격량 데이터는 반드시 DB에 저장되어야 함**).
* **해결책: 대시보드 내 실시간 수동 토글 스위치 도입**
  * `Step4_Run_Coldchain_v2.py` 사이드바에 **`🔴 DB 실시간 저장 활성화` (기본값: OFF)** 토글 스위치 배치.
  * **OFF (기본값, 연구실 모드):** 실시간 센서 화면 모니터링은 정상 작동하되, AWS RDS에는 1건도 쓰지 않음 (DB 오염 원천 차단 및 AWS 비용 절약).
  * **ON (실제 차량 실험 모드):** 실제 차량에 싣고 출발할 때만 스위치를 켜서 안전하게 주행 데이터만 DB에 실시간 저장.

### 3.2 세션 명칭 직관화 및 레거시 쓰레기 데이터 정리
* **레거시 쓰레기 세션 정리:** 기존 DB에 누적되어 있던 11개의 실내 정지/미검증 세션(`test`, `default_run`, `test_run` 등)을 로컬 JSON으로 안전하게 백업 후 MySQL에서 완전 삭제.
* **보존된 4대 핵심 실험 데이터:**
  1. `run_20261002_080002_departure`: 오늘 갈 때 전주 ➔ 대전 (89km, 1,356건)
  2. `run_20261002_103710_return`: 오늘 올 때 대전 ➔ 전주 (85km, 478건)
  3. `run_20261001_065739`: 어제 야외 전북대 캠퍼스 GPS 검증 (157건)
  4. `korea_30km_test`: 과거 7월 30km 시뮬레이션 주행 (181건)
* **KST 자동 세션 생성기:** 새 세션 생성 시 `주행_2026-10-02_15시30분` 형태로 한국 표준시가 반영된 직관적인 세션 ID가 자동 부여되도록 개편.

---

## 📊 4. 과일 손상 예측을 위한 충격량(G-Force) 중심 대시보드 개편

### 4.1 연구 배경
* 과일을 실은 탑차가 방지턱이나 포트홀을 통과할 때 발생하는 수직/수평 충격량(G-Force)은 과일의 압상, 멍, 조직 파손을 유발하는 결정적인 인자임.
* 기존 대시보드는 차량 속도(0~120 km/h)와 충격량(1.0~4.0 G)이 단일 축을 공유하거나 속도 위주로 되어 있어, 미세하지만 치명적인 충격량 변화 폭이 시각적으로 축소되어 보이는 한계가 있었음.

### 4.2 Altair 이중 Y축(Dual Y-Axis) 차트 아키텍처
* **왼쪽 Y축 (주요 지표): 과일 충격량 (G-Force, 1.0 ~ 5.0+ G)**
  * 오렌지색 선 그래프로 충격량의 변화 추이를 명확히 표현.
  * **농산물 품질 안전 기준선 (Rule Layer)**:
    * 🟡 **2.0G 과일 손상 주의 (Warning)**: 주황색 점선 표시 (`strokeDash=[4, 4]`).
    * 🔴 **3.0G 과일 파손 위험 (Critical)**: 빨간색 점선 표시.
  * **충격 이벤트 하이라이트 (Scatter Point)**:
    * 1.8G를 초과하는 충격 발생 지점마다 눈에 띄는 빨간색 원형 마커(`size=80`)를 자동으로 타겟팅 표시.
* **오른쪽 Y축 (보조 지표): 차량 속도 (Speed, km/h)**
  * 옅은 녹색 라인(`opacity=0.6`, `strokeWidth=1.4`)으로 배경 레이어에 배치하여, "몇 km/h 주행 중 발생한 충격인지"를 직관적으로 비교 분석 가능하도록 설계.

---

## 🐞 5. 대시보드 배포 버그 수정 및 안정화 내역

### 5.1 `StreamlitDuplicateElementKey` 충돌 수정
* **원인:** 과거 주행 데이터 조회 모드에서 사이드바의 `st.download_button` 위젯이 `while True:` 무한 갱신 루프 내부에서 2초마다 동일한 `key="btn_csv_export"`로 반복 생성되어 Streamlit 엔진이 위젯 키 충돌로 중단됨.
* **조치:** 
  * `download_button`을 `while True:` 루프 밖 사이드바(`with st.sidebar:`)로 분리.
  * 과거 데이터는 실시간 유입이 없는 정적 데이터이므로, 화면에 전체 차트/지도를 렌더링한 후 루프를 즉시 종료(`break`)하도록 최적화 (Streamlit Cloud CPU/메모리 부하 절감).
  * `@st.cache_data(ttl=300)`을 적용하여 세션 전환 시 RDS 재질의 없이 5분간 고속 캐싱 지원.

### 5.2 34시간 타임 점프 왜곡 현상 (그래프 평평한 직선 버그) 해결
* **원인:** 복귀 주행(`run_20261002_103710_return`) 시작 시 GPS 미동기화 초기 패킷 3건이 `2026-10-01 00:00:00`으로 기록됨. 차트의 Temporal X축이 10월 1일 00시부터 10월 2일 12시까지 총 36시간을 범위로 잡으면서, 34시간 동안의 빈 데이터 구간이 차트 너비의 95%를 차지하고 실제 주행(1시간 44분)이 우측 끝 5%로 찌그러짐.
* **조치:** 
  * MySQL DB에서 해당 3건의 시간을 실제 서버 수신 시간(KST)인 `10:37:10`, `10:37:20`, `10:37:35`로 보정.
  * 대시보드 로딩 로직에 미동기화 타임스탬프 자동 보정 방어 코드 탑재.
  * 결과: 1시간 44분 전 구간이 차트 가로폭 100%에 맞춰 완벽한 해상도로 펼쳐짐.

### 5.3 실시간 로그 테이블 CSV 10건 다운로드 한계 해결
* **원인:** 화면 하단 로그 표의 성능 유지를 위해 `head(10)`만 렌더링하고 있었는데, 사용자가 표 우측 상단의 Streamlit 내장 `Download as CSV` 버튼을 누르면 화면에 로딩된 10건만 추출됨.
* **조치:** 
  * Streamlit의 고성능 가상 스크롤(Virtual Scrolling, `height=350`)을 적용하여 **전체 데이터(478건 전량)**를 표에 바인딩 (스크롤해도 부드러우며 표 내장 다운로드 시 전량 저장).
  * 표 제목(`📋 실시간 로그`) 옆에 눈에 띄는 **`📥 전체 CSV 다운로드 ({count}건)`** 전용 버튼을 추가하여 한 번의 클릭으로 `utf-8-sig` (한글 엑셀 깨짐 방지) 인코딩 파일 즉시 다운로드 가능.

---

## 📈 6. 결론 및 향후 계획

1. **실험 데이터 자산화:** 전주 ↔ 대전 간 고속도로 및 국도 주행 174km, 총 1,834건의 고정밀 센서 텔레메트리가 AWS RDS와 로컬 백업에 안전하게 영구 보존되었습니다.
2. **학술 연구 활용:** 추출된 속도-충격량 상관관계 데이터는 석사 학위 논문 및 SCIE 저널 투고 논문의 **"수확 후 농산물 수송 중 충격 누적량과 품질 손상도(당도/경도/압상율) 연계 디지털 트윈 모델"** 검증의 핵심 실증 데이터셋으로 활용될 예정입니다.
3. **플랫폼 완성도:** Streamlit Cloud 상용 배포 플랫폼이 무결점 상태로 안정화되어, 향후 실제 탑차 현장 주행 시 실시간 저장 스위치만 켜면 자동으로 신뢰성 높은 데이터가 축적됩니다.

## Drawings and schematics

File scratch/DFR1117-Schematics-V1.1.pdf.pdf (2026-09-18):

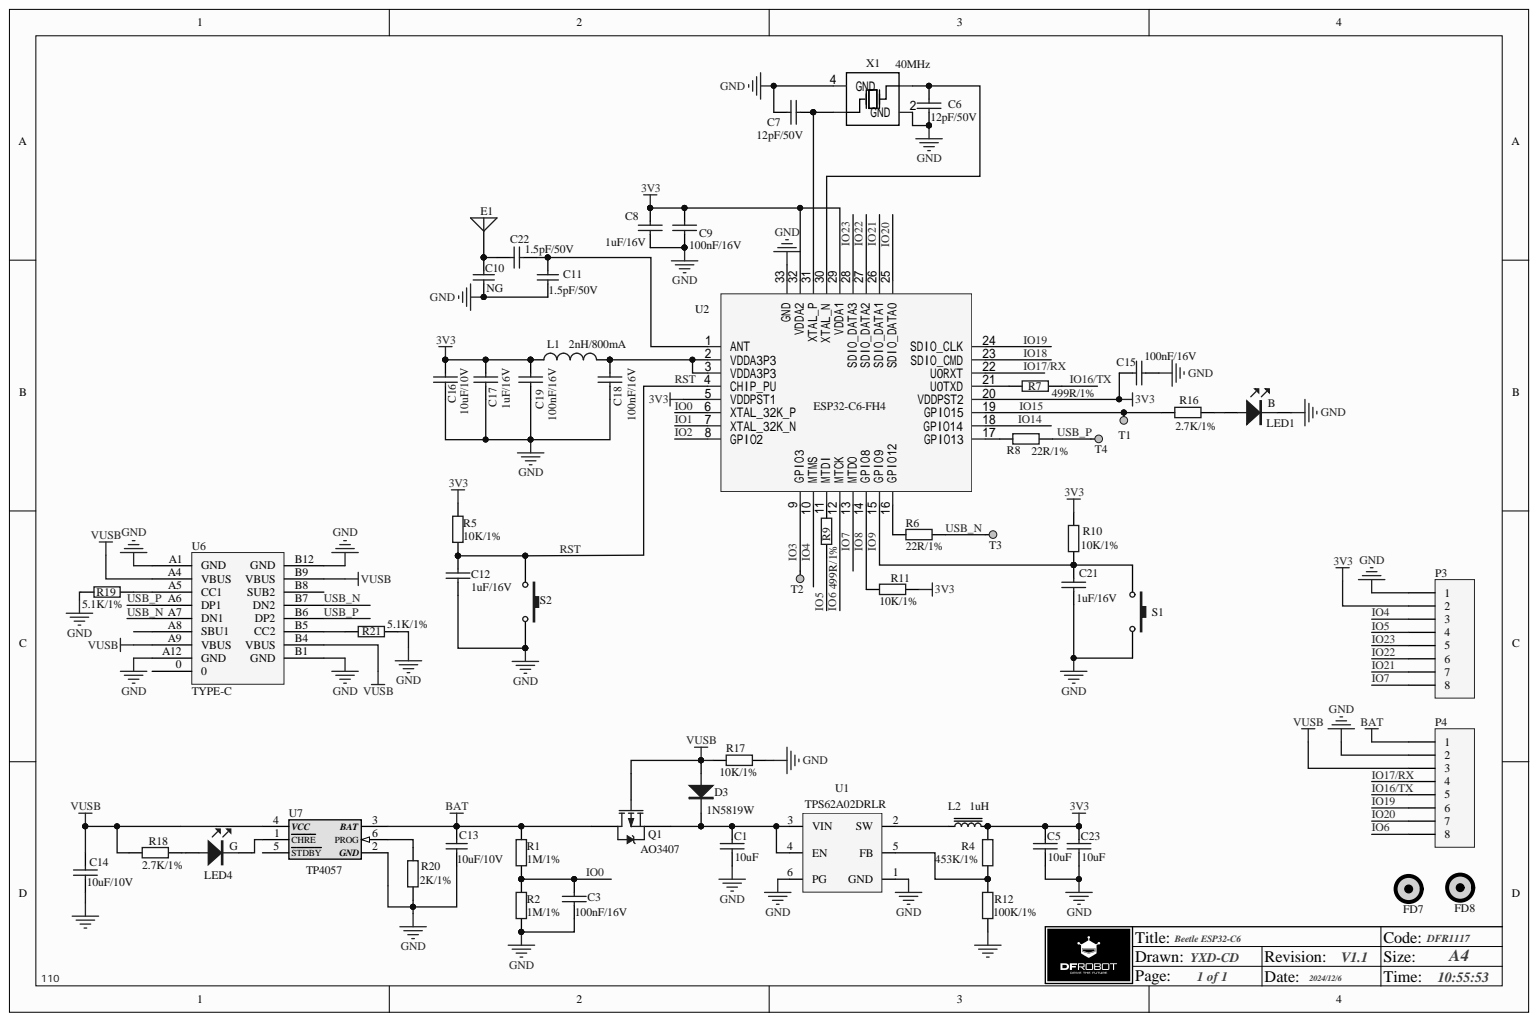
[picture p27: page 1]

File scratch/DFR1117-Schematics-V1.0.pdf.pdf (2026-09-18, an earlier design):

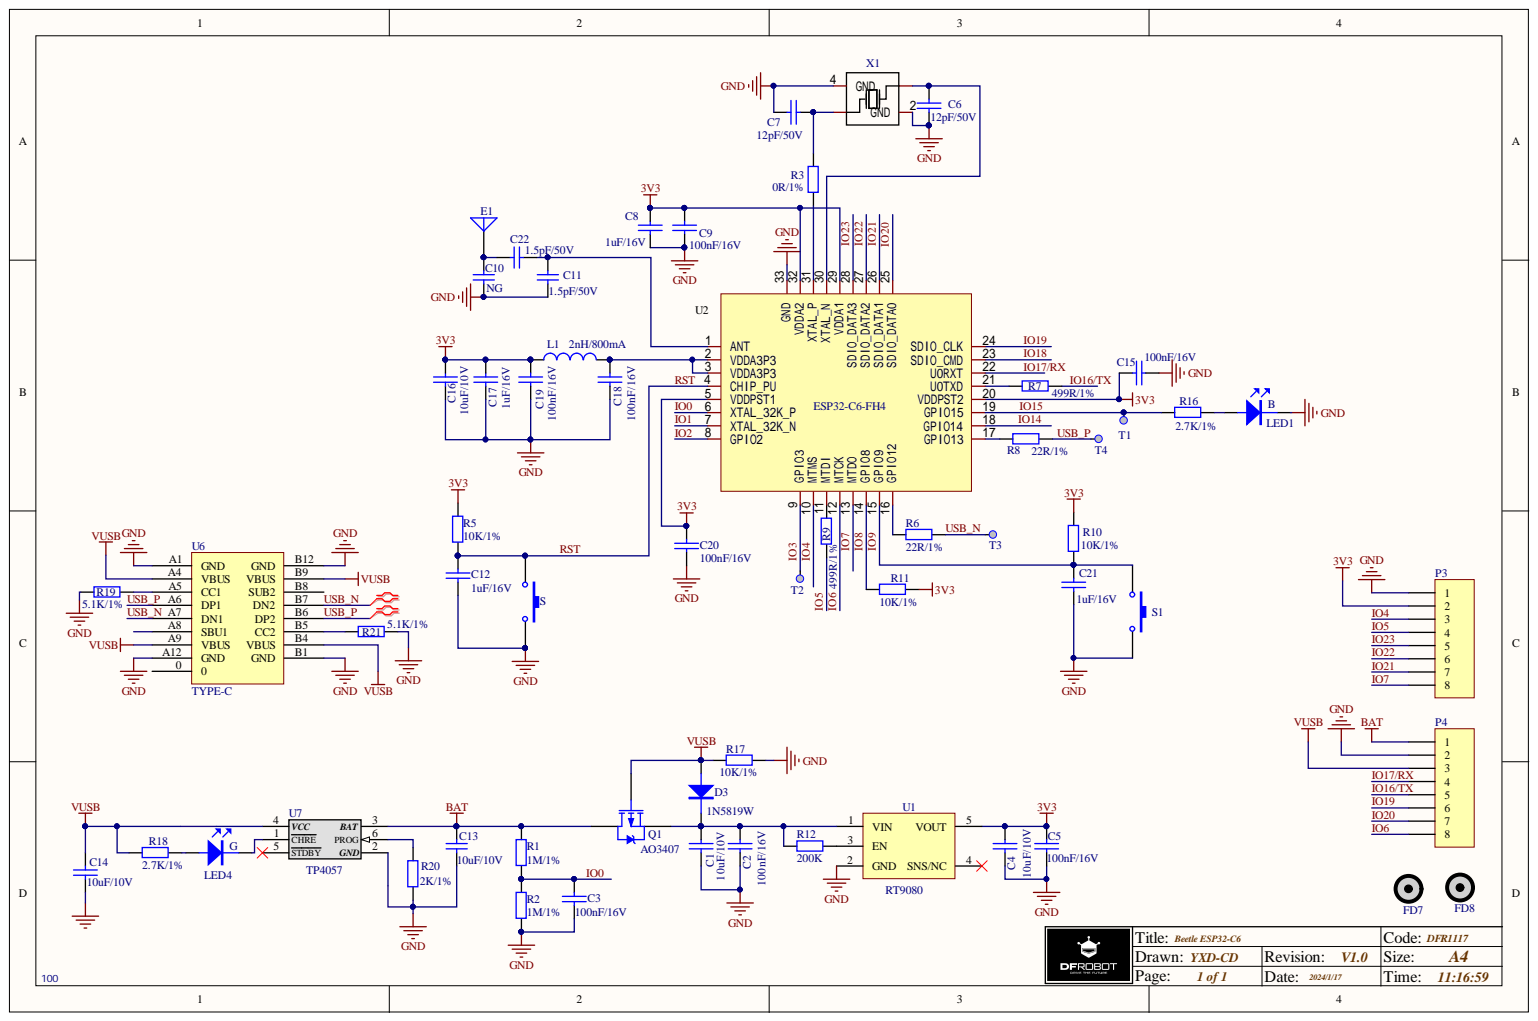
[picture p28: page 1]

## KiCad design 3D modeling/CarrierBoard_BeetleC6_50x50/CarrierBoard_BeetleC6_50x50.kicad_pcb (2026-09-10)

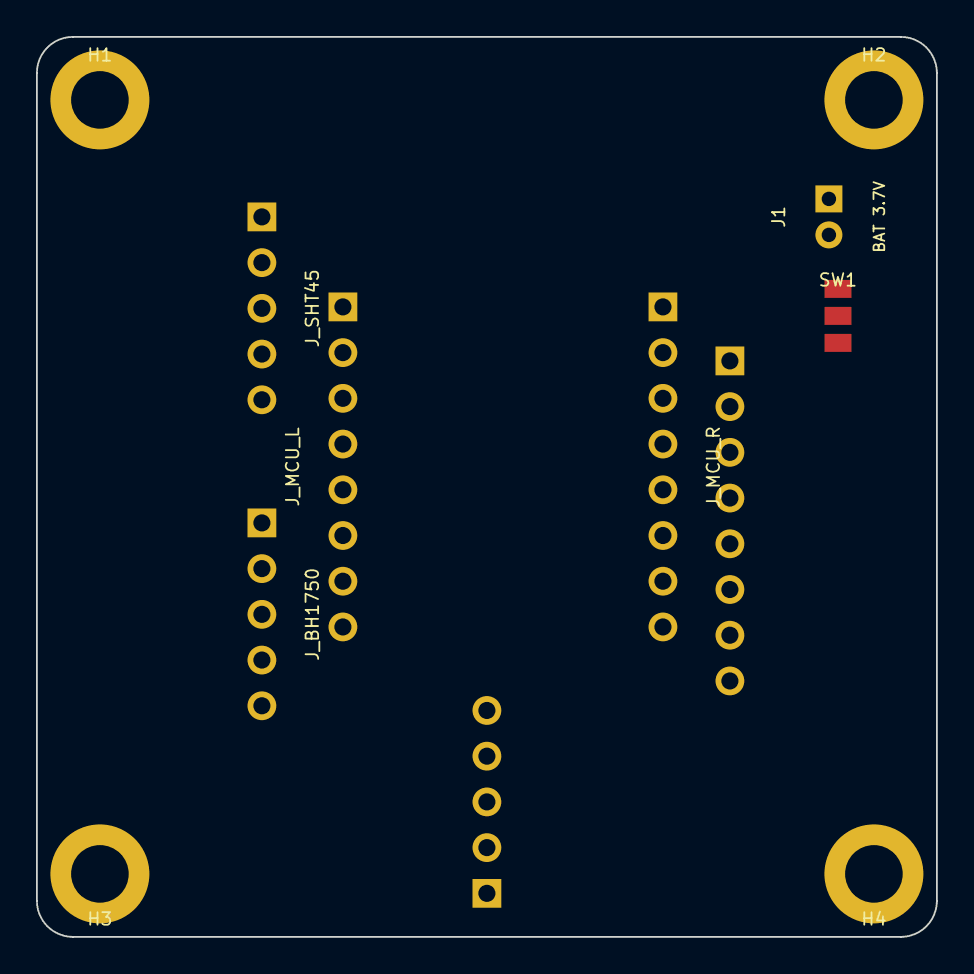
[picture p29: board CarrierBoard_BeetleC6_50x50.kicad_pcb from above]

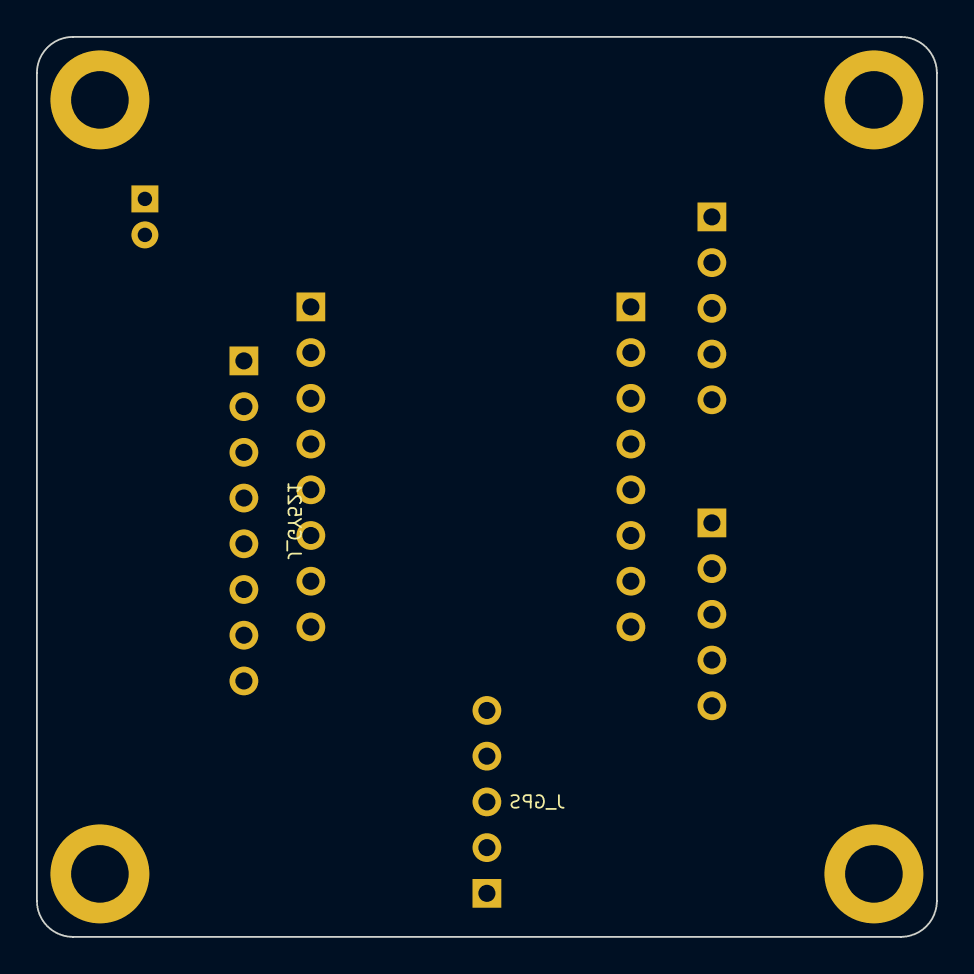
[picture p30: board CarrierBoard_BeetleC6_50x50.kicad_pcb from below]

Board: 2 copper layers, 50.0 x 50.0 mm, 12 parts (2 on the bottom side), 8 nets, no tracks yet.

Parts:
H1, H2, H3, H4: M3; MountingHole_3.2mm_M3_Pad
J1: BAT 3.7V; JST_PH_S2B-PH-K_1x02_P2.00mm_Horizontal
J_BH1750: BH1750; PinHeader_1x05_P2.54mm_Vertical
J_GPS: ATGM336H_BOT; PinHeader_1x05_P2.54mm_Vertical
J_GY521: GY521_BOT; PinHeader_1x08_P2.54mm_Vertical
J_MCU_L: Beetle_Left; PinHeader_1x08_P2.54mm_Vertical
J_MCU_R: Beetle_Right; PinHeader_1x08_P2.54mm_Vertical
J_SHT45: SHT45; PinHeader_1x05_P2.54mm_Vertical
SW1: PWR; SW_SPDT_PCM12

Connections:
3V3: J_BH1750.1, J_GPS.1, J_GY521.1, J_MCU_L.1, J_SHT45.1
BAT+: J1.1, SW1.1
GND: H1.1, H2.1, H3.1, H4.1, J1.2, J_BH1750.2, J_BH1750.5, J_GPS.4, J_GY521.2, J_GY521.7, J_MCU_L.2, J_SHT45.2
GPS_RX: J_GPS.3, J_MCU_R.3
GPS_TX: J_GPS.2, J_MCU_R.4
I2C_SCL: J_BH1750.3, J_GY521.3, J_MCU_R.2, J_SHT45.3
I2C_SDA: J_BH1750.4, J_GY521.4, J_MCU_R.1, J_SHT45.4
VBAT_MCU: J_MCU_L.8, SW1.2

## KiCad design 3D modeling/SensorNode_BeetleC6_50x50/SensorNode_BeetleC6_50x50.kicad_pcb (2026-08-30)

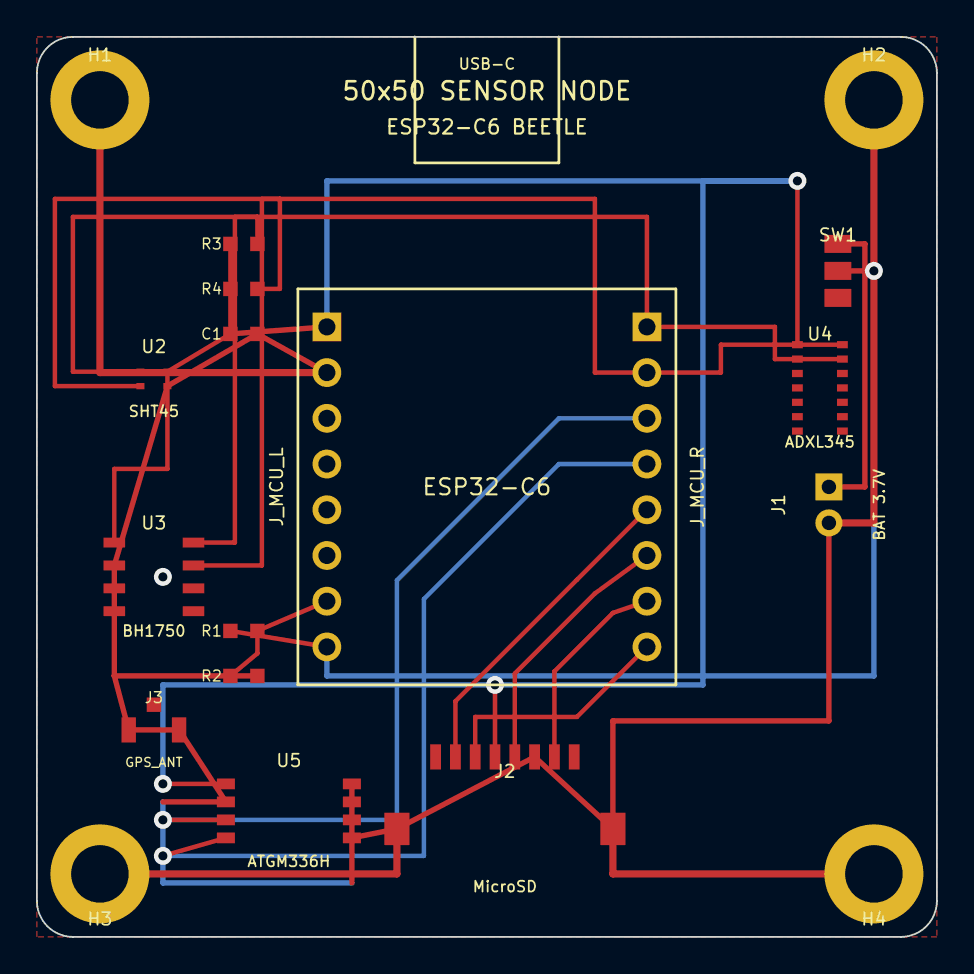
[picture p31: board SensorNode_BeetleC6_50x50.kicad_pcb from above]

Board: 2 copper layers, 50.0 x 50.0 mm, 19 parts (0 on the bottom side), 13 nets.

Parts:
C1: 10uF; C_0603_1608Metric
H1, H2, H3, H4: M3; MountingHole_3.2mm_M3_Pad
J1: BAT 3.7V; JST_PH_S2B-PH-K_1x02_P2.00mm_Horizontal
J2: MicroSD; MicroSD_Molex_47309-0001
J3: GPS_ANT; U.FL_Hirose_U.FL-R-SMT-1_Vertical
J_MCU_L: Beetle_Left; PinHeader_1x08_P2.54mm_Vertical
J_MCU_R: Beetle_Right; PinHeader_1x08_P2.54mm_Vertical
R1, R2: 100k; R_0603_1608Metric
R3, R4: 4.7k; R_0603_1608Metric
SW1: PWR; SW_SPDT_PCM12
U2: SHT45; Sensirion_DFN-4-1EP_1.5x1.5mm_P0.8mm_EP0.7x1.15mm
U3: BH1750; SOIC-8_3.9x4.9mm_P1.27mm
U4: ADXL345; LGA-14_3x5mm_P0.8mm
U5: ATGM336H

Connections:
3V3: C1.1, J2.4, J_MCU_L.1, R3.1, R4.1, U2.4, U3.1, U4.1, U4.6, U4.7, U5.1
BAT+: J1.1, SW1.1
BAT_ADC: J_MCU_L.7, R1.2, R2.1
GND: C1.2, H1.1, H2.1, H3.1, H4.1, J1.2, J2.6, J2.SH1, J2.SH2, J3.2, J3.3, J_MCU_L.2, R2.2, U2.3, U3.2, U3.3, U3.4, U4.2, U4.4, U4.5, U4.12, U5.2, U5.5, U5.8
GPS_RX: J_MCU_R.3, U5.3
GPS_TX: J_MCU_R.4, U5.4
I2C_SCL: J_MCU_R.2, R4.2, U2.2, U3.7, U4.14
I2C_SDA: J_MCU_R.1, R3.2, U2.1, U3.8, U4.13
SPI_CS: J2.2, J_MCU_R.5
SPI_MISO: J2.7, J_MCU_R.7
SPI_MOSI: J2.3, J_MCU_R.8
SPI_SCK: J2.5, J_MCU_R.6
VBAT_MCU: J_MCU_L.8, R1.1, SW1.2

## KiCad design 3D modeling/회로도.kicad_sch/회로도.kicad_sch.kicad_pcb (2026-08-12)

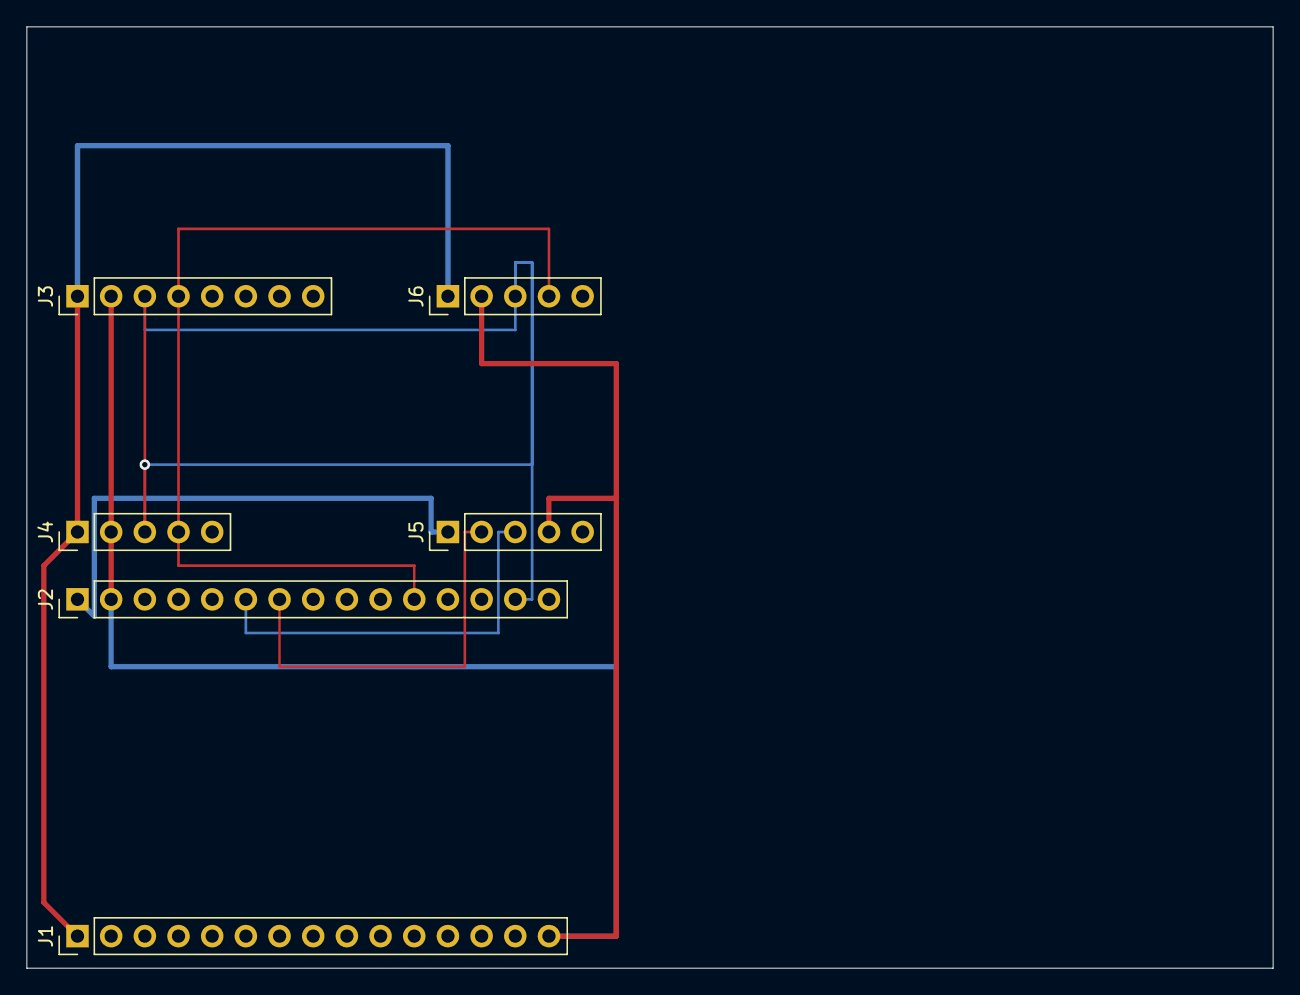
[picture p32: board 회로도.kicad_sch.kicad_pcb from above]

Board: 2 copper layers, 94.0 x 71.0 mm, 6 parts (0 on the bottom side), 7 nets.

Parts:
J1, J2: PinHeader_1x15_P2.54mm_Vertical
J3: PinHeader_1x08_P2.54mm_Vertical
J4, J5, J6: PinHeader_1x05_P2.54mm_Vertical

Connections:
3V3: J1.1, J3.1, J4.1, J6.1
5V: J2.1, J5.1
GND: J1.15, J2.2, J3.2, J4.2, J5.4, J6.2
GPS_RX: J2.7, J5.2
GPS_TX: J2.6, J5.3
I2C_SCL: J2.14, J3.3, J4.3, J6.3
I2C_SDA: J2.11, J3.4, J4.4, J6.4

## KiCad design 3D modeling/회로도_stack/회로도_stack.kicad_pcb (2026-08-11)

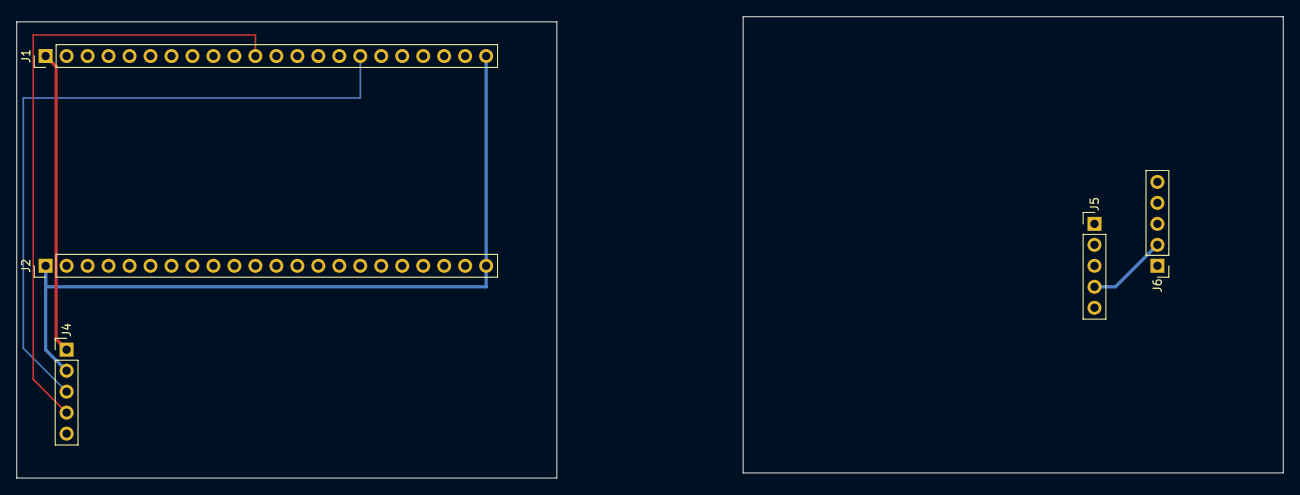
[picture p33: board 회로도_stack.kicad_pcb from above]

Board: 2 copper layers, 153.4 x 55.9 mm, 5 parts (0 on the bottom side), 5 nets.

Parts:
J1, J2: PinHeader_1x22_P2.54mm_Vertical
J4, J5, J6: PinHeader_1x05_P2.54mm_Vertical

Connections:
3V3: J1.1, J4.1
GND: J1.22, J2.1, J2.22, J4.2
GND_BOT: J5.4, J6.2
I2C_SCL: J1.16, J4.3
I2C_SDA: J1.11, J4.4

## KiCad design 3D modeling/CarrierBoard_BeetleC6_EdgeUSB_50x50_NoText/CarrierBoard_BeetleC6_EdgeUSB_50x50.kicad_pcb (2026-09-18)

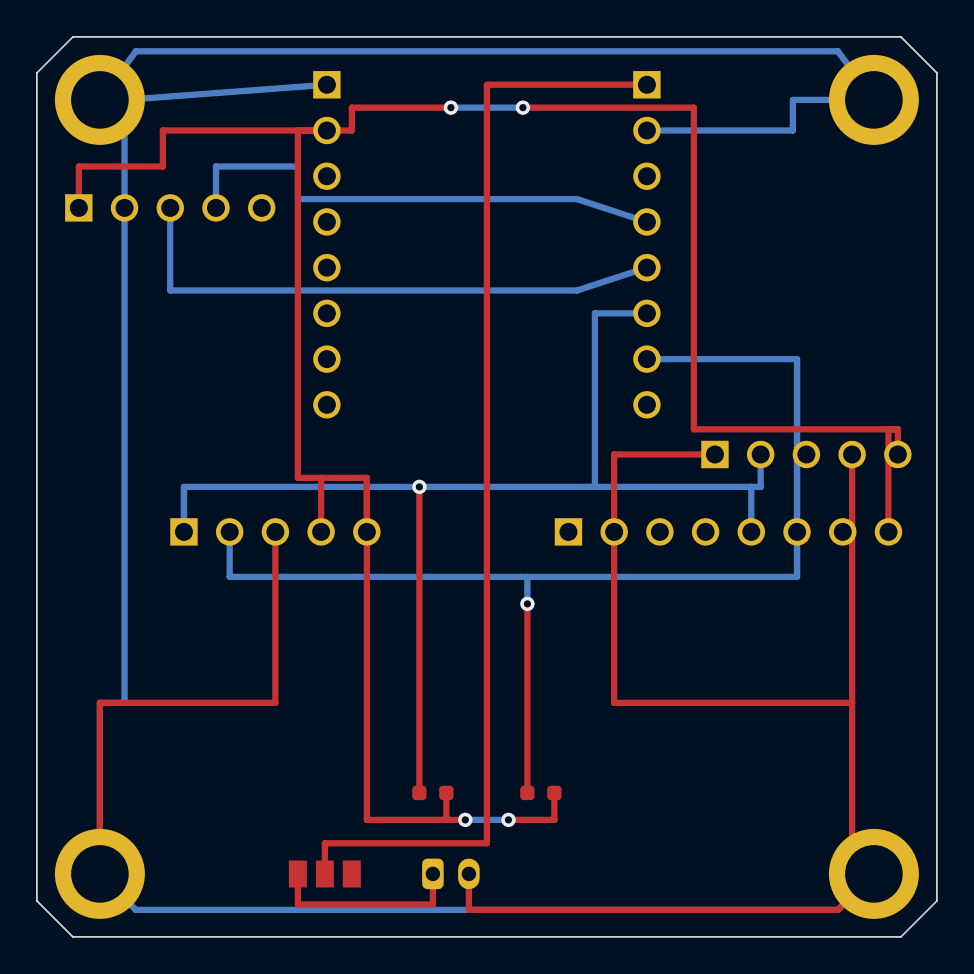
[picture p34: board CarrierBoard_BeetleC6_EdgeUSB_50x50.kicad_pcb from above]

Board: 2 copper layers, 50.0 x 50.0 mm, 10 parts (0 on the bottom side), 8 nets.

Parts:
J1: JST_PH_S2B-PH-K_1x02_P2.00mm_Horizontal
J_BH1750: PinHeader_1x05_P2.54mm_Horizontal
J_GPS: PinHeader_1x05_P2.54mm_Horizontal
J_GY521: PinHeader_1x08_P2.54mm_Horizontal
J_MCU_L: PinHeader_1x08_P2.54mm_Vertical
J_MCU_R: PinHeader_1x08_P2.54mm_Vertical
J_SHT45: PinHeader_1x05_P2.54mm_Horizontal
R3, R4: R_0603_1608Metric
SW1: SW_SPDT_PCM12

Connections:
3V3: J_BH1750.5, J_GPS.1, J_GY521.8, J_MCU_L.2, J_SHT45.4, J_SHT45.5, R3.2, R4.2
BAT: J_MCU_R.1, SW1.2
BAT+: J1.1, SW1.1
GND: J1.2, J_BH1750.1, J_BH1750.4, J_GPS.2, J_GY521.2, J_GY521.7, J_MCU_L.1, J_MCU_R.2, J_SHT45.3
GPS_RX: J_GPS.4, J_MCU_R.4
GPS_TX: J_GPS.3, J_MCU_R.5
I2C_SCL: J_BH1750.3, J_GY521.6, J_MCU_R.7, J_SHT45.2, R4.1
I2C_SDA: J_BH1750.2, J_GY521.5, J_MCU_R.6, J_SHT45.1, R3.1

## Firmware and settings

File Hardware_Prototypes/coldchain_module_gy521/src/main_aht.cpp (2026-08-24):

#include <Arduino.h>
#include <Wire.h>
#include <Adafruit_MPU6050.h>
#include <Adafruit_Sensor.h>
#include <Adafruit_AHTX0.h>
#include <BH1750.h>
#include <TinyGPS++.h>
#include <WiFi.h>
#include <WiFiMulti.h>
#include "secrets.h"
#include <PubSubClient.h>
#include <ArduinoJson.h>
#include <time.h>
#include <sys/time.h>
#include <FS.h>
#include <LittleFS.h>

// -----------------------------------------
// 1. 와이파이 및 MQTT 설정
// -----------------------------------------
const char* mqtt_server = "broker.emqx.io";
const int mqtt_port = 1883;
const char* mqtt_topic = "coldchain/truck01/sensor";

// -----------------------------------------
// 저전력 및 샘플링 튜닝 매크로
// -----------------------------------------
#define TX_INTERVAL_MS 60000          // 일반 센서 데이터 전송 주기 (1분)
#define SAMPLE_INTERVAL_MS 20         // 가속도 센서 고속 풀링 주기 (20ms = 50Hz)
#define SHOCK_THRESHOLD_G 1.8         // 심각한 충격(박스 손상/포트홀) 감지 임계값 (G)
#define SHOCK_DEBOUNCE_MS 3000        // 충격 이벤트 연속 발생 차단 시간 (3초 데드타임)

// -----------------------------------------
// 객체 및 핀 설정 (AHT10 / AHT20 센서 전용)
// -----------------------------------------
Adafruit_MPU6050 mpu;
Adafruit_AHTX0 aht;
BH1750 lightMeter;
TinyGPSPlus gps;

// ESP32-C3/S3 GPS용 Serial1 (RX: GPIO 20, TX: GPIO 21)
#define GPS_SERIAL Serial1

WiFiMulti wifiMulti;
WiFiClient espClient;
PubSubClient client(espClient);

// 오프라인 저장 설정 및 상태 추적 변수
const char* offline_file = "/offline.jsonl";
unsigned long lastReconnectAttempt = 0;
bool wasConnected = false;
bool checkOfflineData = false;

// 피크 홀드 및 타이밍 추적 변수
float max_g_force = 1.0;              // 중력이 있는 상태에서는 기본 1G
unsigned long lastTxTime = 0;
unsigned long lastSampleTime = 0;
unsigned long lastShockTime = 0;

void setup_wifi() {
  delay(10);
  Serial.print("Connecting to WiFi...");
  
  WiFi.mode(WIFI_STA);
  WiFi.setTxPower(WIFI_POWER_11dBm);
  
  for (int i = 0; i < num_wifi_networks; i++) {
    wifiMulti.addAP(wifi_networks[i].ssid, wifi_networks[i].password);
  }

  while (wifiMulti.run() != WL_CONNECTED) {
    delay(500);
    Serial.print(".");
  }
  Serial.println("\n✅ WiFi connected!");
  Serial.print("Connected SSID: ");
  Serial.println(WiFi.SSID());
}

bool reconnectNonBlocking() {
  if (!client.connected()) {
    unsigned long now = millis();
    if (now - lastReconnectAttempt > 5000) {
      lastReconnectAttempt = now;
      Serial.print("Attempting MQTT connection (non-blocking)...");
      String clientId = "ESP32C3-AHT-";
      clientId += String(random(0xffff), HEX);
      if (client.connect(clientId.c_str())) {
        Serial.println("connected!");
        return true;
      } else {
        Serial.print("failed, rc=");
        Serial.print(client.state());
        Serial.println(" try again in 5 seconds");
      }
    }
    return false;
  }
  return true;
}

void sendOfflineData() {
  if (!LittleFS.exists(offline_file)) return;

  File file = LittleFS.open(offline_file, FILE_READ);
  if (!file) {
    Serial.println("Failed to open offline file for reading");
    return;
  }

  Serial.println("📡 Found offline data. Publishing to MQTT...");

  File tempFile;
  bool useTemp = false;
  int sentCount = 0;
  int failCount = 0;

  while (file.available()) {
    String line = file.readStringUntil('\n');
    line.trim();
    if (line.length() == 0) continue;

    bool published = false;
    if (client.connected() && failCount == 0) {
      if (client.publish(mqtt_topic, line.c_str())) {
        published = true;
        sentCount++;
        delay(50);
      } else {
        Serial.println("❌ Failed to publish offline record, buffering remaining...");
        failCount++;
      }
    }

    if (!published) {
      if (!useTemp) {
        tempFile = LittleFS.open("/temp.jsonl", FILE_WRITE);
        useTemp = true;
      }
      if (tempFile) {
        tempFile.println(line);
      }
    }
  }

  file.close();
  if (useTemp) {
    tempFile.close();
  }

  LittleFS.remove(offline_file);
  if (useTemp) {
    if (LittleFS.rename("/temp.jsonl", offline_file)) {
      Serial.println("Updated offline buffer with unsent records.");
    } else {
      Serial.println("Error updating offline buffer!");
    }
  }

  if (sentCount > 0) {
    Serial.printf("✅ Sent %d offline records.\n", sentCount);
  }
}

void setup() {
  Serial.begin(115200);
  
  // GPS 초기화 (RX: GPIO 20, TX: GPIO 21)
  GPS_SERIAL.begin(9600, SERIAL_8N1, 20, 21);
  
  // I2C 초기화 (SDA: GPIO 8, SCL: GPIO 9)
  Wire.begin(8, 9); 

  // 1. MPU6050 초기화
  if (!mpu.begin()) {
    Serial.println("Failed to find MPU6050 chip");
  } else {
    mpu.setAccelerometerRange(MPU6050_RANGE_8_G);
    mpu.setGyroRange(MPU6050_RANGE_500_DEG);
    mpu.setFilterBandwidth(MPU6050_BAND_21_HZ);
  }

  // 2. AHT10 / AHT20 온습도 센서 초기화
  if (!aht.begin()) {
    Serial.println("❌ Could not find AHT10/AHT20 sensor! Check I2C wiring (SDA=8, SCL=9, addr 0x38)");
  } else {
    Serial.println("✅ AHT10/AHT20 Temp & Humidity Sensor initialized!");
  }

  // 3. BH1750 조도 센서 초기화
  if (!lightMeter.begin(BH1750::CONTINUOUS_HIGH_RES_MODE)) {
    Serial.println("Error initialising BH1750");
  }

  // 4. LittleFS 초기화
  if (!LittleFS.begin(true)) {
    Serial.println("An Error has occurred while mounting LittleFS");
  } else {
    Serial.println("LittleFS mounted successfully!");
  }

  setup_wifi();
  
  // 한국 시간(KST, GMT+9) 설정
  configTime(9 * 3600, 0, "pool.ntp.org", "time.nist.gov");
  Serial.println("⏰ NTP Time Syncing...");

  client.setServer(mqtt_server, mqtt_port);

  // 전송 타이머 초기화
  unsigned long now = millis();
  lastTxTime = now;
  lastSampleTime = now;
}

// UTC tm 구조체를 Unix Epoch 초로 계산
time_t customTimegm(struct tm *t) {
  int year = t->tm_year + 1900;
  int month = t->tm_mon + 1;
  int day = t->tm_mday;
  int hour = t->tm_hour;
  int min = t->tm_min;
  int sec = t->tm_sec;

  static const int days_before_month[] = {
    0, 31, 59, 90, 120, 151, 181, 212, 243, 273, 304, 334
  };

  long days = (year - 1970) * 365 + (year - 1969) / 4 - (year - 1901) / 100 + (year - 1601) / 400;
  days += days_before_month[month - 1];
  days += day - 1;

  if (month > 2) {
    bool isLeap = (year % 4 == 0 && (year % 100 != 0 || year % 400 == 0));
    if (isLeap) days++;
  }

  return (time_t)(((days * 24 + hour) * 60 + min) * 60 + sec);
}

// 데이터 계측 및 MQTT/LittleFS 전송 공통 함수
void transmitData(float g_force_val, String status_val) {
  // AHT10 / AHT20 온습도 측정
  sensors_event_t humidity, temp_evt;
  aht.getEvent(&humidity, &temp_evt);

  // BH1750 조도 측정
  float lux = lightMeter.readLightLevel();

  // KST 로컬 시간 정보 가져오기
  struct tm timeinfo;
  char timeStr[20] = "00:00:00";
  if (getLocalTime(&timeinfo, 10)) {
    strftime(timeStr, sizeof(timeStr), "%Y-%m-%d %H:%M:%S", &timeinfo);
  }

  // JSON 구성
  StaticJsonDocument<512> doc;
  doc["device"] = "gy521-aht";
  doc["timestamp_str"] = timeStr;
  doc["temperature"] = String(temp_evt.temperature, 2);
  doc["humidity"] = String(humidity.relative_humidity, 2);
  doc["lux"] = String(lux, 1);
  doc["g_force"] = String(g_force_val, 2);
  
  if (gps.location.isValid()) {
    doc["lat"] = String(gps.location.lat(), 6);
    doc["lng"] = String(gps.location.lng(), 6);
    doc["speed"] = String(gps.speed.kmph(), 1);
  } else {
    doc["lat"] = "0.0";
    doc["lng"] = "0.0";
  }
  
  doc["status"] = status_val;

  char jsonBuffer[512];
  serializeJson(doc, jsonBuffer);
  Serial.print("📡 Transmission: ");
  Serial.println(jsonBuffer);

  bool currentConnected = client.connected();
  if (currentConnected) {
    client.publish(mqtt_topic, jsonBuffer);
  } else {
    File file;
    if (LittleFS.exists(offline_file)) {
      file = LittleFS.open(offline_file, FILE_APPEND);
    } else {
      file = LittleFS.open(offline_file, FILE_WRITE);
    }

    if (file) {
      if (file.size() < 1000000) {
        file.println(jsonBuffer);
        Serial.println("💾 Saved data to LittleFS (Offline mode)");
      } else {
        Serial.println("⚠️ LittleFS buffer full!");
      }
      file.close();
    }
  }
}

void loop() {
  bool currentConnected = client.connected();

  if (wifiMulti.run() == WL_CONNECTED) {
    if (!currentConnected) {
      currentConnected = reconnectNonBlocking();
    }
  }

  if (currentConnected) {
    client.loop();
  }

  if (currentConnected && !wasConnected) {
    checkOfflineData = true;
  }
  wasConnected = currentConnected;

  if (currentConnected && checkOfflineData) {
    checkOfflineData = false;
    sendOfflineData();
  }

  while (GPS_SERIAL.available() > 0) {
    gps.encode(GPS_SERIAL.read());
  }

  unsigned long now = millis();

  // 1. 고속 가속도 샘플링 (50Hz)
  if (now - lastSampleTime >= SAMPLE_INTERVAL_MS) {
    lastSampleTime = now;

    sensors_event_t a, g, temp_mpu;
    mpu.getEvent(&a, &g, &temp_mpu);
    
    float total_accel = sqrt(pow(a.acceleration.x, 2) + pow(a.acceleration.y, 2) + pow(a.acceleration.z, 2));
    float g_force = total_accel / 9.80665; 

    if (g_force > max_g_force) {
      max_g_force = g_force;
    }

    // 2. 실시간 임계값 초과 충격 이벤트 전송 (1.8G 이상)
    if (g_force >= SHOCK_THRESHOLD_G) {
      if (now - lastShockTime >= SHOCK_DEBOUNCE_MS) {
        lastShockTime = now;
        Serial.printf("⚠️ [SHOCK DETECTED] High G-Force event: %.2fg!\n", g_force);
        transmitData(g_force, "강한 충돌!!");
        max_g_force = 1.0; 
      }
    }
  }

  // 3. GPS 시각 동기화
  static unsigned long lastGpsSyncCheck = 0;
  if (now - lastGpsSyncCheck >= 1000) {
    lastGpsSyncCheck = now;

    if (gps.date.isValid() && gps.time.isValid() && gps.date.year() > 2020) {
      time_t now_time = time(NULL);
      struct tm *now_tm = localtime(&now_time);
      if (now_tm->tm_year < 120) {
        struct tm gpsTimeinfo = {0};
        gpsTimeinfo.tm_year = gps.date.year() - 1900;
        gpsTimeinfo.tm_mon = gps.date.month() - 1;
        gpsTimeinfo.tm_mday = gps.date.day();
        gpsTimeinfo.tm_hour = gps.time.hour();
        gpsTimeinfo.tm_min = gps.time.minute();
        gpsTimeinfo.tm_sec = gps.time.second();
        gpsTimeinfo.tm_isdst = 0;

        time_t utcEpoch = customTimegm(&gpsTimeinfo);
        if (utcEpoch != -1) {
          struct timeval tv = { .tv_sec = utcEpoch, .tv_usec = 0 };
          settimeofday(&tv, NULL);
          Serial.println("⏰ System time synced with GPS UTC!");
        }
      }
    }
  }

  // 4. 일반 데이터 주기적 전송 (1분 간격)
  if (now - lastTxTime >= TX_INTERVAL_MS) {
    lastTxTime = now;

    String status = "안전";
    if (max_g_force > SHOCK_THRESHOLD_G) {
      status = "강한 충돌!!";
    } else if (max_g_force > 1.3 || max_g_force < 0.7) {
      status = "이동/진동";
    }

    transmitData(max_g_force, status);
    max_g_force = 1.0; 
  }
}

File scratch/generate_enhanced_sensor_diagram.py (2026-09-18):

import os
import re
import matplotlib.pyplot as plt
import matplotlib.patches as patches
import numpy as np

# Configure Korean font
plt.rcParams['font.family'] = 'Malgun Gothic'
plt.rcParams['axes.unicode_minus'] = False

PCB_PATH = r"c:\Users\korea\Desktop\1hsm\hanhanhan\ColdChain-DigitalTwin-Platform\3D modeling\CarrierBoard_BeetleC6_EdgeUSB_50x50_NoText\CarrierBoard_BeetleC6_EdgeUSB_50x50.kicad_pcb"
OUT_IMG = r"c:\Users\korea\Desktop\1hsm\hanhanhan\ColdChain-DigitalTwin-Platform\3D modeling\CarrierBoard_BeetleC6_EdgeUSB_50x50_NoText\Fig_CarrierBoard_Routing_Verification.png"
ARTIFACT_DIR = r"C:\Users\korea\.gemini\antigravity-ide\brain\531a7f17-5cfb-4c4c-a6c8-8be28bb2ba15"
ARTIFACT_IMG = os.path.join(ARTIFACT_DIR, "Fig_CarrierBoard_Routing_Verification.png")

with open(PCB_PATH, "r", encoding="utf-8") as f:
    pcb_text = f.read()

# 1. Parse Nets
net_names = {
    0: "NC",
    1: "GND",
    2: "3V3",
    3: "BAT+",
    4: "BAT",
    5: "I2C_SDA",
    6: "I2C_SCL",
    7: "GPS_RX",
    8: "GPS_TX"
}

net_colors = {
    1: "#2ECC71", # GND (Green)
    2: "#FF3366", # 3V3 (Vibrant Red/Crimson)
    3: "#FF9F43", # BAT+ (Warm Orange)
    4: "#FECA57", # BAT (Amber/Gold)
    5: "#00D2D3", # SDA (Cyan)
    6: "#A55EEA", # SCL (Bright Purple)
    7: "#F368E0", # GPS_RX (Pink)
    8: "#10AC84", # GPS_TX (Emerald)
}

# 2. Parse Segments
seg_pattern = re.compile(r'\(segment\s+\(start\s+([0-9.-]+)\s+([0-9.-]+)\)\s+\(end\s+([0-9.-]+)\s+([0-9.-]+)\)\s+\(width\s+([0-9.-]+)\)\s+\(layer\s+"([^"]+)"\)\s+\(net\s+([0-9]+)\)\)')
segments = []
for m in seg_pattern.finditer(pcb_text):
    x1, y1, x2, y2, w, layer, net = float(m.group(1)), float(m.group(2)), float(m.group(3)), float(m.group(4)), float(m.group(5)), m.group(6), int(m.group(7))
    segments.append({
        'x1': x1, 'y1': y1, 'x2': x2, 'y2': y2, 'w': w, 'layer': layer, 'net': net
    })

# 3. Parse Vias
via_pattern = re.compile(r'\(via\s+\(at\s+([0-9.-]+)\s+([0-9.-]+)\)\s+\(size\s+([0-9.-]+)\)\s+\(drill\s+([0-9.-]+)\).*?\(net\s+([0-9]+)\)\)')
vias = []
for m in via_pattern.finditer(pcb_text):
    x, y, s, d, net = float(m.group(1)), float(m.group(2)), float(m.group(3)), float(m.group(4)), int(m.group(5))
    vias.append({
        'x': x, 'y': y, 'size': s, 'drill': d, 'net': net
    })

# 4. Parse Footprints and Pads
fp_blocks = re.findall(r'\(footprint\s+"([^"]+)"\s+\(layer\s+"([^"]+)"\)\s+\(at\s+([0-9.-]+)\s+([0-9.-]+)(?:\s+([0-9.-]+))?\)(.*?)\n\t\)', pcb_text, re.DOTALL)
pads = []
for fp_name, fp_layer, fp_x, fp_y, fp_rot, fp_body in fp_blocks:
    fx, fy = float(fp_x), float(fp_y)
    rot = float(fp_rot) if fp_rot else 0.0
    ref_match = re.search(r'\(property\s+"Reference"\s+"([^"]+)"', fp_body)
    ref = ref_match.group(1) if ref_match else fp_name
    
    pad_matches = re.finditer(r'\(pad\s+"([^"]+)"\s+(\w+)\s+(\w+)\s+\(at\s+([0-9.-]+)\s+([0-9.-]+)(?:\s+([0-9.-]+))?\)\s+\(size\s+([0-9.-]+)\s+([0-9.-]+)\)(?:.*?\(drill\s+([0-9.-]+)\))?(?:.*?\(net\s+([0-9]+)\s+"([^"]*)")?', fp_body)
    for pm in pad_matches:
        pnum = pm.group(1)
        ptype = pm.group(2)
        pshape = pm.group(3)
        px, py = float(pm.group(4)), float(pm.group(5))
        sx, sy = float(pm.group(7)), float(pm.group(8))
        drill = float(pm.group(9)) if pm.group(9) else 0.0
        net = int(pm.group(10)) if pm.group(10) else 0
        net_name = pm.group(11) if pm.group(11) else ""
        
        rad = np.radians(rot)
        wx = fx + px * np.cos(rad) - py * np.sin(rad)
        wy = fy + px * np.sin(rad) + py * np.cos(rad)
        
        pads.append({
            'ref': ref, 'num': pnum, 'type': ptype, 'shape': pshape,
            'x': wx, 'y': wy, 'sx': sx, 'sy': sy, 'drill': drill,
            'net': net, 'net_name': net_name, 'fp_layer': fp_layer
        })
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

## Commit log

2026-05-04 대쉬보드 수정
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2026-05-04 aws 수정
2026-05-04 웹 수정
2026-05-07 대쉬보드 수정2
2026-05-07 Fix category filter mapping for English DB values
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2026-05-08 스캐너수정
2026-05-08 코드수정1
2026-05-08 feat: Add Smart Coldchain Final Experiment, Streamlit dashboard, ESP32 multi-wifi, and secure DB configurations
2026-05-08 fix: Update coldchain dashboard to explicitly use KST (+09:00) timezone for DB inserts and payload timestamp
    [main.cpp]
2026-05-09 소비자 대쉬보드 수정
2026-05-09 소비자 대쉬보드 수정2
2026-05-09 코드1 블록체인 수정
2026-05-09 소비자 대쉬보드 수정3
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2026-05-10 코드 수정
2026-05-10 코드 수정1
2026-05-10 코드 수정2
2026-05-10 코드 수정3
2026-05-10 코드 수정4
2026-05-11 대쉬보드 수정 및 코드 수정
2026-05-11 대쉬보드 수정 및 코드 수정1
2026-05-11 대쉬보드 수정 및 코드 수정2
2026-05-11 대쉬보드 수정 및 코드 수정3
2026-05-11 대쉬보드 수정 및 코드 수정4
2026-05-18 링크수정
2026-05-18 fix: format temperature and humidity sensor readings to exactly one decimal place
2026-05-18 fix: resolve refresh button wrapping, force responsive 4-column profile grid, and support English fruit names
2026-05-18 design: implement premium floating device mockup layout on desktop, responsive fullscreen on mobile
2026-05-18 design: redesign tab2 timeline as premium card widgets with hover micro-animations and integrated sensor logs
2026-05-20 fix: use CARTO Positron basemap URL to prevent blank map and add current location marker (truck emoji)
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2026-05-28 ESP32 GM77 수정
    [06_하우징_3D_설계_오픈스카드.scad]
2026-05-28 GM77코드 수정
2026-05-28 코드수정
2026-05-28 Upgrade OpenSCAD 3D design to fit GM77, ESP32, OLED, battery, and switch
    [06_하우징_3D_설계_오픈스카드.scad]
2026-05-28 Implement physical finger grooves and reinforcement ribs in OpenSCAD CAD model
    [06_하우징_3D_설계_오픈스카드.scad]
2026-05-28 Fix OpenSCAD rendering bug for head and lid base
    [06_하우징_3D_설계_오픈스카드.scad]
2026-05-29 chore: organize 3D printer files into 3D_Printer_Housing folder
    [06_housing_3d_design.scad, 06_housing_body.stl, 06_housing_handle.stl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]
2026-05-31 스캐너 3D 프린터
    [06_housing_body.stl, 06_housing_handle.stl, 06_housing_lid.stl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]
2026-05-31 스캐너 3D 프린터2
    [08_qr_scanner_housing.scad]
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2026-06-02 3D 프린터 인쇄용
    [09_housing_battery_cap.stl, 09_housing_body.stl, 09_housing_handle.stl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]
2026-06-10 refactor: split 3D scanner housing into Left/Right halves, calibrate GM77 & OLED dimensions
    [09_housing_battery_cap.stl, 09_housing_body.stl, 09_housing_handle.stl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]
2026-06-11 트리거 추가
    [09_housing_left.stl, 09_housing_print_all.stl, 09_housing_right.stl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]
2026-06-12 style: Match map and chart heights to 400px; format x-axis labels to HH:MM:SS for horizontal alignment
2026-06-12 style: Use custom Altair charts with horizontal YYYY-MM-DD HH:MM:SS timestamps and bind zoom/pan to x-axis only
2026-06-12 fix: change English title suffix from Safe History to Traceability in Consumer Dashboard
2026-06-22 택트스위치
    [09_housing_left.stl, 09_housing_print_all.stl, 09_housing_right.stl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]
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2026-06-22 fix: add wake-up sequence for GM77 sleep mode
    [main.cpp]
2026-06-22 fix: correct GM77 serial trigger commands and add auto host mode config
    [main.cpp]
2026-06-22 14까ㅈ디
    [10_qr_scanner_housing_industrial.scad, 11_housing_left.stl, 11_housing_right.stl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]
2026-06-22 15추가
    [14_housing_left.stl, 14_housing_right.stl, 14_qr_scanner_housing_final.scad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]
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2026-06-26 17추가
    [16_qr_scanner_housing.scad, 16_qr_scanner_housing_left_half.stl, 16_qr_scanner_housing_right_half.stl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]
2026-07-07 design: update v17 qr scanner housing 3D models and render script
    [17_qr_scanner_housing.scad, 17_qr_scanner_housing_left_half.stl, 17_qr_scanner_housing_right_half.stl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]
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2026-07-13 fix: update offline data file handling to check existence before append in main2.cpp
    [main2.cpp]
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2026-07-15 streamlit 수정
2026-07-28 회로도 추가
    [회로도.kicad_sch.kicad_pcb, 회로도.kicad_sch.kicad_sch, 회로도_c3_supermini.kicad_pcb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]
2026-08-11 배선도 추가:
    [회로도.kicad_sch.kicad_pcb, 회로도_stack.kicad_pcb]
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2026-08-18 docs: detail MQ160W scan actions and DB integration step-by-step for each stage
2026-08-18 docs: add comparison guide between legacy ESP32 scanner and new Jetson system
2026-08-24 feat(firmware): Fix ESP32 scanner AUTO mode, 9600bps serial timeout, and OLED display
    [main.cpp]
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2026-08-30 feat(pcb): Add 50x50mm Smart Agriculture Beetle ESP32-C6 sensor node PCB design and guide
    [SensorNode_BeetleC6_50x50.kicad_pcb, SensorNode_BeetleC6_50x50.kicad_sch]
2026-08-31 feat(hardware): Add exported 3D STEP model and JLCPCB Gerber files for SensorNode BeetleC6 50x50
    [3D_SensorNode_BeetleC6_50x50_2026-08-31.step]
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2026-09-13 docs(hardware): Add design review and sensor sizing verification notes for CarrierBoard BeetleC6 EdgeUSB
2026-09-14 feat(hardware): Refine carrier board with aesthetic orthogonal routing, silkscreen labels, and clean JLCPCB Gerbers
    [BOM.csv, CarrierBoard_BeetleC6_EdgeUSB_50x50.kicad_pcb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]
2026-09-14 3D 프린터
    [18_apple_front_shell.stl, 18_apple_rear_shell.stl, 18_apple_sensor_pod.scad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]
2026-09-18 feat(pcb): finalize 50x50 Carrier Board PCB routing, Gerber, STEP, BOM/CPL, and production deliverables
    - Achieved KiCad 10.0 DRC 0 Errors & 0 Unconnected items
    - Verified real-world pinouts: Beetle ESP32-C6, SHT45, BH1750, MPU6050, ATGM336H GPS
    - Generated certified Gerber package (Gerber_CarrierBoard_BeetleC6_EdgeUSB_50x50_NoText.zip)
    - Updated JLCPCB and DeviceMart compatible BOM and CPL files with exact coordinates
    - Added 3D PCB renders and routing verification diagrams
    [BOM_CarrierBoard_BeetleC6_50x50.csv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]
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2026-10-01 docs: 07 CarrierBoard assembly and diagnostic log - 100% sensor validation complete
2026-10-01 feat(hardware): deploy full WiFi/MQTT live telemetry firmware on Beetle ESP32-C6 carrier board
2026-10-01 docs(carrier-board): update assembly and diagnostic log with WiFi/MQTT deployment and dashboard integration
2026-10-01 feat(hardware): complete 100% carrier board sensor integration with GPS ATGM336H live NMEA streaming and MQTT telemetry
2026-10-01 feat(dashboard): refactor control panel sidebar with live telemetry health card, unclipped session buttons, and CSV export
2026-10-01 docs: complete carrier board diagnostic log with outdoor GPS validation, dashboard UX refactor, and AWS RDS cost analysis
2026-10-02 feat(dashboard): add DB recording toggle switch and enforce KST timezone for session IDs
2026-10-02 feat(dashboard): enhance session naming to '주행_YYYY-MM-DD_HH시MM분' and add intuitive Korean labels to dropdown
2026-10-02 feat(dashboard): implement Dual Y-Axis chart for G-Force and Speed with Fruit Damage Thresholds (2.0G warning, 3.0G critical)
2026-10-02 fix(dashboard): prevent DuplicateElementKey on CSV download button in past session mode
2026-10-02 chore: clean up root directory by moving loose files to respective folders and deleting empty junk file
    [null.stl, test.stl]
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2026-10-03 fix(dashboard): fix session filtering, utf8 charset, and packet burst time interval
2026-10-03 docs: 2026-10-03 야간 펌웨어 링버퍼 및 GPS 시각 동기화 작업 기록 추가
2026-10-03 fix(system-audit): resolve MySQL status length, add run_id index, fix live packet loss in dashboard, and optimize IMU loop
    [carrier_board_mqtt.cpp]
2026-10-03 refactor(telemetry): slim status format without emojis, fit within VARCHAR(50), and revert RDS column size
    [carrier_board_mqtt.cpp]
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2026-10-03 feat(dashboard): auto-detect new trip departure and roll over session without manual button click
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2026-10-06 docs: 젯슨 나노 현장 관제 키오스크 설정 및 콜드체인 실증 프로토콜(docs/11) 추가
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2026-10-06 Fix: Unify today trip session to DB, patch dashboard anti-split & firmware safe buffer flush
    [analyze_today_dump.py, carrier_board_mqtt.cpp, check_all_today_db.py]
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2026-10-06 UI: Add space-saving compact H:M X-axis with zero-angle and tooltips to all charts
2026-10-06 Fix: Resolve session dropdown duplication, unify fridge & driving data, filter noise sessions
    [check_all_sessions.py]
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2026-10-07 fix(jetson): 데이터 미수신 시 KeyError 'lat' 방어 로직 추가 및 DB 최근 세션 자동 초기화
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2026-10-07 fix(jetson): 자동실행 및 바탕화면 아이콘 스크립트 온전한 내용 반영 및 실행 즉시 런처 구동 추가
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2026-10-08 fix(dashboard): 패킷 타임스탬프 기반 RUN_ID 자동 동기화 및 세션 분할 방지 공유 트래커 적용
2026-10-08 fix(firmware): Wi-Fi 동기 스캔 블로킹 완화, GPS 수신 버퍼 1KB 확장, 오프라인 버퍼 1.5MB 증설 및 정지 판정 안정화
    [carrier_board_mqtt.cpp]
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2026-10-10 feat(3d-housing): Add v19 Apple Sensor Pod for 5000mAh JRF PL105568 battery and CarrierBoard PCB
    [19_apple_front_shell.stl, 19_apple_rear_shell.stl, 19_apple_sensor_pod.scad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]
2026-10-10 feat(3d-housing): Scale Apple Pod to exact 100mm (10cm) diameter with 5000mAh battery
    [19_apple_front_shell.stl, 19_apple_rear_shell.stl, 19_apple_sensor_pod.scad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]
2026-10-10 feat(3d-housing): Accommodate 35mm PCB stack thickness with 17.5mm rear standoffs
    [19_apple_front_shell.stl, 19_apple_rear_shell.stl, 19_apple_sensor_pod.scad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]
2026-10-10 fix(3d-housing): Remove accidental floating lip from front shell for flush bed adhesion
    [19_apple_front_shell.stl, 19_apple_rear_shell.stl, 19_apple_sensor_pod.scad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]
2026-10-10 fix(3d-housing): Resolve battery pocket blockage with v20 modular drop-in tray architecture
    [20_apple_battery_tray.stl, 20_apple_front_shell.stl, 20_apple_rear_shell.stl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]
2026-10-10 docs(3d-housing): Add wide exploded views and individual part inspection cards for v20 housing
    [20_apple_sensor_pod.scad]
2026-10-10 fix(3d-housing): Pre-orient all v20 STL files flat on build bed at Z=0 for 1-click slicing
    [20_apple_battery_tray.stl, 20_apple_front_shell.stl, 20_apple_rear_shell.stl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]
2026-10-10 fix(3d-housing): Elongate and fuse screw bosses seamlessly to outer shell walls with corner tray notches
    [20_apple_battery_tray.stl, 20_apple_front_shell.stl, 20_apple_rear_shell.stl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]
2026-10-10 docs(3d-housing): Add battery physical clearance and cross-section fit verification images
2026-10-10 fix(3d-housing): Fuse screw boss pillars 100% into shell wall eliminating floating overhang step for zero-support printing
    [20_apple_battery_tray.stl, 20_apple_front_shell.stl, 20_apple_rear_shell.stl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]
2026-10-10 fix(3d-housing): Fuse battery cradle bottom and sides 100% to rear shell wall eliminating floating gaps and overhangs
    [20_apple_battery_tray.stl, 20_apple_front_shell.stl, 20_apple_rear_shell.stl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]
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2026-10-11 fix(scanner): call get_columns() before get_next_row() to resolve automatic stage progression bug
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2026-10-11 fix(sorting): exclude id column during INSERT to prevent Duplicate entry PRIMARY error
2026-10-12 fix(carrier): update WiFi SSID to 225, switch to HiveMQ MQTT broker, set COM17
2026-10-12 feat: configure COM17 PCB board as carrier-c6-02 (truck02) with HiveMQ broker
2026-10-12 fix: isolate truck01/truck02 monitoring topics and add device conflict detection alert
2026-10-12 fix: add I2C scan, dual address check (0x68/0x69) and hotplug auto-retry for MPU6050
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2026-10-12 fix(housing): drill 8x front-accessible counterbored screw holes directly through front shell
2026-10-12 fix(housing): update 21_apple_front_shell.stl with 8x front-drilled counterbored screw holes
2026-10-12 fix(housing): extend front standoffs to h=50mm to fuse 100% seamlessly into dome wall (zero floating gap)
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2026-10-12 fix(housing): remove diagonal standoff wings to guarantee 100% sensor clearance matching v20
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2026-10-14 fix(housing): reinforce v21 standoffs with monolithic outward ribs and optimize slicer guide
2026-10-14 fix(housing): align front shell standoff ribs strictly with user red arrows into ceiling and floor outer walls
2026-10-15 feat(housing): add v22 magnetic snap edition with D6x3mm steel-dowel magnets, 20x5x7mm GPS antenna holder, and Method 1-A BH1750 window
2026-10-15 fix(housing): add 45-deg self-supporting conical vaults to v22 magnet and GPS pockets for support-free printing
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2026-10-16 fix(housing): remove rear shell battery retention lips for zero-interference drop-in fit
    - Remove overhang retention lips (2mm each side) in 22_apple_sensor_pod.scad to prevent LiPo pouch battery insertion interference and scraping
    - Maintain 4-sided 58x73x12mm cradle walls for solid lateral retention and finger extraction notch
    - Re-export 22_apple_rear_shell.stl (2,428.9 KB) and update 3D render preview PNGs and README_PRINT_GUIDE.md
2026-10-16 fix(housing): match rear shell magnet pockets to front shell (D6.32mm + 45-deg lead-in chamfer)
    - Increase rear shell magnet pocket radius to 3.16mm (diameter 6.32mm)
    - Add 45-deg entrance chamfer (diameter 7.22mm, depth 0.9mm) to absorb 3D printer first-layer bed squish
    - Re-export 22_apple_rear_shell.stl (2,619.8 KB) and update 3D render preview PNGs and README_PRINT_GUIDE.md
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2026-10-17 fix(firmware): resolve uninitialized I2C stack read and filter false shock spikes
2026-10-17 fix(dashboard): default to AWS EC2 cloud ingestion mode to prevent duplicate MySQL inserts
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2026-10-26 fix(housing): remove center battery floor notch for flat Velcro tape attachment on v22 rear shell
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2026-10-26 fix(3d-housing): carve 56.4x70.4mm corner-clearance bay and shorten rear magnet bosses so 55x68mm 5000mAh battery sits 100% flat on Velcro floor without floating
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
